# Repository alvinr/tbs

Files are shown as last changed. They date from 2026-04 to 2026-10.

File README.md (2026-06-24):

<!-- SPDX-License-Identifier: AGPL-3.0-only -->
<!-- © 2026 Alvin Richards -->

<div align="center">
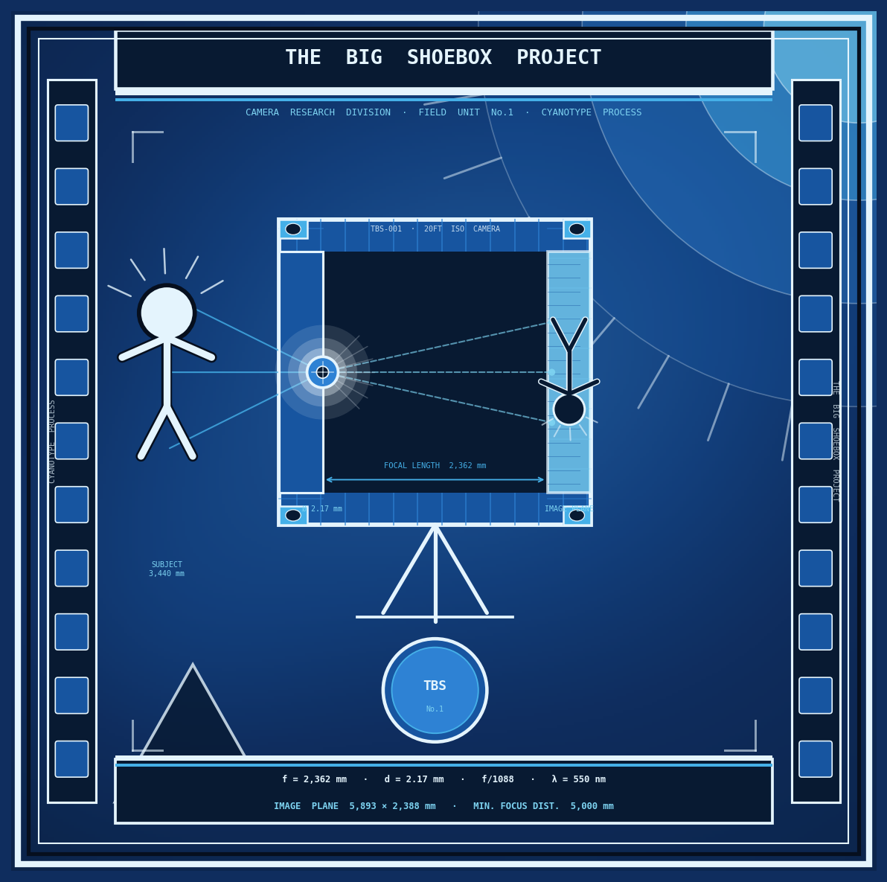
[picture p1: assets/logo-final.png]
The Big Shoebox Project (TBS-001)
  
</div>

# The Big Shoebox Project (TBS-001) — Repository & Build Guide

This repository is the **source** for the TBS-001 engineering documentation: a giant pinhole
camera built inside a 20 ft shipping container. Everything published is *generated* from code and
text in this repo — the 2D engineering diagrams (matplotlib), the 3D SketchUp models, the cost /
shopping / weight figures, and the [MkDocs](https://www.mkdocs.org/) website.

> **Looking for the camera itself?** This README is about running the **repo** (regenerating
> drawings, building the site, the tooling). For the project overview see
> **[`project-summary.md`](project-summary.md)** or the live site: **<https://alvinr.github.io/tbs/>**.

---

## Repository layout

```
/                      project root — engineering reports (*.md), config, this README
src/generators/        all 2D diagram generators + the tooling (lint.py, costing.py, …)
src/models/            SketchUp 3D model generators (emit Ruby, drive SketchUp)
diagrams/              generated PNGs/SVGs (output of src/generators/)
skills/                codified drawing/labeling conventions
published/             MkDocs input — auto-populated by publish.sh (gitignored, never edit)
site/                  built site output — gitignored, never commit
.githooks/             versioned git hooks (the pre-commit drift gate)
dependencies.yml       machine source: script → output-file graph (see "Tooling")
mkdocs.yml             site nav + theme           publish.sh   sync + build + deploy
```

`CLAUDE.md` holds the working conventions (drawing style, report style, the add-a-document
workflow) in more depth — it's worth a read before adding content.

---

## Prerequisites

- **Interpreter: CPython 3.9** — developed and run on **3.9.6** (the macOS system `python3`).
- **Packages: [`requirements.txt`](requirements.txt)** — the single, pinned dependency list (for the
  2D diagram generators and the documentation site). Set up a virtual environment from it:

  ```bash
  python3 -m venv .venv
  .venv/bin/pip install -r requirements.txt
  # then activate it, or prefix commands with .venv/bin/
  ```

- **3D models** additionally need [SketchUp](https://www.sketchup.com/) + the live-send bridge — not
  a pip dependency (see "The 3D SketchUp models").

The drift tooling (`lint.py`, `costing.py`, `facts.py`, `deps.py`) and the SketchUp model generators
use **only the Python standard library**, so the pre-commit hook runs on any `python3` with nothing
installed. Only the diagram generators and the site build need `requirements.txt`.

---

## Regenerating the 2D diagrams

Each generator writes one or more PNGs into `diagrams/`:

```bash
python3 src/generators/generate_<name>.py        # e.g. generate_walkway_diagram.py
```

Spatial values come from `src/generators/tbs_constants.py` (the single source of truth for
geometry). **Don't hardcode a dimension** — import the constant. After changing a constant, see
*"What a change cascades to"* below for exactly which generators to re-run.

---

## The 3D SketchUp models

Models live in `src/models/` and **emit Ruby** that builds the model in a running SketchUp:

```bash
python3 src/models/generate_sketchup_model.py --save    # write the .rb to src/models/<name>.rb
python3 src/models/generate_sketchup_model.py --send    # build into the OPEN SketchUp document
```

- `--save` is non-interactive (just writes the `.rb`); `--send` requires SketchUp **open on the
  correct document** with the live-send bridge listening — it clears and rebuilds the active model.
- Open a **blank** document before `--send` for a *new* model so you don't clobber an existing
  `.skp`; then "Save As" to `models/<name>.skp`.
- Commit the generator `.py` + the regenerated `.rb` + the `.skp` together. (Sketchfab re-uploads
  are a manual step.)

Models share geometry helpers and constants from `generate_sketchup_model.py` (imported as `ov`),
so they stay in sync. See `dependencies.yml` for the model → output mapping.

---

## Single source of truth

Numbers are **computed, never transcribed** — each kind of value has exactly one home:

| Store | Owns | Consumed by |
|---|---|---|
| `src/generators/tbs_constants.py` | geometry & engineering values | generators, models, weight/cost scripts |
| `src/generators/parts.py` | **the parts registry** — every purchasable item: qty, type, supplier, low/high cost, verified size, cyanotype chemistry | the master BOM, every report's parts list, the dimension audit + cyanotype shopping list (block-injected); `costing.py` derives section totals from it |
| `src/generators/costing.py` | the scenario cost model (mid + low/high budgeting bands) on top of the registry | the cost tables in the docs (block-injected) |
| `src/generators/facts.yml` | cross-referenced prose numbers + the regex to police them | the linter |
| `dependencies.yml` | the `script → output-file` graph | the linter (cascade + validation) |

**`parts.py` is the procurement source of record; `costing.py` is a reconciled scenario layer.** The
registry generates `master-shopping-list.md` (the by-type BOM + supplier consolidation), every
report's §Parts-List, `component-dimension-audit.md` §1, and the cyanotype `chemistry-shopping-list.md`
— all wrapped in `<!-- BEGIN parts:KEY -->` blocks:

```bash
python3 src/generators/parts.py --inject         # rewrite the parts: doc blocks from the registry
python3 src/generators/parts.py --check          # assert each system reconciles with costing
python3 src/generators/parts.py --master         # print the by-type BOM to stdout
```

The invariant is lint-gated both ways: `parts.py --check-blocks` (docs match the registry) and
`costing.py --check-registry` (each section total == the sum of its registry systems), so a cost
can't drift between the BOM and the budget.

Cost tables in the markdown are wrapped in `<!-- BEGIN costing:KEY -->` / `<!-- END … -->` blocks
and regenerated by `costing.py`:

```bash
python3 src/generators/costing.py --inject     # rewrite the doc cost tables from the source
python3 src/generators/costing.py --check      # assert the figures are internally consistent
```

`facts.yml` prose figures and the per-session **energy budget** are block-injected the same way:

```bash
python3 src/generators/facts.py --inject                    # fill the <!-- fact:KEY --> placeholders
python3 src/generators/calculate_energy_budget.py --inject  # fill the <!-- energy:KEY --> figures
```

The energy injector fills the `<!-- BEGIN energy:KEY -->` placeholders in `electrical-report.md`
§3.1/§3.2 from `calculate_energy_budget.py` — the per-session, daily-roll-up, and autonomy model.
It is **lint-gated** (the *energy doc-blocks* gate), so those figures cannot drift from the model.
**Rerun `--inject` after any spec change** that affects power, and regenerate the electrical
**Sheet 1** summary panel (`generate_electrical_diagram.py`) to match. (`daily-energy-report.md`
presents the same model in prose but is not yet block-injected.)

---

## Tooling: the drift linter

`src/generators/lint.py` is a commit-time linter that stops document-side drift. It runs
**automatically before every commit** via the versioned hook — enable it once per clone:

```bash
git config core.hooksPath .githooks       # one-time install; emergency bypass: git commit --no-verify
```

Run it by hand any time:

```bash
python3 src/generators/lint.py            # all checks (4 gates that BLOCK + 7 advisory warnings)
```

**Gates** (block the commit): costing reconciliation, costing doc-blocks match the source,
fact placeholders match the registry, energy doc-blocks match `calculate_energy_budget.py`.
**Warnings** (advisory): facts-registry agreement, `dependencies.yml` validity, table arithmetic,
missing-cascade, hardwired-literal, duplicated-geometry equality.

On-demand sub-commands:

```bash
python3 src/generators/lint.py --cascade PROC_TRAY_X_R   # what re-runs if this constant changes
python3 src/generators/lint.py --literals                # full hardwired-literal backlog scan
python3 src/generators/lint.py --duplication             # compare the duplicated 3D emitters
```

### What a change cascades to

After editing a constant, ask the tooling rather than a table:

```bash
python3 src/generators/lint.py --cascade <CONSTANT_NAME>
```

It greps every script that reads the constant and lists the exact PNGs / `.skp` / `.rb` each
writes. If you `git add` a `tbs_constants.py` change **without** the regenerated outputs, the
pre-commit *missing-cascade* check names the specific files you still owe.

`component-dependency-map.md` is the **human** rationale (component → constant registry, the
subsystem × diagram matrix, per-model narratives); `dependencies.yml` is the **machine** source.

---

## Tooling: the editorial validator

`src/generators/editorial_lint.py` enforces the report **narrative** house style codified in
[`skills/skill_report_writing.md`](skills/skill_report_writing.md) (the counterpart to `lint.py`,
which guards the *numbers*). It scans the published reports (`publish.sh` `MD_FILES` +
`project-summary.md`).

It is a **manual step — *not* wired into the pre-commit hook.** Run it by hand:

```bash
python3 src/generators/editorial_lint.py          # gates + advisory
python3 src/generators/editorial_lint.py --gates   # gates only (exit 1 on failure, for future CI)
```

**Gates** (deterministic, exit 1 on failure): American spelling (British → American), and every
item in a *Source References* section carries a hyperlink.
**Advisory** (review; never blocks): banned stale design terms (e.g. `55-gal`, `colonnade`,
`Portacool Jetstream` — extend `_BANNED`), a registry-known value restated **raw** that should be a
`<!-- fact: -->` placeholder (the highest-leverage check — it auto-cascades once wrapped), mixed
thousands-separator styles, and reports missing a *Source References* section.

> Scope: it reads the report `.md` prose only — it can't see British spellings baked into diagram
> **labels** (inside the generator `.py`) or `.skp` models; those still need a manual sweep.

---

## Building & deploying the site

```bash
bash publish.sh            # sync docs → published/, build, and gh-deploy to GitHub Pages
bash publish.sh --local    # sync + serve a local preview at http://127.0.0.1:8000
bash publish.sh --build    # sync + build to site/ only (no deploy)
```

`publish.sh` syncs the root `.md` files + `diagrams/` into `published/`, copies
`project-summary.md → published/index.md` (the site Home), builds with MkDocs, optionally writes
the PDF brochure, and pushes the `gh-pages` branch. It auto-detects whether a git remote exists and
falls back to `--build` if not. On some systems run it as `PATH=/usr/bin:$PATH bash publish.sh`.

**Never edit `published/` or `site/` by hand** — they are regenerated.

---

## Adding a new document (short version)

1. Write `<name>.md` in the repo root (+ a `src/generators/generate_<name>.py` if it needs drawings).
2. Register it in `publish.sh` (`MD_FILES` / `DIAG_FILES`) and `src/generators/setup_docs.py`
   (`MD_FILES` / `DIAG_IMAGE_FILES` + the index table), and add a `nav:` entry to `mkdocs.yml`.
3. If you added a generator/model, add its `script → outputs` entry to `dependencies.yml`.
4. `bash publish.sh` to deploy; commit the script + `.md` + `.png` together.

The full checklist is in `CLAUDE.md`.

---

## Commit conventions

- Commit the related source together (script + `.md` + regenerated `.png`/`.skp`/`.rb`).
- Stage only the files you actually changed (no `git add -A`).
- The pre-commit gate must pass (or `--no-verify` for an explicit emergency bypass).
- `published/`, `site/`, and `.claude/` are never committed.

---

*© 2026 Alvin Richards — released under the [GNU AGPLv3](licensing.md). Live site:
<https://alvinr.github.io/tbs/>*

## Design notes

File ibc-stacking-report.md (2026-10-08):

<!-- SPDX-License-Identifier: AGPL-3.0-only -->
<!-- © 2026 Alvin Richards -->
# IBC Stacking System

## 1. Purpose

TBS-001's three-circuit water system requires four 1,000 L caged composite totes arranged in a
2×2 stack in the right end zone of the container. Two Blue supply
totes (IBC-1 and IBC-2) sit on top; one Brown recycle tote (IBC-3) and one Waste tote
(IBC-4) sit on the bottom. A welded mild steel **restraint-only** frame restrains all four direct-stacked totes for transport, and maintains a <!-- BEGIN fact:corridor_width_mm -->270<!-- END fact:corridor_width_mm -->mm plumbing corridor
between the near and far columns for internal pipe routing, valves, and the equipment
panel.

**Design goals:**

- Restrain 4× 1,000 L caged totes in a 2×2 direct-stack (2 columns × 2 tiers)
- Restrain all totes for road transport with weld-on lashing rings
- Maintain a central plumbing corridor for pipe routing and valve access
- Enable external fill and drain without opening cargo doors
- Fit within the <!-- BEGIN fact:container_height_mm -->2,388<!-- END fact:container_height_mm -->mm container ceiling height with adequate clearance

<!-- brochure:skip -->
**Interactive 3D model** — the four IBC totes, the welded stacking frame, and the plumbing corridor. Drag to orbit, scroll to zoom.

<div class="sketchfab-embed-wrapper">
  <div style="position:relative;width:100%;padding-bottom:56.25%;">
    <iframe title="TBS-001 IBC Model" frameborder="0" allowfullscreen mozallowfullscreen="true" webkitallowfullscreen="true" allow="autoplay; fullscreen; xr-spatial-tracking" execution-while-out-of-viewport execution-while-not-rendered web-share src="https://sketchfab.com/models/8d091c60e93848f38e26c9c89a08cbc8/embed" style="position:absolute;top:0;left:0;width:100%;height:100%;border:0;"></iframe>
  </div>
  <p style="font-size: 13px; font-weight: normal; margin: 5px; color: #4A4A4A;"><a href="https://sketchfab.com/3d-models/tbs001-ibc-model-8d091c60e93848f38e26c9c89a08cbc8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" target="_blank" rel="nofollow" style="font-weight: bold; color: #1CAAD9;">TBS001 - IBC Model</a> by <a href="https://sketchfab.com/alvin91403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" target="_blank" rel="nofollow" style="font-weight: bold; color: #1CAAD9;">alvin91403</a> on <a href="https://sketchfab.com?utm_medium=embed&utm_campaign=share-popup&utm_content=8d091c60e93848f38e26c9c89a08cbc8" target="_blank" rel="nofollow" style="font-weight: bold; color: #1CAAD9;">Sketchfab</a></p>
</div>
<!-- brochure:endskip -->

---

## 2. IBC Totes

### 2.1 Specification

| Parameter | Value |
|---|---|
| Model | Schütz Ecobulk MX 1000L (or equivalent US 48×40 caged composite tote) |
| Capacity | 1,000 L (~264 US gal) per tote. **"600 L" / "1,000 L" are fill levels, not tote sizes** — all four totes are identical |
| Overall dimensions | 1,219 × 1,016 × 1,168mm (W × D × H) |
| Pallet format | US 48" × 40" composite |
| Pallet base height | 168mm (includes feet/runners) |
| Cage upright tube | Ø25mm |
| Cage top rail | 25mm OD |
| Drain valve | DN50 butterfly valve, S60×6 thread |
| Fill | **side entry near the top** (no top-cap access — only <!-- BEGIN fact:ibc_ceiling_clearance_mm -->52<!-- END fact:ibc_ceiling_clearance_mm -->mm headroom stacked) |
| Tare weight | ~65 kg per tote |
| Full weight (1,000 L) | ~1,065 kg per tote |
| Total tare (4 totes) | ~260 kg; water load see [weight-distribution report](weight-distribution-report.md) |

### 2.2 Tote Assignments

| Tote | Position | Circuit | Function |
|---|---|---|---|
| IBC-1 | Top tier, near column | Blue (clean supply) | Primary clean water supply for spray bar |
| IBC-2 | Top tier, far column | Blue (clean supply) | Secondary supply, filled in parallel with IBC-1 from the X1 fill tee |
| IBC-3 | Bottom tier, near column | Brown (recycled) | Wash water buffer — filtered and recycled back to Blue |
| IBC-4 | Bottom tier, far column | Black (waste) | Contaminated water sealed for off-site disposal |

### 2.3 Layout

| Parameter | Value |
|---|---|
| Near column Yd | 30–1,046mm (pushed to near/pinhole wall, 30mm clearance) |
| Far column Yd | 1,316–2,332mm (pushed to far wall, 30mm clearance) |
| Column X range | 4,674–5,893mm (right-justified to sealed end wall) |
| Plumbing corridor | Yd=1,046–1,316mm (270mm gap between columns) |
| Single IBC height | 1,168mm |
| Stacked height (2 totes, direct-stack cage-on-cage) | <!-- BEGIN fact:ibc_stack_height_mm -->2,336<!-- END fact:ibc_stack_height_mm -->mm (2 × 1,168mm — no deck/mat between tiers) |
| Ceiling clearance | <!-- BEGIN fact:ibc_ceiling_clearance_mm -->52<!-- END fact:ibc_ceiling_clearance_mm -->mm (2388 − 2,336mm) — tight but transport-validated (see [weight report](weight-distribution-report.md)) |

---

## 3. Stacking Frame — Restraint-Only Deep 4-Leg Box

### 3.1 General Arrangement

The 1,000L caged totes **direct-stack cage-on-cage** — the upper tote's pallet base
bears directly on the lower tote's cage top, leaving only <!-- BEGIN fact:ibc_ceiling_clearance_mm -->52<!-- END fact:ibc_ceiling_clearance_mm -->mm of ceiling headroom.
There is no room for (and no need for) a load-bearing platform deck between tiers, so
the frame is **restraint-only**: it carries no vertical service load, it only keeps the
totes from moving during transport.

The frame is a **deep 4-leg box** at the IBC front, spanning the plumbing corridor: a
**front pair** of full-height 2×2×0.120in uprights at the corridor mouth and a **back pair**
~450mm behind, tied by butt-jointed top and bottom rings, on four floor-flange feet (the
front feet reach ~25mm under the tray edge). Transport restraint is provided by:

- **front retaining bars** across each column at the IBC front that stop
  the totes sliding out the open front, their wall ends dropped into Simpson-style joist
  hangers;
- **Weld-on lashing rings** on the front bars, with ratchet straps over each stack;
- the totes are otherwise trapped by the container side walls (30mm gap) and sealed end wall.

The box carries the **Corridor Plumbing Panel** (pumps) and its **drain-riser backing spine**
on the back uprights, and gives the right-walkway cantilever arms their bolt-on point on the
front uprights — so it is the **shared metal structure of the IBC plumbing corridor**, not just a
tote-restraint frame. The panel brackets, the 12 side-panel pipe-run L-brackets, the ribbon cross-beams,
and the walkway-arm connection are validated and scheduled in §3.4–3.6 alongside the tote restraint.

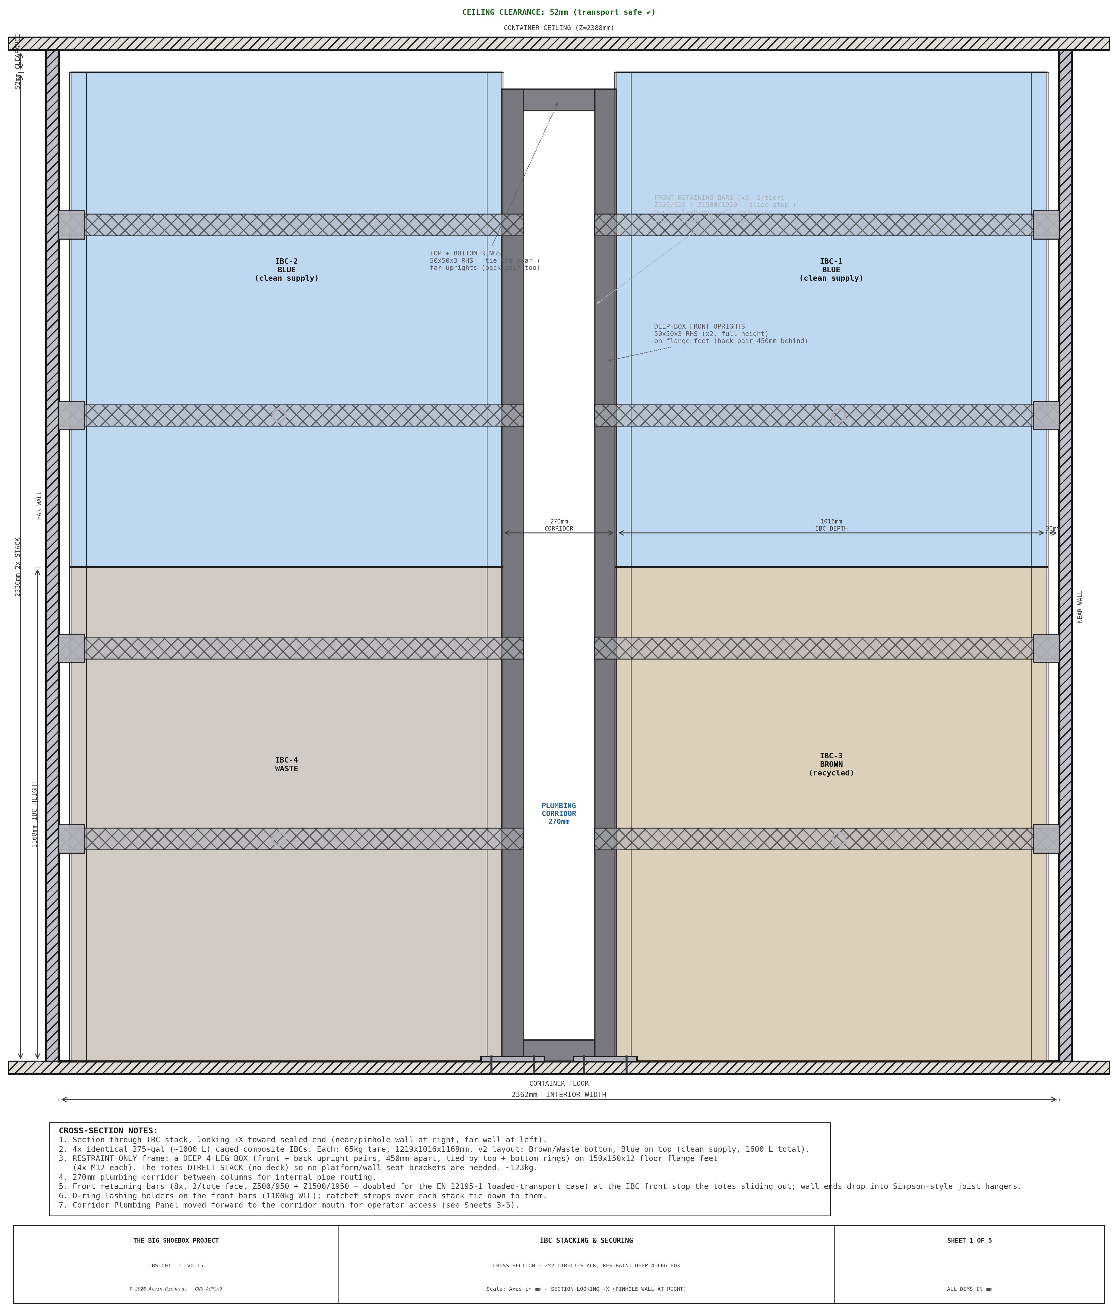
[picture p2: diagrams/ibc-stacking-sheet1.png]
TBS-001 IBC Stacking — Sheet 1: Cross-Section Elevation


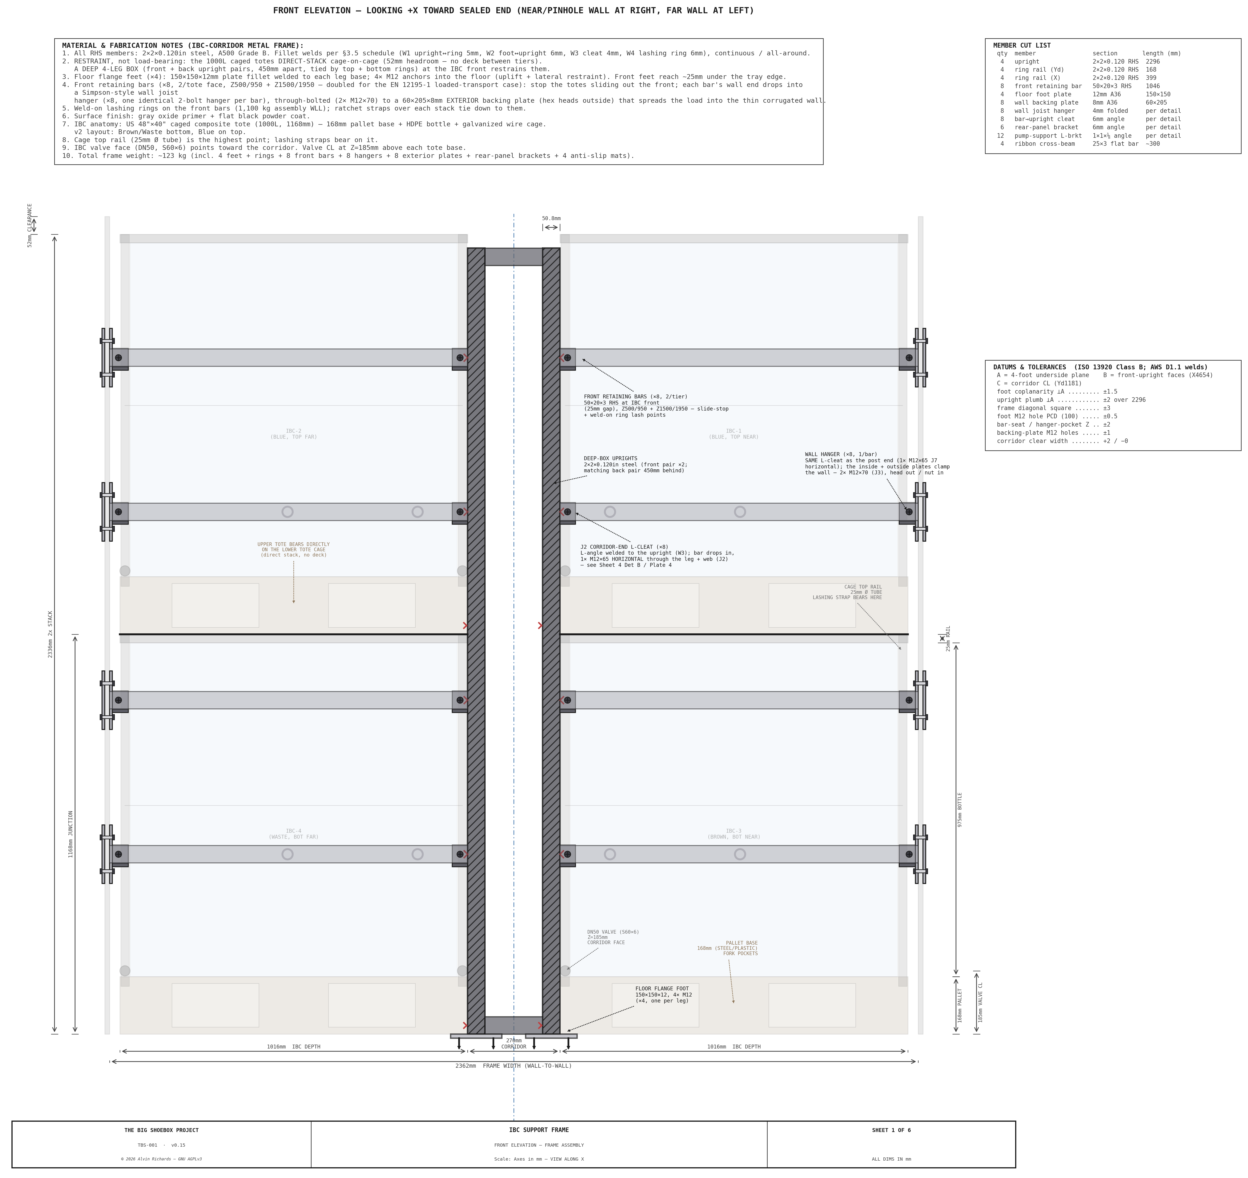
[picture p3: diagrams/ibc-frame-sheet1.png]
TBS-001 IBC Frame — Sheet 1: Front Elevation


### 3.2 Frame Specification

| Parameter | Value |
|---|---|
| Material | 2×2×0.120in RHS mild steel (A500 Grade B) |
| Uprights | 4 full-height (deep 4-leg box: front pair at the corridor mouth + back pair ~450mm behind), tied by butt-jointed top + bottom rings |
| Floor anchorage | 4 × 150 × 150 × 12mm flange-plate feet, 4 × M12 anchors each (front feet reach ~25mm under the tray) |
| Front retaining bars | **8 × 50×20×3 RHS** — **two per tote face** (upper + lower), both seated in the 25mm gap to the film rail, wall → upright per column. Doubled from one to carry the loaded-transport case (§3.4) |
| Anti-slip matting | **4 × certified anti-slip mat (μ ≥ 0.6)** under the tote interfaces (2 on the floor + 2 on the lower-tote cage tops) — raises the sliding friction that credits against the forward thrust (§3.4) |
| Wall joist hangers | **8 × identical 2-bolt Simpson-style U-pocket** — one per bar (the pair uses identical hangers for fab simplicity), each **through-bolted (2 × M12×70) to an exterior backing plate** (M12×70 spans the 8mm plate + corrugation + 4mm hanger grip). Wall penetrations unchanged at 16 |
| Exterior backing plates | 8 × 60 × 205 × 8mm steel (one per hanger), on the **outside** of the container side walls (hex heads outside) — spread the totes' transport thrust into the thin corrugated wall so the bolts can't pull through |
| Weld-on lashing rings | 8 on the front bars (4 per tier); 3,333 lb (~1,512 kg) assembly WLL (2" strap-limited), 2 straps per stack |
| Panel mount | the box carries the Corridor (pump) Plumbing Panel + drain-riser spine on the back uprights, and the right-walkway cantilever arms on the front uprights |
| Frame weight | ~123 kg (4 uprights + rings + 4 feet + 8 front bars + 8 hangers + 8 exterior plates + rear-panel brackets + 4 mats — see [weight report](weight-distribution-report.md)) |
| Joints | Welded (fillet weld throughout — sizes scheduled in §3.5); the walkway-arm connection is a bolted end-plate (J6), not a frame weld |

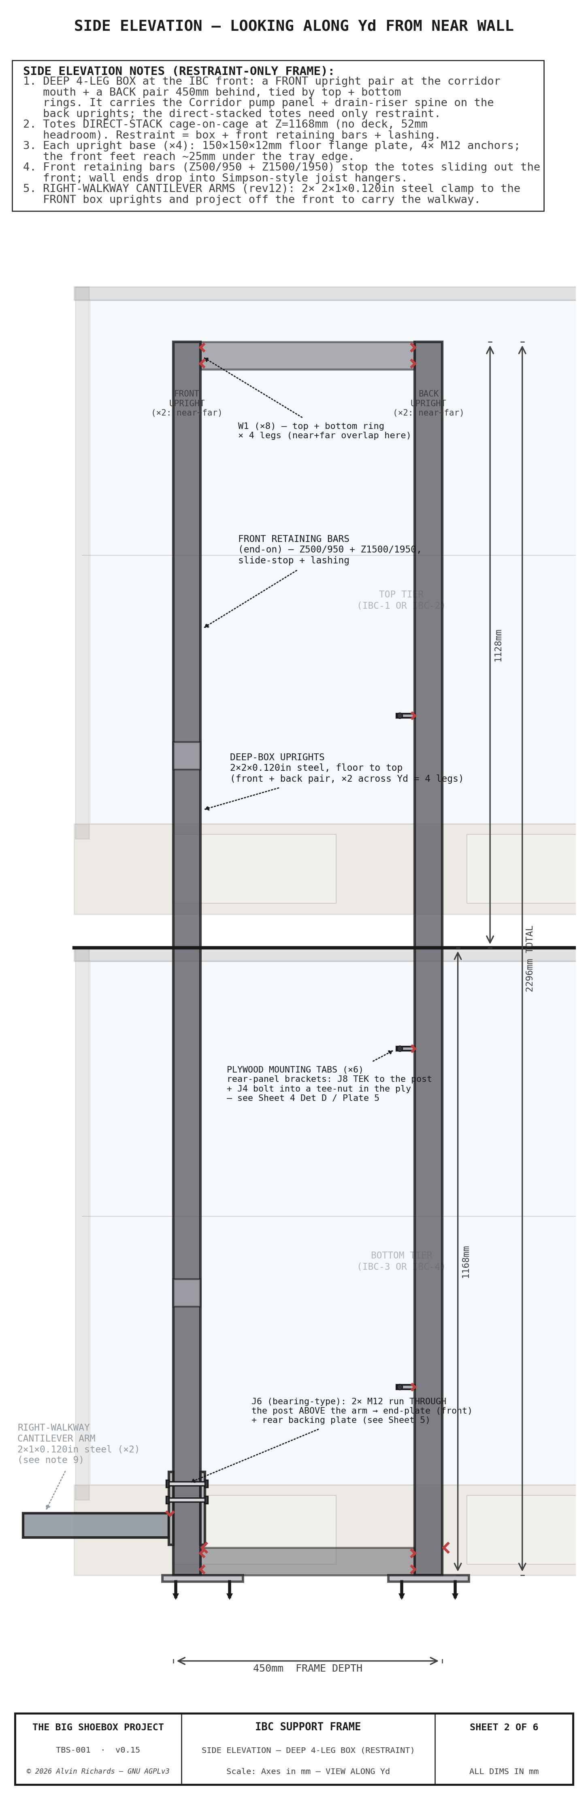
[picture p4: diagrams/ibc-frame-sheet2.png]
TBS-001 IBC Frame — Sheet 2: Side Elevation


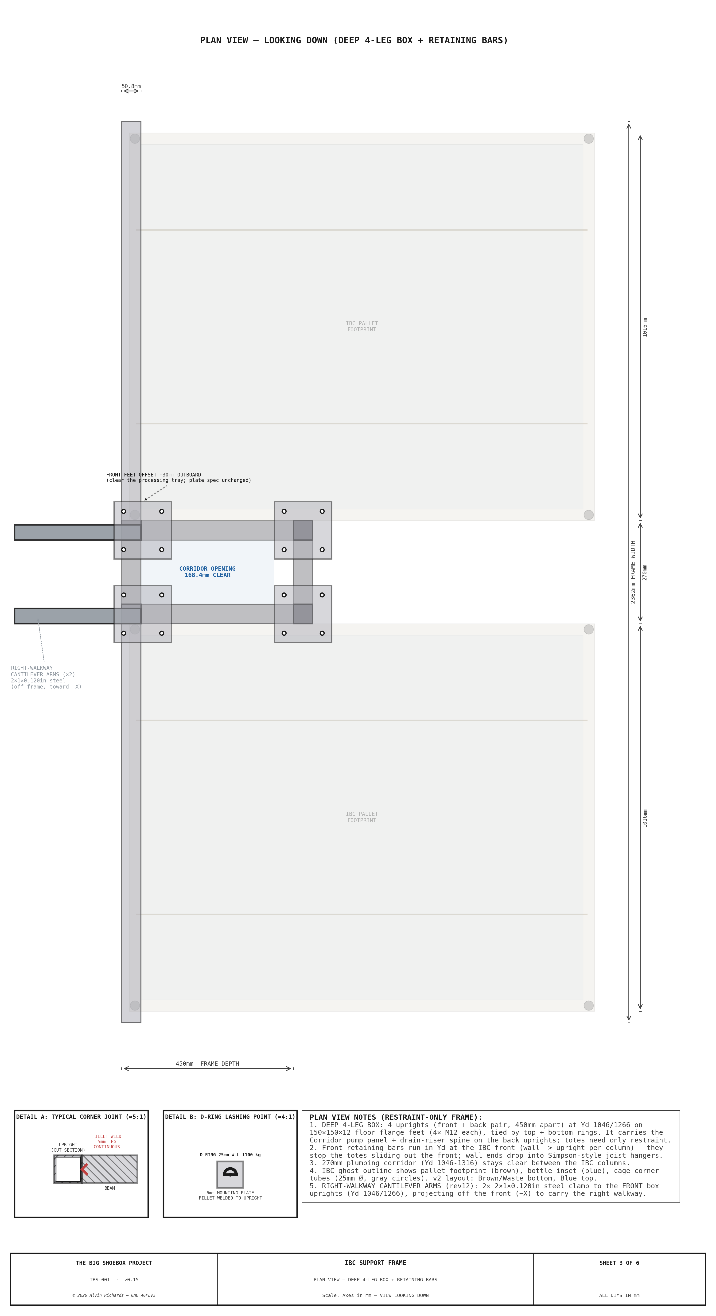
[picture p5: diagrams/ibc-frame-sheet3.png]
TBS-001 IBC Frame — Sheet 3: Plan View at Platform Level


### 3.3 Direct-Stack Junction

The upper tote bears directly on the lower tote's galvanized cage top rail
(no platform, mat or lip) — the totes' normal warehouse cage-on-cage stacking interface,
rated for a full upper tote.

### 3.4 Structural Validation (transport restraint) — EN 12195-1:2010

The frame carries **no vertical service load** (the totes stack on themselves), so there is no
platform-beam bending case. The governing case is **transport restraint**: the totes must not shift
when the container is moved by road — and, because the camera is designed to run **self-contained**
(disconnected from mains water and power), it is transported with **water aboard**. The restraint is
therefore designed for the loaded case, not just the drained one.

**Load basis — [EN 12195-1:2010](https://cdn.standards.iteh.ai/samples/32961/4592590bcf194f1a8ffa917a5db7d258/SIST-EN-12195-1-2011.pdf)** (the European cargo-securing standard for road transport). Design accelerations: **0.8 g forward** (braking), 0.5 g rearward, 0.5 g lateral, with **1.0 g vertical** in the friction term; safety factor **f_s = 1.25 forward / 1.1 otherwise** ([Table 2 + §5](https://hvttforum.org/wp-content/uploads/2019/11/Johansson-International-guidelines-on-safe-load-securing-for-road-transport.pdf)). A blocking (positive-restraint) device must carry **BC ≥ f_s · m · g · (c − μ·c_z)** — the inertia demand less the friction credit. Sliding friction **μ = 0.20** bare (the conservative fallback for an unlisted plastic-pallet-on-steel pairing), rising to **μ = 0.60** with certified anti-slip matting ([EN 12195-1 Annex B](https://res.jedermann.de/data/downloads/KB029-2_Gesamtdokument.pdf)). Forward (0.8 g) governs: it is the only direction with no wall to trap the totes (the side walls trap laterally, the sealed end wall rearward). The design mass is a full top-tier Blue tote, **965 kg** (65 kg tare + 900 L). Computed in [`ibc_frame_load.py`](https://github.com/alvinr/tbs/blob/main/src/generators/ibc_frame_load.py).

The forward thrust is blocked by the **front retaining bars**, seated in the 25mm film-rail slot — which limits each bar to a **20mm depth in the load direction** (weak-axis bending). A single bar per tote face fails this case (bending SF **0.79**). The design therefore uses **two bars per tote face** sharing the thrust, plus certified anti-slip matting to cut the demand:

| Element | Demand (loaded) | Capacity | SF (bar-alone) | SF (+ anti-slip mat) |
|---|---|---|---|---|
| Front retaining bar — bending (2 × 50×20×3, weak-axis) | 464 N·m | 738 N·m | **1.59** | **4.77** |
| Wall-hanger bolts (2 × M12×70 Gr.8.8 per bar) | 1,775 N | 80,900 N | 46 | — |
| Wall bearing (60×205×8 plate, 1.6mm wall, 2 holes) | 1,775 N | 15,400 N | 8.7 | — |
| Bar → upright cleat (1 × M12×65 A2, shear) | 1,775 N | 35,400 N | 20 | — |
| Lashing strap — vertical tie-down (2 straps/stack) | 9,467 N | 29,650 N | 3.1 | — |

The two bars give **defense in depth**: as positive blocking they pass on their own (**SF 1.59**, mat degraded or absent); with the anti-slip mat the friction credit lifts the margin to **SF 4.77**. Everything downstream of the bars is comfortably strong — the wall-hanger bolts, the corrugated-wall bearing (backing-plate-spread), the cleat bolts, and the tie-down straps all clear SF ≥ 8. In the **drained** transport state (site-filled water, totes empty) every element clears SF ≥ 12.

- **Front retaining bars** (two per tote face, 50×20×3 RHS, ~1,046mm span) share each tote's forward (−X) thrust into the floor feet + wall hangers.
- **Wall joist hangers** — **one identical 2-bolt hanger per bar** (8 total; the two bars of a pair use identical hangers for fabrication simplicity), each **through-bolted (2 × M12×70) to a 60×205×8mm exterior backing plate** on the outside of each side wall — the plate spreads the bolt load so the thin corrugated wall cannot pull through. Total wall penetrations stay at 16 (8 hangers × 2 bolts = the old 4 × 4). M12×70 (partial thread, the single standardized zinc wall length) spans the ~42–54mm sandwich (8mm plate + corrugation + 4mm hanger). **Both ends of the bar now use the SAME L-cleat** — the corridor-end **J2** and the wall-end **J7** each drop the bar into an L-angle and run a single horizontal M12×65 through the L's vertical leg + the bar's 50mm web, with a small nut-side **backing plate** spreading the load into the bar's far web.
- **Anti-slip matting** (certified μ ≥ 0.6) under each tote interface is the primary friction lever — it triples the effective margin and directly answers the "totes must not shift" requirement.
- **Weld-on lashing rings + 2 straps/stack** (3,333 lb / ~1,512 kg per strap) provide vertical tie-down against the forward-tipping mode of the tall loaded stack (CG Z≈1,345mm) and supplement lateral restraint; the totes are otherwise wall-trapped.
- **Floor feet** (150×150×12, 4 × M12 each) anchor the uprights against uplift and transfer loads into the slab.

**Service + walkway load cases** (the same frame also carries the plumbing panel and the walkway — both **non-governing** vs the transport case):

- **Plumbing panel + pumps** (~20 kg on the 6 rear-panel brackets) = ~33 N/bracket, static — trivial (SF ≫ 10).
- **Right-walkway cantilever** — each of the 2 arms carries ~22 kg dead + a 1 kN person point load at the deck (325 mm out from the upright) = a **395 N·m moment into the front upright**: the 50.8 RHS upright bends at **SF 6.9**, and the arm→upright connection — a **bolted end-plate**, **bearing-type** (a plate welded to the arm end, then 2× M12 **both above the arm** through the upright into a **rear backing plate**, J6): the top bolt group takes the tension while the plate bears compression at the bottom against the upright. At the ~65 mm lever the two bolts share **~3.0 kN each** (**SF ≈ 20** on the M12), and the backing plate spreads the reaction so the hollow RHS wall can't dish. **Both bolts sit above the arm** — this clears the 3-way corner congestion at the front upright: the corridor's bottom frame X-rail (Z12–63) runs behind the plate's lower edge (ghost-marked on Sheet 5) with **no bolt near it**, and neither bolt fouls the welded arm (Z90–115). A walkway support carries **down-load only** (deck + people; the grate lifts out without loading the arm up), so the asymmetric bearing-type joint is appropriate. The arm itself is a **solid 2×1 flat bar** (not a tube): each arm half-laps over *both* walkway long beams, and a notched hollow tube opens into a weak channel — a notched partial section has to be solid to keep its strength. The half-lap is **rebalanced to the moment**: a deep arm notch at the tip (M ≈ 30 N·m, arm keeps 5.4 mm), and at the post end (M ≈ 267 N·m) the **outer beam** takes the deep notch so the arm keeps 16 mm (**SF ≈ 2.0** on the solid bar). The outer beam's thin 9.4 mm notch sits at an arm support, but a thin channel can't carry that support's hogging — so the half-lap is a **bearing seat** (the beam's upper 9.4 mm rests on the arm's lower 16 at ~0.2 MPa), i.e. a pinned support. The beam therefore spans **simply-supported on its full 25.4 mm section** — **SF ≈ 7** and **~2 mm** deflection under a person (`ibc_frame_load.outer_beam_frame_check`; the light grate load and person-share are estimates to firm with the full walkway-frame model). Each half-lap is **positively secured** by one **#14 self-drilling TEK screw** (4 total) driven from the underside through a Ø7 **clearance** hole in the solid arm, threading into the hollow beam's **solid bottom wall** (which faces down onto the arm) — an anti-lift/anti-slide locator whose head clears the traveling spray beam. The arm's fabrication (including the hold-down section) is drawn on Sheet 5.

The load path, the EN 12195-1 method, and the full demand/capacity/SF matrix (driven from `ibc_frame_load.py`) are drawn on the load-case sheet:

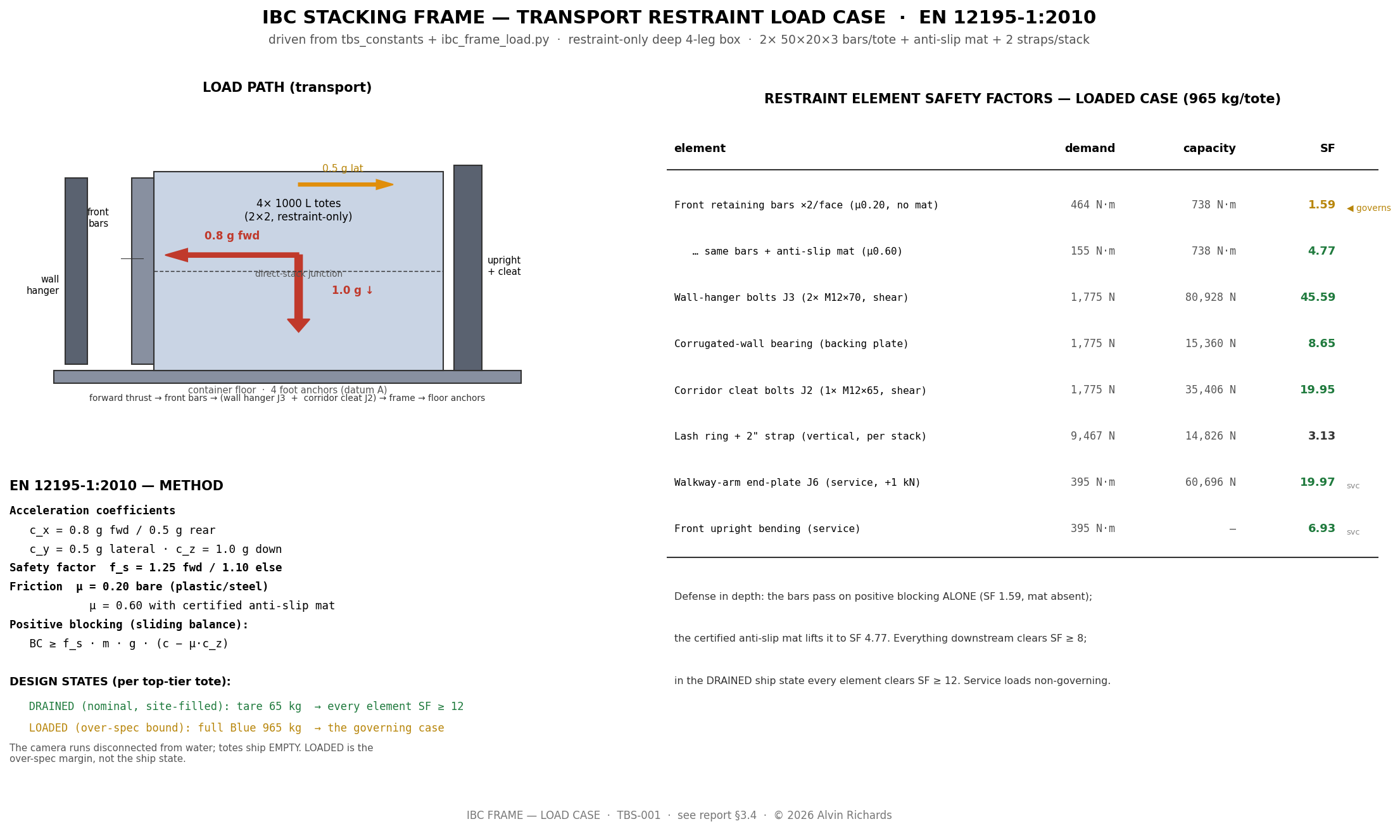
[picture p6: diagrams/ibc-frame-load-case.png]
TBS-001 IBC Frame — Load Case (EN 12195-1)


### 3.5 Fastener + Weld Schedule (fabrication)

Every bolted and welded joint in the restraint frame, for the fabricator. Weld sizes are computed in
[`ibc_frame_load.py`](https://github.com/alvinr/tbs/blob/main/src/generators/ibc_frame_load.py); torques
are the standard values for the grade.

**Fastener schedule**

| ID | Joint | Fastener | Grade | Qty | Torque | Washers | Locking |
|----|---|---|---|-----|---|---|---|
| J1 | Floor foot-plate → floor + crossmember | #14×3¼″ winged self-driller (F14C325FDC) | 410 SS | 16 | driven to seat / flush — no torque spec (self-drilling; not a structural bolt) | — | thread-forming, self-locking |
| J2 | Front-bar corridor end → upright **L-cleat** — the bar drops into the L, **1 HORIZONTAL** bolt through the vertical leg + the bar's tall 50 mm web (the L-corner carries the load; the bolt secures the unsupported direction) | M12×65 hex (92800A481, 18-8 SS) | A2-70 (18-8 SS) | 1 per bar × 8 = 8 | **~50 N·m** with anti-seize (stainless galls → torqued lower than 8.8; no impact driver) | flat | nyloc nut |
| J3 | Wall hanger → side wall → exterior backing plate | M12×70 through-bolt (91280A732) | Gr.8.8 zinc | 16 | **~90 N·m** (85–95 band) | flat (head, outside) + flat + split-lock (nut, inside) | plain nut + split-lock washer |
| J4 | Rear panel → L-bracket upstand (off the back upright) | M8 hex into captive 5/16 tee-nut set from the ply BACK face (tension pulls the flange against the wood) | zinc | 6 brackets | snug + locker (light static load) | flat washer under head | thread-locker |
| J5 | Side-panel pipe-run boards → L-brackets | ¼-20 CSK machine screw into captive pronged tee-nut (rear-panel method, #30) | zinc | 12 brackets | snug | — | pronged tee-nut (self-locking in ply) |
| J6 | Walkway cantilever arm → front upright (arm end-plate → **rear backing plate**, bolted through the upright; **bearing-type — both bolts above the arm**, clear of the corridor bottom rail + the welded arm; internal crush sleeve per bolt) | M12×100 hex through-bolt | Gr.8.8 zinc | 2 arms × 2 bolts = 4 | **~90 N·m** (85–95 band) | flat both ends | nyloc nut |
| J7 | Front-bar wall end → wall-hanger **L-cleat** — the SAME joint as the post end: the bar drops into the L, **1 HORIZONTAL** M12×65 through the vertical leg + the bar's 50mm web (nut on a far-web backing plate). The L is welded to the inside wall plate; the inside + outside plates clamp the container wall via J3 | M12×65 hex (92800A481, 18-8 SS) | A2-70 (18-8 SS) | 1 per bar × 8 = 8 | **~50 N·m** with anti-seize | flat | nyloc nut |
| J8 | Rear-panel L-bracket → back upright (post leg) | #14 self-drilling TEK screw, #4/5 point, HWH | 410 SS | 2 per bracket × 6 = 12 | driven to seat — no torque spec (self-drilling; light static panel load) | bonded washer | thread-forming, self-locking |
| J9 | Side-panel pipe-run L-bracket → side post (weld leg) | #14 self-drilling TEK screw, #4/5 point, HWH | 410 SS | 2 per bracket × 12 = 24 | driven to seat — no torque spec (self-drilling; light pipe load) | bonded washer | thread-forming, self-locking |

Straps: 2 × 2″ ratchet strap per stack, ratcheted to the 3,333 lb (~1,512 kg) assembly WLL — no torque.

Torque sources: M12 8.8 zinc/dry ≈ 88 N·m ([Fastenal torque-tension, K = 0.20](https://crafter.fastenal.com/static-assets/pdfs/technical-resources/Torque-Tension-Relationship-for-Metric-Fasteners-Property-Class-4.6-8.8-10.9-12.9.pdf)) to 93 N·m ([Bossard preload/torque, µ = 0.14](https://assets.eu.ctfassets.net/0vp0u5uh75zd/3S40LEUM235Qk3rJk2phR1/c715f9f45232756c12b59aa681c7fede/060_074_Preload_tightening_torques_Fastening_EN_01_2025.pdf)); M12 A2-70 ≈ 51 N·m (µ = 0.10, [Bossard austenitic-stainless table](https://assets.eu.ctfassets.net/0vp0u5uh75zd/3S40LEUM235Qk3rJk2phR1/c715f9f45232756c12b59aa681c7fede/060_074_Preload_tightening_torques_Fastening_EN_01_2025.pdf)); #14 self-drillers are driven to seat, not torqued ([ITW Buildex TEKS technical guide](https://www.tannerbolt.com/media/akeneo_connector/media_files/T/e/Teks_Select_Technical_Guide_Steel_to_Steel_4_5_56b0.pdf)).

**Weld schedule** (fillet, E70xx electrode; frame welds carry small restraint loads → set by the AWS D1.1 minimum practical fillet for ≤6 mm plate, except the load-checked W3/W4)

| ID | Joint | Fillet leg | Extent | SF |
|----|---|---|---|-----|
| W1 | Upright ↔ top/bottom ring | 5 mm | all-around | min fillet |
| W2 | Floor foot-plate ↔ upright base | 6 mm | all-around | min fillet |
| W3 | Bar-end cleat ↔ upright | 4 mm | both cleat legs | **37** (demand 1.8 kN) |
| W4 | Weld-on lashing ring ↔ front bar | 6 mm | all-around the ring base | **9.1** (demand = strap WLL 14.8 kN) |
| W5 | Wall-hanger seat ↔ pocket back-plate (the hanger PLATE weldment — the bar is *bolted* to it via J7, not welded) | 4 mm | — | min fillet |
| W6 | Ribbon cross-beam ↔ walkway bearer (×4 ends) | 4 mm | both ends | min fillet |

The rear-panel bracket (**J8**) and the side-panel pipe-run L-bracket (**J9**) are **no longer welded** — they attach to the post with **#14 self-drilling TEK screws** (2 per bracket) so they can be added to a pre-finished, painted frame with no hot work and stay adjustable; both carry only light static loads (panel ~33 N/bracket; pipe runs lighter).

**Sheet 6** maps where each weld lands on the frame (a schematic front elevation with W1–W6 ticked) alongside the schedule:

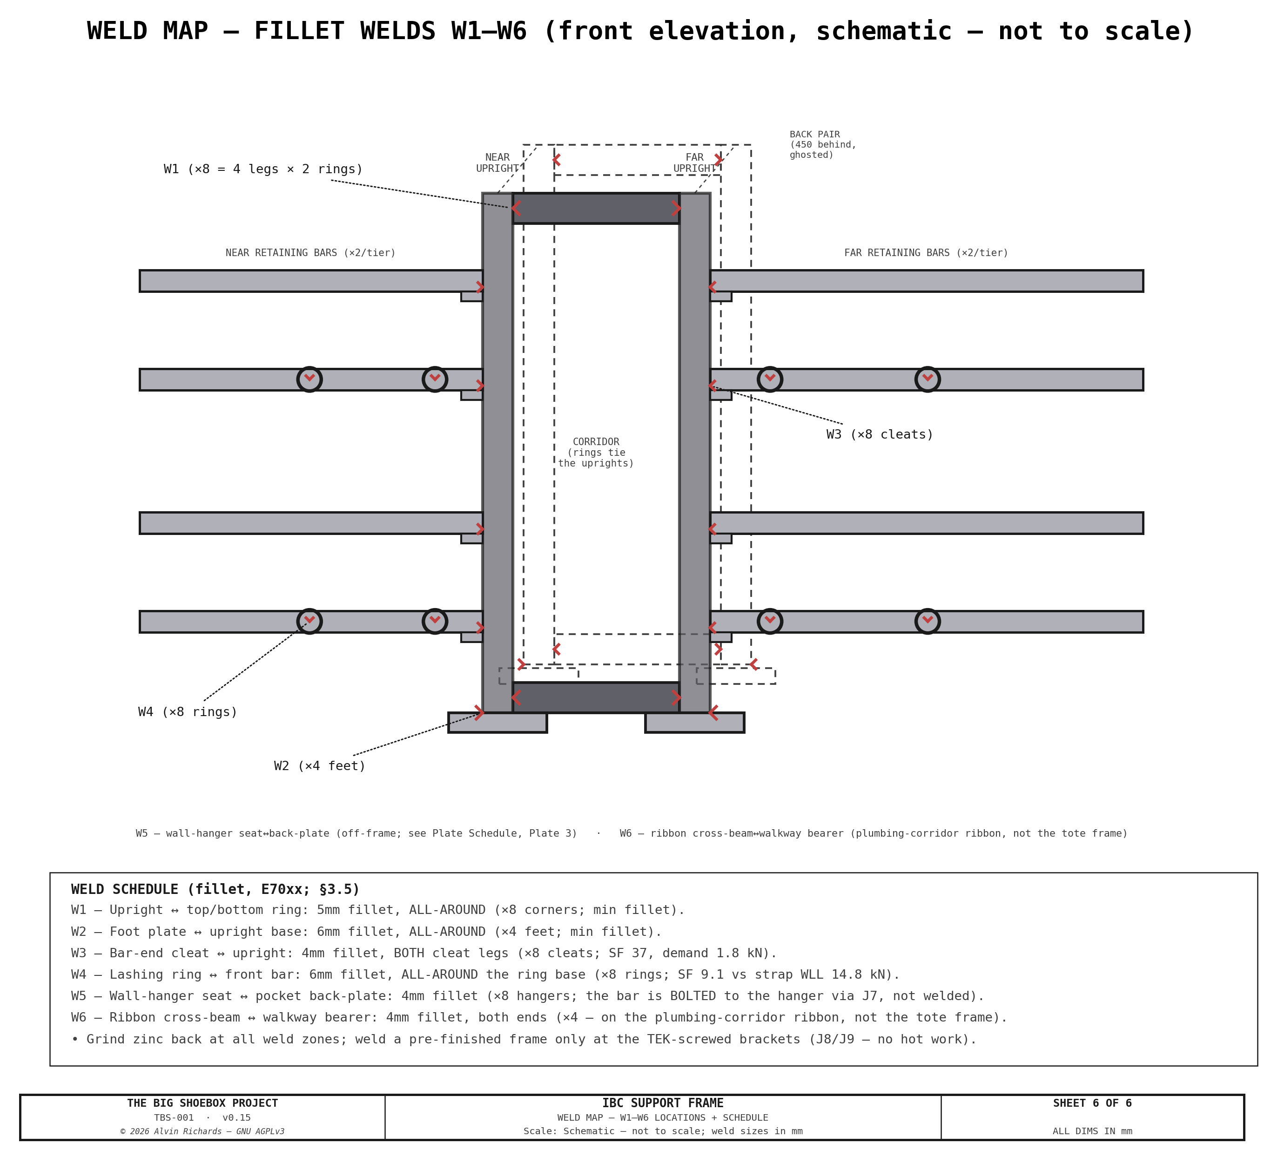
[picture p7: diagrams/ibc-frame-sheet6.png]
TBS-001 IBC Frame — Sheet 6: Weld Map


The wall joist hangers are **folded** 4 mm plate (bent, not welded); the exterior backing plates are loose (bolted, not welded). The corridor-panel + side-panel pipe-run brackets and the ribbon cross-beams are the **plumbing-corridor metal** that shares this frame; the walkway cantilever arms **bolt** to the front uprights (J6, an end-plate welded to the arm + a rear backing plate, 4× M12 through-bolts — not a frame weld) and are fabricated per Sheet 5.

These joints are drawn on **Sheet 4** (each with its weld + fastener callout):

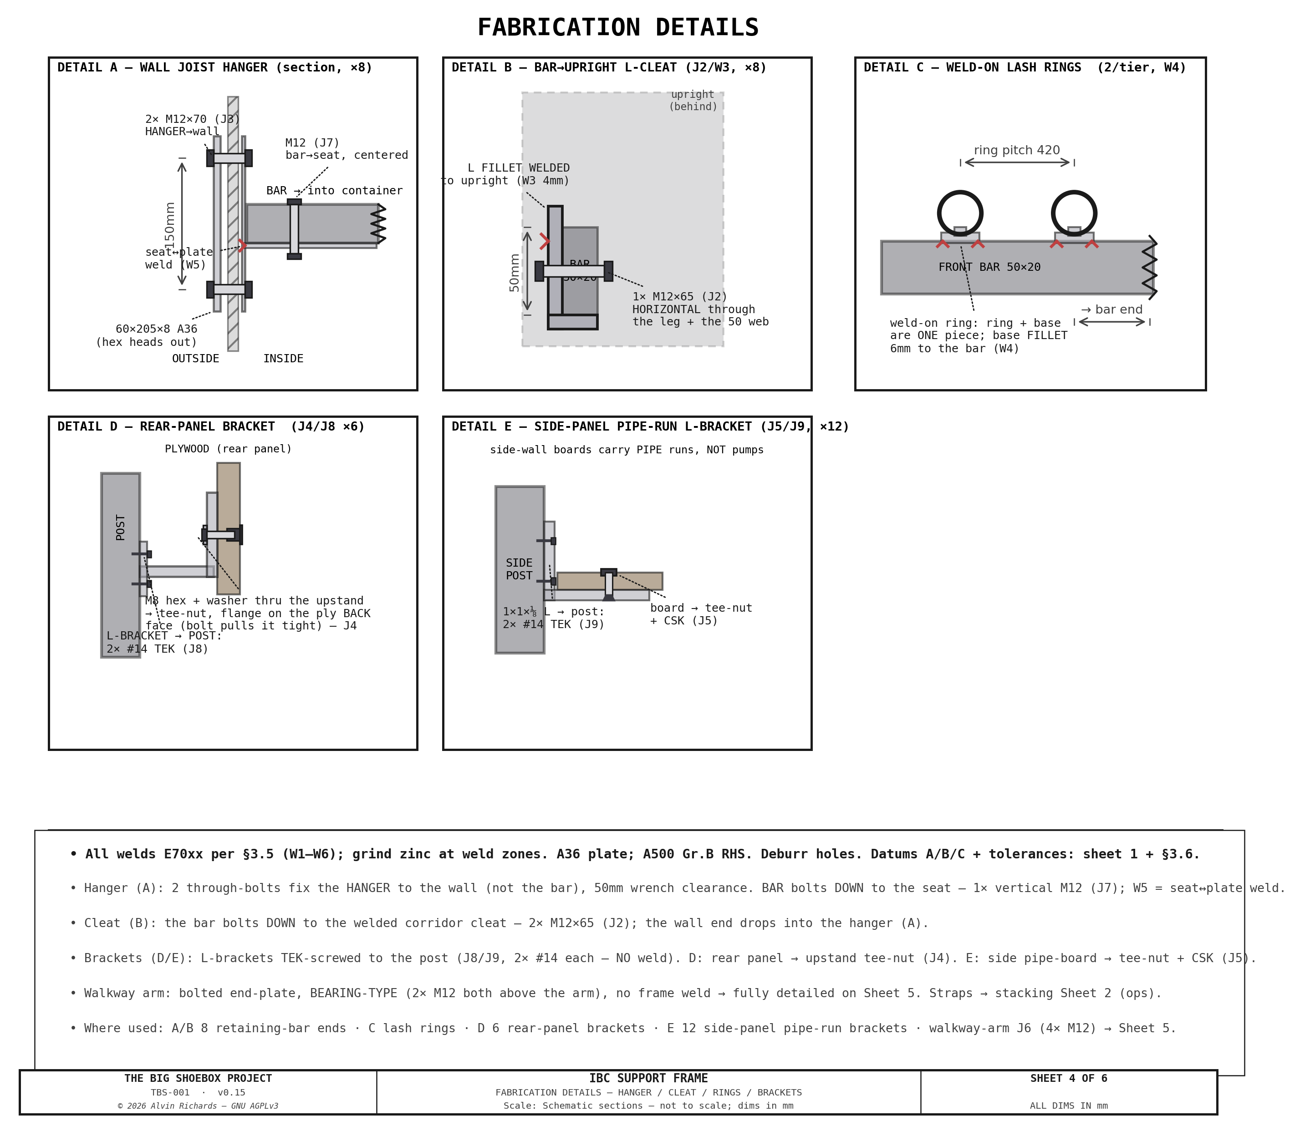
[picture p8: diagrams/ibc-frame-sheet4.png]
TBS-001 IBC Frame — Sheet 4: Fabrication Details


The walkway cantilever arms — how each arm is cut (the **two half-laps** where it crosses the walkway's inner + outer long beams, dimensioned on the side elevation) and the end-plate bolt-hole pattern — are drawn on **Sheet 5** (VIEW A side elevation of the J6 joint, the END-PLATE detail, and the PLAN VIEW showing the plate→post through-bolts):

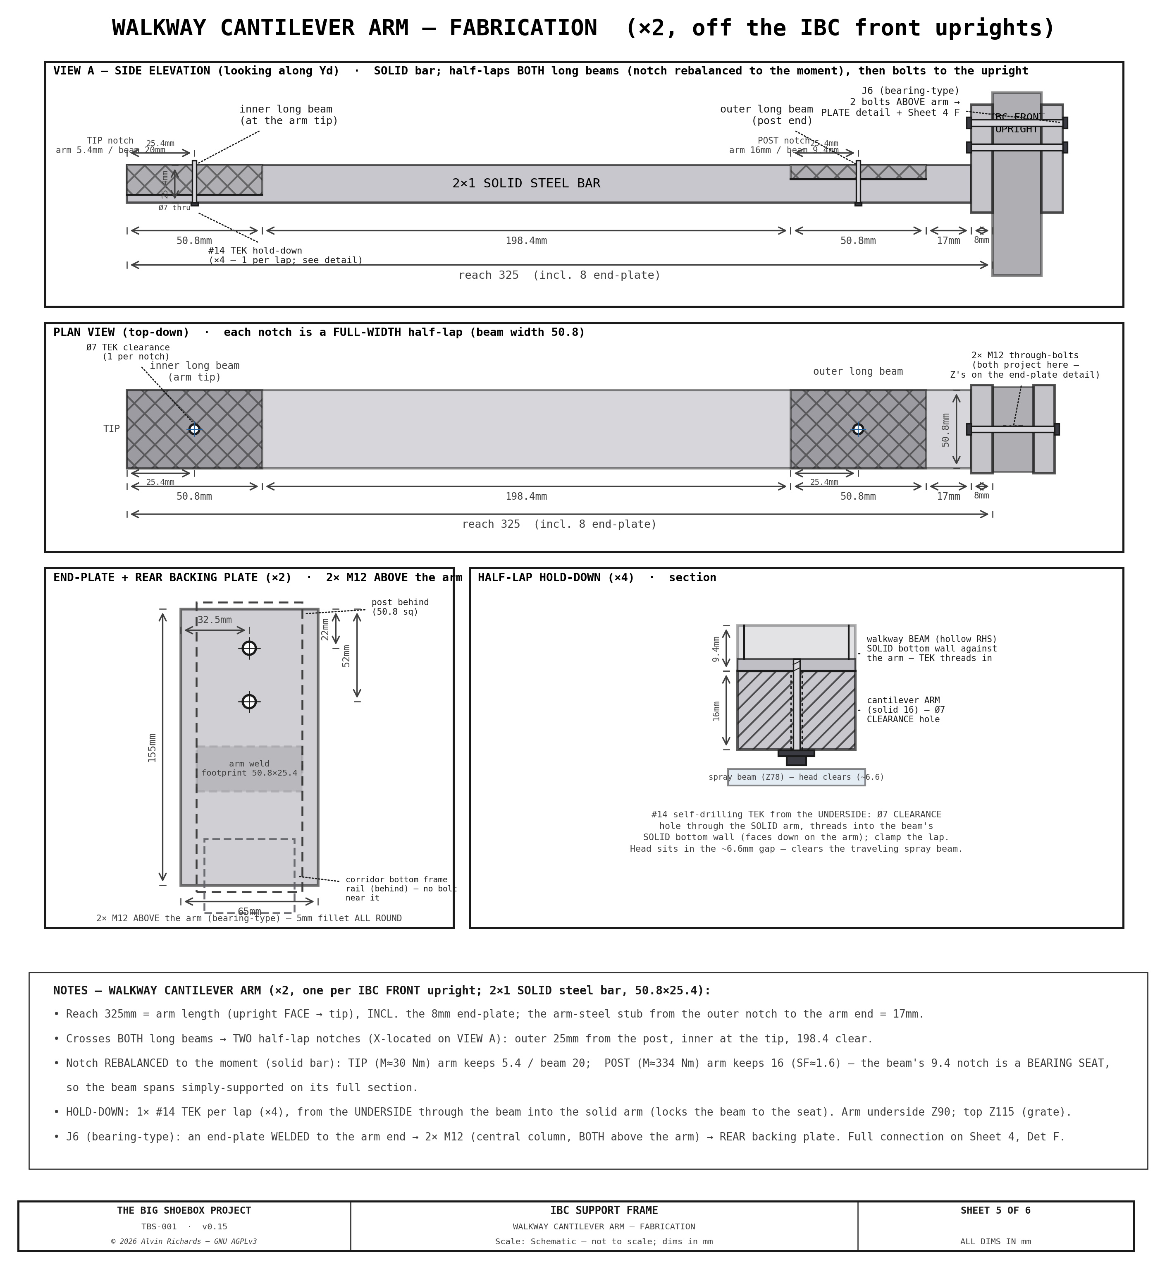
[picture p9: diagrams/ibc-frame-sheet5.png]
TBS-001 IBC Frame — Sheet 5: Walkway Cantilever Arm Fabrication


### 3.6 Datum + Tolerance Scheme

The frame is a welded structure, so tolerances follow **ISO 13920 Class B** (general tolerances for welded
constructions) for linear/angular, and **AWS D1.1** for the welds; the values below are the functional
tolerances that actually matter for fit-up.

**Datums:**

- **A (primary)** — the common plane of the four floor-foot undersides. The frame is set and shimmed to A; everything references off it (it sits on the container floor).
- **B (secondary)** — the front-upright front faces (X = 4,654 mm, the corridor mouth). References the retaining-bar / hanger X positions and the walkway-arm end-plate point.
- **C (tertiary)** — the corridor centerline (Yd = 1,181 mm, midway between the two tote columns). Symmetry reference for the columns and the <!-- BEGIN fact:corridor_width_mm -->270<!-- END fact:corridor_width_mm -->mm plumbing corridor.

**Functional tolerances:**

| Feature | Tolerance | Why |
|---|---|-----|
| Foot-underside coplanarity (flatness ⟂ A) | ±1.5 mm | frame sits flat on the floor, minimal shim |
| Upright plumb (perpendicularity to A) | ±2 mm over 2,296 mm (≈0.05°) | totes + corridor stay square |
| Frame diagonal square (Δ of the two diagonals) | ±3 mm | a true rectangular box |
| Foot-plate M12 hole pattern (100 mm PCD) | ±0.5 mm | floor-anchor clearance |
| Front-bar seat / hanger-pocket Z position | ±2 mm | bars seat cleanly + the wall holes align |
| Exterior backing-plate M12 holes (to its hanger) | ±1 mm | M12×70 through-bolt clearance |
| Corridor clear width (between the inner uprights) | +2 / −0 mm | the <!-- BEGIN fact:corridor_width_mm -->270<!-- END fact:corridor_width_mm -->mm plumbing corridor must not pinch |
| Rear-panel bracket Z position (on the back uprights) | ±2 mm | plumbing-panel mount aligns |
| Side-panel pipe-run L-bracket landing (post inner face) | ±2 mm | the support boards seat flush |

General (unspecified) dimensions: ISO 13920 Class B. Break sharp edges; deburr all drilled holes.

---

### 3.7 Assembly + Weld Sequence

The frame is a **shop-welded box that bolts out in the field** — deliberately, so the only hot work is the
deep 4-leg weldment (§3.5, W1–W6). Everything hung on it afterward — the wall hangers, the retaining bars,
the corridor-panel and pipe-run brackets — attaches with fasteners (J1–J9), so the fit-out and the tote
loading happen on a **finished, painted frame with no welding on-site.** Build in four phases:

**Phase 1 — Shop-weld the deep 4-leg box (the only weldment).**

1. **Fit-up in a jig** referencing the datums (§3.6): the four foot undersides on the flat table = datum A, the
   front-upright faces = B, the corridor centerline = C. Clamp the four uprights + the top/bottom rings; set
   the box square.
2. **Tack, then check square before finish-welding** — verify the diagonals and upright plumb are inside the
   §3.6 tolerances while the joints are still only tacked and correctable. A weldment pulls toward each bead,
   so distortion is controlled by *balanced, symmetric* welding, not by fixing it afterward
   ([TWI — distortion control](https://www.twi-global.com/technical-knowledge/job-knowledge/distortion-control-prevention-by-fabrication-035)).
3. **Finish-weld in a balanced order:** ring-to-upright joints in a back-step / alternate-corner pattern so heat
   input stays symmetric about datum C; weld the four feet with the frame held down on the flat table so the
   undersides stay coplanar to A (the frame's seat). Then add the smaller weldments — the bar-end cleats (W3),
   the weld-on lash-ring bases (W4), and the ribbon cross-beams (W6).
4. **Grind the zinc back at every weld zone** (galvanized/primed stock burns dirty), welds per §3.5 (E70xx).
5. **Post-weld: re-check the §3.6 tolerances**, then coat (surface-finish spec is set at the fab/quoting stage).

**Phase 2 — Bolt-on fit-out (no hot work, on the finished frame).** TEK-screw the corridor-panel and pipe-run
L-brackets to the posts (J8/J9), then hang their ply boards (J4/J5). Because these are self-drillers into the
post wall, the brackets can be located, adjusted, or replaced on the painted frame without touching a welder.

**Phase 3 — Install + anchor in the container.** Set the box on the floor, shim to datum A, and anchor the four
feet (J1). Through-bolt each wall hanger to the side wall via its exterior backing plate (J3) — the backing
plate spreads the load into the thin corrugated wall.

**Phase 4 — Load the totes + secure.** Direct-stack the four totes, drop the front retaining bars into the wall
hangers, and bolt each bar down — the corridor end to its cleat (J2) and the wall end with its centered
retention bolt (J7). Fit the anti-slip mats under the tote interfaces, then lash down per §4. Transport
removes nothing from the frame; only the tote straps are released at the destination.

### 3.7 Member Cut List

Every cut member of the restraint frame, with its fabrication cut size and quantity. Computed from the
geometry constants by `src/generators/ibc_frame_cutlist.py` (the same math the 3D model builds from, so
the list can't drift from the model); regenerate with `python3 src/generators/ibc_frame_cutlist.py --inject`.
Cut sizes are member-to-member butt lengths — add saw kerf per shop practice.

<!-- BEGIN cutlist -->
| Member | Section / plate | Material | Cut size | Qty | Note |
|---|---|---|---|-----|---|
| Corner upright | 50.8×50.8×3 SHS (2×2×0.120in) | A500 Gr.B | 2,284 mm | 4 | full height; sits on the foot plate (Z12→TOP_Z) |
| Ring rail — Yd (cross) | 50.8×50.8×3 SHS (2×2×0.120in) | A500 Gr.B | 168.4 mm | 4 | 2 rings (top+bottom) × 2 X-faces; butts between uprights |
| Ring rail — X (deep) | 50.8×50.8×3 SHS (2×2×0.120in) | A500 Gr.B | 399.2 mm | 4 | 2 rings × 2 Yd-faces; ties front↔back uprights |
| Front retaining bar | 50×20×3 RHS | A500 Gr.B | 1,042 mm | 8 | 2 per tote face (near+far columns identical length) |
| Foot plate | 150×150×12 plate | A36 plate | 150×150×12 mm | 4 | 4× Ø12mm anchor holes on Ø100 PCD |
| Exterior wall backing plate | 8 mm plate | A36 plate | 60×204.8×8 mm | 8 | one per wall hanger; spreads the M12×70 load into the corrugated wall |
| Wall joist hanger | 4 mm folded plate | A36 plate | back 205 + seat 70, ×60 wide | 8 | Simpson-style U-pocket; folded, not welded |
| Front-bar cleat (J2/W3) | 8 mm angle | A36 plate | leg 90 + upstand 59, ×20 wide | 8 | L-angle: horizontal leg (bar sits on it) + upstand fillet-welded to the upright |
| Rear-panel bracket (D) | 5 mm angle | A36 plate | base 40 + upstand, ×60 tall × 30 wide | 6 | L-bracket TEK-screwed to the back uprights (J8) + panel bolts (J4) |
| Weld-on lashing ring | forged ring + base | — | purchased | 8 | not a cut member — 2 per tier on the lower front bars (W4) |

**Stock (buy sticks; add saw kerf + ~10% drop):**

| Section | Total cut length | ≈ sticks (24 ft) |
|---|---|---|
| 50.8×50.8×3 SHS (uprights + rings) | 11.41 m (37.4 ft) | 2 |
| 50×20×3 RHS (front bars) | 8.34 m (27.3 ft) | 2 |
<!-- END cutlist -->

The fabricated (non-stick) parts — the foot plate, the exterior wall backing plate, the folded wall joist hanger, and the front-bar cleat — are dimensioned 1:1 with their hole patterns and J/W callouts on the [Plate Fabrication Schedule](#8-engineering-drawings) (Plates 1–4).

---

## 4. Securing for Transport

### 4.1 Weld-On Lashing Rings

| Parameter | Value |
|---|---|
| Quantity | 8 total (4 per tier) |
| Type | 1½" (38mm) ID weld-on tie-down ring, ½" thick, zinc-plated steel |
| Working load limit | 6,600 lb (2,994 kg) ring — assembly strap-limited to 3,333 lb (~1,512 kg) |
| Mounting | Fillet-welded directly to the front retaining bars (integrated weld base — no separate plate) |
| Supplier | McMaster-Carr #3028T31 |

### 4.2 Ratchet Straps

| Parameter | Value |
|---|---|
| Type | 2" (50mm) ratchet strap (Keeper 82827) |
| Working load limit | 3,333 lb (~1,512 kg) |
| Routing | ring to ring, over IBC top, 1 strap per tier per side |
| Total straps | 4 (2 per tier) |
| Pre-transport | Tighten all straps; re-check tension after 50 km |

### 4.3 Wall Trapping

There is no anti-rotation lip. The direct-stacked totes are trapped
laterally by the container side walls (30mm gap each side) and the sealed end wall;
the front retaining bars + lashing-ring ratchet straps restrain the open front and
provide vertical tie-down. Together these restrain both tiers in all six DOF.

### 4.4 Anti-Slip Matting

| Parameter | Value |
|---|---|
| Quantity | 4 (one under each tote: 2 on the container floor, 2 on the lower-tote cage tops) |
| Type | Certified anti-slip cargo matting, **μ ≥ 0.6** ([EN 12195-1 Annex B](https://res.jedermann.de/data/downloads/KB029-2_Gesamtdokument.pdf)) — cut to the tote pallet footprint |
| Purpose | Raises the sliding friction that credits against the forward thrust (μ 0.2→0.6), tripling the front-bar margin (SF 1.59→4.77, §3.4) — the primary "totes don't shift" lever |
| Note | Must be a **tested/certified** μ ≥ 0.6 product; untested rubber caps at μ 0.2 |

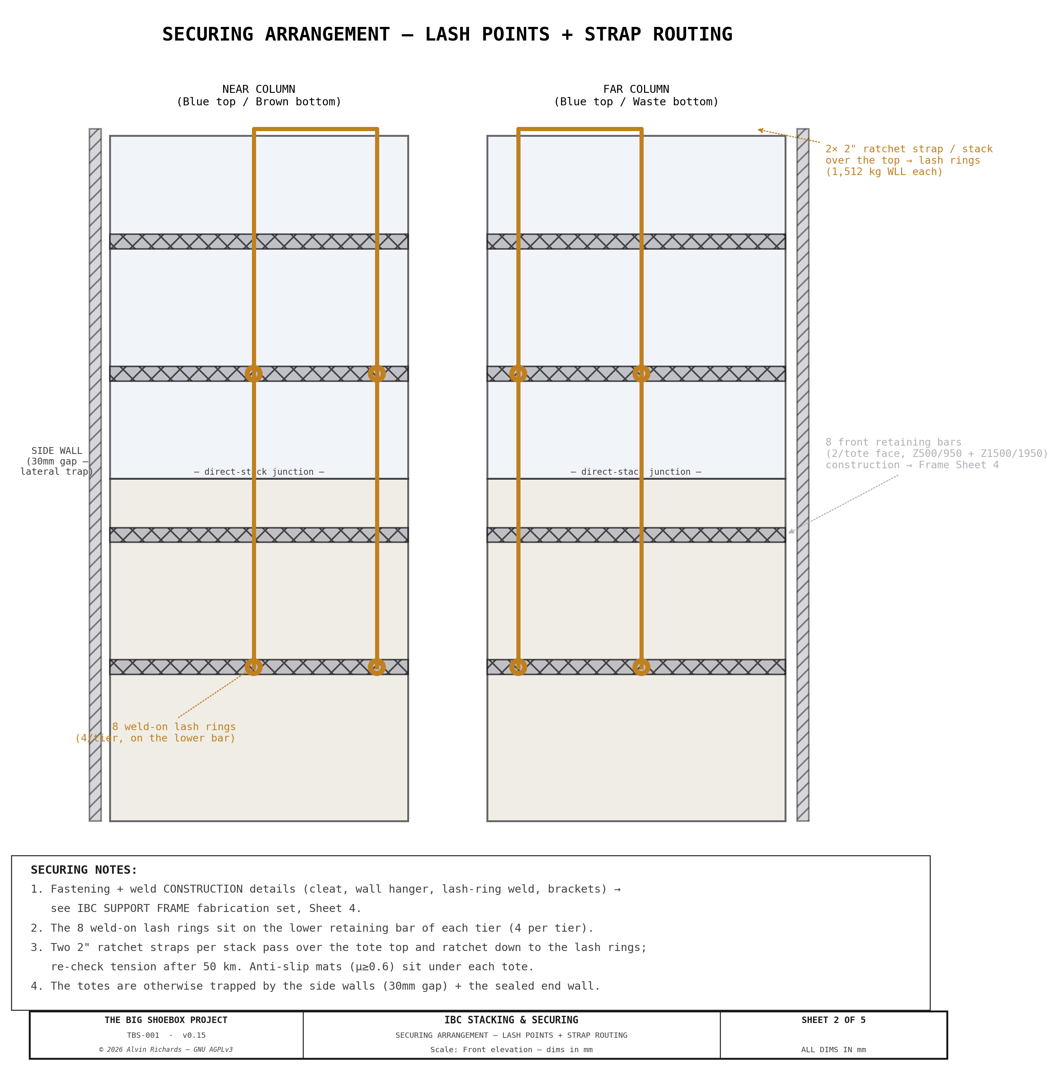
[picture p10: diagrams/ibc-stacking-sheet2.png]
TBS-001 IBC Stacking — Sheet 2: Securing Arrangement


---

## 5. Drain Valve Access

The bottom-tier drain valves (DN50 butterfly, corridor-facing) are reached
directly from the **open corridor front** — with the Corridor Plumbing Panel moved forward and
no load-bearing base frame, there are no removable access gates. The operator reaches in
from the right walkway.

---

## 6. External Bulkhead Ports

Three 2" NPT bulkhead ports penetrate the sealed end wall on the container
centerline — **X1** (Blue fill), **X3** (Brown drain), and **X4** (Waste drain) —
so all four totes fill and drain without opening the cargo doors. X1 gravity-feeds
an internal tee that side-enters both Blue totes near the top, so one external hose
fills both. Each penetration is backed by a welded wall reinforcing plate that
spreads its load into the corrugated wall (the same approach as the frame's
exterior backing plates, [§3.2](#32-frame-specification)).

The port elevations are the diagram-of-record (see [§8 Sheet 3](#8-engineering-drawings)).
The bulkhead fittings, camlock, and seals are specified in the
[Water System Report](water-system-report.md) §5 and §7; the bulkhead BOM,
including the reinforcing plates, is in the
[master shopping list](master-shopping-list.md). (These end-wall ports are
distinct from the two equipment **Plumbing Panels** — Corridor and Pinhole Wall —
in [§7](#7-internal-plumbing).)

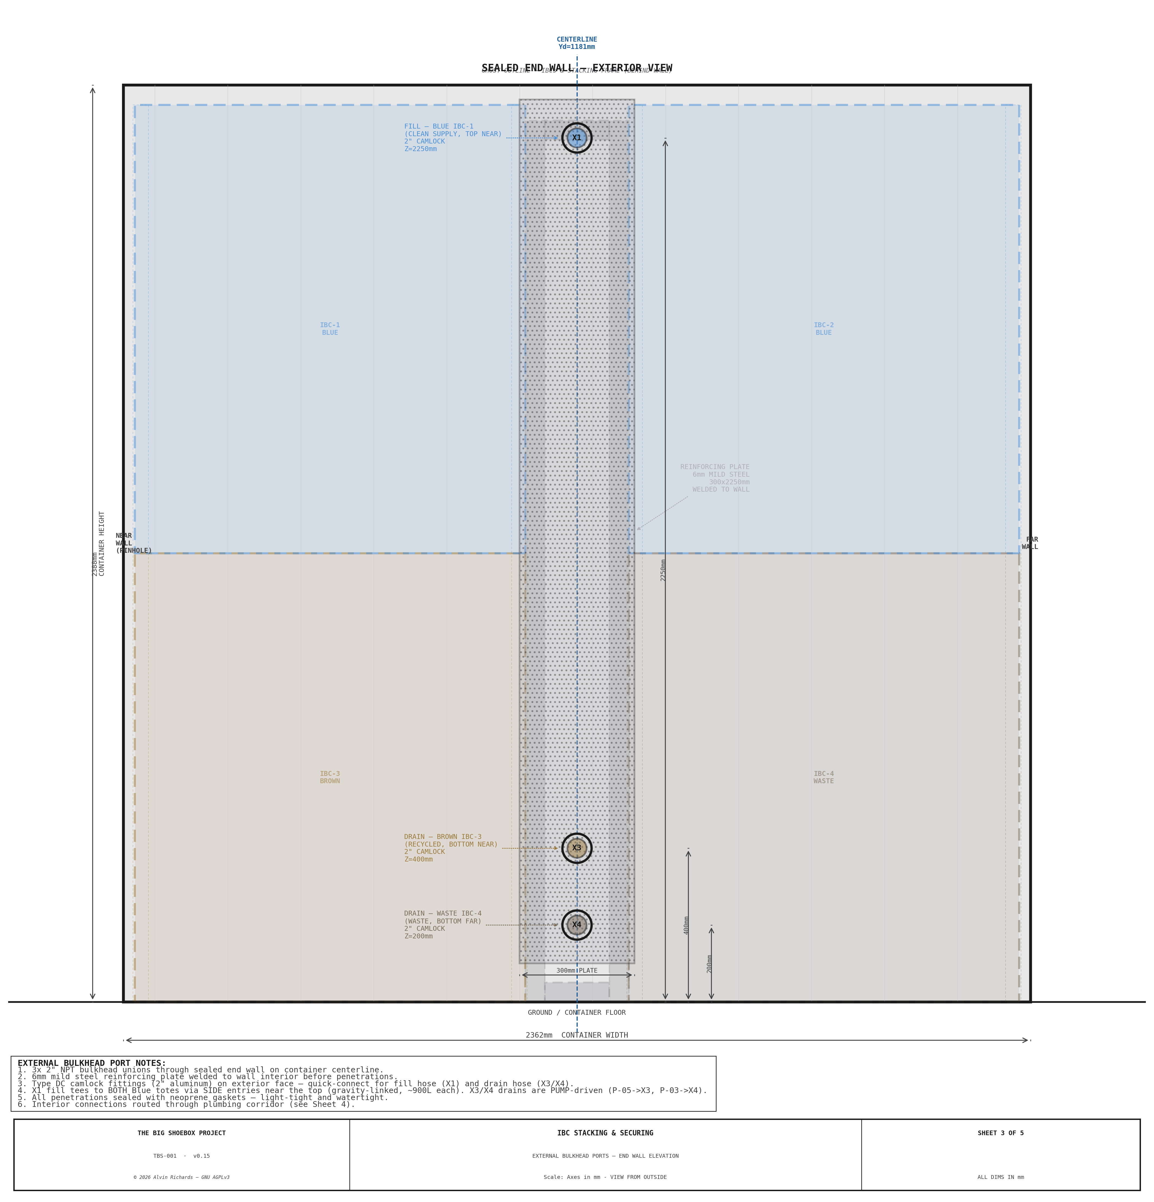
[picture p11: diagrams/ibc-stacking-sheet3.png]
TBS-001 IBC Stacking — Sheet 3: External Bulkhead Ports Elevation


---

## 7. Internal Plumbing

All internal supply and return lines route through the <!-- BEGIN fact:corridor_width_mm -->270<!-- END fact:corridor_width_mm -->mm plumbing corridor
between the near and far IBC columns, reaching each tote's corridor-facing DN50
butterfly valve (S60×6 thread). The pipe specification, the per-circuit routing
(X1 Blue gravity-fill teed to both top totes, X3 Brown and X4 Waste pumped drains,
and the recycle returns), and the valve schedule are specified in the
[Water System Report](water-system-report.md) §4–§5 and §7. The pumps and
diverter valves that drive those circuits — on the **Corridor Plumbing Panel**
(plywood, at the front (cargo-door) mouth of the corridor, bolted to the
deep-box frame, see [§3.2](#32-frame-specification)) — together with the
3-stage filter bank on the **Pinhole Wall Plumbing Panel** are specified in the
[Plumbing Report](plumbing-report.md). This report treats the corridor plumbing
and both panels only as loads the stacking frame carries.

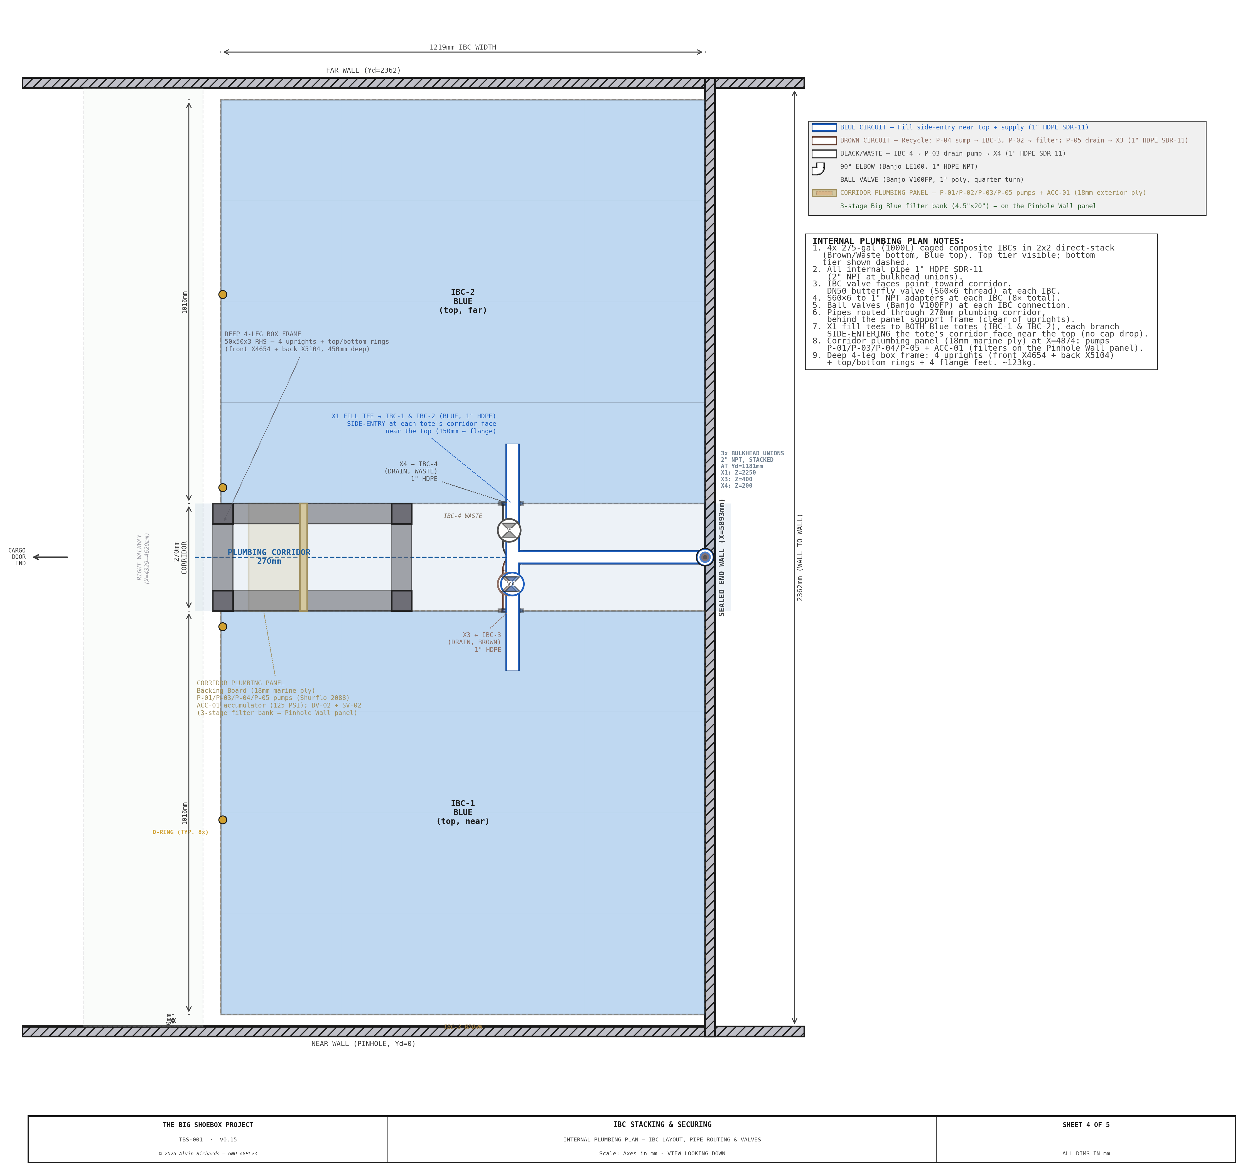
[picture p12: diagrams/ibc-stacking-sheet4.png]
TBS-001 IBC Stacking — Sheet 4: Internal Plumbing Plan View


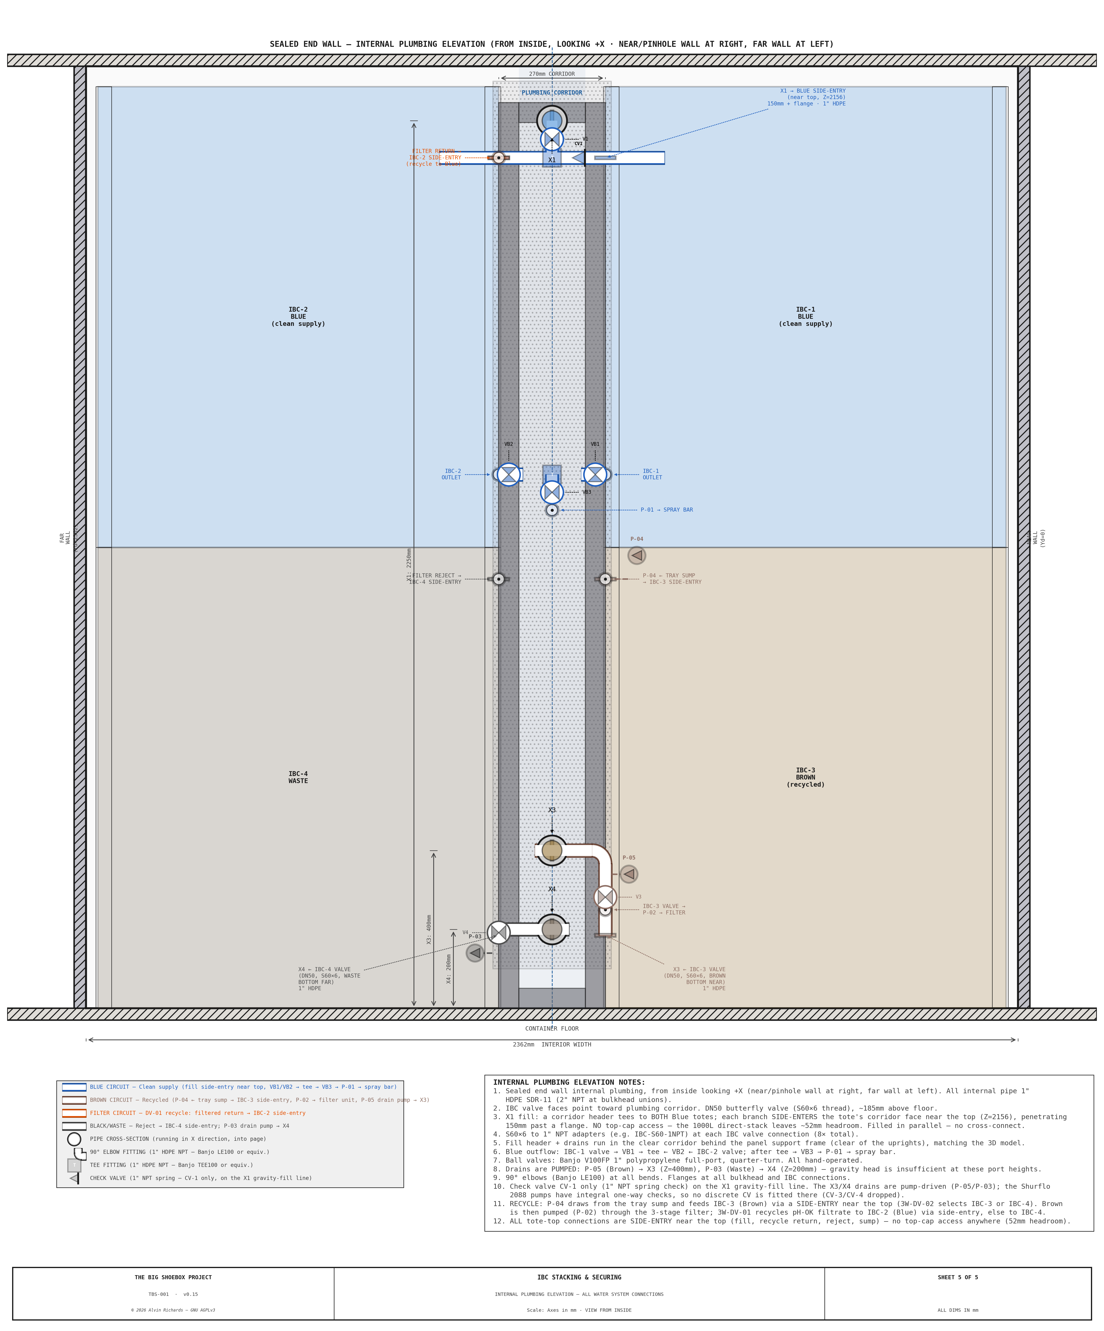
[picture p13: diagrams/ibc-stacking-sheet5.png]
TBS-001 IBC Stacking — Sheet 5: Internal Plumbing Elevation


---

## 8. Engineering Drawings

The construction drawings cover the IBC system across two drawing sets. They are shown inline in the
relevant sections above; the full set is collected here and in [Engineering Diagrams](engineering-diagrams.md).

<!-- brochure:skip -->

### IBC Stacking & Securing (5 sheets)

**Sheet 1 — Cross-section elevation: 2-tier direct-stack, restraint deep 4-leg box, front retaining bars + wall hangers, direct-stack junction, <!-- BEGIN fact:ibc_ceiling_clearance_mm -->52<!-- END fact:ibc_ceiling_clearance_mm -->mm clearance**
TBS-001 IBC Stacking — Sheet 1

**Sheet 2 — Securing arrangement: the 8 lash-point locations + strap routing over each stack (rigger's plan; fastening + weld construction details → IBC Support Frame Sheet 4)**
TBS-001 IBC Stacking — Sheet 2: Securing Arrangement

**Sheet 3 — External bulkhead ports: Sealed end wall elevation with 3× ports**
TBS-001 IBC Stacking — Sheet 3

**Sheet 4 — Internal plumbing plan view: IBC layout, pipe routing, valves, Corridor Plumbing Panel**
TBS-001 IBC Stacking — Sheet 4

**Sheet 5 — Internal plumbing elevation: Pipe routing from IBCs to bulkhead unions**
TBS-001 IBC Stacking — Sheet 5

### IBC Support Frame Fabrication (6 sheets + 2 plate-schedule sheets)

**Sheet 1 — Front elevation: deep-box uprights (front pair, back pair 450mm behind), floor feet, front retaining bars with their J2 corridor-end L-cleats (1 horizontal bolt) and J3/J7 wall-hanger bolts, weld-on lashing rings, direct-stack junction**
TBS-001 IBC Frame — Sheet 1

**Sheet 2 — Side elevation: deep 4-leg box (front + back uprights + top/bottom rings) + front bars (end-on) + the walkway cantilever arm with its J6 bearing-type connection (2× M12 run through the post ABOVE the arm — end-plate + rear backing plate) + the plywood mounting tabs on the back upright**
TBS-001 IBC Frame — Sheet 2

**Sheet 3 — Plan view: deep 4-leg box (4 legs + ring perimeter) + retaining bars + 4 floor feet + IBC footprints + corridor + walkway arms**
TBS-001 IBC Frame — Sheet 3

**Sheet 4 — Fabrication details: DETAIL A wall joist hanger (per-bar, 2-bolt, 50mm clearance), B bar→upright cleat, C weld-on lashing ring, D rear-panel bracket, E side-panel pipe-run L-bracket — each with weld (W) + fastener (J) callouts. (The walkway arm→upright J6 connection is drawn in full on Sheet 5, so its former Detail F here was dropped as a duplicate.)**
TBS-001 IBC Frame — Sheet 4

**Sheet 5 — Walkway cantilever arm fabrication (×2, off the IBC front uprights): VIEW A dimensioned side elevation (arm reaching 325 mm from the upright to the tip, half-lapping over both long beams — notch widths + gaps 50.8 / 198.4 / 50.8 / 17 arm-steel + 8 end-plate = 325 reach, half-lap depth 20 of the 25.4; J6 bolted end-plate), PLAN VIEW (each notch a full-width half-lap, beam width 50.8; the plate→post through-bolts shown at the upright end), and the END-PLATE / rear-backing-plate detail (65 × 190, 2× Ø13 for M12 **both above the arm** at 30 spacing — bearing-type; the corridor bottom frame rail is ghost-marked behind the plate's lower edge with no bolt near it — 5 mm fillet all round, arm weld footprint shadow-marked)**
TBS-001 IBC Frame — Sheet 5

**Sheet 6 — Weld map: a schematic front elevation with every fillet weld W1–W6 ticked to where it lands on the frame (W1 upright↔ring, W2 foot↔upright, W3 bar-end cleat↔upright, W4 lashing ring↔bar, W5 wall-hanger seat↔back-plate, W6 ribbon cross-beam↔walkway bearer), alongside the full weld schedule (size, all-around vs both-legs, qty, and the governing SF)**
TBS-001 IBC Frame — Sheet 6

**Plate Schedule Sheet 1 — Structural plates drawn 1:1 for the shop: PLATE 1 IBC floor foot (150×150×12, 4× Ø14 @ 100 sq PCD), PLATE 2 wall-hanger exterior backing (60×205×8, 2× Ø14 @ 169), PLATE 3 wall-hanger pocket (folded 4 mm back-plate + 70 seat, J3 + J7 holes) — each with outline dims, hole Ø + center positions, thickness, material, and qty**
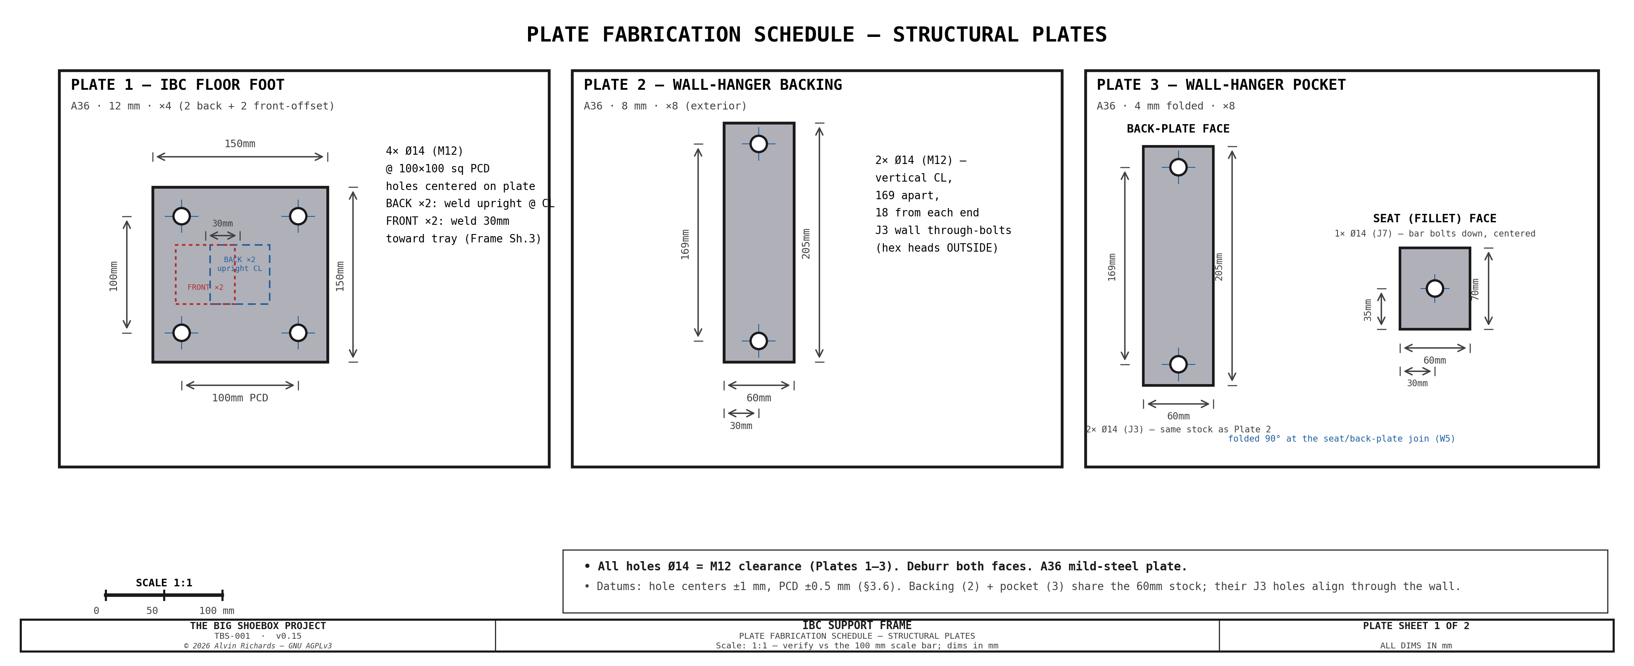
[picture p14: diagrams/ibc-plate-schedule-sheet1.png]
TBS-001 IBC Frame — Plate Schedule Sheet 1


**Plate Schedule Sheet 2 — Bar-end L-cleat + welded angle brackets drawn 1:1: PLATE 4 bar-end L-cleat (8 mm L-angle, 90 long; the bar drops into the corner, 1 horizontal Ø14 for M12×65 through the vertical leg + the bar's 50 mm web, J2/W3), PLATE 5 rear-panel tab (50×50×5, Ø9/M8, J4), PLATE 6 side-panel pipe-run L-bracket (1×1×⅛, Ø7/¼-20, J5) — L-section end + drilled-leg face for each**
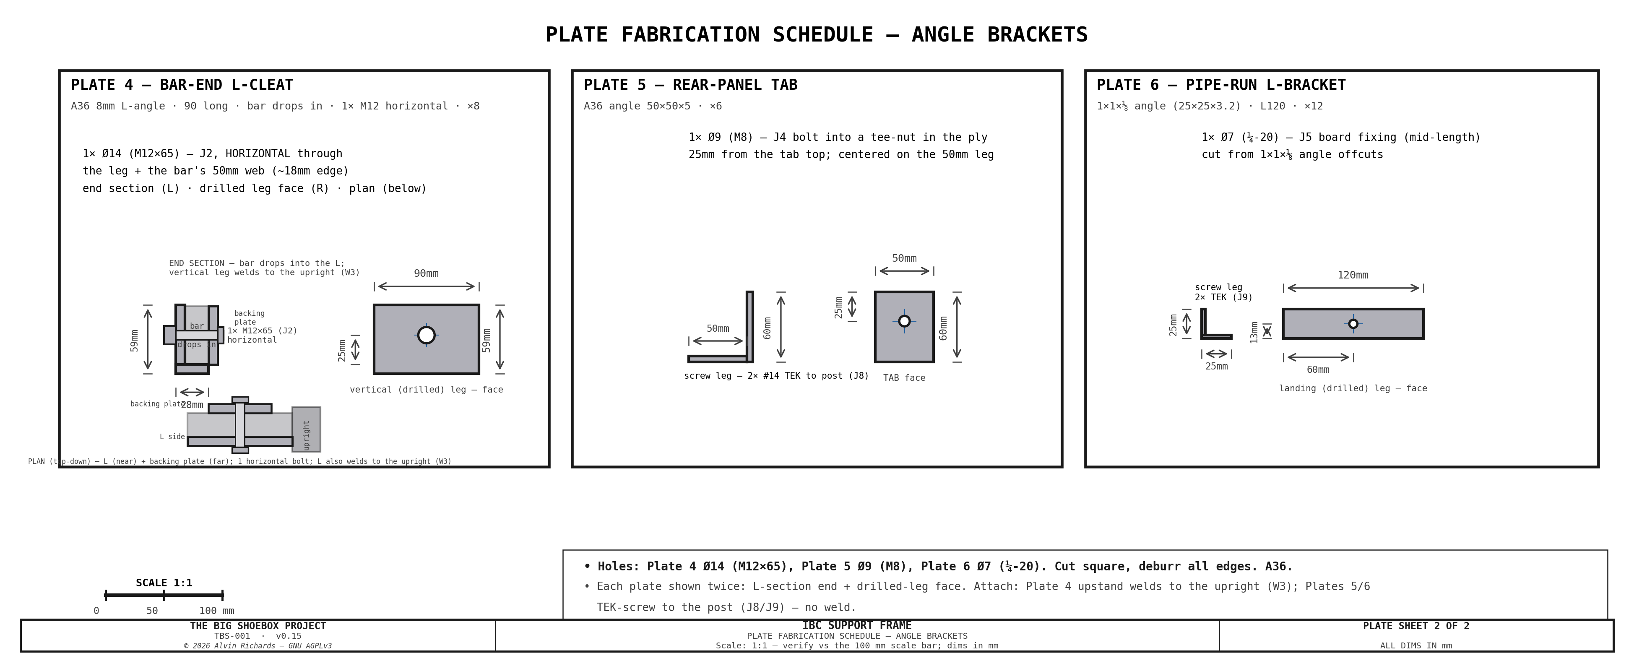
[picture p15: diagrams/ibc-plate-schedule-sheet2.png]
TBS-001 IBC Frame — Plate Schedule Sheet 2


<!-- brochure:endskip -->

Full drawings also appear in [Engineering Diagrams](engineering-diagrams.md) §15
(stacking) and §17 (frame fabrication).

---

## 9. Parts List

### 9.1 Stacking Frame

<!-- BEGIN parts:ibc-frame -->
| Item | Spec | Qty | Supplier | Est. cost |
|---|---|-----|---|---|
| 2×2×0.120in steel SHS (6 m bulk lengths) | Deep 4-leg box uprights (front + back pair) + top/bottom rings + front retaining bars + panel-mount rail (~24 m; front retaining bars DOUBLED to 8 (2/tote face, 50×20×3, ~8.8 m) after the EN 12195-1 loaded-transport case — ibc_frame_load.py; the 50×20×3 bars are a separate section from the 2×2 uprights, lumped here as bulk steel pending the Phase-D split). MATERIAL = 2×2×⅛in A500 square tube (US equiv, confirmed 2026-08-01). SOURCING: full 6m/20-24ft sticks minimize splices but ship only by freight — online cut-to-size shops cap at 96in (UPS max: AllMetals/InchOfMetal 96in, Speedy $7.27/ft cut-retail ≤90in). So the ~$120-180 (4×$30-45) est is realistic BULK full-length pricing (~$1.50-2.50/ft); firm it from a local steel-yard / MetalsDepot 24ft freight quote — NOT an online cut-to-size lookup (which overprices bulk ~3×). | 4 ea | Metal Supermarkets | $120–$180 |
| 12mm steel plate, 150 × 150 cut | Deep-box upright floor flange feet (one per leg; front feet reach under the tray) | 4 ea | Metal Supermarkets | $20–$40 |
| 4mm folded plate | Simpson-style U-pocket wall joist hangers — 8 IDENTICAL 2-bolt hangers, one per front retaining bar (the pair uses identical hangers for fab simplicity — 2026-08-14). Each through-bolted (2× M12×70) to its own exterior 60×205×8 backing plate on the outside of the container side wall. Wall penetrations unchanged at 16 (8 hangers × 2 = old 4 × 4). | 8 ea | Local fab | $60–$100 |
| [Weld-on lashing ring, 1½" ID](https://www.mcmaster.com/3028t31/) (3028T31) | Zinc-plated steel weld-on tie-down rings — 1½" (38mm) inside × ½" thick, 6,600 lb WLL; fillet-welded to the front retaining bars (4 per tier × 2 tiers). Integrated weld base — no separate mount plate. Ring (6,600 lb) exceeds the 2"-strap-limited 3,333 lb (~1,512 kg) assembly WLL. | 8 ea | McMaster-Carr | $40 |
| [2" (50mm) ratchet strap, 3,333 lb WLL](https://www.homedepot.com/p/331257450) (82827) | Transport securing, over each stack (2 per stack × 2 stacks). Keeper 82827 heavy-duty 2"×27ft, 3,333 lb (~1,512 kg) WLL / 10,000 lb break — width corrected 25mm→50mm (a 1" strap can't hold the 1,100 kg the restraint needs). EN 12195-1 vert tie-down SF 3.1 loaded (ibc_frame_load.py). | 4 ea | Home Depot | $68 |
| Certified anti-slip cargo matting (μ≥0.6) | Certified anti-slip rubber matting under each tote interface (4: 2 on the container floor + 2 on the lower-tote cage tops). Raises the sliding friction μ 0.2→0.6 per EN 12195-1 Annex B, cutting the front-bar forward-blocking demand ~3× (bar SF 1.59 bar-alone → 4.77 with mat; ibc_frame_load.py). Cut to the tote pallet footprint (~1.0×1.2 m). REQUIRES a certified/tested μ≥0.6 product (untested rubber caps at μ 0.2). | 4 ea | Uline / cargo-securing supplier | $40–$80 |
| [Self-drilling structural screw, #14×3¼″ winged, 410 SS](https://www.fastenersplus.com/products/14-x-3-1-4-self-drilling-flat-head-screw-with-wings-410-stainless-steel-pkg-100) (F14C325FDC) | 4 deep-box flange feet × 4 each. Self-drills the 6mm foot plate + 28mm plywood and taps the ~4mm steel crossmember — LAND EACH FOOT OVER A CROSSMEMBER (~450mm centers). Wings ream the plate/ply clearance then snap off at the steel. 410 SS (martensitic — self-drills steel; 316 can't). The IBC dead load bears in compression on the floor; the screws resist sliding/uplift only. Through-bolt 316 + backing nut instead where a crossmember underside is reachable. $1.02/ea (100-pk). | 16 ea | Fasteners Plus / ASMC | $16 |
| [M12×65 hex bolt, 18-8 SS (partial thread)](https://www.mcmaster.com/92800A481/) (92800A481) | Front-bar fasteners: 8 = corridor-end L-cleats (J2, 1 HORIZONTAL bolt per cleat × 8 bars — through the L's vertical leg + the bar's TALL 50mm web, so the Ø14 hole gets ~18mm edge; the L-corner carries the load, the bolt secures the unsupported direction — redesigned from 2 vertical bolts, 2026-08-18) + 8 = wall-end vertical retention bolts (J7, 1 CENTERED per bar, down through the bar into the pocket seat, ~58mm stack). M12×65 reused for BOTH (>40mm needed; partial-thread smooth shank spans the grip; the 65 length is long for J2's ~36mm grip but avoids a second SKU — pad/trim at fab). McMaster 92800A481: M12×1.75 × 65mm 18-8 SS partial-thread hex — firm $9.95/pack of 5 (2026-08-17; 16 used → 4 packs). Full-thread alternative: 92314A595 $11.92/5. 18-8 SS here (vs the Gr.8.8 zinc M12×70 91280A732 used for the dry structural wall through-bolts) is a deliberate DUTY choice, not a duplicate SKU: the J2/J7 cleats sit in the wet plumbing corridor, so stainless resists the damp; the zinc M12×70 stays on the dry wall-hanger/walkway/film joints. (The J2/J7 cleat stays ×65 — its ~36–58mm cleat-leg grip differs from the ~42–54mm wall-through grip, and it's a different material line.) | 16 ea | McMaster-Carr | $32 |
| [M12×70 hex through-bolt, Grade 8.8 zinc, partial-thread](https://www.mcmaster.com/91280A732/) (91280A732) | IBC wall-hanger through-bolts (2 each × 8 hangers = 16) — through the corrugated side wall to the exterior 60×205×8 backing plate (hex heads outside). Grip = 8mm plate + ~30mm corrugation + 4mm hanger flange ≈ 42–54mm → M12×70, the single standardized zinc wall length (2026-09-07 — covers all 42–54mm wall grips with proper nut engagement; the fully-threaded M12×40 could not span it). $17.36/pack of 10 → 2 packs for 16. Pad with M12 flat washers to the grip. | 16 ea | McMaster-Carr | $28 |
| [M12 hex nut, plain](https://www.mcmaster.com/90591A181/) (90591A181) | Plain hex nut (inside the container) — M12×70 wall-hanger through-bolts (+ split lock washer). $12.78/pack of 50. Pitch M12×1.75 coarse — confirmed vs 90591A181 PDF 2026-07-29. | 16 ea | McMaster-Carr | $4 |
| [M12 flat washer, zinc](https://www.mcmaster.com/91166a290/) (91166A290) | Flat washers, M12×70 wall-hanger bolts — 2 functional + 2 shim/bolt (shims pad the grip if corrugation <30mm). $9.71/pack of 100. | 64 ea | McMaster-Carr | $6 |
| [M12 split lock washer, zinc](https://www.mcmaster.com/91202A246/) (91202A246) | Split lock washer under each nut — M12×70 wall-hanger bolts (plain nut + split = locked). $11.97/pack of 100. | 16 ea | McMaster-Carr | $2 |
| Steel backing plate 60×205×8mm | Exterior wall backing plates — 8 identical, one per 2-bolt hanger — flat 60×205×8mm steel on the OUTSIDE of the container side wall (hex heads outside), 2× M12 holes; spreads the totes' transport thrust into the thin corrugated wall so the through-bolts can't pull through. | 8 ea | Metal Supermarkets | $32–$56 |
| L-cleat nut backing plate 40×50×8mm | Small nut-side spreader plate (~40×50×8mm A36) on the bar's FAR web at each L-cleat through-bolt — 8 corridor-end (J2) + 8 wall-end (J7). The single horizontal M12 nut bears on this plate instead of the thin (3mm) RHS bar wall, so the wall can't dish (2026-08-18). Cut from A36 plate offcuts. | 16 ea | Metal Supermarkets | $10–$19 |
| Welding / fabrication (frame assembly) | ~14–20 hrs labor (deep 4-leg box — the ring/back-upright welds sit at the upper end of the range) | 1 lot | Local fab | $688–$1,018 |
| Primer + paint | Anti-corrosion coating | 1 lot | Hardware store | $30–$50 |
| Right walkway center cantilever arms (solid bar) | SOLID 2×1in (50.8×25.4mm) mild-steel flat bar, ~320mm each — the 2 arms that pick the walkway rectangle up at mid-span off the IBC front uprights. Solid (not tube) so the half-lap notch keeps its strength: notch REBALANCED to the moment — deep arm notch at the tip (M≈30 Nm, arm keeps 5.4mm), shallow at the post end (M≈334 Nm, arm keeps 16mm, SF≈1.6 — the outer beam takes the deep notch as a bearing SEAT and spans simply-supported on its full section; ibc_frame_load.arm_notch_check + outer_beam_frame_check). FIRM: Metal Supermarkets 2×1 solid bar $91.32 / 36in cut (one stick covers both arms + spare), $45.66/arm — checked 2026-08-16. Retail cut-to-size; a steel-yard bulk stick would be cheaper but the min-cut is fine for 2 short pieces. | 2 ea | Metal Supermarkets | $91 |
| [M12×100 hex through-bolt, Grade 8.8 zinc](https://www.mcmaster.com/91280A770/) (91280A770) | J6 walkway-arm end-plate joint — 2 per arm × 2 arms, a CENTRAL vertical column (Yd centerline) through the front upright into the rear backing plate: BEARING-TYPE, both bolts ABOVE the arm (30mm apart) as a tension group with the plate bearing compression at its base — clears the welded arm + the corridor bottom rail; the central column keeps max edge distance on both the plate and the post. Runs with a nyloc nut + an internal crush sleeve so torque can't dish the hollow upright. McMaster 91280A770 $18.64/5-pack firm (2026-10-01). | 4 ea | McMaster-Carr | $15 |
| Walkway-arm end + backing plates (J6) | 65×190×8mm mild-steel plate (arm 50.8 wide + weld toe; 190 tall so the raised upper bolt keeps ≥1.5·D edge to the plate top), 2× Ø13 for M12 in a central column, both above the arm at 30mm pitch — 2 end-plates (welded to the arm ends, 5mm fillet all round) + 2 rear backing plates (plain), one set per arm. Cut+drill from A36 flat plate. | 4 ea | Local fab | $12–$24 |
| Walkway-arm J6 crush sleeves | Internal spacer/crush tube (~Ø14 ID over the M12) cut to the upright bore depth — one per J6 through-bolt (2/arm × 2) so tightening can't collapse the hollow RHS upright. Cut from steel tube offcut. | 4 ea | Local fab | $3–$6 |
| [Half-lap hold-down screws (#14 TEK + washer)](https://www.mcmaster.com/90822A620/) (90822A620) | 1× #14 self-drilling TEK screw + SS flat washer per half-lap (4 total: 2 arms × 2 crossings) — driven from the underside through a Ø7 clearance hole in the long beam, self-tapping into the SOLID arm above, so the beam is positively secured to the bearing seat (anti-lift/anti-slide). Head clears the traveling spray beam (~6.6mm). The SAME #14×1 HWH 410-SS TEK as the J8/J9 bracket screws (McMaster 90822A620 $12.88/25) + a 1/4 SS flat washer (McMaster 92141A223 $13.48/100) under each head. Firm 2026-09-07. | 4 ea | McMaster-Carr | $3 |
| **Ibc-Frame total** | | | | **$1,319–$1,878** |
<!-- END parts:ibc-frame -->

### 9.2 IBC Totes

| Item | Specification | Qty | Est. cost (USD) |
|---|---|-----|---|
| 1,000 L caged composite IBC tote (Schütz Ecobulk MX 1000 or equiv.) | New or reconditioned US 48×40 caged composite (~65 kg) | 4 | $300–$900 |
| **IBC subtotal** | | | **$300–$900** |

The corridor and bulkhead **plumbing parts** (pipe, valves, fittings, camlock,
bulkhead unions, reinforcing plates) are budgeted in the
[Water System Report](water-system-report.md) §8 and the
[master shopping list](master-shopping-list.md), not here — this BOM covers only
the stacking structure and the totes it restrains.

### 9.3 Cost Summary

| Assembly | Low estimate | High estimate |
|---|---|---|
| Stacking frame (restraint deep 4-leg box) | <!-- BEGIN costing:ibc-frame-low -->$1,319<!-- END costing:ibc-frame-low --> | <!-- BEGIN costing:ibc-frame-high -->$1,879<!-- END costing:ibc-frame-high --> |
| IBC totes (4×) | $300 | $900 |
| **Total** | **$1,280** | **$2,405** |

---

## 10. Maintenance Schedule

| Interval | Task |
|---|---|
| Every use | Visually inspect ratchet strap tension before transport |
| Every 10 prints | Inspect IBC valve seals (DN50 butterfly) for drips; tighten or replace O-ring |
| Every 10 prints | Check external camlock fittings for cross-threading; clean dust caps |
| Every 6 months | Inspect lashing-ring welds for cracking; load-test straps |
| Every 6 months | Inspect lashing rings + ratchet straps for wear; re-tension straps |
| Annually | Inspect frame welds (all joints) for fatigue cracking |
| Annually | Touch up paint on frame where chipped or rusted |
| Annually | Inspect front-bar/wall-hanger bolts and upright floor-anchor bolts for loosening; re-torque to spec |
| Annually | Flush all internal pipes with clean water; inspect for biofilm |
| As needed | Replace camlock gaskets if leaking |
| As needed | Clean IBC interiors between circuit changes (bleach rinse + water flush) |

---

## 11. Sources

| Item | Source |
|---|---|
| Schütz Ecobulk MX 1000 L IBC | [Schütz product catalog](https://www.schuetz-packaging.net/schuetz-usa/en/ibcs/ecobulk/ecobulk-mx/) — US 48×40 composite tote, DN50 valve, UN31HA1/Y (all four totes are this size; "600 L"/"640 L" are fill levels, not tote sizes) |
| Weld-on lashing ring | [McMaster-Carr #3028T31](https://www.mcmaster.com/3028t31/) — 1½" ID, ½" thick, 6,600 lb WLL |
| Plumbing fittings, pipe, valves, camlock, pumps | Specified and sourced in the [Water System Report](water-system-report.md) §11 and [Plumbing Report](plumbing-report.md) §11 |
| Water system architecture | [Water System Report](water-system-report.md) §3 |
| IBC layout and stacking | [Equipment Layout Report](equipment-layout-report.md) §5 |
| Frame fabrication drawings | [§8 — Engineering Drawings](#8-engineering-drawings) (this report) · [All Diagrams](all-diagrams.md) |
| Plumbing panel specification | [Plumbing Report](plumbing-report.md) |

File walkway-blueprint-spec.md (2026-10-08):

<!-- SPDX-License-Identifier: AGPL-3.0-only -->
<!-- © 2026 Alvin Richards -->
<!-- Design spec / scope — NOT a published TBS artifact (not registered in publish.sh). -->

# Walkway System — Definitive Blueprint Spec

**Status:** COMPLETE — Phases 0–E landed on branch **`walkway-bp`** (2026-08-19). The design-of-record
table below is refreshed to the as-built design; the living source is `walkway-report.md` + `tbs_constants.py`.
**Purpose:** upgrade the perimeter walkway from arrangement-schematic to a **dimensionally-exact,
fabricator-ready** drawing package — the third subsystem to take the film-plane-corner milestone
standard (dimensioned details + fastener schedule + weld schedule + datums/GD&T + a computed load
case), driven parametrically from `tbs_constants` so it can't drift. Follows
[`ibc-frame-blueprint-spec.md`](ibc-frame-blueprint-spec.md) and
[`fp-corner-blueprint-spec.md`](fp-corner-blueprint-spec.md) as the templates.

The distinguishing feature of this pass: four **real geometry fixes** (Phase 0) must land in the 3D
model *before* dimensioning, because you cannot blueprint geometry that is about to move.

## Locked decisions (2026-08-18)

1. **Fix first, then dimension.** Resolve all four geometry fixes in the generators, regenerate,
   `--send`, verify with `check_interference.py --solids`, ALVIN saves + uploads the corrected models —
   **then** dimension the corrected geometry. (2026-08-18.)
2. **Structural load basis = US IBC/OSHA.** IBC 2021 Table 1607.1 "walkways and elevated platforms" =
   **60 psf (2.87 kPa) uniform** + a **300 lbf (1.33 kN) concentrated** footfall on a small area
   (ASCE 7 / OSHA 1910.22). US codes for a US build; cited in the validation table. (2026-08-18.)
3. **One branch, single phased pass** (`walkway-bp`): Phase 0 → 1 → A → B → C → D → E, mirroring the
   IBC-frame blueprint one-to-one.
4. **Scope boundary — the walkway owns every cantilever EXCEPT the two IBC-post arms.** The walkway
   blueprint OWNS: the near/far wall-cantilever gusset brackets, the 5 left floor-leg cantilever
   brackets, the right cantilever-rectangle (long + end + cranked beams), the wall cleats, the grating
   cut-plans, and the walkway side of the combined corner plate. **The two center cantilever arms that
   mount on the IBC front uprights — and their J6 connection — are owned by the IBC-frame component**
   ([`ibc-frame-blueprint-spec.md`](ibc-frame-blueprint-spec.md) §3.4–3.6); the walkway blueprint
   cross-references them and does NOT dimension, validate, or cost them. (2026-08-18.) **BOM
   consequence (Phase E):** the `walkway-cantilever-arms`, J6 end/backing-plate, and crush-sleeve lines
   currently sit in the *walkway* parts list — reconcile their placement to the IBC frame (touches the
   IBC-frame total, so do it deliberately, not silently). The **combined corner plate** (shared with the
   film-plane bottom/top rail) is likewise cross-referenced, not silently re-specced.

## Design of record (from `walkway-report.md` + `tbs_constants.py`)

| Element | Spec |
|---|---|
| Deck | 300 mm wide (`WALKWAY_W`), 140 mm high (`WALKWAY_H`) = Z115 arm/bracket top + 25 mm grate (`WALKWAY_GRATE_T`) |
| Grating | 1" (25 mm) molded GRP, vinyl-ester grit — McNichols MS-S-100; 4 removable sections |
| Near/far wall gusset bracket — standard | 8 mm plate (`WALKWAY_BRACKET_T`) vert leg 180 mm (`WALKWAY_BRACKET_H`) + gusset (70 mm reach) + a **2×1×0.120in tube arm** (`WALKWAY_BRACKET_ARM_*`, 300 mm, IBC/OSHA SF 2.10); **3× M12** through-bolt (2+1, ±27) at 457 mm rib centers (`WALKWAY_BRACKET_SPACING`); 100×180×6 exterior reinforcing plate (= the mounting-plate footprint) |
| Near wall gusset bracket — widened | 10 mm plate (`WALKWAY_WIDE_BRACKET_T`) vert leg 200 mm (`WALKWAY_WIDE_BRACKET_H`) + gusset + a **3×1×0.120in tube arm** (500 mm, `WALKWAY_NEAR_WIDE_W`, SF 1.83 defl-governed); **4× M12** (2+2, ±32); 120×200×6 reinforcing plate; ×5 over X1055–3083 |
| Width-transition bearing plate | 40×500×5 flat bar, welded to arm top at each 300↔500 transition (×2) |
| Right cantilever rectangle | 2×1×0.120in (50.8×25.4) A500 RHS closed frame: 2 long beams (`RWK_BEARER_W`, span `C_WID` 2362) + 2 end beams (~143, the 245 mm F1-shortened deck `WALKWAY_RIGHT_W`), soffit Z89.6 (`LEFT_WK_CANT_ARM_Z0`/`RWK_ARM_BOT`) clears the 1½ spray beam by 11.6 mm |
| Cranked inner beam | inner long beam jogged outboard 100 mm (`RWK_CRANK_DX`) over the muslin notch Yd1912–2062 with 100 mm ramps (`RWK_CRANK_*`) — one continuous uncut member |
| Center cantilever arms (×2) — **IBC-frame owned** | **solid** 2×1in bar, half-lapped over both long beams (`RWK_HL_TIP` 95.0 / `RWK_HL_POST` 105.6 rebalanced splits); cantilever off the IBC front uprights (`RWK_X_UP` 4654). Detailed/validated/costed in the **IBC-frame blueprint** (J6); listed here only for the rectangle interface (the mid-span pickup) |
| Combined corner plate (right ×2) | 10 mm plate, 150 mm wide — carries the walkway right beam (70 mm seat) AND the film bottom/top rail (150 mm seat); 4× M12 permanent, interior+exterior sandwich (`fp_combined_corner_plate`) |
| Wall cleat (left corners of right walkway ×2) | 8 mm back-plate + exterior plate + shelf; M12 through-bolt |
| Floor-leg cantilever bracket (left walkway ×5) | 2×2×0.120in SHS post (~115 mm, `LEFT_WK_CANT_POST`) + arm (`LEFT_WK_CANT_ARM_*`): **2×1×0.120in** for the 2 std legs (reach X580, SF 2.06) / **4×1×0.120in** for the 3 drum-exit punch-out legs (reach X880, IBC/OSHA SF 1.99) + 165×60×8 foot plate (F3 outrigger, `LEFT_WK_CANT_FOOT`); **4× #14×2″ 410 SS** screws into ply-over-steel floor (`LEFT_WK_CANT_FOOT_BOLT_N`) |
| Grate retention | 316 SS hold-down clips (near/far/right, 610 mm/24" centers + corners, `WALKWAY_GRATE_CLIP_PITCH`); gravity lift-out (left) |
| Grate cut features | spray-bar slits (30 mm, near+far), left drum-exit punch-out (600 mm, Yd800–1560), near bump-out (500 mm, X1055–3083), muslin notches (100×150, left+right) |

## Load basis — IBC 2021 / ASCE 7 / OSHA 1910.22

| Case | Value | Governs |
|---|---|---|
| Uniform live load | **60 psf = 2.87 kPa** (IBC Table 1607.1, walkways/elevated platforms) | grate span, distributed bracket demand |
| Concentrated load | **300 lbf = 1.33 kN** on a 2"×2" area (ASCE 7 / OSHA 1910.22) | cantilever arm tips, single-footfall worst case |
| Load factor / basis | ASD service check with SF reported; steel Fy = 250 MPa (A500 Gr.B / A36) | all steel elements |

Sources to cite in the validation table: [IBC 2021 §1607 / Table 1607.1](https://codes.iccsafe.org/content/IBC2021P2/chapter-16-structural-design),
[OSHA 1910.22 walking-working surfaces](https://www.osha.gov/laws-regs/regulations/standardnumber/1910/1910.22),
[ASCE 7-22](https://www.asce.org/publications-and-news/asce-7). (Grating capacity from the
[Fibergrate molded-grating load tables](https://www.fibergrate.com/products/molded-gratings/).)

## Phase 0 — Geometry fixes (model + cascade; ALVIN saves/uploads) — PRECONDITION

Resolve each in the generating Python (`src/models/*.py` + `tbs_constants.py`), regenerate, `--send`
into the matching open doc, verify with `check_interference.py --solids` + read-only `eval_ruby`, then
ALVIN saves + uploads. Re-send order **focus-model-first** (walkway before overview/construction).

- [x] **F1 — Shorten the right walkway.** It currently overruns into the film-plane bottom-rail
  support brackets. Pull the right deck / cantilever-rectangle right edge back so it stops clear of
  those brackets. Derive the new right edge from the film-plane bracket X; check IBC-valve/filter/pump
  reach-in access is preserved. (2026-08-17.)
- [x] **F2 — One shared right-corner bracket.** At each near/far RIGHT corner the film-plane beam
  bracket and the walkway right-beam bracket read as two separate brackets — make the geometry read as
  **one** (the `fp_combined_corner_plate` already shares the seat). Cross-ref the film-plane blueprint.
  (2026-08-17.)
- [x] **F3 — Relocate floor-leg foot anchors.** On `walkway-sheet6` View B the post is drawn welded
  **over** the 4 foot-plate anchor holes, so the screws can't be driven. Move the 4 anchors into the
  foot's outboard **outrigger** (X≈147–225, clear of the 50.8 post at X225–275 after the 2026-08-16
  foot-X0 derive fix), or otherwise clear the post footprint. Add a foot-anchor PCD constant.
- [x] **F4 — Resolve cantilever/bolt/grate clashes.** Two zones: (1) the **left lift-out** section —
  cantilever arm / bolt / grate overlap; (2) the **far** section — same class of clash. Trace each in
  the model, resolve (shorten/reposition arm, move bolt, or trim grate), verify clean with
  `check_interference.py --solids`. Likely coupled to F1/F2.

**Gate:** Phase 0 complete = `check_interference.py --solids` clean on the walkway zone + ALVIN
confirms "saved + uploaded" for every re-sent model. Only then start Phase 1.

## Phase 1 — Reconcile + parametrize (so every drawn dimension is a constant)

- [x] **Promote model-local structural constants → `tbs_constants.py`.** DONE (Phase 1.1, commit
  `a8dc8788`): the 26-constant `RWK_*` family moved out of `generate_sketchup_model.py` into the shared
  constants (models byte-identical → no re-send). Repointing `generate_walkway_diagram.py` surfaced +
  fixed real drift on **sheet 3** (right-walkway plan): beam section "40×40×3 SHS" → **2×1in** (50.8×25.4,
  tube long/end + solid flat-bar arm), deck **300 → 245** (F1), outer/end-beam layout now model-accurate;
  sheet 1 label reconciled.
- [x] **Add the un-parametrized blueprint dimensions as constants.** DONE + scoped (Phase 1.2, commit
  `c01542cd`):
  - **Promoted** (were duplicated in the model + diagram): reinforcing-plate blanks (`WALKWAY_REINF_W/H/T`
    100/180/6 std, `_W_WIDE/_H_WIDE` 120/220), gusset reach (`WALKWAY_GUSSET_REACH` 70), wall-bolt edge
    distances. **Standard** bracket = `WALKWAY_BRACKET_BOLT_DX` **27** (Sheet 2 View B; 23mm edge on the
    100mm plate); **widened** bracket = `WALKWAY_BRACKET_BOLT_DX_WIDE` **32** (Sheet 7 View B; 120mm plate).
    `_BOLT_Z_LO` 42 / `_LO_WIDE` 35. The 3D model had drifted to ±32 for BOTH — corrected in Phase 1.3 to
    ±27 standard (matches the drawings), re-sending walkway/overview/construction.
  - **Already done** (Phase 0): foot-anchor PCD (`LEFT_WK_CANT_FOOT_BOLT_DX/DY`).
  - **Out of scope — IBC-frame-owned:** the arm end-plate blank (65×190×8) is the **J6** joint (walkway
    arm → IBC upright), drawn on **IBC-frame Sheet 5**; the walkway blueprint cross-references it, does not
    re-dimension it. (Height already single-sourced as `RWK_J6_EP_H`.)
  - **Retired:** the "transition bearing plate (40×500×5)" no longer exists — the left edge beam + wall
    seats were replaced by the floor-leg cantilevers.
  - **Deferred to Phase D** (single-consumer detail dims → promote when their cut sheet is authored, per
    the "leave detail dims" rule): the **wall-cleat blank** and the **grate-clip pitch** (fix against the
    McNichols clip datasheet). Logged in TODO.
- [x] **Drift sweep** — DONE (Phase 1.3): stale literals in `walkway-report.md`, the two generators, and
  `component-dependency-map.md`; reconcile any residual "4734" RWK comments and pre-Phase-0 geometry.
  Also confirm the walkway-report's **J6** mention points to IBC-frame Sheet 5 (a mark must resolve to a
  labeled drawing).

## Phase A — Structural validation (`walkway_load.py`, analog of `ibc_frame_load.py`)

New driftproof compute script → optional rendered `walkway-load-case.png`. Each element: IBC/OSHA
design force → capacity → SF, authoritative voice, every capacity/coefficient cited.

- [x] **Grate span** — MS-S-100 molded FRP between bearers under 2.87 kPa uniform + 1.33 kN
  concentrated; deflection + bearing.
- [x] **Standard wall gusset bracket** — 8 mm plate arm (300 mm cantilever) bending/deflection at the
  arm tip; gusset.
- [x] **Widened wall gusset bracket** — 10 mm plate, 500 mm cantilever (governing wall bracket).
- [x] **Wall bolt group** — 3× (std) / 4× (widened) M12 in shear + **reinforcing-plate bearing /
  corrugated-wall pull-through** (ties to the parked 30 mm corrugation-depth procurement gate).
- [x] **Floor-leg cantilever** — worst = extended punch-out arm (X880 reach): the 2×1 was SF 1.04, so
  **redesigned to a 4×1 arm** (SF 1.99) + 2×2 post bending; **foot-anchor group** (4× #14×2 screws) shear
  + uplift into ply-over-steel (must engage the steel floor pan).
- [x] **Right cantilever rectangle** — long/end/cranked-beam bending + rectangle deflection **assuming
  the mid-span pickup** by the two IBC-post arms; half-lap notch net section at the crossings. The
  arm-root moment (≈0.35 kN·m vs ≈0.84 kN·m capacity per the
  [cantilever study](right-walkway-cantilever-study.md)) is the **IBC-frame** J6's check — cross-ref
  `ibc_frame_load.py`, do not re-validate here.
- [x] **Combined corner plate** — 10 mm plate carrying walkway beam + film rail; bolt group.

Deliverable: a computed validation table into `walkway-report.md` §9 (replacing the qualitative
hand-check prose). Fold the existing `right-walkway-cantilever-study.md` numbers into the script so
they can't drift.

## Phase B — Fastener + weld schedule

- [x] **Fastener schedule J1…Jn** (size/grade/torque/washer/locker, cited): std bracket wall bolt
  (M12×70 91280A732); widened bracket wall bolt (M12×70); right cleat / combined-corner bolt (M12×70
  91280A732); floor-leg foot screw (#14×2 410 SS self-driller); grating clips. (The center-arm end-plate
  bolt M12×100 + the half-lap hold-down screws that fix the two arms belong to the **IBC-frame** J6
  schedule — cross-ref, not scheduled here.)
- [x] **Weld schedule W1…Wn** (leg/symbol/extent): bracket gusset↔leg↔arm fillets; reinforcing-plate;
  rectangle long↔end beam corners; cranked-beam ramps; floor-leg post↔foot + post↔arm; wall-cleat welds;
  combined-corner-plate seats. Load-check the governing throats in `walkway_load.py`; the rest are AWS
  D1.1 minimum practical fillets (note which). (The half-lap seat + arm-end-plate welds are the
  **IBC-frame** J6/W schedule — cross-ref, not scheduled here.)
- [x] Tables into `walkway-report.md` (§ near the parts list); J/W callouts land on the sheets in Phase D.

## Phase C — Datum + tolerance scheme

- [x] **Datums:** A = floor plane (foot undersides / container floor); B = pinhole + film-plane wall
  faces (the two long walls the brackets bolt to); C = rail datum X260/X4649 (film-plane left/right).
- [x] **Functional tolerances:** deck level/coplanarity, bracket arm reach, wall-bolt PCDs, foot-anchor
  PCD, grate cut/slit/notch positions, corner-plate seat Z. General = ISO 13920 Class B; welds = AWS D1.1.
- [x] Report § + a **DATUMS & TOLERANCES** callout block on the plan sheet.

## Phase D — Fab-detail sheets (extend `generate_walkway_diagram.py`)

- [x] **J/W callouts** onto the existing detail sheets (bracket cross-section Sheet 2/7, floor-leg
  Sheet 6, transition Sheet 8, right cantilever Sheet 3).
- [x] **Member cut list** — computed from the constants (near/far bracket plates, right-rectangle long
  + end + cranked beams, floor-leg posts/arms, feet, reinforcing plates, cleats, corner plates,
  transition plates + a stock linear-feet summary). The two IBC-post arms are in the **IBC-frame** cut
  list, not here.
- [x] **Plate fabrication schedule (1:1)** — foot plate (with relocated anchors), std + widened
  reinforcing plates, combined corner plate, wall cleat, transition bearing plate — each with hole
  Ø/positions/PCD. (The J6 arm end/backing plates are on the **IBC-frame** plate schedule.)
- [x] **Grate cut-plan** — the 4 sections dimensioned with spray slits, drum-exit punch-out, near
  bump-out, muslin notches, and clip positions (a fabricator/nesting drawing).
- [x] **Consolidated weld map** — W1…Wn ticked to their frame locations + the schedule.
- [x] Register every new sheet: `all-diagrams.md` gallery, `publish.sh`, `setup_docs.py`,
  `dependencies.yml`; embed in the report.

## Phase E — Cascade + close (as changes land)

- [x] Firm any spec change into `parts.py` / `costing.py` / master-shopping-list / cost-breakdown (same
  commit); `parts.py --check` + `costing.py --check-registry`.
- [x] Regenerate + gallery-register new sheets; re-send models only if geometry detail changed (Phase 0
  already covers the geometry); `manifest.py --update`.
- [x] `lint.py` (+ `--verify-all` before publish) + `check_consistency.py` clean.
- [x] RELEASE `[Unreleased]` bullet; tick the TODO "Walkway blueprint pass" sub-items.

## Open decisions

1. **F1 shortening target** — the exact new right-walkway right edge (derive from the film-plane
   bottom-rail bracket X; confirm IBC reach-in access survives). Settle in Phase 0.
2. **Coating / surface-finish spec** — deferred to the fab/quoting stage (as with the IBC frame).
3. **Rendered load-case sheet** — build `walkway-load-case.png` in Phase D if wanted (optional, like
   `ibc-frame-load-case.png`); Phase A lands as the §9 table regardless.

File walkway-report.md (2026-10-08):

<!-- SPDX-License-Identifier: AGPL-3.0-only -->
<!-- © 2026 Alvin Richards -->
# Walkway System

## 1. Purpose

The perimeter walkway provides dry-foot operator access around all four sides of
the processing tray without wading through chemical solution. It serves four
access functions:

- **Near walkway** (pinhole wall side) — access to electrical panel, battery
  bank, spray-bar, tilt-swing adjusters, and valve manifold.
- **Far walkway** (film plane wall side) — access to film plane carriage clamps,
  rail end-stops, and far-side spray bar pole slot.
- **Left walkway** (cargo door end) — access to hinged light-trap panel latches
  and revolving drum. Removable for panel transport.
- **Right walkway** (IBC end) — access to IBC valves, filter skid, and pump
  manifold. Carried on a cantilever frame off the IBC frame to clear the IBC stack below.

All four sections share a common 140mm deck height (115mm bracket arm, L-angle, or
floor-leg arm + 25mm grating) and 300mm standard width, creating a level perimeter walking
surface. There are two sections that _punch out_ to allows easier access of the lightrap and around the battery stack.

The design enforces **zero processing tray contact** — all walkway supports are
either wall-mounted, carried on the cantilever frame off the IBC frame, or placed outside the tray footprint. This
prevents chemical contamination of walkway structures and avoids disrupting the
tray's watertight seal.

<!-- brochure:skip -->
**Interactive 3D model** — the four removable grated sections, the wall-cantilevered near/far brackets (with exterior reinforcing plates + M12 through-bolts), the right walkway on its cantilever frame (2×1×0.120in (50.8×25.4mm) frame with an open bay in the outer rail over the corridor, on 2 center arms off the IBC frame, with combined corner plates shared with the bottom film rail), the removable left lift-out grate on 5 floor-leg cantilever brackets (posts on bare floor outside the tray, arms cantilevering over it), and the processing tray, inside a ghost of the container. Drag to orbit, scroll to zoom.

<div class="sketchfab-embed-wrapper">
  <div style="position:relative;width:100%;padding-bottom:56.25%;">
    <iframe title="TBS-001 Walkway Model" frameborder="0" allowfullscreen mozallowfullscreen="true" webkitallowfullscreen="true" allow="autoplay; fullscreen; xr-spatial-tracking" execution-while-out-of-viewport execution-while-not-rendered web-share src="https://sketchfab.com/models/96b3d0e5fc8b4fc18c528f64bda028bc/embed" style="position:absolute;top:0;left:0;width:100%;height:100%;border:0;"></iframe>
  </div>
  <p style="font-size: 13px; font-weight: normal; margin: 5px; color: #4A4A4A;"><a href="https://sketchfab.com/3d-models/tbs-001-walkway-model-96b3d0e5fc8b4fc18c528f64bda028bc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" target="_blank" rel="nofollow" style="font-weight: bold; color: #1CAAD9;">TBS-001 Walkway Model</a> by <a href="https://sketchfab.com/alvin91403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" target="_blank" rel="nofollow" style="font-weight: bold; color: #1CAAD9;">alvin91403</a> on <a href="https://sketchfab.com?utm_medium=embed&utm_campaign=share-popup&utm_content=96b3d0e5fc8b4fc18c528f64bda028bc" target="_blank" rel="nofollow" style="font-weight: bold; color: #1CAAD9;">Sketchfab</a></p>
</div>
<!-- brochure:endskip -->

---

## 2. System Specifications

| Parameter | Value |
|---|---|
| Standard walkway width | 300mm |
| Deck height (floor to grate top) | 140mm (raised to clear the floor-level spray bar) |
| Grating | 1" (25mm) molded GRP (fiberglass), vinyl-ester, grit top — McNichols MS-S-100, the thinnest molded FRP made (15mm doesn't exist); corrosion-proof in the chemistry zone |
| Grating bearing bars | 15×3mm at 34.2mm pitch |
| Bracket arm height | 115mm above finished floor |
| Bracket spacing (near/far) | 457mm (18") — aligned to container rib spacing |
| Container rib spacing | 457mm (18") — ISO standard corrugation pitch |
| Near walkway widened section | <!-- BEGIN fact:walkway_near_wide_w_mm -->500<!-- END fact:walkway_near_wide_w_mm -->mm at X≈1,055–3,083mm (5 widened brackets) |
| Open processing area | <!-- BEGIN fact:spray_beam_span_mm -->4,289<!-- END fact:spray_beam_span_mm -->×1,762mm = 6.80 m² |
| Spray bar slit width | 30mm (near and far walkways) |
| Total walkway sections | 4 (all removable) |

The four removable sections are cut from two molded GRP stock panels per the cut plan below, nesting the pieces to minimize offcut from the 2× 36″×120″ sheets.

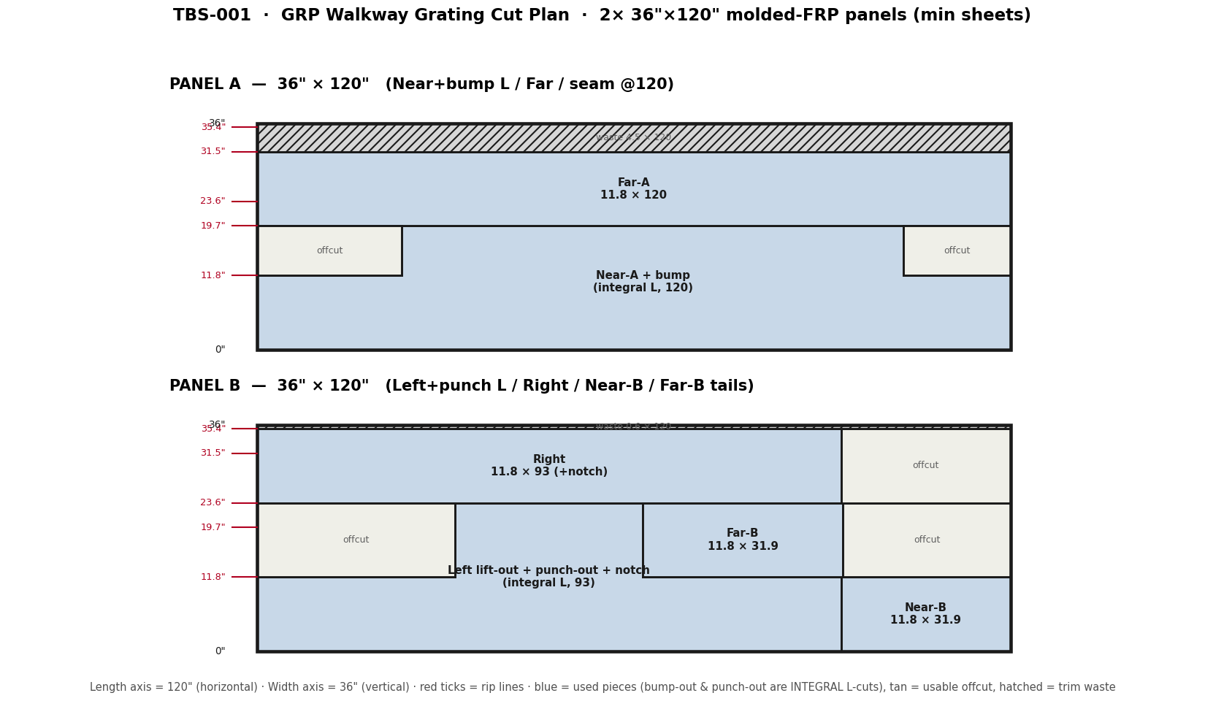
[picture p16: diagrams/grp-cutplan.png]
GRP grating cut plan — 2× 36×120 panels


---

## 3. Near and Far Walkways — Wall-Cantilevered

The near (pinhole wall) and far (film plane wall) walkways run
the full length of the processing tray zone, from the left walkway butt joint at
with the left and right walkways.

### 3.1 Cantilever Bracket Design

Each bracket is a welded assembly — an 8mm steel plate (vertical mounting leg + gusset) with a
**steel tube arm** welded on. The arm was redesigned to the US IBC/OSHA basis (§9): the original
8mm-plate arm yielded at ~25 lbf, so the arm is now a **2×1×0.120in tube** (standard) that carries
the 300 lbf tip load at SF 2.1.

| Component | Dimensions | Function |
|---|---|---|
| Vertical mounting plate | 8×200mm (height), flat against wall rib | Bolted to container corrugation rib interior face |
| Horizontal arm | **2×1×0.120in steel tube** (50.8×25.4), 300mm cantilever (**3×1** in the widened zone) | Supports grating; sized to IBC/OSHA (§9) |
| Triangular gusset | Right triangle, 70mm reach from wall | Braces the arm root; reach stops before tray rim |

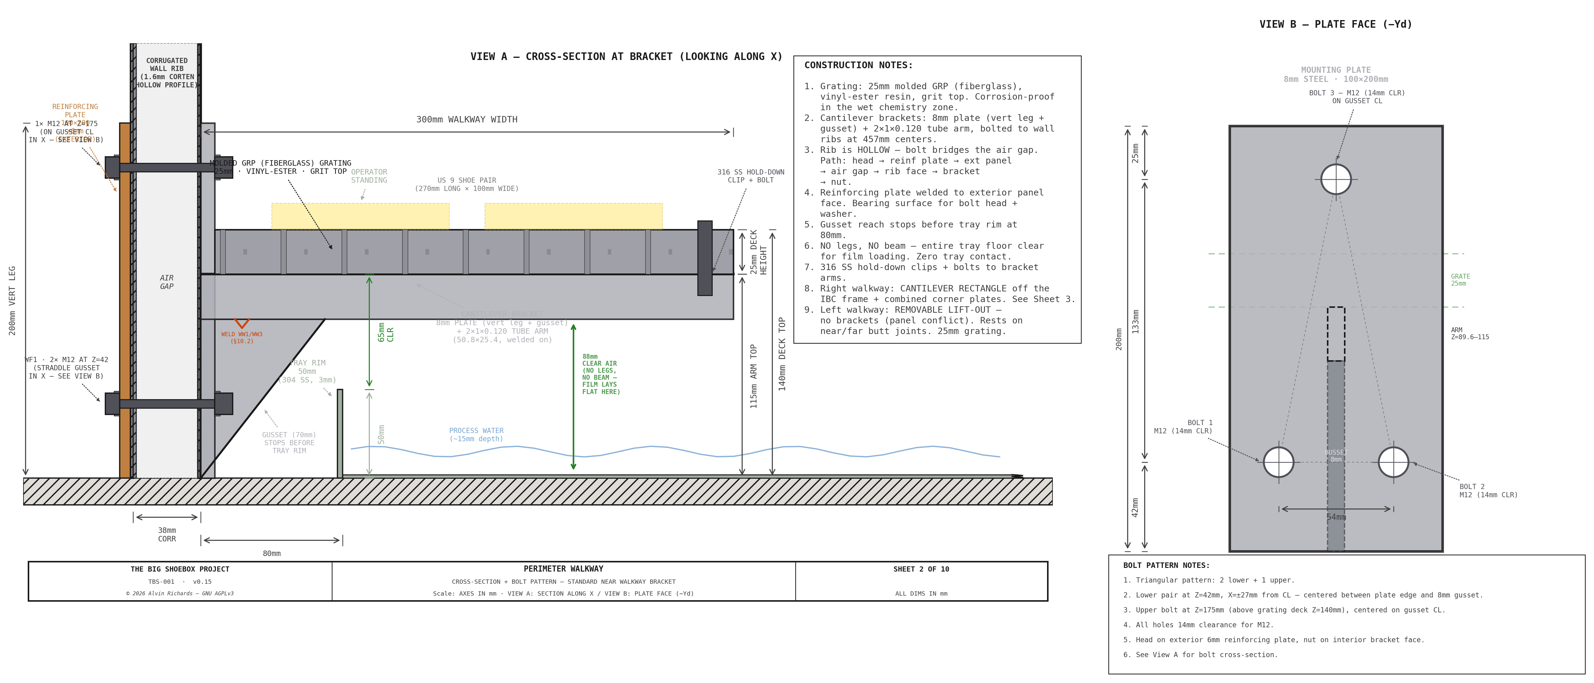
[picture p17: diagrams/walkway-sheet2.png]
TBS-001 Walkway — Sheet 2: Cross-Section with Bracket Detail


**Attachment:** 3× M12 through-bolts per bracket in a triangular pattern,
passing through the full wall assembly: hex head → reinforcing plate (6mm) →
exterior panel (1.6mm Corten) → air gap → rib interior face (1.6mm) →
bracket vertical plate (8mm) → nut. Two lower bolts straddle
the 8mm gusset plate at ±27mm from the plate centerline in X (centered
between plate edge and gusset). One upper bolt (just above the bracket
arm, near the top of the mounting plate) is centered on the gusset
centerline. The container
corrugation ribs are hollow — each bolt bridges the air gap inside the rib.
A 6mm reinforcing plate (100×200mm) is welded to the exterior panel face to
provide a bearing surface for the bolt heads and washers. See View B for the bolt pattern detail.

**Spacing:** Brackets mount at every container rib — 457mm (18") centers.

### 3.2 Near Walkway Widened Section

The near walkway widens from 300mm to 500mm, extending past the spray bar slit to the next rib position.
This widened section provides additional standing room in front of the
electrical panel, battery bank, and
through the spray bar slit zone. These wall-mounted equipment
items require front access for operation and maintenance, and the wider
platform gives the operator full-width standing room during spray bar passes.

Five brackets in this zone use a heavier design to support the 500mm cantilever arm. The
bracket positions align to container corrugation ribs.
Extending the widened zone past the slit ensures 500mm-arm brackets support
the grating on both sides of the slit, eliminating unsupported overhang.

**Sheet 9 — Detail F: Near-Walkway Bump-Out (pinhole wall, plan).** The 500mm-deep standing
band over X1,055–3,083, its 5 widened wall-cantilever brackets on the ribs, the 100mm deck
overhang past each end bracket, and the spray-bar pole slit at the pinhole (X2,454) — the
pinhole-side counterpart to the left drum-exit punch-out (Sheet 5).

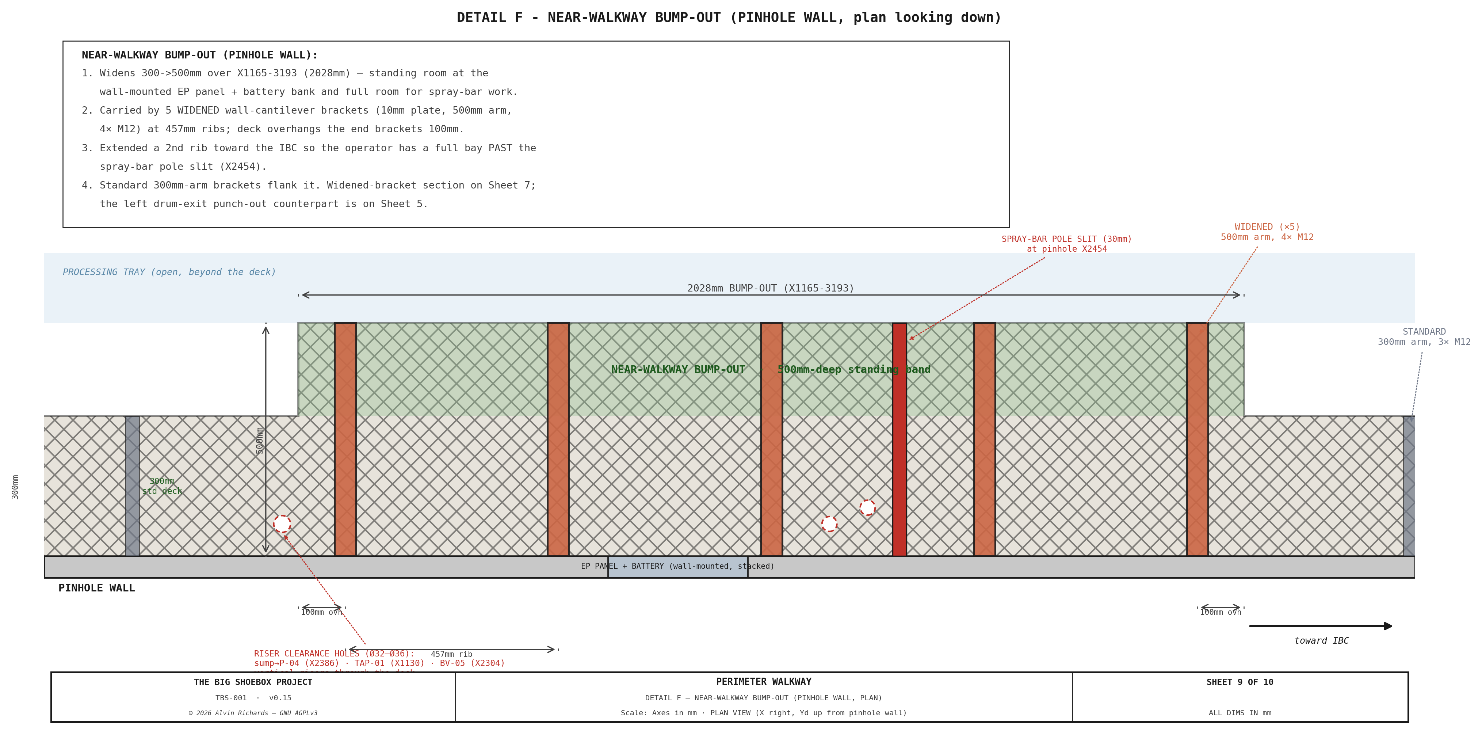
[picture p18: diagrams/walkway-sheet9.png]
TBS-001 Walkway — Sheet 9: Near-Walkway Bump-Out (Pinhole Wall)


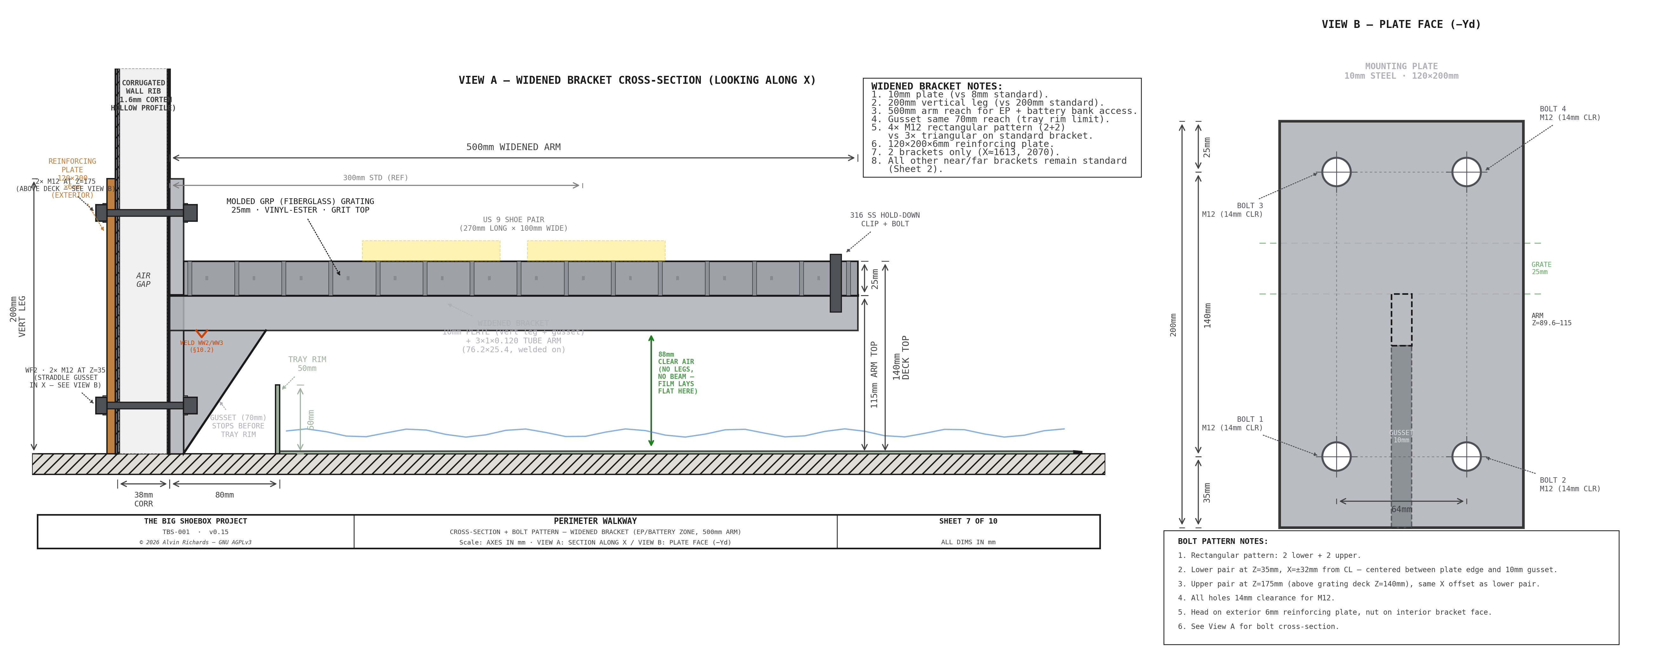
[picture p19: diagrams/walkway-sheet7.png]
TBS-001 Walkway — Sheet 2: Cross-Section with Bracket Detail


| Parameter | Standard bracket | Widened bracket |
|---|---|---|
| Plate thickness (leg + gusset) | 8mm | 10mm |
| Vertical leg height | 200mm | 200mm |
| Arm section | 2×1×0.120in tube (SF 2.1) | 3×1×0.120in tube (SF 1.83, defl-governed) |
| Arm reach | 300mm | 500mm |
| Gusset reach | 70mm | 70mm (tray rim constrained) |
| Bolt pattern | 3x M12 triangular (2+1) | 4x M12 rectangular (2+2) |
| Reinforcing plate | 100x200x6mm | 120x200x6mm |

The gusset reach remains 70mm on both bracket types — limited by the processing
tray rim. Both bracket types share the 200mm vertical leg (sized so the raised
upper wall-bolt clears the grate deck by 25mm); the widened bracket compensates
for its longer arm with heavier (10mm) plate, a wider blank for greater wall
engagement, and the additional bolt for higher moment capacity.

**Attachment:** 4× M12 through-bolts per bracket in a rectangular pattern,
passing through the full wall assembly: hex head → reinforcing plate (6mm) →
exterior panel (1.6mm Corten) → air gap → rib interior face (1.6mm) →
bracket vertical plate (10mm) → nut. Two lower bolts straddle
the 10mm gusset plate at ±32mm from the plate centerline in X (centered
between plate edge and gusset). Two upper bolts (30mm above the grating
deck) at the same ±32mm X offset. The
container corrugation ribs are hollow — each bolt bridges the air gap inside
the rib. A 6mm reinforcing plate (120×200mm) is welded to the exterior panel
face to provide a bearing surface for the bolt heads and washers. See Sheet 7,
View B for the bolt pattern detail.

**Width transition:** At the two transition brackets,
the grating changes from 300mm to 500mm width (or vice versa). Both the
narrow and wide grating sections rest on the same 500mm bracket arm. A
40×500×5mm flat bearing plate is welded to the bracket arm top surface at each
transition, providing a wider landing surface so both grating sections have
adequate bearing. The narrow section occupies the inner 300mm of the plate;
the wide section occupies the full 500mm. Stainless hold-down clips retain each grating
section independently on either side of the transition.

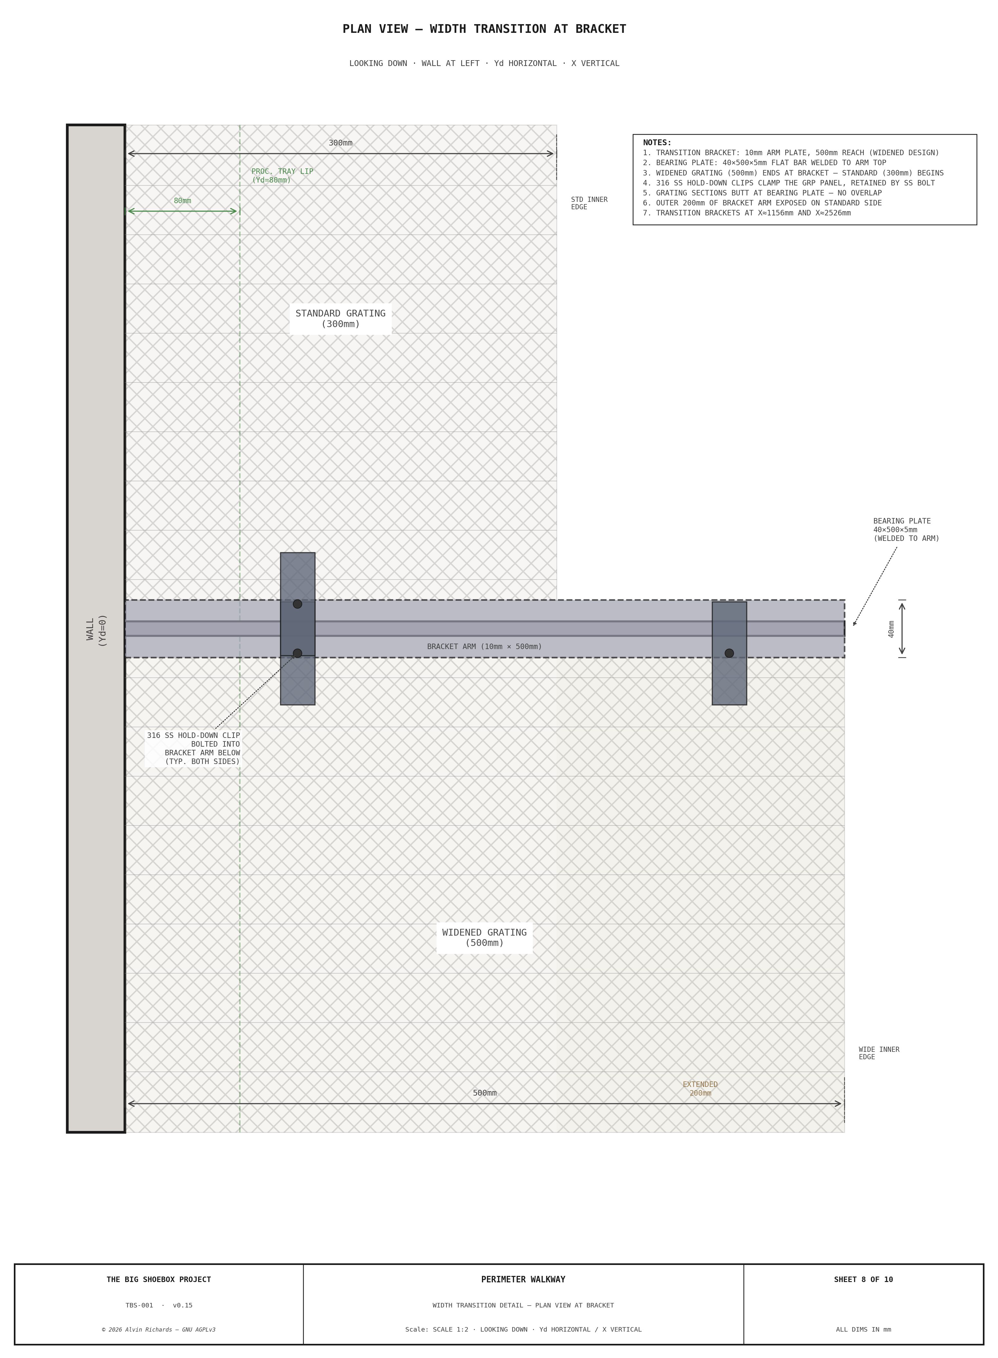
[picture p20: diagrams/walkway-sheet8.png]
TBS-001 Walkway — Sheet 8: Width Transition Detail


### 3.3 Spray Bar Slit

A 30mm wide slot is cut through both near and far walkway grating at the beam
center X position, providing clearance for the spray bar telescoping pole to
pass through the walkway during processing operations.

On both walkways, the slit extends from the inner walkway edge inward only to
the processing tray lip — not the full walkway depth. The remaining grating
between the tray lip and the wall stays solid, maintaining structural
continuity across the slit.

| Walkway | Inner edge (Yd) | Tray lip (Yd) | Slit depth | Solid remaining |
|---|---|---|---|---|
| Near (widened) | 500mm | 80mm | 420mm | 80mm |
| Far (standard) | 2,062mm | 2,280mm | 218mm | 82mm |

See [Processing Tray & Spray Bar](processing-tray-and-spray-bar.md) for pole
assembly details.

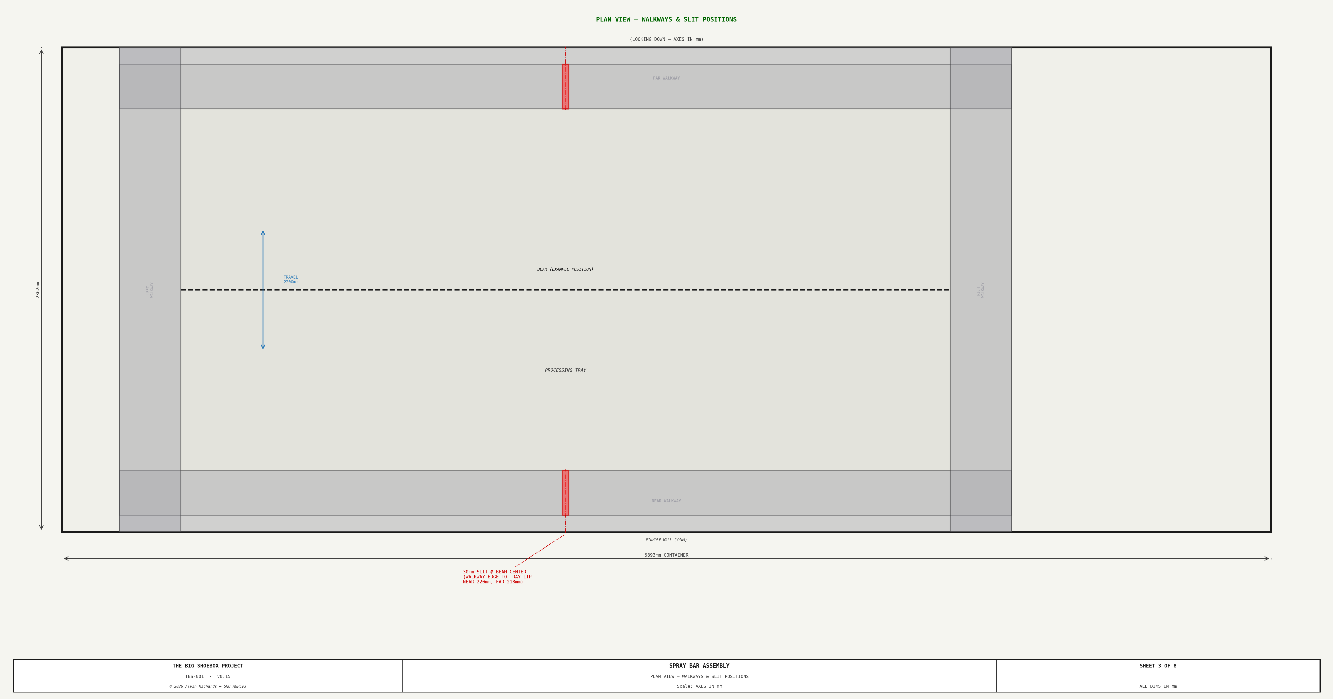
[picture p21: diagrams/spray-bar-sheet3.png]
TBS-001 Walkway —Positions of walkway slits


---

## 4. Right Walkway — Cantilever Rectangle

The right walkway at the IBC end cannot use wall-cantilevered
brackets because the IBC stack occupies the floor below.

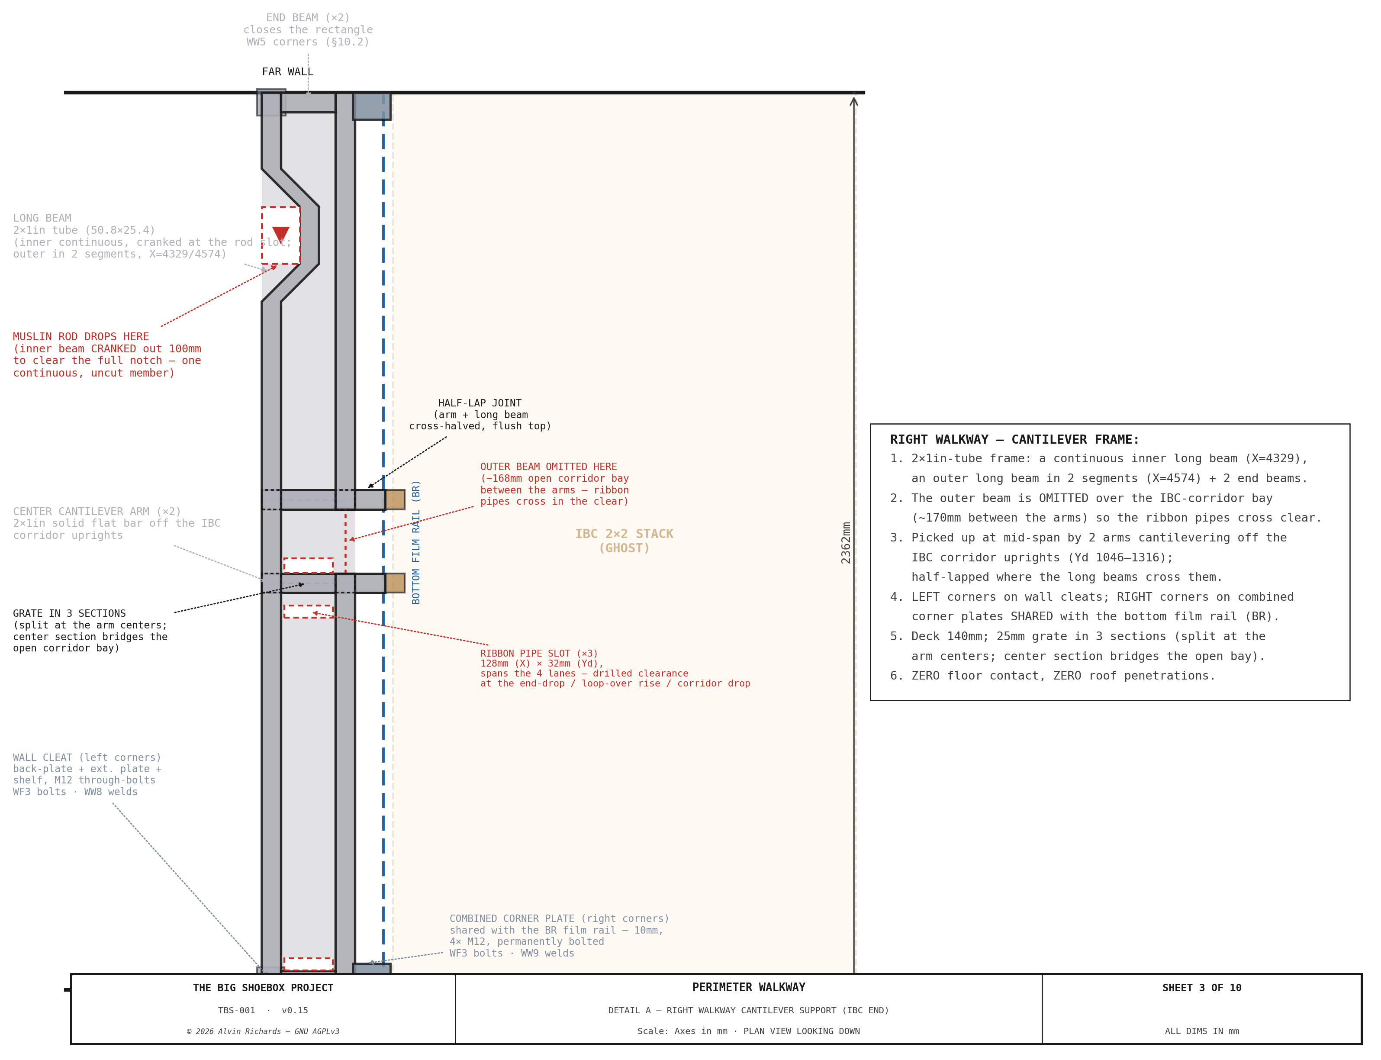
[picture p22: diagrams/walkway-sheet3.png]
TBS-001 Walkway — Sheet 3: Cantilever Support


### 4.1 The Cantilever Rectangle

A closed rectangular frame of **2×1×0.120in (50.8×25.4mm) steel tube** sits directly under the deck,
its 1in dimension the depth so the full-width 1½in spray beam — which rides the Yd-sloped tray floor —
clears the soffit (Z89.6) by **11.6mm** at every travel position. A shallow section is less stiff on its
own, so the rectangle is **picked up at mid-span by two center cantilever arms** (§4.2); with them the
deflection stays well under 1mm. (2×⅞ would clear by 15mm but isn't a stock size — MetalsDepot and Metal
Supermarkets carry only **2×1**; being *deeper* it gives **stronger** arms, SF≈2.5, at the cost of 3.4mm
clearance, which keeps the deck height unchanged.) The frame:

- **Two long beams** run the container width, with the 245mm grating spanning between them
  (the right deck is shortened to land on the shared combined corner plate). The **inner** beam
  is continuous; the **outer** beam is run in **two simply‑supported segments** (combined corner
  plate → cantilever arm) with an **open bay over the IBC corridor** (see below).
- **Two short end beams** (≈245mm) close the near and far ends, joining the beams into a
  torsionally stiff frame (no free bearer ends to droop).

**Open corridor bay in the outer beam.** The four under‑walkway ribbon pipes cross the outer
beam line to enter the IBC corridor. Rather than notch the outer beam — an open‑top notch would
gut the 2×1 section to a ~2.4mm web, a near‑hinge in a primary bending member — the outer beam
is **omitted over the ~170mm open bay between the two cantilever arms** (Yd ≈ 1,097–1,266, the IBC‑corridor crossing),
so the pipes cross in the clear. Each outer segment is then a short simply‑supported span (wall
combined plate at one end, cantilever‑arm half‑lap at the other), and the only continuous member
across the corridor is the inner beam. The grating is **split at the two cantilever‑arm centers**
(Yd ≈ 1,071 / 1,291) into near, center, and far sections; the **center section bridges the open
bay**, its ends landing on the two arms. That short center span carries a little flex, accepted
over the low‑traffic corridor.

**Cranked inner beam at the muslin-rod slot.** The muslin-drop notch on the right walkway
(Yd 1,912–2,062) sits at the tray-facing edge, directly over the **inner** long beam — and the
rigid batten on the muslin's bottom edge has to drop straight down through it into the tray. Rather
than cut the beam (which would sever a continuous member at mid-span of its ~1.1m end bay), the inner
beam is **cranked outboard 100mm** — the full notch depth — over the notch, with ~100mm angled ramps
each side. Over Yd 1,912–2,062 it runs at X4,429 instead of X4,329, vacating the entire notch footprint
so the rod passes clear, while the beam stays **one continuous, uncut member** — bending and tension
continuity fully preserved. The grating loses no support (the notch already voids the deck there; the
outboard strip still bears on the cranked beam and the outer beam). The left-walkway notch needs no
such treatment — it falls between floor-leg brackets, with no beam beneath it. See **Sheet 3 (Detail A)**.

### 4.2 Center Cantilever Arms

Two **2×1×0.120in arms** cantilever inward off the **IBC corridor uprights**
and pick the rectangle up at
mid-span. Each arm is **half-lapped (cross-halved)** where the long beams cross
it, so the beams seat down into the arm and the two members share a flush top
face. The arms carry the central span that the corner supports alone would leave
to sag. With the section shaved to 2×1×0.120in for spray-beam clearance, an **added
mid-span support** keeps the deflection in check (the ~0.35 kN·m peak moment at
the arm root still passes with margin — see the [cantilever study](right-walkway-cantilever-study.md)).

### 4.3 Corner Supports

| Corner | Support | Fixing |
|---|---|---|
| Left, near + far | **Wall cleat** — 8mm steel back-plate + exterior reinforcing plate + a shelf the long beam lands on | M12 through-bolts (sandwich the wall, sealed) |
| Right, near + far | **Combined corner plate** — a single 10mm plate that carries BOTH the walkway right beam AND the bottom film rail (BR/TR) | 4× M12, permanently bolted (interior + exterior plate sandwich the wall) |

The **combined corner plate** is the key coupling: the walkway's right long beam
and the film plane's bottom (and top) rail terminate at the same position, so a
single plate seats both — the walkway beam on a 70mm seat, the film
rail on a 150mm seat.

### 4.4 Design Rationale

The cantilever rectangle achieves three goals:

1. **Zero floor contact** — clears the IBC stack entirely; no legs on the floor in
   the IBC zone.
2. **Zero tray contact** — the rectangle floats above the processing tray.
3. **Consolidated film-rail anchor** — the combined corner plate does double duty,
   removing a separate BR saddle.

The pipe-routing space under this walkway — past the IBC frame feet, the tray rims,
and the cantilever arms — is detailed in the [Walkway Routing Sections](walkway-routing-sections.md).

---

## 5. Left Walkway — Removable Lift-Out

The left walkway at the cargo door end cannot use wall-cantilevered
brackets because the hinged light-trap panel occupies the end wall and swings ~56°
about the pivot for transport (its sweep passes over this zone). Its **inner edge
sits over the processing tray**, so it cannot be supported from below
either. The left walkway is therefore a removable lift-out grate carried by **5
floor-leg cantilever brackets** — each a post standing on the bare floor *outside*
the tray with an arm that cantilevers over the tray to the grate inner
edge. The +50mm deck raise lifts these arms clear of the floor-level spray bar.

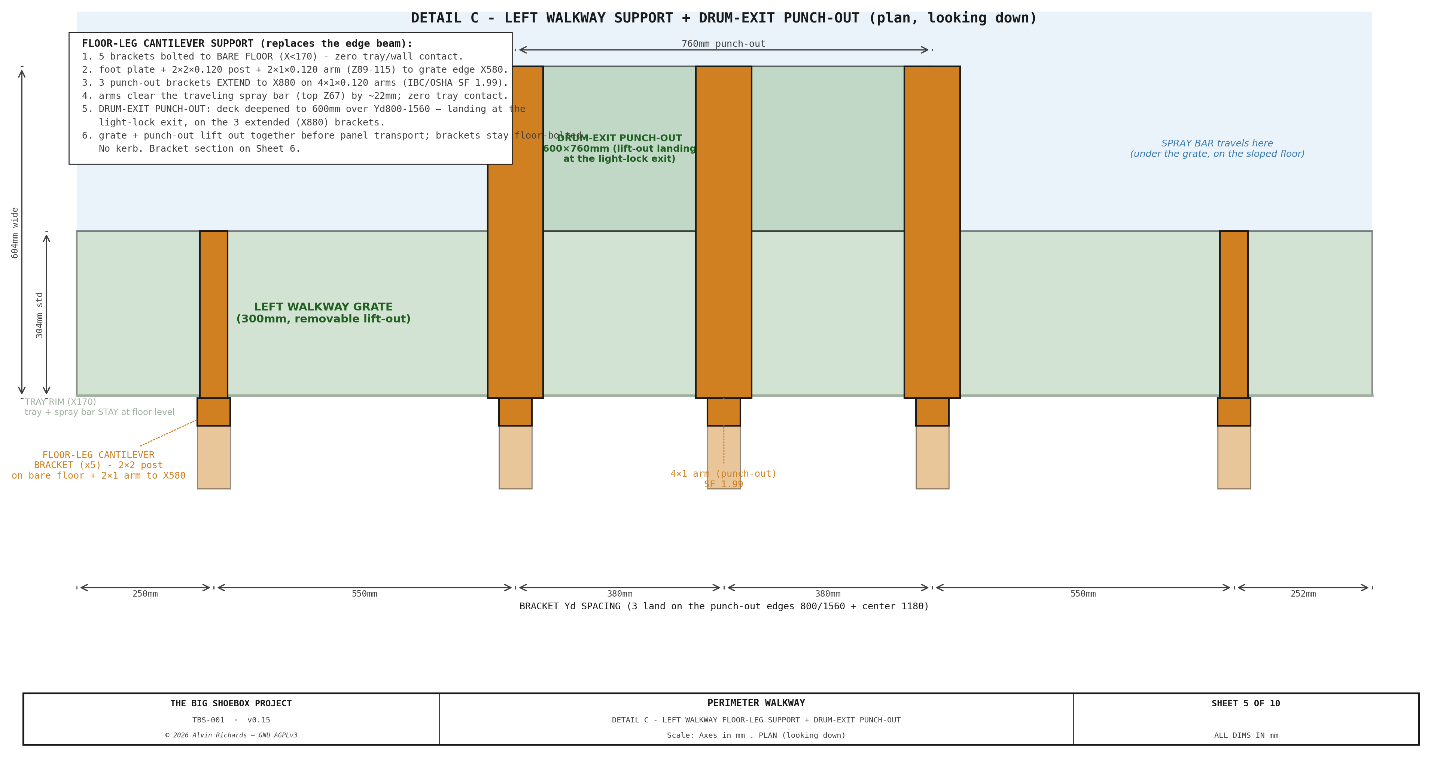
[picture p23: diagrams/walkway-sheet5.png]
TBS-001 Walkway — Sheet 4: Lift-Out at Butt Joint


### 5.1 Support System

| Component | Specification | Position |
|---|---|---|
| Floor-leg cantilever bracket (×5) | 2×2×0.120in steel SHS post (~115mm, floor to grate bottom) + arm (2×1×0.120in standard / **4×1×0.120in** on the 3 punch-out legs, §9) + 165×60×8mm foot plate (inboard outrigger — the post sits on its outboard end, the plate reaches inboard so the 4 floor anchors clear the post footprint) | 5 brackets (outside the tray) |
| Floor screws | 4× #14×2″ 410 SS self-drilling structural screws per foot plate (20 total) | Bite the plywood-over-steel container floor — wedge/concrete anchors don't hold there |
| Standard arm reach | Arm reaches the grate inner edge | 2 brackets |
| Extended arm reach | Arm extends under the drum-exit punch-out | 3 brackets |

The grate rests on the cantilever arms and lifts straight out — no fasteners, no
kerb. The operator load travels grating → cantilever arm (2×1; 4×1 at the punch-out) → 2×2×0.120in post →
foot plate → floor anchor, with **zero tray contact**: the posts stand on bare
floor outside the tray and the arms cantilever over it. The arm bottom clears the floor-level spray bar
by 15mm and the tray rim
by 25mm. Because the brackets
stand entirely outside the panel's transport-swing footprint, the grate simply
lifts out before the panel swings; the floor-bolted posts stay put.

**Load path.** The operator load travels grate → cantilever arm → 2×2×0.120in post → foot plate → floor
anchors. The longest cantilever is the drum-exit punch-out arm (605mm). Under the US IBC/OSHA 300 lbf tip
load this needs a **4×1×0.120in tube** (SF 1.99) — a plain 2×1 was only SF 1.04 — while the standard
305mm arms stay 2×1 (SF 2.06); the post carries SF 2.68 (all computed in §9, `walkway_load.py`). The foot
plate's 4× #14 anchors react the ~2.4 kN/screw overturning uplift and **must engage the container's steel
floor pan**, not the plywood alone. This floor-leg cantilever supersedes the earlier full-width edge-beam
scheme — simpler, lighter, and needs no through-wall seats.

### 5.2 Drum-Exit Punch-Out

The operator steps out of the revolving-door light lock at its interior face, but the standard 300mm walkway
ends — leaving only ~20mm of
landing in front of the drum opening, with the processing-tray basin immediately
beyond. The left walkway is therefore **deepened to 600mm over the
drum-opening span** — a ~600 × 760mm landing centered on the exit
(the same approach as the near-walkway widened section on the pinhole side).

**Optical clearance.** The punch-out is inside the active image
zone (X≥150mm) — so it was checked against the optical cone. At the drum-exit depth
the cone's left boundary, so the punch-out is entirely **left of the cone**:
every pinhole sight line through it lands ~113mm clear
of the image edge. Confirmed by `generate_line_of_sight.py` (no equipment intersects
the cone).

**Support.** The 600mm punch-out is carried by the **3 middle
floor-leg brackets** — the same posts that carry the
standard left walkway, but with their arms **extended to X=880mm** on the heavier
**4×1×0.120in tube** section (IBC/OSHA — see §9).
Each arm cantilevers ~605mm over the tray from its
post on bare floor, with **zero tray contact**, and lifts out with the rest
of the left walkway for transport. No separate sub-frame, edge beam, or bearing
strip is needed.

The drum-exit punch-out and its support are shown on **Sheet 5 (Detail C)** — the deeper
landing on the 3 middle floor-leg brackets with 4×1 arms extended to X880, cantilevering over
the tray with zero tray contact — alongside the rest of the left-walkway floor-leg system.
See also **Sheet 6 (Detail D)** for the floor-leg bracket itself.

### 5.3 Floor-Leg Cantilever Bracket Detail

Each of the 5 brackets is a post standing on the bare floor outside the tray, with
an arm cantilevering over the tray to carry the grate. No wall seats and no tray
contact.

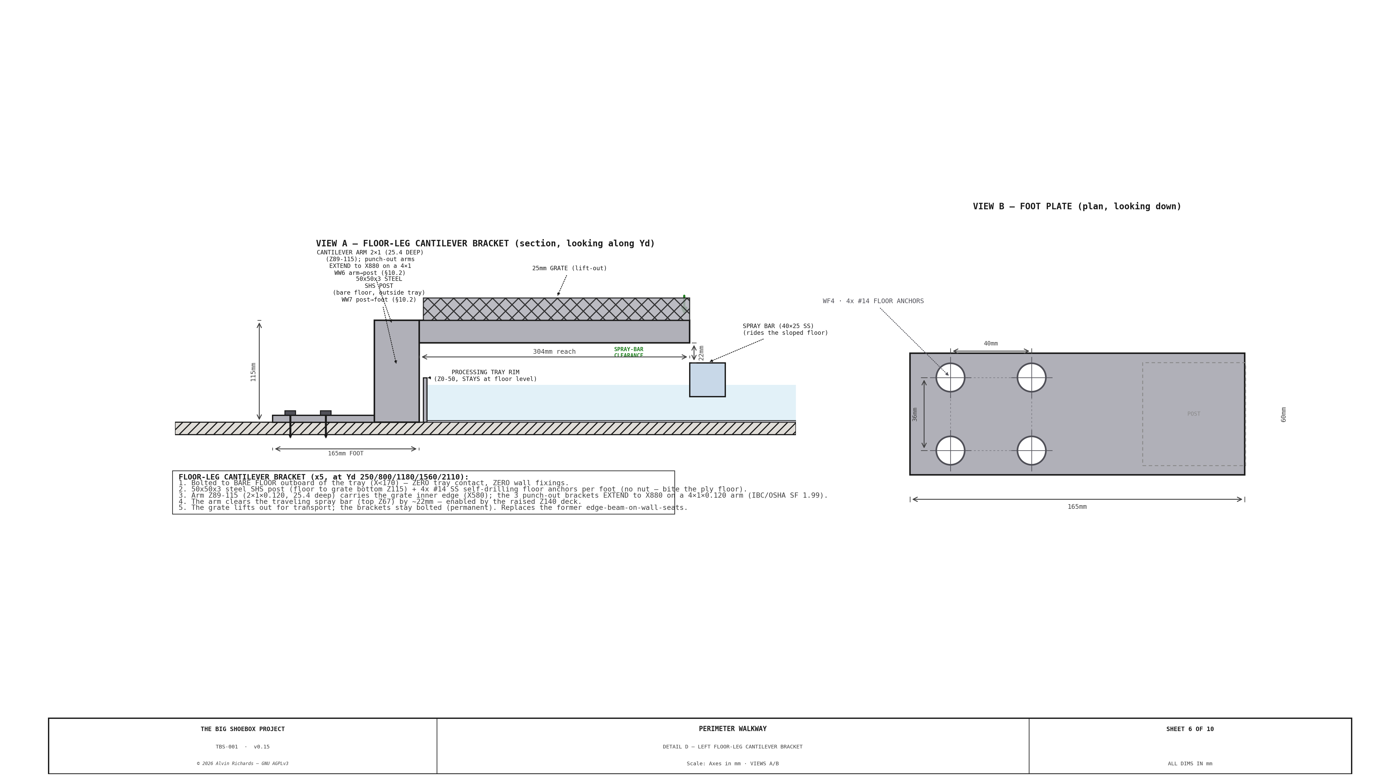
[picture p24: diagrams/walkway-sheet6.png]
TBS-001 Walkway — Sheet 6: Floor-Leg Cantilever Bracket Detail


| Component | Specification |
|---|---|
| Post | 2×2×0.120in steel SHS, ~115mm tall (floor to grate bottom), on bare floor at X=140mm |
| Foot plate | 165×60×8mm steel plate (inboard outrigger — F3), with **4× #14×2″ 410 SS self-drilling screws** into the plywood-over-steel container floor |
| Arm | 2×1×0.120in (50.8×25.4mm) steel reaching X=580mm (2 standard brackets, SF 2.06); **4×1×0.120in** extended to X=880mm (3 punch-out brackets, SF 1.99 — IBC/OSHA, §9) |
| Overturning reaction | reacted by the 4× #14 foot-plate anchors (~2.4 kN/screw uplift → engage the steel floor pan); 300 lbf tip point load governs (§9) |

The grate simply rests on the cantilever arms — located laterally by butting the
near/far grate edges, free to lift straight out (no fasteners, no kerb).
**Demountable for transport:** the grate lifts out before the panel swings; the
floor-bolted posts stay in place. No through-wall hardware at all.

### 5.4 Panel Transport Clearance

| Parameter | Value |
|---|---|
| Panel transport motion | SWING ~56° about the Ø89 pivot |
| Swing sweep reach (near-walkway zone) | X≈1,395mm |
| Butt joint / near-far walkway start | X=470mm |
| Panel / cage bottom edge | Z=130mm (panel floor gap; 10mm below the Z140 grate top) |

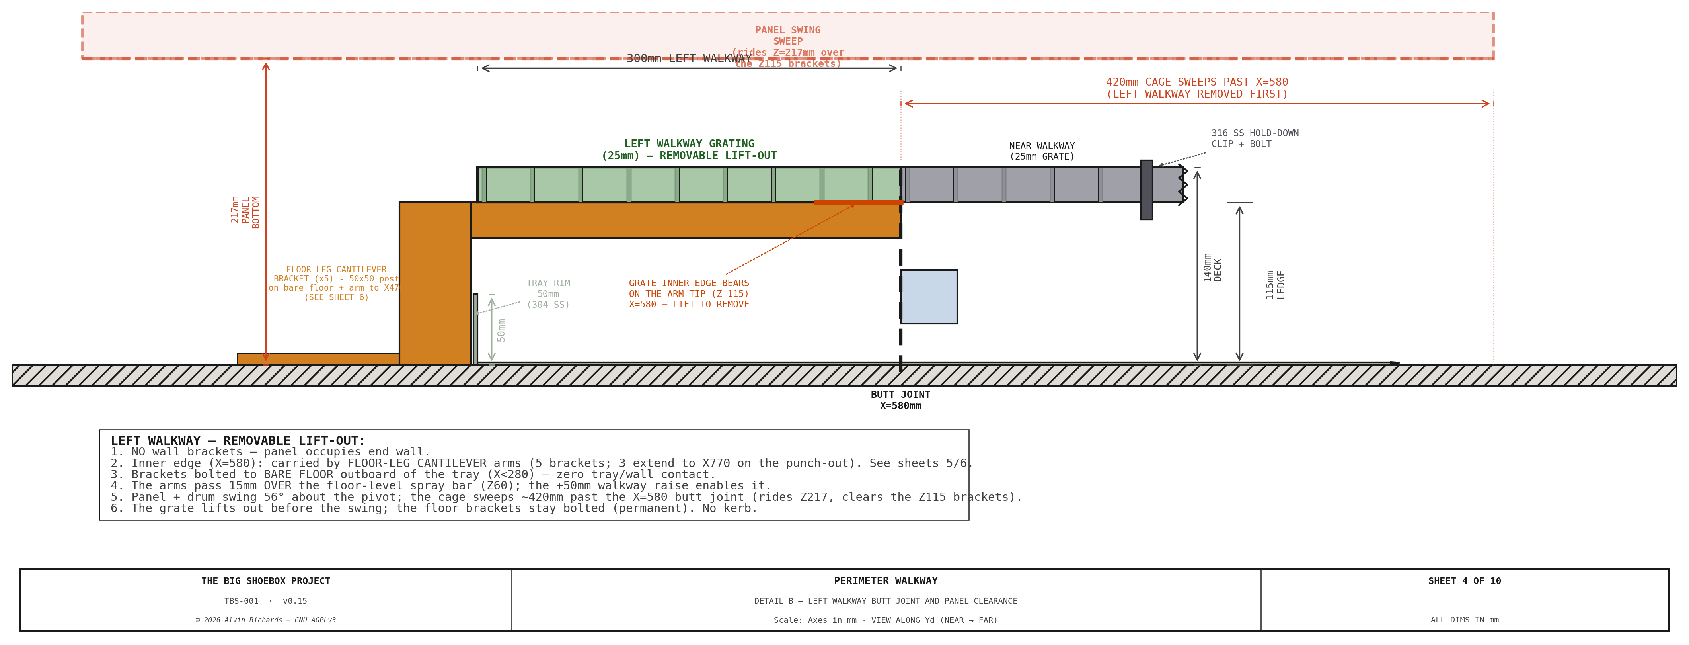
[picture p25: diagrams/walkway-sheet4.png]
TBS-001 Walkway — Sheet 4: Lift-Out at Butt Joint


The left walkway grate — together with the door-end near-deck lift-out
section — must be lifted out before the panel can swing (the 5 floor-leg posts stay
bolted to the floor). As the panel + drum swing ~56° about the pivot, the cage sweeps past
the butt joint into the vacated zone, its **cage underside (Z130) passing over the
Z115 door-end floor-leg posts** — so no floor-leg post is struck (the swing clears).
The relevant standing clearance is vertical: the drum-cage underside sits at Z130 —
25mm over the Z115 posts and 70mm over the Z70 tray rim (the panel bottom rides higher
still, at the 217mm floor gap). See hinged-panel Sheet 16.

---

## 6. Corner Joints

All four corners use butt joints (not miter joints). The near and far walkway
grating sections terminate at the butt joint lines, and the left and right
walkway grating sections rest on or abut the near/far bracket arms at these
intersections.

| Corner | Butt joint X | Design |
|---|---|---|
| Near-left / Far-left | X=470mm | Left walkway grate rests on the floor-leg cantilever arms; butts the near/far grate |
| Near-right / Far-right | X=4,629mm | Right walkway grating abuts near/far grating |

Butt joints are used rather than miters for two reasons:

1. **Panel clearance** — near/far walkways start at X=470mm, clear of the door-end
   panel swing sweep, so only the left walkway + the door-end near-deck section need
   removal for transport mode.
2. **Simplicity** — each grating section lifts off independently without
   affecting adjacent sections.

---

## 7. Evaporative Cooler Transport Stowage

During transport, the evaporative cooler (~20kg dry) is stowed on the
near walkway grating — in the widened section, so it clears the panel swing sweep. The cooler sits on a
12mm plywood base plate that distributes
load across the grating and prevents the housing from catching in grate openings.
Two 25mm ratchet straps loop over the cooler and hook to near walkway cantilever
bracket arms.

The 350mm cooler depth slightly exceeds the 300mm walkway width — the cooler
overhangs 50mm into the processing tray zone. This is acceptable because the
tray is drained and empty during transport.

---

## 8. Grating Specification

All four walkway sections use the same grating:

| Parameter | Value |
|---|---|
| Type | Molded GRP (fiberglass) grating |
| Thickness | 1" (25mm) — McNichols MS-S-100 (thinnest molded FRP); deck raised to 140mm to suit |
| Resin | Vinyl-ester (resists both alkaline developer and acidic fixer splash) |
| Mesh | ~38×38mm square, molded |
| Open area | ~40% |
| Surface finish | Grit top (slip-resistant) |

The four sections' overall sizes, cut features (spray-bar slits, drum-exit punch-out, near bump-out,
muslin notches), GRP panel seams (each 4,049mm near/far run splices at the 3,048mm panel length), and
hold-down-clip positions (WF5, 610mm centers + corners) are dimensioned on the **Sheet 10 grate cut-plan**
— a nesting/fabricator drawing:

TBS-001 Walkway — Sheet 10: Grate Cut-Plan (GRP Nesting)

### 8.1 Grating Retention by Walkway Section

| Walkway | Retention Method | Attachment Point | Removal |
|---|---|---|---|
| Near (pinhole wall) | 316 SS hold-down clips | Bracket arm top surface | Release clips, lift grating |
| Far (film plane wall) | 316 SS hold-down clips | Bracket arm top surface | Release clips, lift grating |
| Right (IBC end) | 316 SS hold-down clips | L-angle bearer horizontal leg | Release clips, lift grating |
| Left (cargo door) | Gravity (floor-leg arms) | Floor-leg cantilever arms | Lift straight up — no fasteners |

**Near and far walkways** use 316 SS hold-down clips that clamp the GRP panel
down onto the bracket arm (a stainless clamp clip — not a TEK screw driven into a
steel bearing bar, since FRP isn't screwed through). Clips are spaced at every other bracket
(~914mm centers).

**Right walkway** uses the same stainless hold-down clips, but they clamp to
the horizontal leg of the 1×1×3/16in (25.4×25.4×4.8mm) steel L-angle bearers rather than the bracket
arms.

**Left walkway** uses gravity retention only. The grate rests on the 5 floor-leg
cantilever arms (Yd 250/800/1180/1560/2110) and is located laterally by butting the
near/far grate edges. No fasteners are used because the left walkway must be removed
quickly for hinged panel transport mode — lift straight up and carry out; the
floor-bolted posts stay put.

---
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

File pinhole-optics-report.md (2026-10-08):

<!-- SPDX-License-Identifier: AGPL-3.0-only -->
<!-- © 2026 Alvin Richards -->
# Optics: Technical Reference
### From 8×10 Inches to 40×7 Feet

**Prepared for:** The Big Shoebox Project (TBS-001)
**Date:** April 2026
**Status:** Technical Reference

---

## How to Read This Document

This report is structured in two layers. Each section opens with a plain-language explanation, followed by the underlying mathematics and citations. Skip or read the math sections based on your need. Every formula used in the calculation tables traces to a cited source.

---

## Part 1: The Physics of Pinhole Photography

### How a Pinhole Forms an Image

A pinhole camera works on a simple optical principle: light travels in straight lines. When light from a scene passes through a very small hole in an opaque wall, each point in the scene sends a narrow cone of light through the hole, projecting a small circle of light onto the opposite wall. Because each point in the scene projects to a different location on the wall, an image forms — inverted and reversed, but geometrically faithful.

There is no lens. The pinhole does not bend or focus light. The image forms purely by geometry.

**Plain language:** Think of light as millions of tiny flashlights, each aimed in a different direction from every point in the scene. The pinhole lets through only the one beam from each flashlight that travels directly through the hole. The wall behind collects those beams into a picture.

**Source:** Young, M., "Pinhole Optics," *Applied Optics*, Vol. 10, No. 12, 1971, pp. 2763–2767. DOI: [10.1364/AO.10.002763](https://doi.org/10.1364/AO.10.002763)
Young describes the pinhole as "a useful and practical device which offers freedom from distortion and virtually infinite depth of field."

---

## Part 2: The Competing Forces That Determine Sharpness

There are two physical effects working against each other. Understanding them leads directly to the design equations.

### Effect 1: Geometric Blur (Too Large a Hole)

If the pinhole is very large, each point in the scene projects a circle of light roughly the same diameter as the hole itself. The image becomes blurry because multiple points in the scene overlap. Making the hole smaller tightens this circle and sharpens the image.

**The geometric blur disk diameter ≈ d** (the pinhole diameter)

### Effect 2: Diffraction (Too Small a Hole)

Light is not only a particle — it is also a wave. When a wave passes through a very small opening, it bends and spreads (this is called diffraction). The smaller the hole, the more the light spreads. Below a certain size, making the pinhole smaller actually makes the image *blurrier*, not sharper.

The spread due to diffraction is described by the Airy disk:

```
B_diffraction = 2.44 × λ × f / d
```

Where:
- `λ` = wavelength of light (0.00055mm for green light at 550 nm)
- `f` = focal length (distance from pinhole to image plane, mm)
- `d` = pinhole diameter (mm)

**Plain language:** Light waves bend around the edges of the hole. Very small holes cause the most bending. There's a sweet spot where the two blurs are balanced.

**Source:** Born, M. & Wolf, E., *Principles of Optics*, 7th edition, Cambridge University Press, 1999, §8.6. This textbook is the most authoritative modern treatment of diffraction and aperture theory.

---

## Part 3: The Optimal Pinhole Diameter Formulas

### The Lord Rayleigh Formula (1891)

Lord Rayleigh (John William Strutt, 3rd Baron Rayleigh) used Fresnel zone analysis — a mathematical method for counting how many concentric waves of light fit inside the aperture — to derive the optimal pinhole size. His criterion: a pinhole containing approximately 1.8 Fresnel half-zones yields the best balance between geometric and diffraction blur.

**Rayleigh Formula:**
```
d = 1.9 × √(f × λ)
```

**Source:** Lord Rayleigh (J.W. Strutt), "On Pin-hole Photography," *Philosophical Magazine*, Series 5, Vol. 31, 1891, pp. 87–99. [Taylor & Francis — Philosophical Magazine, Ser. 5](https://www.tandfonline.com/loi/tphm18).
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

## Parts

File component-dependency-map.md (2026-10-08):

<!-- SPDX-License-Identifier: AGPL-3.0-only -->
<!-- © 2026 Alvin Richards -->
# Component Dependency Map

> **Machine source of truth: `dependencies.yml`.** The structured
> `script → output-file` graph (which generator/model writes which PNG / `.skp` / `.rb`) lives there
> — validated by `lint.py` so it can't drift — and the per-constant cascade is **computed** from it
> (`python3 src/generators/lint.py --cascade <CONSTANT>`; enforced at commit time). This document is
> now the **human design rationale** that the YAML can't hold: §1 the component → constant registry,
> §2 the script legend, §3 the subsystem × diagram matrix, and §3.1 the per-model "what it builds and
> why" narrative. The old hand-maintained §4 cascade table was retired into the computed view above.

This document is the design-rationale companion for maintaining consistency across all TBS-001
engineering diagrams. When any component changes — position, dimension, or specification — consult:

1. **Section 1** to find the controlling constant in `tbs_constants.py`
2. **Section 2 / 3** for the subsystem ↔ diagram context
3. **`lint.py --cascade <CONSTANT>`** for the exact scripts to re-run and outputs to regenerate

All shared constants live in `tbs_constants.py`. Change a value there once; re-run the affected
scripts (the cascade command lists them); all diagrams update consistently.

---

## 1. Component Registry

Each subsystem lists its key physical parameters and the `tbs_constants.py` variable(s) that
control it. Scripts should import from `tbs_constants` rather than hardcoding these values.

### 1.1 Container Structure

| Parameter | Value | Constant |
|---|---|---|
| Interior length (long axis X) | <!-- BEGIN cdm:C_LEN -->5,893<!-- END cdm:C_LEN -->mm | `C_LEN` |
| Interior width (optical depth Y) | <!-- BEGIN cdm:C_WID -->2,362<!-- END cdm:C_WID -->mm | `C_WID` |
| Interior height Z | <!-- BEGIN cdm:C_HGT -->2,388<!-- END cdm:C_HGT -->mm | `C_HGT` |

*Components: corrugated steel long walls, short end walls (cargo door end / far end), roof,
bamboo floor, corner castings, corner posts, structural corrugation ribs.*

*Reports: [Container Basics](container-report.md) Part 4/6/8 (Orientation-B geometry, interior conversion + light-sealing + pinhole-wall prep, structural modification).*

*Diagrams: floor plan (FP), line of sight (LOS), assembly overview (AO), assembly fabrication (AF), film plane mechanism (FPM), electrical wiring (ES), water system (WS), hinged panel (HP), lighttrap (LT), plate drawing (PD), schematic (SC), walkway (WK).*

### 1.2 Optical Aperture

| Parameter | Value | Constant |
|---|---|---|
| Pinhole X position (long axis) | <!-- BEGIN cdm:PH_X -->2,454<!-- END cdm:PH_X -->mm | `PH_X` |
| Pinhole center height | <!-- BEGIN cdm:PH_H -->1,194<!-- END cdm:PH_H -->mm | `PH_H` |
| Pinhole diameter | Ø<!-- BEGIN cdm:PH_D -->2.17<!-- END cdm:PH_D -->mm | `PH_D` |
| f-number | f/<!-- BEGIN fact:f_number -->1088<!-- END fact:f_number --> | `PH_FNO` |
| Focal length | <!-- BEGIN fact:focal_length_mm -->2,362<!-- END fact:focal_length_mm -->mm | `PH_F` (= `C_WID`) |

*Component: the pinhole is carried by the [pinhole disc holder](pinhole-disc-holder-report.md) front board
(§1.4 — Ø80 carrier, pinhole board or Copal lens board), which supersedes the retired standard Ø600
interchangeable pinhole/lens plate.*

*Reports: [Pinhole Report](pinhole-report.md) §3/§4/§5/§7 (wall frame, pinhole plate, lens plate, light sealing); [Optics Report](pinhole-optics-report.md) Part 3/11 (optimal-diameter formulas, as-built f/1088 numbers).*

*Diagrams: floor plan (FP), line of sight (LOS), assembly overview (AO), assembly fabrication (AF), film plane mechanism (FPM), pinhole disc holder (PDH), plate drawing (PD), schematic (SC).*

### 1.3 Film Plane Mechanism

| Parameter | Value | Constant |
|---|---|---|
| Film plane left edge X | <!-- BEGIN cdm:FP_X_L -->260<!-- END cdm:FP_X_L -->mm | `FP_X_L` |
| Film plane right edge X | <!-- BEGIN cdm:FP_X_R -->4,649<!-- END cdm:FP_X_R -->mm | `FP_X_R` |
| Film plane width | <!-- BEGIN cdm:FP_W -->4,389<!-- END cdm:FP_W -->mm | `FP_W` |
| Film plane height | <!-- BEGIN cdm:FP_H -->2,094<!-- END cdm:FP_H -->mm | `FP_H` |
| Nominal depth from pinhole wall | <!-- BEGIN cdm:FP_Y -->2,262<!-- END cdm:FP_Y -->mm | `FP_Y` |
| Minimum carriage depth | <!-- BEGIN cdm:FP_Y_MIN -->100<!-- END cdm:FP_Y_MIN -->mm | `FP_Y_MIN` |
| Left rail X | <!-- BEGIN cdm:RAIL_X_L -->260<!-- END cdm:RAIL_X_L -->mm | `RAIL_X_L` |
| Right rail X | <!-- BEGIN cdm:RAIL_X_R -->4,649<!-- END cdm:RAIL_X_R -->mm | `RAIL_X_R` |
| Rail span | <!-- BEGIN cdm:RAIL_SPAN -->4,389<!-- END cdm:RAIL_SPAN -->mm | `RAIL_SPAN` |
| Rail length (Y travel) | <!-- BEGIN cdm:RAIL_LEN -->2,200<!-- END cdm:RAIL_LEN -->mm | `RAIL_LEN` |
| Max tilt (single-axis, Option A) | ±<!-- BEGIN cdm:MAX_TILT_DEG -->40<!-- END cdm:MAX_TILT_DEG -->° | `MAX_TILT_DEG` |
| Max swing (single-axis, Option A) | ±<!-- BEGIN cdm:MAX_SWING_DEG -->28<!-- END cdm:MAX_SWING_DEG -->° | `MAX_SWING_DEG` |
| Cross-slide Z travel (tilt) | ~250mm | `XSLIDE_Z_TRAVEL` |
| Cross-slide X travel (swing) | ~263mm | `XSLIDE_X_TRAVEL` |
| Cross-slide stroke (spec) | <!-- BEGIN cdm:XSLIDE_STROKE -->300<!-- END cdm:XSLIDE_STROKE -->mm | `XSLIDE_STROKE` |
| Cross-slides total (2/corner) | <!-- BEGIN cdm:XSLIDE_N -->8<!-- END cdm:XSLIDE_N --> | `XSLIDE_N` |

*Components (a fixed-size rigid plane on slide-and-clamp corners): 2"×2"×1/8" **plain-6061
aluminum** angle frame (expendable) + corner L-brackets, 4× **3×1.5 6061 Al U-channel** depth rails
(Grainger 795M51, ceiling + floor), 4× **4-wheel acetal skates** (Ø32 load + Ø20 keeper rollers
on Ø10 304 axle pins), **8× 304 flat-bar cross-slides (Z tilt + X swing) on UHMW self-lube pads +
adjustable gibs** (the 2-axis corner stage that absorbs the rigid-rotation arc travel), 4× **Belden
SSNBUJ750x3/8KB U-joints** (stainless, factory-booted (integral)), 12× cam-lever rail clamps, **single rigid ACM
backing panel**, Duvetyne curtain seals, rail felt light-trap strips, 58× nylon spring clamps
at <!-- BEGIN fact:clamp_spacing_mm -->150<!-- END fact:clamp_spacing_mm -->mm centers (muslin attachment). The plane stays a fixed-size flat rectangle — it does not
stretch or twist; single-axis tilt/swing envelope (tilt ±40° / swing ±28°).*

*Reports: [Film Plane Mechanism](film-plane-mechanism-report.md) §4/§5/§7 (mechanism design, tilt/swing configurations, parts list); [Muslin Clamp System](film-clamp-mechanism-report.md) §2/§3 (spring-clip layout + jaw mechanism).*

*Diagrams: floor plan (FP), line of sight (LOS), assembly overview (AO), assembly fabrication (AF), film plane mechanism (FPM), film plane distortion (FPD).*

### 1.4 Pinhole Disc Holder (Front Board)

| Parameter | Value | Constant |
|---|---|---|
| Pinhole X (holder centers here) | <!-- BEGIN cdm:PH_X -->2,454<!-- END cdm:PH_X -->mm | `PH_X` |
| Front plate Ø | Ø<!-- BEGIN cdm:PDH_PLATE_OD -->180<!-- END cdm:PDH_PLATE_OD --> | `PDH_PLATE_OD` |
| Standard pinhole Ø | Ø<!-- BEGIN cdm:PH_D -->2.17<!-- END cdm:PH_D --> | `PH_D` (Rayleigh optimum) |

*Components: ICP-01 Ø180×18mm 6061-T6 front plate (4× M6 mount @ Ø150; Ø90 scene taper
→ Ø40 aperture; Ø52 disc counterbore; 4× M5 taps @ Ø74), neoprene light-seal washer (Ø56×Ø40×1.5),
interchangeable ICP-02 Ø80 carrier (SS-302 pinhole board or a Copal/Compur 0/1/3 lens board), ICP-03 circular retaining ring
(Ø90 OD × Ø44 bore × 5), 4× M5 knurled thumb screws. No tilt/swing — the board is fixed.*

*Reports: [Pinhole Disc Holder (Front Board)](pinhole-disc-holder-report.md) §2/§3/§5/§6/§9 (mechanism overview, interchangeable discs, light sealing, wall mounting, parts list).*

*Diagrams: pinhole disc holder (PDH).*

### 1.5 Housed Revolving-Door Light Lock (rev 8)

| Parameter | Value | Constant |
|---|---|---|
| Light-lock center X (cargo door end wall) | <!-- BEGIN cdm:DRUM_CX -->-420<!-- END cdm:DRUM_CX -->mm | `DRUM_CX` |
| Fixed housing outer diameter | <!-- BEGIN cdm:DRUM_D -->800<!-- END cdm:DRUM_D -->mm | `DRUM_D` |
| Housing radius | 450mm | `DRUM_R` / `LT_HOUSING_R` |
| Drum outer radius (rotating) | <!-- BEGIN cdm:LT_DRUM_OR -->382<!-- END cdm:LT_DRUM_OR -->mm | `LT_DRUM_OR` |
| Opening arc (each) | <!-- BEGIN cdm:LT_OPENING_DEG -->80<!-- END cdm:LT_OPENING_DEG -->° | `LT_OPENING_DEG` |
| Top Z (walkway-lifted) | <!-- BEGIN cdm:DRUM_H_LT -->2,100<!-- END cdm:DRUM_H_LT -->mm | `DRUM_H_LT` |

*Components: fixed Ø800 aluminum housing with two 80° openings (exterior + interior-onto-walkway,
180° apart); single-opening C-shell rotating drum (Ø764, ~Ø850 bore, NO internal fins) — light-tight
by geometry; 8mm Al top/bottom caps, 75mm stub shafts (×2), 2× SKF 6215-2RS1 sealed bearings, drum↔housing
running-gap #4 strip brushes in Al flange holders + top/bottom neoprene cap seals, off-the-shelf 12″ round
pull handle (McMaster 1871A65), housing-to-panel neoprene compression strip. Replaces the failed Ø750 4-fin drum.*

*Reports: [Light Trap Selection](light-trap-selection.md) §4/§5 (housed revolving-door specification, light-path verification); [Hinged Light-Trap Panel](hinged-panel-report.md) §3 (as-integrated light lock: spec, bearings, drum seals).*

*Diagrams: floor plan (FP), line of sight (LOS), assembly overview (AO), assembly fabrication (AF), hinged panel (HP), lighttrap (LT).*

### 1.6 Hinged Cargo-Door Panel

| Parameter | Value | Constant |
|---|---|---|
| Panel width | <!-- BEGIN cdm:C_WID -->2,362<!-- END cdm:C_WID -->mm | `C_WID` |
| Panel height | <!-- BEGIN cdm:C_HGT -->2,388<!-- END cdm:C_HGT -->mm | `C_HGT` |
| Panel thickness | 120mm | — (hardcoded in scripts) |

*Components: 2×2×0.120in steel frame, 1/8" HDPE plastic skins (both faces; 18mm-ply Fan-B mount band), 20mm EPDM compression
gasket in machined channel + 2× vertical cut seals (Yd180/2287), vertical **Ø89×8mm CHS pivot
post** (rev10 — the reused film far-left upright, on a thrust collar + top/bottom hub bearings;
structural sign-off) carrying the ~56° transport swing, 4× Southco C2-33 cam compression latches,
top + bottom wall stays (transport lock), Ø800mm housed revolving-door light-lock aperture in the
B2 punch-out bay.*

*Reports: [Hinged Light-Trap Panel](hinged-panel-report.md) §2/§4/§5/§7/§8 (panel construction, hinges + Southco cam latches, rotating transport swing, fixed door frame, parts list).*

*Diagrams: assembly overview (AO), assembly fabrication (AF), hinged panel (HP), lighttrap (LT).*

### 1.7 Ventilation System

| Parameter | Value | Constant |
|---|---|---|
| Fan diameter (both fans) | <!-- BEGIN cdm:FAN_DIAM -->150<!-- END cdm:FAN_DIAM -->mm | `FAN_DIAM` |
| Panel fan body depth | <!-- BEGIN cdm:FAN_BODY_D -->50<!-- END cdm:FAN_BODY_D -->mm | `FAN_BODY_D` |
| Fan A center height AFF (below X1, in corridor) | <!-- BEGIN cdm:FAN_A_H -->2,000<!-- END cdm:FAN_A_H -->mm | `FAN_A_H` |
| Fan B center height AFF (low) | <!-- BEGIN cdm:FAN_B_H -->700<!-- END cdm:FAN_B_H -->mm | `FAN_B_H` |
| Fan A Yd position (below the X1 fill port, plumbing corridor) | <!-- BEGIN cdm:FAN_A_YD -->1,181<!-- END cdm:FAN_A_YD -->mm | `FAN_A_YD` |
| Fan B Yd position (near pinhole wall, near corner — rev9/B2 swap) | <!-- BEGIN cdm:FAN_B_YD -->416.5<!-- END cdm:FAN_B_YD -->mm | `FAN_B_YD` |
| Baffle duct depth | <!-- BEGIN cdm:DUCT_DEPTH -->300<!-- END cdm:DUCT_DEPTH -->mm | `DUCT_DEPTH` |
| Baffle duct height | <!-- BEGIN cdm:DUCT_HEIGHT -->200<!-- END cdm:DUCT_HEIGHT -->mm | `DUCT_HEIGHT` |
| Fan A shadow margin (from cone) | <!-- BEGIN cdm:FAN_A_MARGIN -->869<!-- END cdm:FAN_A_MARGIN -->mm | `FAN_A_MARGIN` |
| Fan B shadow margin (from cone) | <!-- BEGIN cdm:FAN_B_MARGIN -->40<!-- END cdm:FAN_B_MARGIN -->mm | `FAN_B_MARGIN` |

*Components: Fan A — 150mm compact axial panel fan, sealed end wall, exhaust, Circuit A,
in the <!-- BEGIN fact:corridor_width_mm -->270<!-- END fact:corridor_width_mm -->mm plumbing corridor directly **below the X1 fill port** — the only
full-height clear channel past the 1,000L direct-stack. Fan B —
identical fan, mounted on hinged panel (near corner zone by the pinhole wall,
 so its conduit runs along the pinhole wall near the pivot side), intake,
Circuit B, low position. Fan A mounts on interior face of a 300mm deep light-safe baffle duct with 2 offset
steel baffles (65% height each, horizontal S-path); exterior face has a passive weatherproof louvre grille.
Fan B has the same baffle duct protruding from the panel exterior face — draws fresh air from the
open doorway during operation. Fan B swings with the panel about the pivot; wiring via
flexible coiled cable (with swing slack) from the fixed door frame (Circuit B).*

*Report: [Ventilation & Cooling System](ventilation-report.md) — authoritative specification for fan system, baffle ducts, operating modes, and shade canopy.*

*Reports: [Ventilation & Cooling](ventilation-report.md) §4/§7/§8 (fans A/B + baffle ducts, operating modes, electrical integration); [Electrical](electrical-report.md) §7.2 (Circuit F ventilation fans).*

*Diagrams: lighttrap sheet 1 combined elevation (LT), lighttrap sheet 2 ventilation details (LT), electrical sheet 1 wiring (ES), floor plan (FP), assembly overview (AO).*

### 1.8 Evaporative Cooler (External)

| Parameter | Value | Constant |
|---|---|---|
| Duct penetration X | <!-- BEGIN cdm:EVAP_DUCT_X -->1,000<!-- END cdm:EVAP_DUCT_X -->mm | `EVAP_DUCT_X` |
| Duct penetration Z | <!-- BEGIN cdm:EVAP_DUCT_Z -->1,900<!-- END cdm:EVAP_DUCT_Z -->mm | `EVAP_DUCT_Z` |
| Duct diameter | <!-- BEGIN cdm:EVAP_DUCT_D -->200<!-- END cdm:EVAP_DUCT_D -->mm | `EVAP_DUCT_D` |
| Cooler body W×D×H | 508×254×711mm | `EVAP_W`/`EVAP_D`/`EVAP_H` |
| Stow left edge X | <!-- BEGIN cdm:EVAP_STOW_X -->1,450<!-- END cdm:EVAP_STOW_X -->mm | `EVAP_STOW_X` |
| Inverter mount X / Z | 1910 / 1,180mm | `INVERTER_X`/`INVERTER_Z` |
| Inverter W×H×D | 120×235×72mm | `INVERTER_W`/`INVERTER_H`/`INVERTER_D` |

*Component: **Hessaire MC18M** evaporative cooler (120V AC, <!-- BEGIN fact:evap_cooler_w_ac -->85<!-- END fact:evap_cooler_w_ac -->W, 1,300 CFM run on low, 4.8 gal
reservoir), ground-placed outside on Circuit E. Powered by an **interior 12V→120V pure-sine
inverter (Victron Phoenix 12/375 GFCI)** wall-mounted below the EP; ~<!-- BEGIN fact:evap_cooler_w_bus -->97<!-- END fact:evap_cooler_w_bus -->W on the 12V bus. Cooled
air enters through a Ø200mm insulated flex duct to a wall penetration with light-safe baffle.
AC isolation/GFCI/equipotential-bonding: [Electrical §7.6](electrical-report.md#ac-safety).*

*Reports: [Ventilation & Cooling](ventilation-report.md) §5 (cooler spec + duct + stowage); [Electrical](electrical-report.md) §3/§5.4/§7.6 (Circuit E inverter, power panel AC outlet, AC safety).*

*Diagrams: lighttrap sheet 1 (LT), electrical sheet 1 wiring (ES), floor plan (FP), assembly overview (AO), assembly fabrication (AF).*

### 1.9 Electrical System

| Parameter | Value | Constant |
|---|---|---|
| Electrical panel left edge X | <!-- BEGIN cdm:EP_X -->1,829<!-- END cdm:EP_X -->mm | `EP_X` |
| Panel width | <!-- BEGIN cdm:EP_W -->300<!-- END cdm:EP_W -->mm | `EP_W` |
| Panel height range | 900–1,500mm | `EP_H_LO`, `EP_H_HI` |
| Battery bank left edge X | <!-- BEGIN cdm:BA_X -->1,829<!-- END cdm:BA_X -->mm | `BA_X` |
| Battery bank width | <!-- BEGIN cdm:BA_W -->260<!-- END cdm:BA_W -->mm | `BA_W` |
| Battery bank height range | 100–600mm | `BA_H_LO`, `BA_H_HI` |

*Components: 3× 200W monocrystalline solar panels (roof-mounted), Victron SmartSolar MPPT 100/50,
1× 100Ah LiFePO4 battery (1,200Wh standard; 2nd pack ghosted = plug-in → 200Ah / 2,400Wh),
Victron Blue Smart IP65 shore charger, NEMA 5-15R weatherproof inlet, Blue Sea 5026 12-circuit
fuse block, IP65 enclosure (300×200×130mm). Battery protection chain: 200A MRBF terminal fuse →
ML-RBS remote contactor → m-Series main disconnect; external emergency E-stop on the power-panel
face trips the contactor (kills all DC from outside). 4 AWG ground wire + 8ft copper stake.*

*Circuits: A — safelight strip (overhead red LED); B — film plane mechanism motors;
C — water pumps P-01–P-05 (P-04 on the pinhole-wall filter skid, others in the IBC corridor); D — safelight vestibule; E — evaporative cooler; F — ventilation fans.*

*Reports: [Electrical](electrical-report.md) §4/§5/§7 (solar array, charge controller + battery + shore charger + external panel, wiring/enclosure/protection); [Electrical Safety](electrical-safety-report.md) §3/§5 (design controls, cascaded improvements).*

*Diagrams: floor plan (FP), line of sight (LOS), assembly overview (AO), assembly fabrication (AF), electrical wiring (ES).*

### 1.10 Pump Manifold (Plumbing Panel)

| Parameter | Value | Constant |
|---|---|---|
| Left edge X | <!-- BEGIN cdm:PUMP_X -->4,760<!-- END cdm:PUMP_X -->mm | `PUMP_X` |
| Pump-zone width (X, elevation) | <!-- BEGIN cdm:PUMP_W -->114<!-- END cdm:PUMP_W -->mm | `PUMP_W` |
| Height range | 900–1,400mm | `PUMP_H_LO`, `PUMP_H_HI` |
| Depth from pinhole wall | 1,046mm | `PUMP_YD` (= `CORRIDOR_YD_NEAR`) |
| Protrusion from panel | <!-- BEGIN cdm:PUMP_D -->114<!-- END cdm:PUMP_D -->mm | `PUMP_D` |

*Components: 1" PVC header + isolation valves, 4× 12V pumps on plumbing panel (P-01 Blue spray bar supply,
P-02 Brown recycle via filter, P-03 waste evacuation, P-04 tray sump pickup),
two 0.75 L pressure accumulators — ACC-01 (corridor, damps the main filter loop) and ACC-02 (on the filter skid, damps the recycle-spray pump P-02), DN50 butterfly valves V1–V4 (S60×6 thread) at IBC outlets,
manifold ball valves VB1/VB2/VB3, check valves CV1/CV3/CV4 on bulkhead lines X1/X3/X4, X1 fill tee (splits to IBC-1 & IBC-2), Circuit C.
Mounted on 18mm marine ply plumbing panel (near IBC column face), in the IBC plumbing corridor.*

*Reports: [Plumbing](plumbing-report.md) §3.2/§3.3/§4/§7 (corridor pump zone P-01/P-02/P-03/P-05, accumulator ACC-01, valves, panel mounting); [Processing System](water-system-report.md) §7 (equipment layout).*

*Diagrams: floor plan (FP), line of sight (LOS), assembly overview (AO), assembly fabrication (AF), electrical wiring (ES), water system (WS).*

### 1.11 Water System — Blue Circuit

| Parameter | Value | Constant |
|---|---|---|
| IBC column left edge X | <!-- BEGIN cdm:IBC_COL_X -->4,674<!-- END cdm:IBC_COL_X -->mm | `IBC_COL_X` |
| IBC footprint width | <!-- BEGIN cdm:IBC_W -->1,219<!-- END cdm:IBC_W -->mm | `IBC_W` |
| IBC footprint depth | <!-- BEGIN cdm:IBC_D -->1,016<!-- END cdm:IBC_D -->mm | `IBC_D` |
| Single tote height (1,000L caged) | <!-- BEGIN cdm:IBC_H_1000 -->1,168<!-- END cdm:IBC_H_1000 -->mm | `IBC_H_1000` |
| Stacked height (2× 1,000L, direct-stack) | <!-- BEGIN cdm:IBC_H_STK_1000 -->2,336<!-- END cdm:IBC_H_STK_1000 -->mm | `IBC_H_STK_1000` |
| Near-column front depth from pinhole wall | <!-- BEGIN cdm:BLUE_IBC_Y -->30<!-- END cdm:BLUE_IBC_Y -->mm | `BLUE_IBC_Y` |
| Far-column front depth from pinhole wall | <!-- BEGIN cdm:IBC_FAR_Y -->1,316<!-- END cdm:IBC_FAR_Y -->mm | `IBC_FAR_Y` |

*Components: **4× 1,000L caged composite IBC totes** (1,219×1,016×1,168), **direct-stacked**
cage-on-cage in two columns (near: Brown developer + Blue #1; far: Waste + Blue #2) — Blue-on-top layout
kept. Held by a **restraint DEEP 4-LEG BOX** at the corridor mouth (2×2×0.120in steel SHS front + back upright pairs
450mm apart tied by rings + 50×20×3 front retaining bars in the 25mm tote↔film-rail gap + Simpson wall
joist-hangers + D-ring lashing + 4 floor feet) —
NOT a load-bearing platform; the totes carry their own stack load. 1" PVC Sch-40 blue supply pipe, spray bar
(¾" PVC), Blue fill = gravity **side-entry near the top** (X1, shared T), Brown/Waste drains pumped (X3/X4).
Legacy `IBC_H_600`=1010 / `IBC_H_STK`=2020 constants are the superseded "600L fill-level" values — kept only
for the few generators not yet repointed (overview Blue-trunk shelf, walkway/weight context imports).*

*Reports: [Processing System](water-system-report.md) §3/§4.1 (storage capacity, Blue clean-water supply); [IBC Stacking System](ibc-stacking-report.md) §2/§3 (tote spec/layout, restraint deep 4-leg box); [Plumbing](plumbing-report.md) §6.1 (Blue supply flow path).*

*Diagrams: floor plan (FP), line of sight (LOS), assembly overview (AO), assembly fabrication (AF), water system (WS).*

### 1.12 Water System — Brown Circuit

| Parameter | Value | Constant |
|---|---|---|
| Brown IBC front depth | <!-- BEGIN cdm:BROWN_IBC_Y -->30<!-- END cdm:BROWN_IBC_Y -->mm | `BROWN_IBC_Y` |
| IBC dimensions | same as Blue | `IBC_W`, `IBC_D`, `IBC_H_600` |

*Components: 1× 1,000L caged composite IBC (Y-stacked behind Blue stack, right end zone),
DN50 butterfly valve (S60×6) + S60×6-to-1" NPT adapter at drain outlet,
3-stage Big Blue filter bank (5μm sediment → KDF-55 → carbon, wall-mounted on the filter skid), Shurflo P-04 (tray drain),
3-way diverter valves 3W-DV-01 and 3W-DV-02, SV-01 pH sample tap.
Filled via side-entry near the top from the P-04 tray-sump pickup pump (no top-cap access — <!-- BEGIN fact:ibc_ceiling_clearance_mm -->52<!-- END fact:ibc_ceiling_clearance_mm -->mm headroom).*

*Reports: [Processing System](water-system-report.md) §4.2 (Brown used-water recycling); [Plumbing](plumbing-report.md) §3.1/§4.2/§4.4/§6.2 (filter skid + P-02, diverter valves, SV-01 pH sample tap, Brown flow path).*

*Diagrams: floor plan (FP), line of sight (LOS), assembly overview (AO), assembly fabrication (AF), water system (WS).*

### 1.13 Water System — Black Circuit (Waste)

| Parameter | Value | Constant |
|---|---|---|
| Waste IBC front depth | <!-- BEGIN cdm:WASTE_IBC_Y -->1,316<!-- END cdm:WASTE_IBC_Y -->mm | `WASTE_IBC_Y` |
| IBC far column start Y | <!-- BEGIN cdm:IBC_FAR_Y -->1,316<!-- END cdm:IBC_FAR_Y -->mm | `IBC_FAR_Y` |
| Waste IBC color code | Black | `C_WASTE_IBC` |

*Components: 1× 1,000L caged composite IBC tote (4th IBC in 2×2 stack, right end zone),
DN50 butterfly valve (S60×6) + S60×6-to-1" NPT adapter at drain outlet,
2" NPT bulkhead fittings for external drain/fill (X4), reinforcing plates for external ports,
P-03 waste evacuation pump (mounted in IBC plumbing corridor on X4 drain run). Filled via side-entry near the top from the filter reject line (no top-cap access).*

*Reports: [Processing System](water-system-report.md) §4.3 (Black waste containment); [Plumbing](plumbing-report.md) §3.2/§6.3 (P-03 corridor waste pump, Black flow path); [IBC Stacking System](ibc-stacking-report.md) §6 (external bulkhead ports, X4 drain/fill).*

*Diagrams: floor plan (FP), line of sight (LOS), assembly overview (AO), assembly fabrication (AF), water system (WS).*

### 1.14 Equipment Zones

| Parameter | Value | Constant |
|---|---|---|
| Left end zone boundary (right edge) | X = <!-- BEGIN cdm:ZONE_L_END -->260<!-- END cdm:ZONE_L_END -->mm | `ZONE_L_END` |
| Right end zone boundary (left edge) | X = <!-- BEGIN cdm:ZONE_R_START -->4,649<!-- END cdm:ZONE_R_START -->mm | `ZONE_R_START` |
| Optical cone left at depth Y | `PH_X − (PH_X − FP_X_L) × Y / FP_Y` | `cone_left(y)` |
| Optical cone right at depth Y | `PH_X + (FP_X_R − PH_X) × Y / FP_Y` | `cone_right(y)` |

*Derived rule: any equipment with X < ZONE_L_END is shadow-free at all depths.
Any equipment with X > ZONE_R_START is shadow-free at all depths.
Equipment at pinhole wall face - always shadow-free.
Equipment in the IBC corridor is shadow-free.*

*Reports: [Equipment Layout](equipment-layout-report.md) §1/§2/§3 (shadow-free zone definitions + optical cone, equipment positions, floor-plan & line-of-sight diagrams).*

*Diagrams: floor plan (FP), line of sight (LOS), assembly overview (AO).*

### 1.15 Panel Swing Pivot

| Parameter | Value | Constant |
|---|---|---|
| Transport swing angle | <!-- BEGIN cdm:SWING_LOCK_DEG -->56<!-- END cdm:SWING_LOCK_DEG -->° | `SWING_LOCK_DEG` |
| Pivot post position | X=175mm, Yd=2,287mm | `PIVOT_X`, `PIVOT_YD` |
| Pivot post | Ø89×8mm CHS (reused film far-left upright) | `PIVOT_POST_OD`, `PIVOT_POST_T` |
| Lock mechanism | top + bottom wall stays (hook + eye + turnbuckle) | — |
| Swung door clearance | +<!-- BEGIN fact:swung_door_clearance_mm -->29<!-- END fact:swung_door_clearance_mm -->mm (bay front-right corner, to the closed-door inner face) | — |

*Components: Ø89×8mm CHS pivot post on a thrust collar + top/bottom hub bearings (Ø220 thrust +
2× Ø90 journal), drum support cage (1.5×1.5×0.120in steel SHS), top + bottom wall stays + 4-bolt wall anchor
plates, 4× drop-in rail saddles + tapered dowels (for the removable left film rails).*

*Reports: [Hinged Light-Trap Panel](hinged-panel-report.md) §5/§8.3 (rotating transport system + locking wall stays, swing-pivot hardware); [Equipment Layout](equipment-layout-report.md) §6.1 (stepped panel & swing pivot, transport mode).*

*Diagrams: container floor plan (FP), assembly overview plan view (AO), hinged panel sheet 4 (HP).*

### 1.16 Processing Tray

| Parameter | Value | Constant |
|---|---|---|
| Tray left edge X | <!-- BEGIN cdm:PROC_TRAY_X_L -->280<!-- END cdm:PROC_TRAY_X_L -->mm | `PROC_TRAY_X_L` |
| Tray right edge X | <!-- BEGIN cdm:PROC_TRAY_X_R -->4,629<!-- END cdm:PROC_TRAY_X_R -->mm | `PROC_TRAY_X_R` |
| Tray width | <!-- BEGIN cdm:PROC_TRAY_W -->4,349<!-- END cdm:PROC_TRAY_W -->mm | `PROC_TRAY_W` |
| Tray depth | <!-- BEGIN cdm:PROC_TRAY_D -->2,200<!-- END cdm:PROC_TRAY_D -->mm | `PROC_TRAY_D` |
| Tray near edge Yd | <!-- BEGIN cdm:PROC_TRAY_YD_NEAR -->80<!-- END cdm:PROC_TRAY_YD_NEAR -->mm | `PROC_TRAY_YD_NEAR` |
| Tray far edge Yd | <!-- BEGIN cdm:PROC_TRAY_YD_FAR -->2,280<!-- END cdm:PROC_TRAY_YD_FAR -->mm | `PROC_TRAY_YD_FAR` |
| Rim height | <!-- BEGIN cdm:PROC_TRAY_RIM -->50<!-- END cdm:PROC_TRAY_RIM -->mm | `PROC_TRAY_RIM` |
| Dual-axis pitch | 1:200 (<!-- BEGIN cdm:PROC_TRAY_PITCH -->10<!-- END cdm:PROC_TRAY_PITCH -->mm fall) | `PROC_TRAY_PITCH` |
| Sump X | <!-- BEGIN cdm:PROC_TRAY_DRAIN_X -->2,386<!-- END cdm:PROC_TRAY_DRAIN_X -->mm | `PROC_TRAY_DRAIN_X` |
| Sump Yd | <!-- BEGIN cdm:PROC_TRAY_DRAIN_YD -->80<!-- END cdm:PROC_TRAY_DRAIN_YD -->mm | `PROC_TRAY_DRAIN_YD` |
| Sump dimensions | 150 x 100 x 20mm | `PROC_TRAY_SUMP_W/D/Z` |

*Components: 304 SS sheet (16-ga, 1.5mm), 2 panels field-bolted at center flange,
pressed sump well (150x100x20mm), 5x tapered HDPE shim strips (50mm wide, 0-10mm),
1" SS foot valve w/ strainer, 1" reinforced suction hose, silicone gasket strip,
M6x16 SS fasteners. No penetration of tray or container floor.
Permanently installed — no removal for transport mode conversion.*

*Reports: [Processing Tray & Spray Bar](processing-tray-and-spray-bar.md) §2/§6.1 (tray specification, HDPE shim slope, sump well, permanent installation, parts); [Processing System](water-system-report.md) §4.4 (processing tray & spray bar).*

*Diagrams: water system sheets 3-4 (WS), container floor plan (FP), assembly overview (AO), walkway sheet 2 (WK).*

### 1.17 Perimeter Walkway

| Parameter | Value | Constant |
|---|---|---|
| Walkway width | <!-- BEGIN cdm:WALKWAY_W -->300<!-- END cdm:WALKWAY_W -->mm | `WALKWAY_W` |
| Deck height | <!-- BEGIN cdm:WALKWAY_H -->140<!-- END cdm:WALKWAY_H -->mm | `WALKWAY_H` |
| Grate thickness (all sections) | <!-- BEGIN cdm:WALKWAY_GRATE_T -->25<!-- END cdm:WALKWAY_GRATE_T -->mm | `WALKWAY_GRATE_T` |
| Bracket vertical leg | <!-- BEGIN cdm:WALKWAY_BRACKET_H -->200<!-- END cdm:WALKWAY_BRACKET_H -->mm | `WALKWAY_BRACKET_H` |
| Bracket plate thickness | <!-- BEGIN cdm:WALKWAY_BRACKET_T -->8<!-- END cdm:WALKWAY_BRACKET_T -->mm | `WALKWAY_BRACKET_T` |
| Bracket spacing | <!-- BEGIN cdm:WALKWAY_BRACKET_SPACING -->457<!-- END cdm:WALKWAY_BRACKET_SPACING -->mm | `WALKWAY_BRACKET_SPACING` |
| Container rib spacing | <!-- BEGIN cdm:CONTAINER_RIB_SPACING -->457<!-- END cdm:CONTAINER_RIB_SPACING -->mm | `CONTAINER_RIB_SPACING` |
| Right-walkway L-angle grate bearer | 1×1×3/16in steel angle | prose — [walkway-report §4.4](walkway-report.md); no constant (#26) |
| Near walkway Yd | <!-- BEGIN cdm:WALKWAY_NEAR_YD -->0<!-- END cdm:WALKWAY_NEAR_YD -->mm | `WALKWAY_NEAR_YD` |
| Far walkway Yd | <!-- BEGIN cdm:WALKWAY_FAR_YD -->2,062<!-- END cdm:WALKWAY_FAR_YD -->mm | `WALKWAY_FAR_YD` |
| Left walkway X | <!-- BEGIN cdm:WALKWAY_LEFT_X -->280<!-- END cdm:WALKWAY_LEFT_X -->mm | `WALKWAY_LEFT_X` |
| Left walkway unsupported span | <!-- BEGIN cdm:WALKWAY_LEFT_SPAN -->1,762<!-- END cdm:WALKWAY_LEFT_SPAN -->mm | `WALKWAY_LEFT_SPAN` |
| Right walkway X | <!-- BEGIN cdm:WALKWAY_RIGHT_X -->4,329<!-- END cdm:WALKWAY_RIGHT_X -->mm | `WALKWAY_RIGHT_X` |

*Components: Near/far: 25mm grating on 8mm gusset brackets bolted to corrugated wall ribs.

Right: cantilever rectangle — a closed 2×1×0.120in steel frame (2 long beams at X=4329/4574 +
2 end beams) picked up at mid-span by 2 arms cantilevering off the IBC corridor uprights (half-lapped
where the long beams cross), on wall cleats at the left corners and combined corner plates (shared with
the bottom film rail BR) at the right corners. No floor contact, no roof penetrations — clears IBC stack entirely.

Left: removable lift-out, 25mm grating resting on butt joints (no brackets —
panel conflict, must remove before the panel swings to transport). No floor contact on
any section. 4 removable sections.*

*Reports: [Walkway](walkway-report.md) §3/§4/§5/§8 (near/far wall-cantilevered, right cantilever rectangle, left removable lift-out, grating spec); [Right Walkway Cantilever](right-walkway-cantilever-study.md) §3/§7 (hybrid-anchor design, rev12).*

*Diagrams: walkway sheet 1 cross-section (WK), walkway sheet 2 plan view (WK), container floor plan (FP), hinged panel (HP).*

---
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

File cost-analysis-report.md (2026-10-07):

<!-- SPDX-License-Identifier: AGPL-3.0-only -->
<!-- © 2026 Alvin Richards -->
# Cost Savings Analysis Report

## 1. Purpose & Scope

A companion to the [Weight Distribution Report](weight-distribution-report.md): where the
weight study asks *where is the mass and where can it be cut*, this asks **where is the
cost and where can it be saved**. It breaks the build down by system, separates one-time
capital from recurring/consumable spend, and ranks the realistic savings levers.

All figures are the **mid-column** estimates from the
[Cost Breakdown](project-cost-breakdown.md) (the itemized source of truth); the build
mid-total is **~<!-- BEGIN costing:ca-mid-total -->$32,489<!-- END costing:ca-mid-total -->**.

---

## 2. Method — Capital vs Recurring

Just as the weight study set aside the fixed container shell to find the *addressable*
design, a cost study has to separate the one-time **capital build** from spend that
recurs or is consumed — savings strategy is different for each.

<!-- BEGIN costing:ca-buckets -->
| Bucket | Mid | What it is |
|---|--:|---|
| **Capital build** (one-time hardware) | **$29,239** | The systems you build once — this is where build-savings live |
| Consumable (per 50-print batch) | $1,710 | Cyanotype chemistry + substrate (Standard ½-Ware) — recurs every batch |
| Recurring (per deployment) | $750 | Commercial-hire transport |
| Soft / regulatory | $790 | Licenses & permits |
<!-- END costing:ca-buckets -->

Build-savings work on the **<!-- BEGIN costing:ca-capital -->$29,239<!-- END costing:ca-capital --> capital**. The <!-- BEGIN costing:ca-consumable -->$1,710<!-- END costing:ca-consumable --> consumable is attacked
separately (bulk chemistry, cheaper substrate) because it repeats every batch and
quickly dominates lifetime cost.

---

## 3. Where the Cost Is

Capital systems ranked by mid cost:

<!-- BEGIN costing:ca-ranking -->
| System | Mid | % of capital | Notes |
|---|--:|--:|---|
| **Processing water system** | $7,517 | 26% | Tray (304 SS) + IBC frame dominate |
| **Film-plane mechanism** | $4,324 | 15% | Carriages, Option-A 304 cross-slides, muslin spring clips, wall-seat saddles |
| **Light lock** | $3,651 | 12% | Plastic-skin custom fabrication |
| **Power & electrical** | $3,459 | 12% | Battery + solar + distribution + protection |
| **Container + delivery** | $3,300 | 11% | Grade-dependent (CW vs WWT) |
| **Perimeter walkway** | $2,507 | 9% | GRP grating + steel cantilevers |
| **Swing pivot** | $1,490 | 5% | Pivot post + bearings + cage + fixed RHS door frame |
| **Hinged panel structure** | $1,352 | 5% | Stepped frame + HDPE skins + Al core + EPDM + latches + B2 bay |
| **Ventilation & cooling** | $808 | 3% | Fans + cooler + inverter + baffle-duct fab + canopy |
| **Interior conversion** | $505 | 2% | Insulation, sealing, safelight |
| **Chemistry prep shelf** | $274 | 0.9% | Fold-down phenolic board + frame + hinge/stays + tap extension |
| **Optics — pinhole** | $52 | 0.2% | Trivial (it is a pinhole) |
<!-- END costing:ca-ranking -->

The **water system is <!-- BEGIN costing:ca-water-pct -->26<!-- END costing:ca-water-pct -->% of the capital build** and the **304 SS processing tray is its
single biggest line** (<!-- BEGIN costing:tray-low -->$1,473<!-- END costing:tray-low -->–<!-- BEGIN costing:tray-high -->$2,121<!-- END costing:tray-high -->) — the same item that topped the weight study.

---

## 4. Savings Opportunities

Ranked by dollar potential and ease. Status is updated as levers are actioned.

| # | Lever | System | Saves | Ease / risk | Status |
|---|---|---|--:|---|---|
| 1 | **Container grade CW → WWT** (wind-water-tight used vs cargo-worthy — fine for a stationary darkroom) | Container | ~<!-- BEGIN costing:ca-lever-container -->$1,350<!-- END costing:ca-lever-container --> | Easy, low risk | Available |
| 2 | **Drop film-plane electric actuation → manual** (the mechanism already supports manual tilt/swing) | Film plane | ~<!-- BEGIN costing:ca-lever-film -->$827<!-- END costing:ca-lever-film --> | Easy, if manual is acceptable | **Actioned 2026-06-13 (banked)** — manual is the standard build, so this is already realized, not a still-available saving; electric is a documented upgrade only ([Cost Breakdown §4.4](project-cost-breakdown.md)) |
| 3 | **Processing tray: 304 SS → poly** (poly needs a support frame over the 4.5 m span + poly-weld fab) | Water | ~<!-- BEGIN costing:ca-lever-tray-low -->$600<!-- END costing:ca-lever-tray-low -->–<!-- BEGIN costing:ca-lever-tray-high -->$1,000<!-- END costing:ca-lever-tray-high --> | Medium | **Decided 2026-07-05 — keep 304 SS** (self-supporting + durable; not revisiting) |
| 4 | **Battery — already 1×100 Ah** (the lean config; [Water System Report](water-system-report.md): 1×100 Ah ≈ 25+ prints/charge). A 2nd pack is a +<!-- BEGIN costing:ca-lever-battery -->$375<!-- END costing:ca-lever-battery --> optional **upgrade**, not a saving. | Power | +$375 (add) | — | **Not a saving** — 100 Ah is the standard |
| 5 | **Solar 3 → 2 panels** (if the power budget allows) | Power | ~<!-- BEGIN costing:ca-lever-solar -->$133<!-- END costing:ca-lever-solar --> | Easy | Available — computed (drop 1× 200W panel) |
| 6 | **Valves / fittings value-engineering** | Water | ~<!-- BEGIN costing:ca-lever-valves-low -->$100<!-- END costing:ca-lever-valves-low -->–<!-- BEGIN costing:ca-lever-valves-high -->$200<!-- END costing:ca-lever-valves-high --> | Medium | Available |

After the material decisions, the only still-**available** build-savings levers are **1 (container grade) + 5 (solar)** — together **~<!-- BEGIN costing:ca-savings-low -->$1,500<!-- END costing:ca-savings-low -->** off the <!-- BEGIN costing:ca-capital -->$29,239<!-- END costing:ca-capital --> capital build (**~<!-- BEGIN costing:ca-savings-pct-low -->5<!-- END costing:ca-savings-pct-low -->%**), plus ~$100–200 of valve value-engineering (#6). Everything else is settled: lever 2 **banked** (manual is the standard build), lever 3 **kept 304 SS** (decision), lever 4 **already 1×100 Ah**.

> **Derivation note.** Lever 1 (container grade), lever 5 (solar), and the roll-up total +
> percentage are computed in `costing.py` — container is a true CW − WWT subtraction off the
> scenario layer, solar is a real 1-panel subtraction (drop 1× `solar-panel-200w`), and the roll-up
> is the summed **still-available** levers over the capital build, so all cascade on any cost change.
> Bucket-B finding (2026-07-05): modeling each option against the as-built BOM showed lever 2 (film)
> is already **banked** — manual is the standard build — and lever 4 (battery) is moot — the standard
> is already 1×100 Ah, and its 2nd pack is a +$375 **upgrade**, not a saving — so both were dropped
> from the roll-up. Lever 3 (tray) is now **decided** too — 304 SS kept (over the 4.5 m span a poly
> tray needs a support frame that erodes the saving, plus poly-weld fab) — so it also leaves the roll-up.

---

## 5. The Cost–Weight Tension

Cost and weight do not always move together — some weight savings *cost* money, and vice
versa. Worth keeping in view when prioritizing:

- The **GRP walkway grating** (corrosion immunity in the chemistry zone) *added* ~$720–890 to
  save 62 kg. **Decided 2026-07-05 — keep molded GRP:** the 62 kg weight saving + corrosion
  immunity are worth the premium; the ~$800 galvanized-steel alternative is **not** being taken.
- The **processing tray** (lever #3): SS → poly would cut *both* cost and weight, but **decided
  2026-07-05 to keep 304 SS** — over the 4.5 m span a poly tray needs a support frame (eroding the
  saving) plus poly-weld fabrication; 304 SS is self-supporting and durable.

---

## 6. What Is Effectively Fixed

- **Container shell** — already the cheapest large steel box; only the *grade* is a lever
  (#1).
- **Light lock** — already the cheap custom option (<!-- BEGIN costing:ca-lightlock-mid -->$3,651<!-- END costing:ca-lightlock-mid --> mid vs $2,500–4,500 for a
  commercial darkroom door).
- **Swing pivot, ventilation, optics** — small absolute spend; diminishing returns.
- **IBC frame, pumps, filters** — load-bearing or commodity; little to cut safely.

---

## 7. Source References

1. [Cost Breakdown](project-cost-breakdown.md) — itemized build cost, three scenarios, all sources cited (the figures this report summarizes).
2. [Weight Distribution Report](weight-distribution-report.md) — the companion mass study; the tray is the shared top lever.
3. [Film Plane Mechanism Report](film-plane-mechanism-report.md) — manual vs electric actuation (lever #2).
4. [Water System Report](water-system-report.md) — processing tray (304 SS) and battery/pump sizing (levers #3, #4).
5. [Electrical Report](electrical-report.md) — power-system sizing (levers #4, #5).

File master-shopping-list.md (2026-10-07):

<!-- SPDX-License-Identifier: AGPL-3.0-only -->
<!-- © 2026 Alvin Richards -->
# TBS-001 — Master Shopping List (BoM)

**Basis:** April 2026, with catalog SKUs re-checked against supplier listings July 2026 (branded/identifiable items updated with citations; quote/fabrication/commodity items remain indicative pending real quotes). All prices USD.

Items are grouped by build area. Source documents are cross-referenced in each section header.

## Summary — Estimated Total
<!-- BEGIN costing:master-summary -->
| Area | Low | High |
|---|-----|---|
| 1. Container & delivery | $2,300 | $4,300 |
| 2. Interior conversion (light-seal, paint, ventilation) | $446 | $563 |
| 3. Pinhole optics plate | $35 | $70 |
| 4. Film plane mechanism (4-corner U-channel + acetal skate + 304 cross-slide + U-joint, incl. wall-seat saddles) | $4,098 | $4,556 |
| 5. Print washing — water system (incl. IBC stacking frame) | $6,875 | $8,166 |
| 6. Electrical — power, circuits, wiring | $3,416 | $3,502 |
| 7. Housed revolving-door light lock (plastic-skin custom fabrication) | $3,144 | $4,155 |
| 7a. Panel swing pivot + fixed door frame (Ø89 post + bearings + cage + wall stays + rail saddles + door frame) | $1,250 | $1,730 |
| 7b. Perimeter walkway (4 sections + drum-exit punch-out) | $2,088 | $2,950 |
| 7c. Hinged panel structure (stepped frame + HDPE skins + Al core + EPDM + cam latches + B2 bay + pull handle) | $1,244 | $1,457 |
| 7d. Chemistry prep shelf (fold-down board + steel frame + hinge/stays + TAP-01 trunk extension) | $267 | $279 |
| 8. Cooling & ventilation | $748 | $898 |
| 9. Printmaking chemistry — cyanotype, 50 prints (Low = Lean, High = Rich tier) | $1,250 | $3,100 |
| 10. Printmaking tools & consumables | $350 | $500 |
| 11. Safety & PPE | $120 | $180 |
| **TOTAL (base build + 50-print run)** | **~$27,631** | **~$36,406** |
<!-- END costing:master-summary -->

*Optional additions: electric film plane actuation (+$827), lens plate (+$400–$1,500), self-haul transport (+$30,000–$40,000).*

*Line 9 (printmaking chemistry) is the **Mike Ware New Cyanotype** recipe (ferric ammonium oxalate sensitizer) with the corrected ~$300 substrate, re-summed into the TOTAL: **Low = Lean ⅓-Ware (~$1,250), High = Rich full-Ware (~$3,100)**, working default Standard ½-Ware (~$1,710). The tier is pinned by the [Sensitizer Trials](sensitizer-trials.md); the TOTAL spans that Lean–Rich range ($1,250–$3,100), narrowing once a tier is locked.*

---

## Procurement BOM — by material type & supplier

*This is the consolidated **Bill of Materials** for the whole build: every purchasable item grouped
by **material type**, with quantities summed across all systems, followed by a **supplier
consolidation** table so you can place the fewest, largest orders. The *Systems* column shows where
each item is used; the full engineering detail for any item lives in that system's report. Costs are
indicative low–high estimates — get quotes before ordering.

<!-- BEGIN parts:master -->
## Procurement BOM — by material type

### adhesives-finishes

| Item | Qty | Supplier | Systems | Est. cost |
|---|-----|---|---|---|
| [2" black Gorilla Tape](https://www.homedepot.com/p/316372144) (106718) | 6 roll | Home Depot | film | $60 |
| [3M Scotch-Weld DP8010 structural adhesive (green, 45 mL)](https://www.mcmaster.com/7467A36/) (7467A36) | 1 ea | McMaster-Carr | lightlock | $76 |
| Anodize — front plate + ring (service) | 1 job | Pac-Nor Anodizing | front-board | $40–$80 |
| [Dielectric grease, marine-grade (terminal protection)](https://www.amazon.com/dp/B0D6R543V2) (B0D6R543V2) | 1 ea | Amazon | electrical | $9 |
| Door perimeter weatherstrip + threshold | 1 lot | Home Depot | interior | $10–$22 |
| Flat black paint (RAL 9005) | 1 qt | Local fab | panel | $10–$20 |
| GRP grating edge-seal kit | 1 kit | Fibergrate | walkway | $40–$60 |
| [Interior matte-black paint](https://www.homedepot.com/p/316173659) (PR31301) | 5 gal | Home Depot | interior | $125 |
| [Loctite PL Premium construction adhesive](https://www.homedepot.com/p/319654545) (1390595) | 2 tube | Home Depot | tray | $12 |
| Matte-black interior finish | 1 ea | Local fab | lightlock | $40–$70 |
| Ply edge sealer + lip fixings | 1 lot | Hardware store | shelf | $10 |
| Primer + paint | 1 lot | Hardware store | ibc-frame | $30–$50 |
| [Silicone bead sealant (black, UV-stable)](https://www.homedepot.com/p/331895623) (RDX1001bl) | 1 ea | Home Depot | lightlock | $20 |
| Thread seal tape (PTFE) | 4 roll | Home Depot | water | $8 |
| **adhesives-finishes subtotal** | | | | **$490–$622** |

### aluminum

| Item | Qty | Supplier | Systems | Est. cost |
|---|-----|---|---|---|
| [1"×1"×1/8" Al angle, 8 ft — corner-zone stiffener grid](https://www.grainger.com/product/2EYP1) (2EYP1) | 4 ea | Grainger | panel | $49 |
| 1×1×1/8in 6061-T6 Al angle — channel-support beams (×4) + rivets | 4 4ft | Metals Depot | lightlock | $69 |
| 25×25×3 6061-T6 Al angle — 2 rim rings (rolled R427) | 1 lot | Online Metals | lightlock | $45–$90 |
| [6061-T6 AL plate 3/16" (5mm)](https://www.metalsupermarkets.com/product/aluminum-sheet-6061/) (6061-sheet-12x20x0.1875) | 1 ea | Metal Supermarkets | spray | $125 |
| [6061-T6 AL round tube 25mm OD × 2mm wall, 8 ft](https://www.mcmaster.com/9056K36-9056K122/) (9056K36) | 1 ea | McMaster-Carr | spray | $64 |
| [6061-T6 Al U-channel depth rail 3×1½"×0.2" (76×38mm), 8 ft](https://www.grainger.com/product/795M51) (795M51) | 4 ea | Grainger | film | $328 |
| 6063-T5 Al U-channel — rotating-drum opening-edge stiffeners (×2) + rivets | 1 lot | Online Metals | lightlock | $30–$55 |
| 8mm 6061-T6 aluminum plate — 2 drum caps (Ø755) | 1 lot | Online Metals | lightlock | $400–$700 |
| [Aluminum angle 2"×2"×1/8" (6061-T6, plain) — 16 ft lengths](https://www.onlinemetals.com/en/buy/aluminum/2-x-2-x-0-125-aluminum-angle-6061-t6/pid/987) | 3 16 ft length | Metal Supermarkets | film | $528 |
| Aluminum U-channel, 1/8-panel (per meter) | 40 m | Online Metals | panel | $120–$200 |
| [Anodized-Al straight-flange holder for the #4 wiper brush (×4 lines)](https://www.tanisbrush.com/products/strip-brush/strip-brush-holders) (AH400436) | 4 8ft | Tanis Brush | lightlock | $72–$160 |
| Arm-to-stud adapter, turned 6061-T6 AL (anodized) | 1 ea | Local machine shop | spray | $12–$18 |
| [Eagle Al H-divider — opening-edge H-mullions (×4)](https://eagle-aluminum.com/product/aluminum-h-divider-1-38-for-316-material/) (SGN-113) | 4 12ft | Eagle Aluminum | lightlock | $152 |
| ICP-01 front-plate stock — 6061-T6 round bar Ø190×22 | 1 ea | Metal Supermarkets | front-board | $22 |
| ICP-03 retaining-ring stock — 6061-T6 | 1 ea | Metal Supermarkets | front-board | $8 |
| [Telescoping aluminum pool pole, 4–8 ft](https://www.amazon.com/dp/B0FHPSPD4T) (B0FHPSPD4T) | 1 ea | Amazon | spray | $15 |
| **aluminum subtotal** | | | | **$2,039–$2,583** |

### bearings-motion

| Item | Qty | Supplier | Systems | Est. cost |
|---|-----|---|---|---|
| [1-1/4" OD acetal load rollers — Delrin rod (cut ×8)](https://www.mcmaster.com/8576K23-8576K232/) (8576K23) | 1 1 ft rod | McMaster-Carr | film | $11 |
| [3/4" OD acetal keeper rollers — Delrin rod (cut ×8)](https://www.mcmaster.com/8497K276-8497K273/) (8497K276) | 1 4 ft rod | McMaster-Carr | film | $15 |
| [Acetal roller wheels ×4 (Delrin rod stock, Ø32×20, Ø10 bore)](https://www.mcmaster.com/8576K23/) (8576K23) | 1 1 ft rod | McMaster-Carr | spray | $11 |
| [Belden SSNBUJ750x3/8KB needle-bearing U-joint (3/8" keyway bore, 45deg, SS, booted)](https://www.grainger.com/product/BELDEN-Universal-Joint-Stainless-41D816) (41D816) | 4 ea | Grainger | film | $1,009 |
| [iglide J flange bushing, Ø90 bore (JFM-9095-100)](https://www.igus.com/iglide-ibh/flange-bearings/product-details/iglide-j-m?artnr=JFM-9095-100) (JFM-9095-100) | 2 ea | igus | swing | $261 |
| [M12 rod-end bearing (uxcell SA12TK, 4-pack)](https://www.amazon.com/uxcell-SA12TK-Bearing-M12x1-75-Self-Lubricating/dp/B0C7N16RQ9) (B0C7N16RQ9) | 1 4-pack | Amazon | spray | $20 |
| [McMaster 4040N12 304 shaft support](https://www.mcmaster.com/4040N12/) (4040N12) | 4 ea | McMaster-Carr | film | $232 |
| [SKF 6215-2RS1 sealed bearing](https://bearingsdirect.com/6215-2rs-ball-bearing-75x130x25-sealed-6215-2nse/) (6215-2RS) | 2 ea | Bearings Direct | lightlock | $121 |
| [Thrust ball bearing, 51118 (Ø90 bore, single-direction)](https://bearingsdirect.com/51118-thrust-ball-bearing-90x120x22-grooved-ubc-usbc/) (51118) | 1 ea | Bearings Direct | swing | $80 |
| **bearings-motion subtotal** | | | | **$1,759** |

### chemistry-reagents

| Item | Qty | Supplier | Systems | Est. cost |
|---|-----|---|---|---|
| [Ammonium dichromate](https://artcraftchemicals.com/products/ammonium-bi-dichromate-part-1022) | 1 run | Artcraft Chemicals | chemistry | $25 |
| [Ferric ammonium oxalate (AmFe)](https://artcraftchemicals.com/products/ferric-ammonium-oxalate-part-1684?variant=42896857825527) | 17.1 kg | Artcraft Chemicals | chemistry | $1,098 |
| [Potassium ferricyanide](https://artcraftchemicals.com/products/potassium-ferricyanide-part-1275) | 5.7 kg | Artcraft Chemicals | chemistry | $291 |
| **chemistry-reagents subtotal** | | | | **$1,414** |

### container

| Item | Qty | Supplier | Systems | Est. cost |
|---|-----|---|---|---|
| 20 ft ISO container — CW (cargo-worthy) grade | 1 ea | containermgt.com | container | $2,000–$3,500 |
| **container subtotal** | | | | **$2,000–$3,500** |
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

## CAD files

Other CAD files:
models/construction.skp
models/electrical.skp
models/film-plane-mechanism.skp
models/ibc-stack.skp
models/lighttrap.skp
models/mini-tbs.skp
models/overview.skp
models/pinhole-disc-holder.skp
models/spraybar.skp
models/walkway.skp
models/water.skp

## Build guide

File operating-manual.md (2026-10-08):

<!-- SPDX-License-Identifier: AGPL-3.0-only -->
<!-- © 2026 Alvin Richards -->
# Operating Manual — TBS-001

**The Big Shoebox Project — Camera No. 1**
Single-operator workflow for cyanotype on cotton muslin.

> **Before you begin:** Read this manual end-to-end once before your first deployment. Each phase has a time estimate and a GO/NO-GO checkpoint. Do not proceed past a checkpoint unless all conditions are met.

## Quick Reference
| Phase | What | Time |
|---|---|---|
| 0 | Pre-departure (home/workshop) | ~2 hours |
| 1 | Site setup | ~1.5 hours |
| 2 | Load image plane (red light) | ~45 min |
| 3 | Exposure | ~30–45 min (baseline) |
| 4 | Development | ~20 min |
| 5 | Cleanup and close-down | ~30 min |
| **Total** | **First print, ideal conditions** | **~5–5.5 hours** |

Baseline exposure is **30–45 minutes** under direct full sun, ISO equivalent ~2–4. See the [Exposure Adjustment Table](#exposure-adjustment-table) for cloud cover and time-of-day corrections.

## Phase 0 — Pre-Departure
**Time: ~2 hours. Complete the day before or morning of shoot day at your workshop/home.**
**Lighting: normal white light throughout this phase.**

### 0.1 Water System
The water system has three circuits (Blue/Brown/Black), pumps on the plumbing panel in the IBC plumbing corridor (P-01 Blue supply, P-02 Brown filter feed, P-04 tray-sump transfer, plus the P-05/P-03 Brown/Waste drain pumps), and four 1,000L IBC totes in a 2×2 stack. All IBCs use DN50 butterfly valves facing the plumbing corridor; all tote-top connections are **side-entry near the top** (no top-cap access — only <!-- BEGIN fact:ibc_ceiling_clearance_mm -->52<!-- END fact:ibc_ceiling_clearance_mm -->mm of headroom). The X1 fill line tees inside the corridor to fill both Blue totes (IBC-1 and IBC-2) in parallel via side-entry near the top. A check valve (CV-1) on the X1 fill line prevents backflow on the gravity fresh-fill; the pump-driven X3/X4 drains rely on the Shurflo pumps' integral check valves (CV-2/CV-3/CV-4 dropped as redundant). External fill (X1) and drain (X3/X4) ports on the sealed end wall allow resupply and disposal without opening the cargo doors.

- [ ] 0.1.1 — Fill the Blue totes via external bulkhead port X1 (minimum 400 liters total for one print). X1 tees internally to fill both IBC-1 and IBC-2 in parallel. Confirm Brown IBC-3 and Waste IBC-4 are empty or have capacity.
- [ ] 0.1.2 — Open isolation valve V1 (fill line) and VB1, VB2, VB3 (Blue outflow manifold). Prime P-01 by hand-filling the filter housing wet side.
- [ ] 0.1.3 — Switch on P-01 Blue pump (circuit C). Pressure should reach 2.5–3.5 bar within 30 seconds.
- [ ] 0.1.4 — Check all pipe joints for drips. Tighten any fittings that are weeping.
- [ ] 0.1.5 — Run water through the spray bar for 60 seconds. Check spray pattern is even across the full image plane width.
- [ ] 0.1.6 — Switch P-01 OFF.
- [ ] 0.1.7 — Confirm P-04 suction pickup tube is seated in the sump well and the suction hose is connected over the tray rim to the pump manifold. Set 3W-DV-02 (on P-04 discharge) to route toward IBC-3 (Brown). P-04 draws used wash water from the sump and lifts it to IBC-3 via a side-entry near the top. Switch on manually after each wash cycle. (The tray and pickup tube are permanently installed between the film plane rails.)

### 0.2 Chemistry — Part A (Ammonium Iron(III) Oxalate)
**Lighting: WHITE LIGHT — Part A is not light-sensitive in dry or dissolved form.**

> **⚠ RECIPE NOT YET LOCKED — see [Sensitizer Trials](sensitizer-trials.md).** Quantities use the
> **Mike Ware New Cyanotype** ratio (AmFe : ferricyanide = **3 : 1**) over the **9.42 m² active
> plane, TWO wet-on-wet coats** (§2.5), at the sourced muslin coverage **~120 ml/m²/coat →
> ~2.3 L working sensitizer per print**. The **concentration tier is the open variable** — it
> swings chemistry cost and print count by **~3×** across the three tiers. Three alternatives are given for costing/trialling.
> **Default: Standard (½-Ware)** until the trial decides.

Prepare Part A in **warm water (50–60°C)** — AmFe does not dissolve cold. Part A holds all the
iron and is ~half the working volume (mixed 1:1 with Part B, §2.1).

| Tier (per print) | AmFe (dry) | Part A water (warm) | mixed strength | AmFe for 50 prints |
|---|---|---|---|---|
| Lean (⅓-Ware) | <!-- BEGIN costing:om-amfe-g-lean -->228<!-- END costing:om-amfe-g-lean --> g | ~1.15 L | 10 g/100 ml | <!-- BEGIN costing:om-amfe-kg-lean -->11.4<!-- END costing:om-amfe-kg-lean --> kg |
| **Standard (½-Ware) — default** | **<!-- BEGIN costing:om-amfe-g-standard -->342<!-- END costing:om-amfe-g-standard --> g** | **~1.15 L** | **15 g/100 ml** | **<!-- BEGIN costing:om-amfe-kg-standard -->17.1<!-- END costing:om-amfe-kg-standard --> kg** |
| Rich (full-Ware) | <!-- BEGIN costing:om-amfe-g-rich -->684<!-- END costing:om-amfe-g-rich --> g | ~1.15 L | 30 g/100 ml | <!-- BEGIN costing:om-amfe-kg-rich -->34.2<!-- END costing:om-amfe-kg-rich --> kg |

- [ ] 0.2.1 — Heat water to 50–60°C (a kettle left to stand for 2 minutes after boiling is ideal).
- [ ] 0.2.2 — Weigh AmFe into a mixing jug.
- [ ] 0.2.3 — Pour warm water over the AmFe. Stir continuously until fully dissolved — the solution turns pale yellow-green and is clear, not cloudy. This may take 3–5 minutes.
- [ ] 0.2.4 — Allow to cool to room temperature.
- [ ] 0.2.5 — Label the jug **PART A — AmFe (WARE)**. Store in a sealed dark bottle.

### 0.3 Chemistry — Part B (Potassium Ferricyanide + Ammonium Dichromate)
**Lighting: WHITE LIGHT — Part B is not light-sensitive on its own.**

Part B holds the ferricyanide (at ⅓ of the AmFe mass — Ware's 3:1 ratio) plus the ammonium
dichromate contrast agent, in ~half the working volume. Dichromate is dosed as a **% of the total
working volume**, so it is the same across strength tiers — Ware's baseline is **0.1%**, increase
for more contrast (trial **T3**: 0.1% / 0.2% / 0.4%).

| Tier (per print) | Potassium ferricyanide | Ammonium dichromate (0.1–0.4%, trial) | Part B water |
|---|---|---|---|
| Lean (⅓-Ware) | <!-- BEGIN costing:om-ferri-g-lean -->76<!-- END costing:om-ferri-g-lean --> g | 2.6–10.4 g | ~1.15 L |
| **Standard (½-Ware) — default** | **<!-- BEGIN costing:om-ferri-g-standard -->114<!-- END costing:om-ferri-g-standard --> g** | **2.6–10.4 g** | **~1.15 L** |
| Rich (full-Ware) | <!-- BEGIN costing:om-ferri-g-rich -->228<!-- END costing:om-ferri-g-rich --> g | 2.6–10.4 g | ~1.15 L |

- [ ] 0.3.1 — Weigh potassium ferricyanide and ammonium dichromate into a second jug.
- [ ] 0.3.2 — Add water (room temperature). Stir until fully dissolved — the solution turns bright orange-red.
- [ ] 0.3.3 — Label the jug **PART B — KFe + AmDichr**.

> **⚠ Ammonium dichromate** is a Category 1A carcinogen. Wear nitrile gloves when handling dry powder. Do not inhale dust. The small quantity used here (~10g per print) is well within safe handling range for a ventilated workspace.

> **Storage:** Part A and Part B stock solutions keep for 6–8 weeks in sealed dark bottles. Mixed together (the working sensitizer), shelf life is 4–6 hours. Mix only what you need per session.

### 0.4 Equipment Checklist
- [ ] 0.4.1 — Nitrile gloves (minimum 4 pairs)
- [ ] 0.4.2 — 18" foam roller + roller tray (two sets — one per coat pass)
- [ ] 0.4.3 — 2 × 2-liter mixing jugs (graduated)
- [ ] 0.4.4 — Funnel and stirring rod
- [ ] 0.4.5 — Digital scale (1g resolution)
- [ ] 0.4.6 — Digital hygrometer
- [ ] 0.4.7 — Pre-cut muslin in light-safe bag (unbleached cotton, <!-- BEGIN fact:muslin_cut_width_mm -->4,249<!-- END fact:muslin_cut_width_mm --> × <!-- BEGIN fact:muslin_cut_height_mm -->2,000<!-- END fact:muslin_cut_height_mm -->mm — cut to fit the washable tray area, clear of the rims + near-rim sump; clamped inboard on the ACM, no hem)
- [ ] 0.4.8 — Part A bottle (sealed, labeled)
- [ ] 0.4.9 — Part B bottle (sealed, labeled)
- [ ] 0.4.10 — Timer (phone or dedicated)
- [ ] 0.4.11 — Spirit level
- [ ] 0.4.12 — Black silicone sealant + gaffer tape (light-leak repair)

### 0.5 Container Pre-Check (if accessible)
- [ ] 0.5.1 — Inspect interior: no water ingress or condensation on image plane.
- [ ] 0.5.2 — All seals (door perimeter, neoprene cord) are intact.
- [ ] 0.5.3 — Film plane mechanism moves freely on all four corners.
- [ ] 0.5.4 — Install perimeter walkway grating sections onto wall-cantilevered brackets around all 4 sides of the processing tray. Near, far, and right grating panels lift onto bracket arms and are secured with grating clips. The left walkway (cargo door end) is a removable lift-out section — it rests on 5 floor-leg cantilever brackets bolted to the bare floor outside the tray (the three brackets at the drum-exit punch-out reach further inboard than the rest; the hinged panel occupies this end wall). Left corners use butt joints (no miter) so near/far walkways start clear of the door-end panel swing sweep. The left walkway grate must be removed before the panel swings to its transport position; the floor brackets stay bolted. No contact with the tray (brackets sit on bare floor outside it).
- [ ] 0.5.5 — Lay fresh 6-mil black LDPE containment liner over the tray surface, overlapping 50mm over the rims.

**GO/NO-GO checkpoint:** Water system tested and IBCs filled. Part A and Part B prepared and sealed. All equipment packed. Container interior inspected (if accessible).

## Phase 1 — Site Setup
**Time: ~1.5 hours. Complete on arrival at site.**
**Lighting: normal white light / daylight.**

### 1.1 Site Selection
- [ ] 1.1.1 — Ground is level to within 5° (use a spirit level on the container floor after delivery).
- [ ] 1.1.2 — Subject is visible from the pinhole wall — nothing blocking the view within 5m.
- [ ] 1.1.3 — Shade structure can be erected over the container (trees, canopy, building shadow).
- [ ] 1.1.4 — Solar panel deployment area: clear southern exposure, ~4m × 3m.
- [ ] 1.1.5 — Water source within 20m, or tanker access for IBC tote fill (if not pre-filled).
- [ ] 1.1.6 — Emergency vehicle access not blocked by container placement.

### 1.2 Container Positioning
- [ ] 1.2.1 — Direct the delivery driver to position the container with the **cargo doors at 90 degrees from the subject**. The pinhole wall faces the subject.
- [ ] 1.2.2 — Once set down, check level. Use 50mm timber sleepers under corner castings to correct — up to 50mm height difference is manageable without shimming the mechanism.
- [ ] 1.2.3 — Open cargo doors and inspect interior (if not done in Phase 0.5).

### 1.3 Mode Conversion — Transport to Operational
**Time: ~5 minutes. Single-person operation.**

The container arrives in transport mode: the stepped hinged panel is swung ~56° inboard about the vertical pivot post and held by the top + bottom wall stays; the two left film rails (TL + BL) and the left walkway have been struck/removed. Convert to operational mode before proceeding.

The two end states — transport (panel + drum swung 56°, doors closed) and operational (panel latched at the door plane, X=0) — are shown in plan at the cargo-door end:

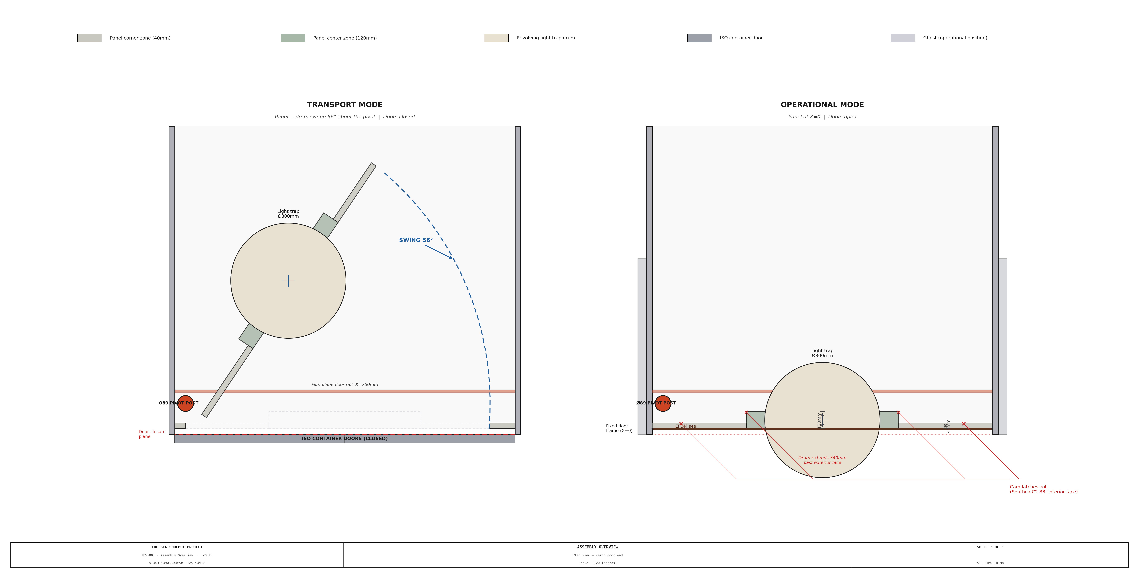
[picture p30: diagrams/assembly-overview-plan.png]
Cargo-door end — Transport vs Operational (56° panel swing)


- [ ] 1.3.1 — Open and secure the cargo doors.
- [ ] 1.3.2 — Release the top + bottom wall stays: slack the turnbuckles and unhook the rods from the near-wall eyes.
- [ ] 1.3.3 — With the panel still swung clear of the door plane, retrieve the evaporative cooler from near-walkway stowage (release 2 ratchet straps) and carry it out through the door opening (~20 kg dry, one person).
- [ ] 1.3.4 — Place the cooler on the ground outside the container, adjacent to the pinhole wall near the Ø200mm duct penetration. Remove the weatherproof cap from the wall stub. Connect the Ø200mm flex duct from the cooler outlet to the wall stub collar and secure with a hose clamp. Fill the reservoir (~18 L, one tankful) from the Blue circuit at TAP-01 on the pinhole wall — doors are open at this stage, so draw at TAP-01 and carry/hose the water out to the cooler.
- [ ] 1.3.5 — Swing the frame back ~56° to the door plane (camera position), assisted. The vertical pivot is balanced at any angle (no gravity torque) — effort is only inertia + bearing friction; control momentum at the stop.
- [ ] 1.3.6 — Latch the panel to the door frame with all 4 Southco cam latches (quarter-turn, flush with panel face) — compresses the EPDM perimeter + cut seals.
- [ ] 1.3.7 — Re-fit the two left film rails (TL + BL): drop each into its saddles; the tapered dowels set the film datum; clamp down. Confirm the re-seated rails return the film plane square and planar to datum.
- [ ] 1.3.8 — Re-fit the left walkway + door-end near-deck lift-out section onto their butt-joint ends / floor-leg cantilever brackets.
- [ ] 1.3.9 — Un-pin the revolving drum (ready for personnel light-lock use).
- [ ] 1.3.10 — Perform dark-adaptation check (see step 1.4.4 below).

### 1.4 Light Trap — Revolving Drum Panel
- [ ] 1.4.1 — Confirm the hinged drum panel is closed and all four Southco cam latches are engaged (quarter-turn, flush with panel face).
- [ ] 1.4.2 — Check the EPDM perimeter gasket is seated with no gaps or folded sections.
- [ ] 1.4.3 — Rotate the drum one full revolution by hand — it should turn freely with no binding or scraping.
- [ ] 1.4.4 — Verify: step into the drum entry side and rotate through to the interior. Wait 2 minutes for dark adaptation. **No light should be visible at any baffle position.** Mark any leaks with chalk and seal with black silicone before proceeding.

> **Safety:** Do not attempt to reverse direction inside the drum — the baffles only clear forward rotation. If unsure of orientation, continue rotating forward until you exit on the intended side.

### 1.5 Solar Power System
- [ ] 1.5.1 — Deploy solar panels on south-facing ground or roof rack, angled at 30° from horizontal (optimal for Palm Springs latitude).
- [ ] 1.5.2 — Connect panels in parallel to the Victron SmartSolar MPPT 100/50 controller.
- [ ] 1.5.3 — Connect controller to battery bank (2 × 100Ah LiFePO4 in parallel). **Observe polarity.**
- [ ] 1.5.4 — Connect Blue Sea fuse block to battery positive busbar.
- [ ] 1.5.5 — Check controller display: battery voltage should read 12.6–13.2V (full charge). If below 12.0V, charge before proceeding — a depleted battery bank cannot power the cooler and water system simultaneously.
- [ ] 1.5.6 — Verify each circuit fuse is seated: A (exhaust fan), B (intake fan), C (water pumps P-01–P-04), D (safelight), E (evap cooler), F (actuators, if fitted).

> **Shore power backup:** If grid power is available at the site, connect the Victron IP65 charger to the NEMA 5-15 inlet on the container exterior. The charger maintains the battery bank automatically — leave it connected whenever shore power is available.

### 1.6 Ventilation and Cooling
- [ ] 1.6.1 — Switch ON exhaust fan (circuit A) and intake fan (circuit B). Confirm airflow — hold a piece of tissue at each duct stub; it should deflect visibly.
- [ ] 1.6.2 — **Cooling (hot climate):** Switch ON evaporative cooler (circuit E). Fill cooler reservoir. Run cooler for a minimum of **30 minutes before any operator entry** when ambient temperature exceeds 30°C. Interior should reach below 35°C before loading.
- [ ] 1.6.3 — If using shade canopy: erect before solar noon. An 80% shade cloth over the container reduces interior temperature by 15–20°C.

> **Heat safety:** Do not enter the container if the interior temperature exceeds 40°C. A digital thermometer hung inside is standard practice. In Palm Springs summer without shade, the steel container body can reach 75°C — **shade and pre-cooling are not optional in these conditions.**

### 1.7 Walkway and Tray (if not done in Phase 0.5)
- [ ] 1.7.1 — Install perimeter walkway grating sections (see 0.5.4 for full procedure).
- [ ] 1.7.2 — Lay fresh LDPE containment liner (see 0.5.5).

### 1.8 Light-Leak Inspection
- [ ] 1.8.1 — Latch the drum panel (all four Southco cam latches engaged).
- [ ] 1.8.2 — Switch ON interior safelight (circuit D, **red LED only**). Enter through the revolving drum.
- [ ] 1.8.3 — Switch OFF safelight. Stand still for **15 minutes** minimum — full dark adaptation.
- [ ] 1.8.4 — Inspect all seams, door perimeters, and duct penetrations. Even a pinprick leak will be visible.
- [ ] 1.8.5 — Exit. Seal any leaks found with black silicone sealant or gaffer tape. Repeat inspection.

**GO/NO-GO checkpoint:** All leaks sealed. Interior temperature below 35°C. Battery bank above 12.4V. Water system pressure confirmed.

## Phase 2 — Loading the Image Plane
**Time: ~45 minutes. Entire phase performed under RED LIGHT only (circuit D).**
**Lighting: RED LED safelight. No white light, no daylight.**

### 2.1 Prepare Working Sensitizer
**Do this step just before entering — the combined sensitizer is UV-sensitive.**

| For 1 print (9.42 m² active plane, **2 wet-on-wet coats**) | Volume |
|---|---|
| Part A | ~1.15 L |
| Part B | ~1.15 L |
| **Working sensitizer** | **~2.3 L** |

> **Volume basis:** ~120 ml/m²/coat (muslin, sourced — [AlternativePhotography](https://www.alternativephotography.com/cyanotypes-on-fabric-preparing-the-fabric/) / [Jacquard](https://www.dickblick.com/products/jacquard-cyanotype-sensitizer-set/)) × **2 coats** (§2.5 is two wet-on-wet passes, not one) × 9.42 m². **Confirm by trial T1** — [Sensitizer Trials](sensitizer-trials.md). Mix 1:1 by volume.

- [ ] 2.1.1 — Pour equal volumes of Part A and Part B into a third jug. Stir gently. The mix turns yellow-green.
- [ ] 2.1.2 — Pour into the roller tray immediately.

> **The mixed sensitizer is UV-sensitive.** It is safe under red LED safelight but must not be exposed to daylight, blue sky light, or white LED light once mixed. Work quickly once inside.

### 2.2 Humidity Check
Cyanotype coating is sensitive to humidity. Check with a digital hygrometer:

| Humidity | Action |
|---|---|
| Below 30% (typical Palm Springs) | Mist the muslin lightly with plain water 5 min before coating |
| 30–65% | Coat normally |
| Above 70% | Delay — coating may not dry under safelight, increasing fogging risk |

- [ ] 2.2.1 — Check humidity and take appropriate action per table above.

### 2.3 Entering via the Light Trap
**Revolving drum entry procedure (memorize this — you will do it in dim conditions):**

- [ ] 2.3.1 — Confirm drum panel is latched (all four Southco cam latches engaged).
- [ ] 2.3.2 — Carry all equipment to the drum entry side. Set it down at your feet.
- [ ] 2.3.3 — Push the drum wall forward until the first baffle clears. Step in.
- [ ] 2.3.4 — Continue rotating forward until you exit into the container interior.
- [ ] 2.3.5 — Pass equipment through the drum in the same direction — one item at a time.
- [ ] 2.3.6 — Switch ON the safelight (circuit D switch, located on the electrical panel). **RED light only.**

> **Rule:** The drum seals automatically as it rotates — no doors to leave open. However, do not wedge equipment in the drum aperture. If a load is too large for the drum, it must be loaded during a full dark period (after sunset) with the panel unlatched and swung open.

### 2.4 Mounting the Muslin

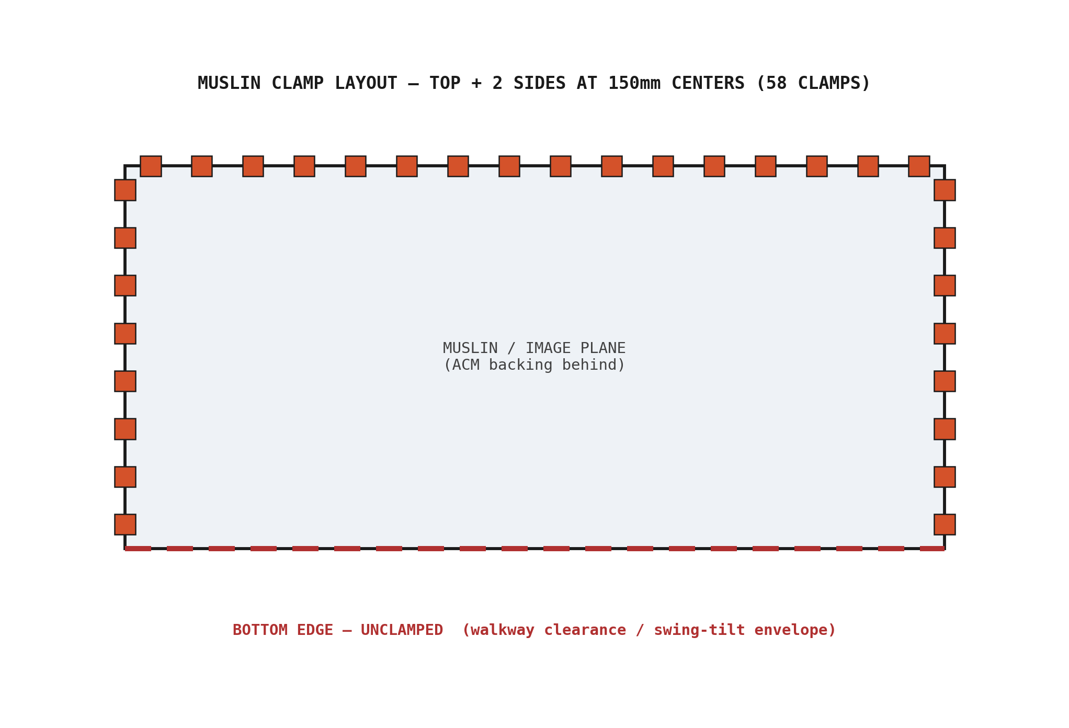
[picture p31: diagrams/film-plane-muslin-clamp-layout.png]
Muslin clamp layout — top + 2 sides at 150mm centers (58 clamps); the bottom edge is left unclamped


- [ ] 2.4.1 — Retrieve the pre-cut muslin. Confirm the HDPE filler strip is seated in the frame's L channel along the three clamped edges (it stays installed).
- [ ] 2.4.2 — Start at the **top edge**. Open each nylon spring clamp by hand and hook it over the frame edge so its swivel pads bite the muslin against the filled sandwich; the spring holds it closed with tactile feedback. Work along the top at <!-- BEGIN fact:clamp_spacing_mm -->150<!-- END fact:clamp_spacing_mm -->mm centers (30 clamps) — hanging from the top lets the fabric fall straight.
- [ ] 2.4.3 — Work down the **left and right edges** (14 clamps each), pulling the fabric taut outward from center. Total: **58 clamps** on the top + two sides.
- [ ] 2.4.4 — The **bottom edge is left unclamped** (no clamp clearance to the raised walkway; keeps the swing/tilt envelope clear). Tension the fabric downward and secure the bottom flat against the plane by the trained method, so it cannot flap when the plane tilts or swings.
- [ ] 2.4.5 — Final check: no wrinkles or sags when viewed with the safelight from 2 meters. Any slack will print as a soft zone.

### 2.5 Applying the Sensitizer
**Lighting: RED LED safelight only. Work efficiently — aim to complete coating within 20 minutes.**

- [ ] 2.5.1 — Load the foam roller with sensitizer. Roll out any excess onto scrap card — the roller should be evenly loaded, not dripping.
- [ ] 2.5.2 — **First coat:** roll horizontally from left to right across the full width of the muslin. Even strokes, 50% overlap. Work top to bottom.
- [ ] 2.5.3 — **Second coat — wet-on-wet (apply while the first is still wet):** roll vertically, top to bottom. The cross-direction second coat lays down the remaining sensitizer and evens the coverage. *Two coats is why the working volume is ~2.3 L (§2.1), not ~1.15 L — budget for both.*
- [ ] 2.5.4 — Check edges — roller tends to undercoat at the far edges. Finish with a hand-held foam brush on the last 50mm of each edge.
- [ ] 2.5.5 — Set the empty tray and roller aside. **Do not leave the roller sitting in residual sensitizer — it will skin over.**

### 2.6 Tack-Drying
**Lighting: RED LED safelight only.**

- [ ] 2.6.1 — Run the ventilation fans (circuits A and B) on **low speed** — just enough airflow to assist drying. Avoid directed airflow directly at the coated surface.
- [ ] 2.6.2 — Wait **15–20 minutes** under safelight. The sensitizer changes from wet-glossy to a matte tack-dry state.
- [ ] 2.6.3 — Confirm by lightly touching the corner of the coated area with a gloved fingertip. It should not transfer to the glove.

> **Do not proceed with a wet coat.** A wet coat will run during exposure and will not produce a sharp image.

### 2.7 Exiting via the Light Trap
- [ ] 2.7.1 — Switch OFF safelight.
- [ ] 2.7.2 — Step into the drum from the interior side. Rotate forward (same direction as entry) until you exit to the exterior.
- [ ] 2.7.3 — The drum seals behind you as it rotates.

**GO/NO-GO checkpoint:** Muslin fully clipped and taut. Sensitizer dry to touch. Drum panel latched.

## Phase 3 — Exposure
**Time: ~30–45 minutes baseline + adjustment (Ware formula). Shutter operated entirely from outside.**
**Lighting: N/A — operator is outside the container.**

### 3.1 Exposure Calculation
Baseline exposure: **30–45 minutes** in direct unobstructed sun, mid-morning to mid-afternoon, summer (Mike Ware New Cyanotype formula on cotton muslin). This is 4–8× faster than the traditional Herschel formula (~2–3 hours baseline) due to the higher UV sensitivity of ammonium iron(III) oxalate.

**Exposure Adjustment Table**

| Condition | Multiply baseline by |
|---|---|
| Full direct sun | × 1.0 |
| Thin haze / milky sky | × 1.5 |
| Broken cloud (50% coverage) | × 2.0 |
| Heavy overcast | × 4.0 |
| Early morning / late afternoon (2h before/after sunset) | × 2.0 |
| Winter sun at mid-latitude | × 1.5 |

*For compound conditions (e.g. thin haze + early morning), multiply the factors: 1.5 × 2.0 = × 3.0.*

These factors are EV-based estimates for light level changes. Cyanotype is an iron-based process and does not exhibit Schwarzschild reciprocity failure — no additional reciprocity correction is required beyond the factors above. For critical work, run a test strip first: cut a 200mm × full-height strip of coated muslin, expose in **5-minute intervals** using a card mask, develop immediately, and compare zones.

### 3.2 Opening the Shutter
- [ ] 3.2.1 — Confirm the vestibule outer door is closed and latched.
- [ ] 3.2.2 — Set a timer for your calculated exposure time.
- [ ] 3.2.3 — Open the pinhole shutter from the exterior operating handle.
- [ ] 3.2.4 — **Do not open any doors, stand in front of the pinhole wall, or allow shadows to cross the pinhole during exposure.**

### 3.3 Monitoring During Exposure
- [ ] 3.3.1 — Check the battery bank voltage on the MPPT controller display every 15 minutes. If voltage drops below 11.8V, switch off the evaporative cooler (non-essential during exposure).
- [ ] 3.3.2 — Note any significant cloud cover changes. If conditions change substantially mid-exposure (e.g. sky goes from clear to heavy overcast), close the shutter, note elapsed time, wait for conditions to return, then re-open for the remaining time.

### 3.4 Closing the Shutter
- [ ] 3.4.1 — At the calculated time, close the pinhole shutter using the exterior operating handle.
- [ ] 3.4.2 — Verify the shutter indicator reads CLOSED before entering.

**GO/NO-GO checkpoint:** Shutter confirmed closed. Elapsed time within ± 2 min of target.

## Phase 4 — Development
**Time: ~20 minutes.**
**Lighting: RED LED safelight on entry, then switch to WHITE LIGHT after first wash begins.**

### 4.1 Entering and Removing the Muslin
- [ ] 4.1.1 — Enter via light trap (same procedure as Phase 2.3). Switch safelight ON (**red light**).
- [ ] 4.1.2 — Squeeze each spring clip open to release the muslin — work top-down, supporting the fabric weight as the upper clamps release. The image is latent at this point and may be barely visible as a pale yellow ghost.
- [ ] 4.1.3 — Lay the muslin face-up on the LDPE containment sheet on the processing zone floor (optical zone, between the film plane rails).

### 4.2 Development in Water
**Lighting: switch to WHITE LIGHT (circuit D, white mode) once the first wash begins — the image is no longer UV-sensitive after initial water contact.**

Cyanotype develops by oxidation — the iron salts convert to Prussian blue on contact with water and air. The full blue color deepens over the first few minutes of drying.

**Spray bar setup:**

- [ ] 4.2.1 — Position the spray bar at the far end of the tray (Yd≈2,280mm, film-plane side). Attach the telescoping pole to the arm tube.

**Wash sequence using the Blue circuit:**

- [ ] 4.2.2 — Switch ON P-01 Blue pump (circuit C). Confirm VB1, VB2, VB3 are open.
- [ ] 4.2.3 — Set BV-05a to Blue (fresh) and open BV-05b. Using the pole, slowly pull the spray bar toward the pinhole wall (decreasing Yd), flooding the print progressively. Travel speed ~50mm/second — full traverse takes ~44 seconds. At the near rim (Yd≈80mm), close BV-05b. Push the bar back to the far end and repeat. Allow water to flow over the full surface for **5 minutes**. The wash water will run yellow-green as unreacted sensitizer clears. This is normal and non-toxic. **Switch to WHITE LIGHT now** — the print is safe once washing begins.
- [ ] 4.2.4 — Close BV-05b. Switch ON P-04 to pump wash water from the sump up to IBC-3 (Brown recovery) via 3W-DV-02. If the first rinse is heavily contaminated, set 3W-DV-02 to divert to IBC-4 (Waste) instead.
- [ ] 4.2.5 — For the second wash pass, set BV-05a to Brown (recycled), close BV-05b, and activate P-02 through the filter train. Recycled Brown water from IBC-3 is pumped through the three-stage filter skid and back into the spray bar via the same supply path. Open BV-05b and repeat the spray bar traverse.
- [ ] 4.2.6 — Repeat for a total of **3 wash cycles** (15 minutes total). Subsequent rinses route to IBC-3 (Brown) for recycling via the filter skid.
- [ ] 4.2.7 — Final rinse: set BV-05a to Blue and open BV-05b for a 2-minute final flush with clean Blue water. Drain via P-04 to IBC-3.

> **Visual check after the second wash:** The image should be clearly visible — Prussian blue shadows against a white or off-white highlight. If the image appears flat or very faint, the print was underexposed. Allow it to complete washing and dry — images that appear pale when wet frequently darken significantly on drying. If still flat after drying, re-expose for 1.5× the original time.

#### Valve matrix

| Valve | Default | Wash 1 | Drain 1→Brown | Wash 2 (recycled) | Drain 2→Brown | Wash 3 | Drain 3 |
|---|---|---|---|---|---|---|---|
| BV-01 (Blue manifold) | Open | Open | Open | Open | Open | Open | Open |
| BV-05a (spray selector) | Blue | Blue | — | **Brown** | — | Blue | — |
| BV-05b (spray on/off) | Closed | **Open** | Closed | **Open** | Closed | **Open** | Closed |
| BV-06 (Chem tap) | Closed | Closed | Closed | Closed | Closed | Closed | Closed |
| 3W-DV-02 (tray drain) | Brown | Brown | **Brown** | Brown | **Brown** | Brown | **Brown** |
| P-02 (Brown pump) | Off | Off | Off | **On** | Off | Off | Off |
| 3W-DV-01 (filter out) | Blue return | Blue | Blue | Blue | Blue | Blue | Blue |

#### Diverter valve operator decisions

The two 3-way diverter valves serve different roles in the water triage chain. Understanding when and why to switch each valve is critical to avoiding cross-contamination of the Blue clean supply.

**3W-DV-02 — Tray drain diverter (operator judgment call)**

DV-02 sits on the P-04 pump discharge and controls whether drain water from the processing tray goes to Brown (IBC-3, for filtering and potential recycling) or Black (IBC-4, waste for external disposal). There is no automated test at this valve — the operator decides based on what happened during the session:

- **Set to Brown (default):** Normal processing rinse water. The water contains only trace amounts of residual cyanotype chemistry (ferric ammonium oxalate and potassium ferricyanide) from the print surface. This water is suitable for filtering and potential recycling back to Blue.
- **Switch to Black:** Heavy contamination events — concentrated chemistry spills, failed sensitizer coating that washes off in bulk, or any situation where the drain water is visibly discolored beyond a pale yellow tint. This water goes directly to IBC-4 for external disposal and never enters the filter/recycle path.

**Rule of thumb:** If the drain water looks like rinse water (clear to pale yellow), send it to Brown. If it looks like chemistry (deep yellow, orange, or green), send it to Black.

**3W-DV-01 — Filter output diverter (pH meter reading)**

DV-01 sits after the filter skid (F1→F2→F3) and the SV-01 sample tap. After brown water has been filtered, the operator draws a ~50 ml sample at SV-01 and checks the pH reading:

- **Set to Blue return (default):** pH is between 6.5 and 8.0, indicating the filtered water is chemically neutral enough to return to IBC-2 (Blue clean supply) for reuse.
- **Switch to Black:** pH is outside the acceptable range, or the water is visibly discolored after filtering. This water goes to IBC-4 (waste) rather than contaminating the clean supply.

| Valve | Decision | Basis | Who decides |
|---|---|---|---|
| 3W-DV-02 (tray drain) | Brown vs Black | Contamination severity at drain time | Operator — visual judgment |
| 3W-DV-01 (filter output) | Blue vs Black | Water quality after filtering | Operator — pH meter reading |

### 4.3 Drying
**Lighting: WHITE LIGHT or daylight — cyanotype is no longer light-sensitive after washing.**

- [ ] 4.3.1 — After the final wash, carry the muslin outside through the light trap. Daylight exposure is safe and accelerates oxidation.
- [ ] 4.3.2 — Hang the developed muslin to dry — horizontal is ideal (prevents drip marks). Wooden poles or a rope line between two vehicles work well.
- [ ] 4.3.3 — Drying time: 20–60 minutes depending on temperature and airflow. The blue intensifies as the image oxidizes in air.
- [ ] 4.3.4 — Final color appears approximately 30 minutes after the print appears dry to the touch.

## Extended Deployment — On-Site Water Top-Up (optional)
**Lighting: normal — all top-up is external; the container stays sealed and dark.**

A single hauled Blue fill supports ~14 prints (or ~15–16 if the Blue totes were topped toward
their ~1,900–2,000L maximum before departure — see [Water System Report §4](water-system-report.md)). For
a longer stay, resupply Blue and discharge waste through the **external end-wall bulkhead ports** —
**without opening the cargo doors**, so the dark, camera-ready state is preserved and the print cycle
(Phases 2–4) simply repeats. This is a distinct mode from the single-fill deployment; it is **not**
required for a normal 1–2 print outing.

- [ ] TU.1 — Watch the **Blue low-level float (IBC-2)** alert. Plan a top-up *before* it runs dry mid-wash, not after.
- [ ] TU.2 — **Resupply Blue:** connect the water bowser/tanker hose to the external **X1** camlock inlet on the sealed end wall. Open isolation valve **V1**; X1 gravity-feeds and tees to both Blue totes in parallel (side-entry near the top). Confirm the level, then close V1 and disconnect.
- [ ] TU.3 — **Discharge Brown/Waste** when they near their working levels: connect a disposal tanker or holding tank to the **X3** (Brown) and/or **X4** (Waste) camlock ports, then run **P-05** (X3) / **P-03** (X4) to pump out. Close and re-cap the ports when done.
- [ ] TU.4 — With supply restored and collection capacity freed, resume the print cycle from [Phase 2](#phase-2-loading-the-image-plane). Print count per deployment is now set by water logistics (bowser visits, disposal access), not tote volume.

> **Before transport:** return the totes to their validated fill states — Blue drained, Waste within
> its return-haul limit — per [§5.5](#55-transport-mode-conversion-packing-up). On-site top-up does
> **not** change the transport fill limits.

## Phase 5 — Cleanup and Close-Down
**Time: ~30 minutes.**
**Lighting: WHITE LIGHT.**

### 5.1 Chemistry Disposal
- [ ] 5.1.1 — Spent wash water (yellow-green): cyanotype wash water at this dilution is non-hazardous. It is collected in IBC-3 (Brown) for recycling through the filter skid (P-02 → F-1/F-2/F-3), or diverted to IBC-4 (Waste) if heavily contaminated. Waste IBC-4 contents are drained via external port X4 to a disposal tanker. Do not dispose into storm drains without verification of local regulations.
- [ ] 5.1.2 — Unused sensitizer: seal and store in a dark bottle (4-week shelf life for separated A and B solutions). Mixed working sensitizer: discard — working life is 6 hours.
- [ ] 5.1.3 — Rinse all trays, rollers, and brushes in plain water immediately. Dried sensitizer is harder to remove.
- [ ] 5.1.4 — Stow the spray bar at either end of its travel. Detach the telescoping pole and store alongside the bar or clip to the container wall. The flexible hose coils naturally at the pinhole wall.

### 5.2 Container Ventilation
- [ ] 5.2.1 — Open both ventilation fans to full speed (circuits A and B).
- [ ] 5.2.2 — Leave ventilating for **30 minutes minimum** after development is complete, especially if working in hot conditions — the container interior will have accumulated heat and humidity from the wash operation.

### 5.3 Power-Down Sequence
Power down in this order to avoid voltage spikes on sensitive electronics:

- [ ] 5.3.1 — Evaporative cooler (circuit E)
- [ ] 5.3.2 — Water pumps P-01 through P-04 (circuit C)
- [ ] 5.3.3 — Ventilation fans (circuits A, B)
- [ ] 5.3.4 — Safelight (circuit D)
- [ ] 5.3.5 — Film plane actuators if used (circuit F)
- [ ] 5.3.6 — Disconnect solar panel inputs at the MPPT controller

If shore charger is connected, leave it running overnight to top up the battery bank.

### 5.4 Securing the Container (Operational Mode)
- [ ] 5.4.1 — Engage all four Southco cam latches on the drum panel.
- [ ] 5.4.2 — Apply secondary locking bar across the drum panel face if the container will be unattended overnight.
- [ ] 5.4.3 — Cap all ventilation duct stubs on the exterior.
- [ ] 5.4.4 — Secure solar panels — if conditions allow, lay flat or fold to minimize wind load.

### 5.5 Transport Mode Conversion (Packing Up)
**Time: ~5 minutes. Single-person operation.**

The stepped hinged panel + drum SWING ~56° inboard about the vertical pivot post for transport, riding the floor gap (clearing the processing tray rim). The two left film rails (TL + BL) and the left walkway must be removed before the swing so the drum cage can transition the left film-plane rail plane. The processing tray and the near/far/right walkway sections remain in place during mode conversion.

- [ ] 5.5.1 — End camera use: power off Fan B, finish any darkroom access. Stow all interior items; return the film-plane cross-slides to their datum.
- [ ] 5.5.2 — Park the revolving drum in its closed/aligned position and pin its rotation (detent) so it cannot flop during the move.
- [ ] 5.5.3 — Disconnect the flex duct from the wall stub collar (release hose clamp). Replace the weatherproof cap on the wall stub. Drain the cooler reservoir completely.
- [ ] 5.5.4 — Carry the cooler in through the door opening (~20 kg, one person). Place on a ply base plate on the near-walkway wide section, clear of the panel swing sweep. Secure with 2× ratchet straps to the wall brackets. Stow the flex duct alongside.
- [ ] 5.5.5 — Lift out the removable left walkway + door-end near-deck section — both sit inside the swing arc.
- [ ] 5.5.6 — Strike the two left film rails (TL + BL): release each clamp bar, lift the rail straight up out of its saddles, and stow (clipped to the near wall). *Required before the swing — otherwise the drum cage fouls the left rail plane.*
- [ ] 5.5.7 — Release all 4 Southco cam latches — releases the perimeter + cut seals.
- [ ] 5.5.8 — Swing the frame ~56° inboard (toward the far wall), assisted. Balanced about the vertical pivot (no gravity torque); control momentum at the stop.
- [ ] 5.5.9 — Engage the transport lock: connect the top + bottom wall stays — hook the rods from the frame hooks to the near-wall eyes and tension the turnbuckles.
- [ ] 5.5.10 — Close and latch the standard ISO container cargo doors. They close outboard of the fixed left panel (Yd0–180); the swung frame clears the door plane by +<!-- BEGIN fact:swung_door_clearance_mm -->29<!-- END fact:swung_door_clearance_mm --> mm.

### 5.6 Operational Mode Conversion (Setting Up)
**Time: ~5 minutes. Single-person operation. Reverse of 5.5.**

Follow the procedure in [Phase 1.3 — Mode Conversion](#13-mode-conversion-transport-to-operational). Steps are the reverse of §5.5: open cargo doors → release wall stays → swing the panel back ~56° to the door plane → latch panel → re-fit the left film rails + left walkway → place cooler on ground and connect flex duct → un-pin drum → dark-adaptation check.

## Exposure Adjustment Table
*Full reference table for use in Phase 3.*

| Baseline | 35 min | Direct full sun, summer, 10:00–14:00 (Ware formula) |
|---|---|---|
| Thin haze | 55 min | |
| Broken cloud | 70 min | |
| Heavy overcast | 140 min | |
| Early/late sun | 70 min | |
| Winter mid-latitude | 55 min | |
| Thin haze + early sun | 105 min | Multiply factors: 1.5 × 2.0 |

## Troubleshooting

| Symptom | Likely cause | Action |
|---|---|---|
| Image very faint after full drying | Underexposure | Increase time by 50% |
| Image too dark / no highlight detail | Overexposure | Reduce time by 30% on next print |
| Streaks or tide-marks | Uneven coating or drips during development | Improve roller technique; ensure even wash flow |
| Soft or blurred image | Muslin slack at coating or during exposure | Re-tension: re-seat the nylon clamps and check the bottom-edge securing; check frame is not vibrating in wind |
| Blue haze (fogging) in shadows | Light leak or sensitizer exposed to UV before loading | Re-inspect light trap; check sensitizer storage |
| Uneven color — cool/warm zones | Humidity variation across coating | Ensure even pre-misting if in dry climate |

## See Also
- [Electrical & Systems Report](electrical-report.md) — power system, light trap construction, cooling specification
- [Film Plane Mechanism](film-plane-mechanism-report.md) — image plane adjustment and setup
- [Pinhole Disc Holder (Front Board)](pinhole-disc-holder-report.md) — quick-change pinhole disc / lens swap procedure
- [Chem Shopping List](chemistry-shopping-list.md) — chemistry suppliers and quantities
- [Processing System](water-system-report.md) — water system circuit operation

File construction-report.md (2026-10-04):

<!-- SPDX-License-Identifier: AGPL-3.0-only -->
<!-- © 2026 Alvin Richards -->
# Construction Sequence — TBS-001

## 1. Purpose

This report is the **build order of record** for TBS-001 — the sequence in which the camera
is assembled inside the container, why that order is forced, and the gate that must be met
before each phase begins. The install is **geometry-first**: the large fixed masses (the IBC
totes and their frame) go in first and set the datum everything else is measured from; the
precision optical system goes in last, once the real, as-built space is known. Fabrication and
ordering for subsequent phases of the install can only be performed once the **geometry is established**.

The sequence is validated by a **phased 3D construction model** (§8) — one scene per phase,
with a click-through that reveals each step in order — so the order can be walked before any
components, steel is cut, etc.

---

## 2. Build Overview

| Phase | Name | Goal | To Be Completed |
|---|---|---|---|
| **1** | Geometry set-out | Install the fixed masses that fix the datum | IBC frame + totes plumbed and square; hinge panel hung |
| **2** | Re-measure | Capture the **as-built** space before committing hard structure | Measured clearances reconciled against the model; refactor the design based on available space |
| **3** | Framing | Fit the tray, cantilevers, plumbing, film-plane beams, walkway | Walkway + tray in; perimeter structure loaded |
| **4** | Electrical | Panels, lights, and all wiring runs | Circuits terminated + tested (Blue / Brown / Black) |
| **5** | Photo system | Film plane, pinhole mechanism, light trap | Camera light-tight and operable |

---

## 3. Sequencing Principles

- **Geometry-first.** The IBC stack + frame are the heaviest, least-movable elements and
  define the corridor and walkway datums; everything downstream references them.
- **Measure twice (Phase 2).** Container internal dimensions vary unit-to-unit; the hard
  structure is cut to the **as-built** space, not the nominal model.
- **Work from the walls inward, optics last.** Structure and services are installed while the
  tray zone is open; the film plane / pinhole / light trap go in last to stay clean and true.
- **No trapped work.** Each step leaves access for the next (e.g. plumb before the walkway
  caps the corridor). Dependency conflicts surface in the §8 click-through, not on site.

---

## 4. Phase 1 — Geometry Set-Out

**Goal:** install the fixed masses that establish the camera's internal datum.

| # | Step | Depends on | Status |
|---|---|---|:---:|
| 1.1 | Install the **IBC frame posts** (upright skeleton + feet) + **plumbing-panel backing** | — | ☐ |
| 1.2 | Install 2× IBC totes on the **pinhole wall** (near column) — dropped into the post skeleton | 1.1 | ☐ |
| 1.3 | Install the **panel equipment** (pumps/filters/valves) + **plumb the IBC corridor** (corridor lines only — *sump + supports → 3.2*) + run the filter skid's **blue recycle** and **gray waste** corridor lines to the IBC panel + run the **purple Cct-C corridor pump wiring** to the pinhole wall (*EP drop connected in 4.3*) | 1.2 | ☐ |
| 1.4 | Install **Fan A** (exhaust) + run its **Cct-A cable** along the pinhole-wall trunk and **down to the EP drop** (EP itself lands in Phase 4) — *before the far IBCs bury it* | 1.2 | ☐ |
| 1.5 | Install 2× IBC totes on the **far wall** (far column), then fit the **frame rails + retaining bars** to trap all totes | 1.4 | ☐ |
| 1.6 | Install the **hinge panel** (light-trap door — *excluding* the light-trap drum) | 1.2 | ☐ |

**Exit gate:** frame square, totes restrained, IBC plumbing pressure-checked.

---

## 5. Phase 2 — Re-measure

**Goal:** capture the **actual** space remaining after the fixed masses are in, before any
hard structure is committed.

| # | Step | Depends on | Status |
|---|---|---|:---:|
| 2.1 | **Re-measure the actual space left** — reconcile against the model; note deltas | Phase 1 complete | ☐ |

**Exit gate:** as-built clearances confirmed; designs refined; any cut-lists adjusted to the measured space.

---

## 6. Phase 3 — Framing

**Goal:** fit the load-bearing perimeter structure, the processing tray, the remaining
plumbing, the film-plane support, and the walkway.

| # | Step | Depends on | Status |
|---|---|---|:---:|
| 3.1 | Install the **pinhole-wall ply backing** (mounts the filter skid; shown as a semi-transparent, plywood-colored backdrop for the plumbing build — ghosts like all prior geometry from Phase 4 on) | Phase 2 | ☐ |
| 3.2 | Install **cantilevers on the far + right walls** | Phase 2 | ☐ |
| 3.3 | Install **cantilevers on the near wall** | 3.2 | ☐ |
| 3.4 | Lay the **under-grate ribbons** (sump line + skid ribbon legs — tray-sump→P-04 suction, DV-02 waste, P-02→ACC-02 — + pipe support beams) **and install the pinhole filter skid** (F-1..F-3 + P-04/SV-02/DV-02 + ACC-02 + skid-side plumbing; mounts to the 3.1 backing; connects to the recycle→IBC-3 + waste returns from 1.3) — *span the space, so after the beams and both cantilever sets, before the grate*; Note: Before the pipes can be glued, the walkway has to be test-fitted to locate the holes for the pipe bump-through. | 3.1, 3.2, 3.3 | ☐ |
| 3.5 | **Extend plumbing** to the pinhole-wall panel | 3.4 | ☐ |
| 3.6 | Install the **processing tray** | 3.2 | ☐ |
| 3.7 | Install the **film-plane beams** + **combined corner plates** (FP ↔ right-walkway) | 3.2 | ☐ |
| 3.8 | Install the **left cantilevers** | 3.4 | ☐ |
| 3.9 | Install the **walkway** (grating on all cantilevers) | 3.3, 3.4, 3.7, 3.8 | ☐ |

**Exit gate:** walkway decked, tray sealed, perimeter proof-loaded.

---

## 7. Phase 4 — Electrical

**Goal:** install the power panels, lighting, and all wiring runs.

| # | Step | Depends on | Status |
|---|---|---|:---:|
| 4.1 | Mount the **external power panel box** (the flanged wall-penetration box — its **E-stop** device + **PV disconnect** are fitted in 4.2) | Phase 3 | ☐ |
| 4.2 | Install the **interior electrical panel** (EP core + external links) + **E-stop** + **PV disconnect** + cabling + **batteries** | 4.1 | ☐ |
| 4.3 | **Connect the Cct-C corridor wiring to the EP** (the corridor run was pre-installed to the pinhole wall in 1.3 — this closes the EP drop) | 4.2 | ☐ |
| 4.4 | **Hang the lights** | Phase 3 | ☐ |
| 4.5 | Install **Fan B** + its **Cct-B wiring** + the **chem-prep shelf**; terminate the remaining circuit runs (Blue / Brown / Black — Fan A + Cct-A were 1.4, pump Cct-C 1.3 + 4.3, lights 4.4) | 4.2, 4.3, 4.4 | ☐ |

**Exit gate:** every circuit terminated, continuity + insulation tested, E-stops verified.

---

## 8. Phase 5 — Photo System

**Goal:** install the precision optical elements last, into the known as-built space.

| # | Step | Depends on | Status |
|---|---|---|:---:|
| 5.1 | Install the **pinhole mechanism** (plate + aperture) | Phase 3 | ☐ |
| 5.2 | Install the **film plane + carriages** (screen + frame; the beams were 3.7) | Phase 3 (beams), 5.1 | ☐ |
| 5.3 | Install the **light-trap drum support cage** + axle beams + SKF 6215 bearings + mount plates + floor HDPE | Phase 1 (panel), 5.2 | ☐ |
| 5.4 | Hang the **light-trap HDPE skins** — rotating drum shell + fixed Ø800 housing panels + H-mullions | 5.3 | ☐ |
| 5.5 | Fit the **light-trap outer HDPE surround / bay** (walls + roof) + cage rivets | 5.4 | ☐ |
| 5.6 | Install the **spray bar** (over the processing tray) | Phase 3 (tray) | ☐ |

**Exit gate:** plane travels through its full tilt/swing envelope; spray bar movement is free; camera confirmed light-tight.

---

## 9. Construction Model (3D, phased)

The build order is verified by a dedicated **phased 3D model** — the same component builders
as the Overview 3D model, staged by install order:

- **One scene per built phase** (Phases 1, 3, 4, 5) — the model shown at the end of that phase. Phase 2
  (re-measure) adds no geometry, so it has no scene; its state is the Phase-1 scene (what you measure).
- **Click-to-build within a scene** — a Dynamic Component reveals each step's geometry in
  order on click, so the assembly can be watched building up and the sequence checked for
  trapped work / access conflicts before the real build.

With the Interact tool, each phase scene opens showing only its first step; each click reveals the
next in install order (drag to orbit, scroll to zoom). Model-generation internals are documented in
[component-dependency-map.md](component-dependency-map.md) §3.1 (the `construction` model row).

<!-- brochure:skip -->
<div class="sketchfab-embed-wrapper">
  <div style="position:relative;width:100%;padding-bottom:56.25%;">
    <iframe title="TBS-001 Construction Sequence" frameborder="0" allowfullscreen mozallowfullscreen="true" webkitallowfullscreen="true" allow="autoplay; fullscreen; xr-spatial-tracking" execution-while-out-of-viewport execution-while-not-rendered web-share src="https://sketchfab.com/models/dcc54fb3d02e46c3ab070dd49adc5d1e/embed" style="position:absolute;top:0;left:0;width:100%;height:100%;border:0;"></iframe>
  </div>
  <p style="font-size: 13px; font-weight: normal; margin: 5px; color: #4A4A4A;"><a href="https://sketchfab.com/3d-models/tbs-001-construction-sequence-dcc54fb3d02e46c3ab070dd49adc5d1e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" target="_blank" rel="nofollow" style="font-weight: bold; color: #1CAAD9;">TBS-001 Construction Sequence</a> by <a href="https://sketchfab.com/alvin91403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" target="_blank" rel="nofollow" style="font-weight: bold; color: #1CAAD9;">alvin91403</a> on <a href="https://sketchfab.com?utm_medium=embed&utm_campaign=share-popup&utm_content=dcc54fb3d02e46c3ab070dd49adc5d1e" target="_blank" rel="nofollow" style="font-weight: bold; color: #1CAAD9;">Sketchfab</a></p>
</div>
<!-- brochure:endskip -->

## See Also

- [Water System](water-system-report.md) · [Electrical](electrical-report.md) — the systems installed across the phases
- [IBC Stacking System](ibc-stacking-report.md) — the frame erected in Phase 3
- [Plywood Cut Sheets](plywood-cut-sheets.md) — the panel cut plan for the fit-out

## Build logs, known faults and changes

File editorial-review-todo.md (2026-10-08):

<!-- SPDX-License-Identifier: AGPL-3.0-only -->
<!-- © 2026 Alvin Richards -->
<!-- Working/internal tracker — NOT registered in publish.sh (not published). -->
# Editorial Review TODO — remove diagram-encapsulated detail from the reports

**Purpose:** the reports repeat dimensional detail that the **diagrams already carry** (Z-positions,
mm coordinates, bolt PCDs, exact placements). Repeated data is data that can drift. Systematically
review each `.md` and move that detail to the diagram-of-record, keeping the prose about intent.

**Remove from prose** (the diagram is the source of record):
- Exact Z heights / mm coordinates / X-positions of parts
- Bolt PCDs, hole patterns, fastener positions, clearances given as raw numbers
- Anything a reader would verify by *measuring the drawing*, not reading the text

**Keep in prose:**
- Design intent, rationale, trade-offs, the "why"
- Sourced engineering claims (with their hyperlinks)
- Part numbers / specs / suppliers needed for procurement
- Headline figures that define the system (focal length, f-number, image-plane size)

**How:** replace a repeated coordinate with a pointer — "see [<diagram>] (sheet N)". When a number is
also a `tbs_constants` value or a `costing.py`/`facts.yml` fact, prefer the reference so it can be linted.

---

## A. Engineering reports (primary targets — most likely to repeat dimensions)

- [x] container-report.md  — *DONE (2026-06-24): Part 4A layout was stale + self-contradictory — pinhole center X=2,946 (full-length center) → canonical X=2,399 (active-FP center); the 'equipment=left third / optical=right two-thirds' framing contradicted its own IBC-at-right row → rewritten as light-trap (far left) + IBC/pumps (far right), clear optical zone in the center (author later dropped the X-span column → 2-col Zone/Contents). Exposure Times + Part 7 summary carried old traditional-Herschel cyanotype (ISO ~0.5, ~2.6 hr / ~2–3 hr / ~13 hr) → updated to Mike Ware New Cyanotype (ISO ~2–4, ~30–45 min at f/1088, NO Schwarzschild correction — iron process; Proposal 3 ~2.5–4 hr at f/2467) and added the missing Proposal-3 cyanotype row. Single-sourced Ø2.17mm → pinhole_diameter_mm and f/1088 → f_number (Part 4A + Proposal 2; left Proposal 1 derivation rows + Proposal 3's distinct 4.87mm/f/2467 raw). Spelling: sensitised→sensitized, suplements→supplements; Proposal 3 image plane 2,337→2,362mm. Sources hyperlinked (Boxhub/ContainerMgt/IronPlanet, OSHA Table Z-1, ISO 1496-1 replacing the unverifiable 'Container Home Builders Association'); pricing relabeled 2025→2026; dropped 'rev9/B2 swap' archaeology. ALL fixes had been mirrored into the near-duplicate pinhole-camera-construction.md. Editorial + drift gates pass. **UPDATE 2026-07-03: now the SOLE canonical container doc — pinhole-camera-construction.md was retired into it (§C dedup, the call); container-report absorbed the Construction Guide's home-page index row and all its inbound links.***
- [x] pinhole-report.md  — *DONE (2026-06-23): clean to start (header/footer, editorial_lint, all sources hyperlinked, no costs). Single-sourced the two Key Optical Constants that were restated raw and un-policed (the tight facts.yml aliases didn't reach these phrasings): Ø2.17mm pinhole aperture ×4 → pinhole_diameter_mm; f=2,362mm focal length → focal_length_mm. Rest is detail dims (bore sizes, bolt patterns, dowel/seal/fit geometry) — left as diagram-of-record.*
- [x] pinhole-camera-construction.md  — *RETIRED (2026-07-03): was ~97% identical to container-report.md (only 18 lines differed — this doc's front-matter + coordinate-in-prose that container-report had already stripped) — a §C duplication maintained as two published pages. the call: retire one, keep container-report.md as the single canonical container doc. Redirected all inbound links → container-report.md (project-summary table row, pinhole-option-b-optics preceding-docs, project-cost-breakdown ×3 source-doc refs); removed from publish.sh + setup_docs nav; gave container-report the home-page index row it lacked (and dropped a duplicate 'Pinhole Report' index row spotted en route). File deleted.*
- [x] pinhole-optics-report.md  — *DONE (2026-06-24): the doc is the facts.yml owner of focal_length/pinhole_diameter/f_number but only ever sized a generic 20'×7' survey camera — added a 'TBS-001 As Built (Orientation B)' block to Part 11 (focal 2,362mm = container width, pinhole 2.17mm, f/1088, full plane 5,893×2,388 / active 4,389×2,388 ~113 sq ft, 102° FOV, 0.69 lp/mm, ~30–45 min cyanotype) — all as fact: placeholders, so the owner doc now carries its owned values. Part 5: added worked exposure numbers (f/1000 indicative → 39 sec film → ~11 min calc / ~25 min reciprocity-corrected paper) + a new 'Cyanotype Speed (Mike Ware New Cyanotype)' subsection (ISO ~2–4, no Schwarzschild correction → ~16–33 min). Project name 'Giant Pinhole Camera Project' → 'The Big Shoebox Project (TBS-001)'; dropped the 'Working Document — Sources Being Verified' / 'in progress' disclaimer; hyperlinked the 6 bare Part 12 citations (Born&Wolf/Hecht/Stroebel/Renner/Peterson → catalog; Schwarzschild → NASA ADS; Ware added #13) and fixed the Rayleigh 'DOI search:' dead-end; thousands-separators made consistent across the format tables. Editorial + drift gates pass.*
- [x] pinhole-option-b-optics.md  — *DONE (2026-06-24): already had focal_length/container_width as placeholders; wrapped the remaining canonical optical values that were raw — Camera Parameters table + Part 8 comparison + line-206 restatement: pinhole 2.17mm → pinhole_diameter_mm, f/1088 → f_number, image plane 5,893 → container_interior_length_mm, 2,388 → film_plane_height_mm (Proposal 3's 4.87mm/f/2467 and all formula/derivation occurrences left raw as diagram-of-record). Hyperlinked the 3 bare Citations rows (Rayleigh → Taylor & Francis, Born&Wolf → catalog, ISO 668 → CHS). Fixed Part 8 near-DoF arithmetic: c=6mm Proposals 1/2/4 1.5→1.3 m, and TWO Proposal-3 errors that didn't reproduce from f=12,013/d=4.87 (c=6mm 25.8→51.8 m, c=10mm 12.4→11.4 m). Header 'Preceding documents' raw filenames → linked titles. Editorial + drift gates pass. (Residual: section titled 'Citations' not 'Source References' — systemic advisory across many docs.)*
- [x] film-plane-mechanism-report.md  — *DONE (2026-06-23): single-sourced the system-defining geometry that was restated raw — §2 reference table (length 5,893 → container_interior_length_mm, width 2,362 → focal_length_mm, height 2,388 → film_plane_height_mm), §3 single-axis maxima (40°/28° → film_plane_max_tilt/swing) + 4,499 width, §4 plane size 4,499×2,388 (×2). §7 materials total wired to costing.py (costing:film-total = FILM low \$3,538; was a stale hand-set \$3,100 that sat below its own BOM). Config-table corner depths, per-corner angles, rail X coordinates + per-item BoM prices left as diagram-of-record. (Author also trimmed prose: rail coords in §1, the 'earlier stretching scheme' archaeology in §3, the Option-A date note in §4.)*
- [x] film-plane-mechanism-analysis.md  — *DONE (2026-07-03): the call — NOT retired/trimmed; kept + PUBLISHED under Research as a decision record. Added a decision record at the top (what the stretching four-corner design was, why it was abandoned — twist + growing plane needing a folding backing / non-flat sealing — and Option A that replaced it: rigid plane on corner cross-slides + rod-end bearings, single ACM backing, ~+$300, ±40/±28). Registered for publish (publish.sh, setup_docs MD_FILES + index row, mkdocs Research nav; diagrams already registered via distortion-renders + the film-plane report). Cleaned the now-scanned superseded body: American spelling (Centre/aluminium/labour) + thousands separators. editorial_lint + lint green.*
- [x] film-clamp-mechanism-report.md  — *DONE (2026-06-23): the ±tilt/swing now reference film_plane_max_tilt/swing facts (§1 + §5). Single-sourced the §2 film-plane dims (4,499×2,388 + per-edge lengths ×6 → film_plane_width/height) and wired the §4 clamp-system cost to costing.py (costing:clamp-system-low/high = FILM clamp line $276/$736 + mounting $70 = $346–$806; was a hand-set $330–$790). Added the §1 angle-frame gloss (2"×2"×3/16" L-angle, names the legs). Clamp counts verified (30+30+16+16=92; perimeter 13,774/150≈92). Detail dims (force, neoprene, hem, spacing) + per-item BoM prices left as spec/diagram-of-record.*
- [ ] pinhole-disc-holder-report.md  — *NEEDS FRESH REVIEW (2026-09-21): fully rewritten from the retired tilt-swing-board-report.md when the tilt-swing mechanism was eliminated (optically inert on a pinhole). New content: quick-change pinhole disc holder (Ø180 plate + washer + interchangeable disc/lens + retaining ring + thumb screws). No longer owns any fact (the front_board_* facts were retired); §9 front-board total is single-sourced from the parts:front-board block. The prior [x] editorial pass is void — the doc is new prose. (The former tilt-swing-board-analysis.md distortion doc was deleted.)*
- [x] water-system-report.md  — *DONE (2026-07-02): re-review pass (commit d4d315cb). Reconciled the filter train to the current THREE separate 4.5×20 Big Blue housings with inter-housing jumpers (§3.2/§5 had described "a single combo unit, no inter-housing plumbing"; combo reframed as the alternative); fixed stale filter media in the §4.2 flow + §9 (F-1 5µm sediment / F-2 KDF-55 / F-3 carbon, was 50µm/5µm/GAC); intervals reconciled to plumbing §3.1 (~50/60/40, §3.2 points there, §9 corrected from 10/10/15); §7 pump position table reversed to the panel split (Pinhole Wall = P-02 + filter bank; Corridor = P-01/P-03/P-04/P-05 + ACC-01, was the pre-relocation manifold); §Total cost summary replaced the stale hand categories with the generated §8 parts:water BOM total (\$2,073–3,123) + tray/spray blocks → \$3,660–5,513 (flagged for generation); added the under-walkway ribbon pointer (§7 → plumbing §8.1 + walkway-routing). Also absorbed the 4.5×10→4.5×20 filter cascade. Prior pass: DONE (2026-06-21): owner of prints_per_resupply + blue_supply_l. The 8–10-vs-13 print confusion is resolved (now "9–11 on fresh Blue alone, ~14 with recycling"). Heavy values pass done via the 1,600→1,800L / 13→14-print design revision (§4 capacity table, water balance, max-fill, top-up, cooling overhead — all rebased). Converted the recurring canonical restatements (prints_per_resupply ×6, blue_supply_l ×3) to fact placeholders so this owner doc auto-cascades; §1 film-plane dims already fact-held. No drift in §5–12. Also fixed the §7 hose-routing paragraph (was the old pinhole-wall pump-manifold design → now the plumbing-panel-in-corridor design, consistent with §4.4 + plumbing-report; the matching stale spots in equipment-layout §2.2/§7 were corrected too) and §1 stacking-table typos. Remaining (separate Phase-1 track): the §9 parts-list cost total ($3,262–$4,881) is hand-maintained, not yet a costing.py block; the §5/§8 P&ID coordinates (sump X=2399, zone X-ranges, 4459×2200 tray) are intentionally kept as descriptive context.*
- [x] ibc-stacking-report.md  — *DONE (2026-07-03): full deep-4-leg-box reconciliation across prose, BOM, 2D, 3D, and weight/CG. (1) §3 rewritten portal→deep box (4 uprights front X4654 + back X5104, top/bottom rings, 4 feet, front feet under the tray); §7/§8/§9 + equipment-layout/cost-breakdown/component-dependency-map prose reconciled; parts.py feet 2→4 + 16 anchors → ibc-frame \$980–1,505, costing/grand-total cascaded. (2) Sheet 4 relocation staleness fixed (pumps P-01/P-03/P-04/P-05 + ACC, filters relabeled → Pinhole Wall panel, panel depth). (3) **2D frame cascade** — every frame view redrawn from cp.frame(): ibc-frame 1/2/3 + ibc-stacking 1/3/4/5 now show the 4-leg box with top/bottom rings (caught Sheet 4 + Sheet 1/3/5 ring omissions); dropped the legacy full-footprint frame + inter-tier platform beam. (4) **Weight/CG recompute** — model was still the retired 8-upright rack (~178 kg); rebuilt to the deep box ~90 kg + Component repositioned to the corridor → CG cascade (dry 3,332→3,244, loaded 5,132→5,044, CG X 3,673→3,637); §4.4 tip table recomputed. All gates green (parts/costing/lint/check_consistency/weight --check-blocks). Commits 985f1150→162ad920. NOT yet published (batched per cadence). RE-OPEN driver (walkway-routing 4 interference flags) was already resolved 2026-07-02 [[project_walkway_routing_section_flags]].*
- [x] equipment-layout-report.md  — *RE-REVIEWED DONE (2026-07-03): light pass — §5 already reflected the deep 4-leg box (X4654/X5104, ~90kg) + the dedup pointers (pump loc, seals, water capacity) were intact. §7 trunking 25→40×25mm PVC + noted the pump circuit is switched at the EP master switch (corridor panel carries only the 12V dist block); stripped §D archaeology (§2.2 EP "rev11: dropped 150mm (was Z1,650–2,250)… now retired…", §4 Old/New IBC-stacking table→neutral alt labels, §6.2 "moved deeper from X=1,200 in rev10", §9.2 Fan-B "rev9/B2 swap"). §2 position tables + §9.2 swing-clearance coords kept (diagram-of-record); editorial + drift gates green. RE-OPEN was (2026-07-01): re-review vs the plumbing-corridor routing + the new walkway pipe-routing cross-sections (walkway-routing-sections.md) & their 4 interference flags (arm-soffit graze, 25mm rim↔upright pinch, foot/M12 under the tray, stale RWK_X_UP; deep-box frame X4654 supersedes ibc_rack). Prior pass: DONE (2026-06-21): single-sourced the headline geometry (film_plane_width_mm 4499 ×4, container_interior_length_mm 5893, film_plane_height_mm 2388, prints_per_resupply, blue_supply_l) as fact placeholders; §5 IBC-frame cost → generated costing block ($955–$1,455, was a stale $500–800); §10 max-swing drift 25.7°→28°. Reworked §8 into a two-state Camera-ready/Supply-exhausted water table with the 400L process-loss balance, max-fill capacity + on-site top-up (later cascaded to the 1,800L/14-print revision). §6.1 seal table slimmed to a pointer (hinged-panel §6); §10 reduced to a current-design summary (dropped the Old/colonnade column + 55-gal-drum archaeology). §2 coordinate position tables intentionally left as diagram-of-record detail.*
- [x] plumbing-report.md  — *DONE (2026-07-02): re-review vs the final walkway pipe-routing. §8.1 ribbon reconciled to the merged design (flush under the grate, middle two lanes swapped, crosses the outer beam through open-top notches + drops the tray-edge slot past the carriage — was "crosses under the walkway support beam"); pointer to walkway-routing-sections.md added. Fixed real contradictions: §10 maintenance CV-1/CV-3/CV-4 → CV-1 only (matches §4.3); §5 pipe table + §11 ref 8 spray-bar hose BV-02 → BV-05. Stripped raw Z coords from prose (Spine-View-B caption, §2 panel edge rows). Then the 4.5×10 → 4.5×20 filter swap cascaded here: §3.1 rewritten to the high horizontal bank (was the stale vertical stack) + doubled intervals + head-clearance note; §7.4/§10/§11 updated. Commits c2163bfe + 4b223fde. Prior pass: DONE (2026-06-30, pinhole-wall-mount branch). Editorial + drift gates pass.*
- [x] walkway-routing-sections.md  — *DONE (2026-07-02): editorial A/B/C/D done (commits 50125185 + dabca97e) — See Also added; five-vs-seven wording; C lane reconciliation (E-E was stale gray DV-01 waste/recycle → the ribbon is the same 2 brown + 2 blue end-to-end: IBC-3→P-02, tray-sump→P-04, Blue trunk→TAP-01, SV-01→DV-01 return); §G-G/H-H before/after dropped. The final blocker — the spray-carriage clearance — is RESOLVED (merge 986f1eee): the ribbon was raised to FLUSH (Z104.5, clears the carriage crown ~28mm), the corridor exit crosses the outer beam through open-top notches + drops the tray-edge slot past the carriage travel (no more sub-cantilever dip), and the §Interference findings + B-B/D-D/E-E sections were rewritten to match. Nav: Construction › Water System (mkdocs.yml).*
- [x] electrical-report.md  — *RE-REVIEWED DONE (2026-07-03): editorial pass on the master-pump-switch→EP cascade — dropped the "relocated from the corridor panel" archaeology from the §7.4 Sheet-5 caption (§D, current-state only); rest of the cascade (§7.3 Circuit C, Sheet-4 caption, §8 parts rows + footnote) verified clean — no coords-in-prose, canonical IDs, thousands-sep, spelling + source links pass; injectors touched nothing; parts/costing/drift gates green. The cascade rewrote §7.3, §7.4 (sheet4 + sheet5 captions), and §8 (master-switch/dist-block parts rows + fixed stale footnote figures: 5 pump switches→1 master, $1,015→$989 = $2,324, $45→$25). Plumbing-report §3.2 was touched in the same cascade (still marked done 2026-06-22 — light re-check pending if wanted). PRIOR PASS — DONE (2026-06-22): corrected energy-script drift (sessions/charge 1.6→1.5, solar sessions/day 4.5→4.2, 2-pack 3.3→3.1, cloudy-day reserve 1.2→1.1 — §3.1/§3.2 had been hand-copied from `calculate_energy_budget.py` and gone stale). Substitutions: blue_supply_l + prints_per_resupply ×2 as fact placeholders. Built an energy block-injector (`calculate_energy_budget.py --inject/--check-blocks` + new lint gate) — 14 `energy:KEY` figures now injected into §3.1/§3.2 so they can't drift again. §8 cost totals → costing blocks (elec-system/canopy/cooling/grand-total; canopy/cooling derived from the §5b VENTILATION BOM). Thousands-sep: '1300 CFM'→'1,300 CFM' across 5 docs + CFM added to editorial_lint's unit list + evap alias made comma-tolerant. Relocated the energy-injection workflow note to README (codebase-management ≠ camera spec); trimmed the matching tooling notes from §3.2 + daily-energy §1/§4/§9. Detail dims (circuit run lengths, Z heights, panel coordinates) intentionally left as descriptive context. Provenance citations to internal generators (other docs) left for their own passes.*
- [x] electrical-safety-report.md  — *DONE (2026-06-23): added the missing SPDX header + AGPLv3 footer. Reconciled the **Circuit-E 120V AC** gap the report omitted — §1 (two AC interfaces), §2 ("one exception" caveat to the 12V-ELV thesis), §3 baseline, §4 Hazard #6, §6 rule, §7 commissioning. One-source-of-record: §5 collapsed from duplicated control-spec tables to a gap→control→spec-pointer map (specs owned by electrical §7.5/§7.6). Then carried the **D1–D5 design changes** in: §5 control map (two E-stops, PV disconnect, charge-line fuse, per-pack MRBF, thermal siting) + §4 reworked to "Residual gap → closed by" with the PV/charge-side gap surfaced. Mechanically clean (editorial_lint).*
- [x] daily-energy-report.md  — *DONE (2026-06-23): added the missing SPDX header + AGPLv3 footer; substituted prints_per_resupply ×3 as fact placeholders; relabeled the ~771 Wh figure as per-SESSION (it clashed with §3's 663 Wh per-print); fixed the 2-pack no-sun reserve 1.2→1.1 day and the 'Black tote is 600 L' → 'fills to ~600 L (1,000 L tote at working fill)'. Single-sourced 17 computed figures via the energy block-injector (extended `_ENERGY_DOCS` + 4 new keys), so daily-energy can't drift from `calculate_energy_budget.py`. **Conceptual fix:** the Brown/Waste pump-out is a per-RESUPPLY dump run (~14 prints / ~4.7 days), not end-of-day — corrected `compute_daily()` to exclude it (daily totals 1,434/2,097/2,760), renamed the model fn, reframed §6 ('Resupply … per dump run, not daily'), dropped the §4 daily drain line, fixed §1 intro, and cascaded to electrical §3.1; trimmed the §7.4 old-80W/220→400 archaeology. Moved under the Operating Manual nav section. Detail dims (P&ID pump table, Z-coordinates) left as descriptive context.*
- [x] ventilation-report.md  — *DONE (2026-06-23): reconciled drifted summary costs (§3 shade $300→$200, §4 fans $60→$50) and single-sourced them + the §9 parts-list total ($824) as costing.py §5b blocks (new vent-total/vent-fans/vent-shade/vent-cooler-inverter keys); dropped the 'fictional Portacool Jetstream' archaeology. New EVAP_CFM_RATED constant + cooler_cfm_rated fact (injection-only) wraps the three 1,300 CFM restatements. Fixed the §7 air-change error: the two fans run in series so the exchange is the ~200 CFM through-flow (not 2×200=400), giving ~14 ACH (was a non-computing 16); folded in the cooler's ~300 CFM of 100% outside air (~30+ ACH running) and cited the darkroom minimum (Kodak ≥10 ACH / 170 CFM, §11 ref 8). Detail dims left as diagram/spec context.*
- [x] light-trap-selection.md  — *DONE (2026-07-02): heavy archaeology strip (§D) — removed all rev8/9/10/11 + B2 tags, the was-3mm-aluminum/~99→~60 kg/cost-drops-from before-after metrics, and both 'replaces the earlier Ø750 drum' blockquotes. Cost single-sourced (§B): the recurring \$1,465–\$2,160 was stale AND disagreed with the BOM → now generates from costing:hp-housing-low/high (= LIGHTLOCK total \$1,385–\$2,070, owned by hinged-panel §8.2; extended those keys to also live here via the multi-doc rel tuple). Duplication slimmed to pointers (§C): panel construction / swing pivot / ~209 kg weight → hinged-panel + equipment-layout + weight-distribution; this fixed a real contradiction (§1 '18mm ply skins' vs §7 current '4mm PP'). Coordinates stripped from prose (§A); panel dims wrapped as container_width/height facts. §4.5 supplier table kept (part numbers) with drifted per-line \$ removed. All gates green; committed 0cfb3dc9 + published.*
- [x] process-comparison.md  — *DONE (2026-07-02, first review): (B) fixed a real contradiction — Gum bichromate Process 2 header \$3,154/\$63 disagreed with the exec table, comparative summary, and its own shopping-list total (all \$2,459/\$49) → reconciled to \$2,459/\$49; 'under \$3,500'→'under \$2,500'. (D) cyanotype baseline mismatch — the row costs the LEAN tier (~\$24/print) while the project headlines Standard ½-Ware (~\$33, ~\$1,650/50); resolved by labeling the row 'Ware, lean' + a new Process 1 stub stating the cost basis and cross-ref to Cost Breakdown (not a full rebase — offered). (E) added the Process 1 (Cyanotype) heading so numbering isn't 2–6. (C) American spelling editorial_lint can't see: oxidiser→oxidizer, sensitiser(s)→sensitizer(s). (A) added See Also / Source References + AGPLv3 footer → cleared the editorial_lint missing-refs flag. trimmed the §Key-Procurement silver-nitrate DEA note in review. Commit 7afe9979; all gates green. Owns nothing; film_plane_width/height facts already wrapped. NOT yet published (deploy batched per new cadence).*
- [x] hinged-panel-report.md  — *DONE (2026-06-23): single-sourced the transport swing ~56° ×9 via a new panel_swing_deg fact (= SWING_LOCK_DEG); panel outer dims 2,362×2,388 + far-corner Yd → container_width_mm/container_height_mm. Major cost reconciliation (audit): the panel STRUCTURE (§8.1) had NO costing.py home — added §6c PANEL ($1,124/$1,408/$1,691), rebuilt §6 LIGHTLOCK (=§8.2, $1,385/$1,728/$2,070) and §6b SWINGPIVOT (=§8.3+§8.4, $855/$1,143/$1,430) from the report line items; wired the four §8.1–8.4 subtotals + §8.5 rows/total to costing blocks (split §6b via helpers). Fixed the report's internal staleness (§8.1 $1,005→$1,124, §8.3 $560→$520, §8.5 total $3,190→$3,364). Grand total $25,620→$26,865 (mid) — the missing panel. Cascaded to project-cost-breakdown (regen'd §6/§6b detail tables), cost-analysis, funding-proposal, master-shopping. Detail dims (Z/Yd coords, seal geometry) left as diagram-of-record.*
- [x] walkway-report.md  — *RE-REVIEWED DONE (2026-07-03): light pass — §4 already reflected the rev12 cantilever-rectangle cascade (arms off the IBC corridor uprights, combined corner plate) + §5.3 floor-leg matched the resolved "foot under tray" flag (post on bare floor outside the tray, M10 anchors). Dropped §D archaeology ("(rev12)" from the §4 heading, "(rev10 — supersedes the linear slide)" from §5.4); §4.4 "four goals"→three; added a pointer to walkway-routing-sections.md (§4.4 body + §12 ref) — the doc had never referenced it. §2 spec + §5.3 detail coords kept (diagram-of-record); gates green. RE-OPEN was (2026-07-01): re-review vs the plumbing-corridor routing + the new walkway pipe-routing cross-sections (walkway-routing-sections.md) & their 4 interference flags (arm-soffit graze, 25mm rim↔upright pinch, foot/M12 under the tray, stale RWK_X_UP; deep-box frame X4654 supersedes ibc_rack). Prior pass: DONE (2026-06-23): resolved a three-way §10 cost mismatch (audit) — kept costing.py's split structure but pushed the report's authoritative all-in bracket figures ($742–$1,255) in by raising the §6a Fabrication line (280/360/440→454/634/808); WALKWAY $1,826/$2,214/$2,607→$2,000/$2,488/$2,975, grand total cascaded. §10 fixes: dropped the evap-stowage rows (costed in Ventilation, cross-ref'd), added the drum-exit GRP row, wired the total to costing:walkway-total-low/high. Single-sourced the §2 open-area span (spray_beam_span_mm) and the container coordinates from real facts — new container_width_mm fact (= C_WID, so structural width stops borrowing focal_length_mm) for the 2,362 width refs, 5,893→container_interior_length_mm, 4,649→film_plane_right_x_mm. (Swept container_width_mm/focal_length_mm into 5 more docs as follow-up.) Detail coords + per-item BoM prices left as diagram-of-record.*
- [ ] tray-research.md  — *NEW (2026-08-02): decision record — why the processing tray stays 304 SS (welded-PP + liner options evaluated, cost + construction, 2B-finish trim). Not yet editorially reviewed.*
- [ ] plywood-cut-sheets.md  — *NEW (2026-09-30): single plywood schedule + nesting layout for every subsystem (one buyer/fabricator cut sheet, grouped by grade+thickness). Cut dims single-sourced from tbs_constants where geometry-driven, else spec/report literals; cost/SKU point to parts.py. Written to the report-writing skill but not yet independently reviewed.*
- [x] right-walkway-cantilever-study.md  — *DONE (2026-06-23): was stale (framed 'not yet adopted, baseline ceiling-hung', but the cantilever was adopted in rev12 — Walkway §4 is the as-built 'Cantilever Rectangle'). Reframed to an ADOPTED decision record: status → adopted pointing to Walkway §4 (as-built refined the study into a closed rectangle); §1 past-tensed, §3 'Proposed'→'The design'+as-built note, §6 'current/proposed'→'former/adopted', §7 'if approved'→'Implementation (rev12 complete)'. Added See Also (clears no-source-refs flag) + AGPLv3 footer. Moved nav Construction→Misc → Research.* **Re-reviewed 2026-07-02:** fixed a stale derived number — §3 cantilever arm reach ~405mm predated the deep-box upright correction (405 = old X4734−X4329; current X4654 → ~325mm) and §4 load check recomputed consistently (moment ~0.35→~0.33 kN·m, stresses ~86→~81 / ~44→~41 MPa, bolt ~3.5→~3.3 kN — SFs unchanged); fixed §3 40×45→40×40 SHS typo. §1 corner-sweep terminology '28° tilt'→'28° swing' (+labeled 40° tilt), 28/40 single-sourced as film_plane_max_swing/tilt facts. X/Yd coords left as diagram-of-record (comma-display facts would clash with the doc's comma-free coordinate style). trimmed the §1 coordinate parenthetical in review. Commit 37923517, published; all gates green.*
- [x] processing-tray-and-spray-bar.md  — *RE-REVIEWED DONE (2026-07-03): caught a real GEOMETRY drift (not prose) — the rev10 low-profile carriage (Ø32 wheels, 40×25 304-SS beam, axle Z36, beam Z29–54, tray floor raised to Z20 on the shim ramp) was live in tbs_constants/2D diagrams/parts.py/§2.5/§3.3/§3.6-fab, but §3.4 (wheel spec + vertical-Z stack) + §3.5 still carried the OLD Ø50/axle-Z27/beam-Z20–60 (§3.4 even contradicted §3.6 on wheel Ø). Reconciled §3.4/§3.5/§3.6 to the constants (verified vs spray-bar-sheet2; beam-bottom→floor 9mm = the diagram's "9mm SPRAY"); §3.3+§3.7 already current. Also resolved an 8mm-bore-vs-10mm-axle physical mismatch: web-verified a 32mm nylon roller comes in 10mm bore → set the wheel to 10mm bore across parts.py + master + doc, cited a real uxcell product URL (supplier→Amazon). Gates + parts/costing checks green. RE-OPEN was (2026-07-01): re-review vs the plumbing-corridor routing + the new walkway pipe-routing cross-sections (walkway-routing-sections.md) & their 4 interference flags (arm-soffit graze, 25mm rim↔upright pinch, foot/M12 under the tray, stale RWK_X_UP; deep-box frame X4654 supersedes ibc_rack). Prior pass: DONE (2026-06-22): corrections — comma thousands-sep the linter can't see (4,459 / 2,229 / 2,340 / 101,972mm⁴), §3.6 numbering gap (3.6.5→3.6.4), unit tidy (liters→L); fixed the operating water weight (~233kg/117kg water → ~175kg/59kg — was ~2× the 6mm-flood volume). Cost reconciliation: §6 tray/spray subtotals + total → costing.py blocks; the WATER line items rebased to this dedicated report's detailed BOM (tray $1,177→$1,300–$2,015 — was undercounting shims/pickup/liner/hardware; spray $210→$235–$299), cascaded to project-cost-breakdown §5, scenarios, funding-proposal, master-shopping, cost-analysis. New SPRAY_BEAM_SPAN constant + injection-only facts (pinhole_x_mm, film_plane_left/right_x_mm, spray_beam_span_mm — no aliases; values collide with unrelated uses); 14 restatements wrapped. Downstream: slimmed water-system §8 (full) + master-shopping (kept supplier rows, fixed cost) tray/spray BOMs to point here. Engine fix: costing keys can span multiple docs + inject/check ALL occurrences (was first-only). Detail dims (Z-table coordinates, carriage/beam geometry) intentionally left as diagram-of-record.*
- [x] chemistry-prep-shelves.md  — *DONE (2026-06-23): applied the refined skill IN the pre-pass — stripped X/Yd/Z coordinates from §1/§2/§2.1/§5 narrative (kept §2.2 spatial-constraints table, spec tables, optical-cone proof, assembly steps), dropped the §1 "previous ceiling-hung shelf" archaeology. Wired the §7 cost (~$203) into costing.py as the new §6d SHELF section — it had no costing home, so the grand total was omitting it; cascaded to all cost docs (grand total +$203).*
- [x] weight-distribution-report.md  — *DONE (2026-06-30): reviewed during the `pinhole-wall-mount` branch review; the CG/weight cascade for the corridor plumbing-panel relocation was confirmed against the current model. Drift gates pass.* **Re-reviewed 2026-07-02:** (1) reconciled prose to generate_weight_analysis.py (dry CG 2,798→2,802, loaded Z 1,341→1,340, ΔZ 411→410, near range) + stripped rev9/10/11/12/13/B2/HGR20/600L archaeology + GRP-vs-steel before/after. (2) BUILT a value injector — the report's weight/CG/split/margin figures were hand-transcribed (why they drifted); now generated from the model via `weight:` markers (`generate_weight_analysis.py --inject`/`--check-blocks`), gated by lint (`weight doc-blocks`). Compute made dependency-free (numpy→math, guarded matplotlib) so lint's python runs it; drawing still needs /usr/bin/python3; PNGs byte-identical. (3) Swept §3.4/§4.3/§6.1/§6.2/§6.3/§6.4/§5 — ALL computed figures (subtotals, state table, CG positions, splits, ISO margins, near/far balance, walkway subsystem, CG shifts, length ratio, door total) now inject-locked. Surfaced + fixed 4 latent drifts: Yd 1,175→1,174, near-elec ~43→30 kg, walkway 4.4→4.3%, CG shift ~685→680mm. Only inputs (densities/tares/component weights), positions, geometry constants, and the §4.4 max-fill sub-case stay bare. Commits 09131933→63335018; [[project_weight_injector]]. NOT yet published (batched per cadence).*
- [x] container-transport-options.md  — *DONE (2026-07-02, first review): fixed duplicate section number (two '## 10' → Sources renumbered to §11); project name 'Giant Pinhole Camera project' → 'The Big Shoebox Project (TBS-001)'; American spelling editorial_lint can't see (programme/programmes → program/programs); §10 long-distance rate \$2.95–\$3.60/mile → \$2.95–\$3.32/mile (aligned to §4's contract rate, \$3.60 unsupported); standardized lb → lbs on weight quantities (15 spots) to match the regulatory tables. Owns nothing; all pricing is external market/CDL research (stays prose, not project-owned). All gates green; commit 155f64db. NOT yet published (batched per new deploy cadence).*
- [x] lens-options.md  — *DONE (2026-06-24): hyperlinked the whole Sources table (books→catalog, manufacturers→sites); header placeholders (pinhole 2.17→pinhole_diameter_mm, f/1088→f_number, container 5893→container_interior_length_mm ×2); thousands-sep 3262/3474/1112/424000/10743612; spelling/typos utilised→utilized, jewellery→jewelry, artefact→artifact, maximising→maximizing, centerd→centered ×2; cyanotype ~35→~30–45 min ×3. Pinhole resolution standardized on pinhole-optics' 0.69 lp/mm (was 0.23, the geometric figure MISLABELED 'diffraction-limited'): §4.1 row → 1.46mm Airy / 0.69 lp/mm / labeled+cited, the '× better than pinhole' ratios recomputed vs 0.69 (100→33×, 50→17×, 26→9×, 13→4×, 6→2×, 3→~1×; prose 65–110→22–36×, 20–43→7–14×), §4.2 reworded to keep the 2.17mm GEOMETRIC blur distinct from the lp/mm resolution, §10 summary 0.23→0.69. LEFT for review: 43 min (L113) vs 2.4 hr (L129) bellows discrepancy; whether the 0.69-diffraction framing (vs 0.23-geometric practical) reads right. Editorial + drift gates pass.*
- [x] lens-vs-pinhole-exposure.md  — *DONE (2026-06-24): rewrote §2.2 to drop the show-wrong-then-correct device (the ~15,500 false start + 'Wait — this is not right') into a direct two-factor decomposition (1,632 aperture × 3.36 reciprocity = 5,484 ≈ 5,489), and added a 'for the camera as built' callout scoping Factor 2 to silver-gelatin paper (cyanotype is iron-based → no Schwarzschild term → lens edge is the ~4,624× aperture ratio alone). Hyperlinked the whole Sources table (books → catalog, Young → DOI, Schwarzschild → NASA ADS). Fixed the Schwarzschild citation: bogus 'Astrophysikalische Nachrichten Vol. 148' → The Astrophysical Journal Vol. 11, 1900, pp. 89–91 (ADS). Wrapped header f 2,362/2.17/f1088 as placeholders; 17094→17,094 (×2); dropped the naive 0.56 sec in Part 2 (0.47 used throughout); spellings penalises→penalizes, standardised→standardized (×2; editorial_lint misses -ise). Recorded the authoritative-voice/no-self-correction preference in memory. Editorial + drift gates pass.*
- [x] photosensitive-plane-options.md  — *DONE (2026-06-24): 'Giant Pinhole Camera'→'The Big Shoebox Project (TBS-001)'; header placeholders (container/116/f/f-number/pinhole); British spellings→American (sensitiser×7, Sensitising, sensitised×3, sensitisation×3, artefact×3, minimising, analyses); thousands-sep 5950/1220; cyanotype §A.1 exposure ~1–4h→~30–45min(Ware)+~2–4h(Herschel); hyperlinked Sources table; pricing 2025→2026. COST (option 3 full reconcile): costing.py holds the truth for cyanotype per-print — bound NEW placeholders costing:s73-pp-std (~$36) + s73-pp-range ($27–63) to this doc; §1 fixed FAC→Ware AmFe; ALL muslin lines retail $80–100→BULK ~$6/print (project-cost-breakdown §7.1), recomputed every per-image total + cascaded Exec/process-comparison/recommendation tables (Gum→$61–81, Salt→$280–360, VanDyke→$121–206, Herschel→$30–40); added substrate-cost-basis note; softened 'ordered by cost'. Non-muslin processes unchanged. costing self-check + all gates pass. NOTE: Herschel/gum/salt/VanDyke totals are the doc's own chem estimates + bulk muslin (only cyanotype-Ware is single-sourced).*
- [ ] portrait-photography.md  — *NEW 2026-10-08 (gallery-only diagram refresh): new Research report built clean — the prose points to the 3 refreshed portrait diagrams and keeps only headline figures (FOV ~86° H / ~48° V, f=2,362, Ø2.17, f/1088, M=f/u, blur=2.17·(1+f/u)); no restated detail dims to remove. Editorial gates pass. The portrait generators were refreshed off the active film plane (4,389×2,094, pinhole X=2,454) and the stale 102° FOV was also corrected in pinhole-optics-report.md Part 11. PENDING sign-off.*
- [x] distortion-renders.md  — *DONE (2026-06-25): renamed from complete-distortion-renders.md (fixed refs in publish.sh, setup_docs.py MD_FILES + INDEX_MD, mkdocs.yml regen, project-summary.md, and the cross-ref links in film-plane-mechanism-report.md + tilt-swing-board-report.md). Editorial: §1 'Seven configurations'→'Six' (table is C0–C5); dropped 'old…no longer producible' archaeology → states the constraint affirmatively; single-sourced ±40°/±28° → film_plane_max_tilt/swing placeholders. Stray dim: tilt-swing C2/C3 'max shift' paired the 5.3° hard-stop with the 5° reference shift (207mm) — corrected the generator to COMPUTE it (SHIFT=round(F·tan(FB))=219mm), regenerated C2/C3 + summary, doc → ±219mm. Editorial + drift gates pass.*
- [x] component-dimension-audit.md  — *DONE (2026-07-02, first review): intentionally dimensional (parts:dimension-audit table + evap facts already generated). (A) removed a duplicated closing line; (B) §2 detail headings were stuck at as-found ❌/⚠ while §1 + §4 mark them ✅ done → reconciled all six to '✅ RESOLVED (§4)' + an as-found note; (C) reworded §6 to keep the audit finding without the flagged 'Portacool Jetstream' phrasing → editorial_lint now fully clean; (D) flagged the §4 cost figures as a dated 2026-06-15 snapshot (current total in Cost Breakdown). Then fixed a stale §4 claim: the evap/inverter 3D re-send is DONE (overview.skp re-saved 1872583b + inverter label 99ec629c), not pending — only the manual Sketchfab re-upload may remain. Commits 1b23d1cc + 6f1a6697; all gates green. NOT yet published.*
- [x] licensing.md  — *DONE (2026-07-02, first review): removed 'All rights reserved' (contradicted the AGPLv3 open-source grant → 'Copyright © 2026 Alvin Richards.', matches SPDX header); hyperlinked the license name to the official GNU AGPLv3 text (§E); added a Source References section (formal official-license link + repo LICENSE file) → cleared the editorial_lint missing-refs flag. Owns nothing; gates green. Commit 1b6df25a. NOT yet published (batched per cadence).*

## B. Cost & shopping (numbers move to costing.py — Phase 1; prose editorial still applies)

- [x] project-cost-breakdown.md  — *DONE (2026-06-20): fully single-sourced from costing.py — 10 section detail tables, the scenario summary, §7.1 chemistry, §7.3 process-comparison Cyanotype row (all-in = §7.1 + $3/print consumables), and the §11 budget scenarios A/B/C are all generated blocks (generating §11 fixed latent drifts). Prose engineering dims (4499×2388, 116 sq ft, 13 prints, 1,600L) are fact placeholders. Only genuine external estimates (CDL/truck/transport ranges) remain hand-kept.*
- [x] cost-analysis-report.md  — *DONE (2026-06-20): summarizes the Mid column, now generated from costing.py — §2 capital/recurring buckets (capital = grand Mid − §7/§8/§9) + §3 system ranking (sections × Mid + % of capital) are blocks; mid-total/capital/consumable/water-% inline. Generating fixed a stale "28%" water figure → 23%. Editorial savings-lever estimates left as prose. (Was missing from this list.)* **Re-reviewed 2026-07-02:** fixed two drifted hand-typed figures (§3 tray range \$1,177–1,857→costing:tray-low/high \$1,300–2,015; §4 base "~\$22k"→costing:ca-capital \$24,207, % → ~13–15%). Then derived the savings levers (**bucket A**): new SAVINGS_LEVERS in costing.py — container lever is a true computed CW−WWT subtraction (\$3,150−\$1,800=\$1,350), roll-up total (\$3,250–3,650) + % (13–15%) are computed sums over capital_mid, and every §4 Saves cell + §6 light-lock mid (\$1,728) is now a single-sourced ca-lever-*/ca-savings-*/ca-lightlock-mid inline key (no hand-typed savings figures left). **Bucket B deferred** (levers 2–5 need alternative-config modeling to become real subtractions; lever 2 actioned→should leave the roll-up once modeled) — noted in the doc §4 Derivation note, the costing.py SAVINGS_LEVERS comment, and memory [[project_cost_analysis_variants_layer]]. Commits 64612738 + 9b135648, published; all gates green.*
- [x] master-shopping-list.md  — *DONE (2026-06-24): reworked into a generated **by-type procurement BOM** — the body is now a `parts:master` block from the parts registry (parts.py), replacing the old by-system list that duplicated every report. Receiver-facing intro (code/generation note moved to README); tables click-sortable (tablesort, money-aware numeric sort, total rows pinned to <tfoot>); type sections + rows ordered A–Z; timber-ply specified by whole sheets with Home-Depot size+thickness in the Qty column. De-duplicated the leftover hand sections against the generated BOM: §10 Tools stripped 6 cross-system items (clamps→film-clamp, gloves+poly→water, Red-LED strip→electrical) with cross-refs; §9 Chemistry trimmed to the recipe/per-print basis (procurement → BOM; AmFe masses now block-injected); §11 Safety verified clean + scoping note; Supplier Directory reconciled (5 stale/alt-only removed, TAP/Curbell/AutomationDirect/B&H added, categories corrected to actual build usage). All gates green incl. the new costing.py --check-registry section-reconciliation gate.*
- [x] chemistry-shopping-list.md  — *DONE (2026-07-03): 5 fixes — added a §Source References section (+ hyperlinked the bare mikeware.co.uk URL); reconciled the stale per-print "Chemistry quantities" table (169g / 8.45kg / ~$887 / "~11–32 not 50" — same drift as sensitizer-trials) to a reagent-role table + pointer to the parts:chemistry tier block + Sensitizer Trials (no restated tier numbers); stale headline ~$1,915/$38 → Standard ½-Ware ~$1,653/$33; stripped the §D "Correction (2026-06-18)" muslin archaeology; de-duped the "No fixer required" note. Checked §C: NOT a problematic dup of master §9 — owner→summary pattern (master §9 cites this doc), chemistry numbers single-sourced via parts.py/costing injected into both; residual = the Ware recipe sentence in both (minor). editorial_lint + lint + parts/costing green.*
- [x] sensitizer-trials.md  — *DONE (2026-07-03): reconciled the stale "Why this matters" impact figures (8.45 kg AmFe / ~$900 / not 50 / 4.6× — no longer matched the current costing tiers 13/19.5/39 kg / ~$780–$2,340; the AmFe order had already been re-sized to the very tiers this page motivated) → rewrote to the current ~3× tier swing and POINT to the operating-manual §0.2 table + cost breakdown (drift-proof, no restated tier numbers). Added a §Source References section (AlternativePhotography/Ruth Brown, Jacquard, Ware) — clears the §E gate. Moved from the Shopping nav section to Research (next to Photosensitive Materials) in mkdocs.yml. editorial_lint clean.*

## C. Summary / outward-facing

- [x] project-summary.md  — *DONE (2026-06-20): home page (= published index.md). All owned figures single-sourced — Scale table fully generated via fact placeholders + costing blocks (container/film dims, focal, pinhole, f#, image area, front-board, image-shift, film-plane, prints, per-print/50-run costs); soft values (exposure, recycling %, imperial, λ) left as prose. (Note: README.md is no longer a symlink to this — it's a standalone repo/build guide.)*
- [x] funding-proposal.md  — *DONE (2026-06-20): the restated figures are now single-sourced — cost numbers via costing.py inline blocks (L1 total, scenario span, per-print/tier/50-run, combined band) and engineering numbers via fact placeholders (front-board ±5.3°, film-plane ±40°/±28°, pinhole Ø2.17, film zone 4499×2388). Generated + gated, so they can't drift from their owners — the right model for a standalone pitch (funders won't click through to "referenced" figures).*

## D. Operating

- [x] operating-manual.md  — *DONE (2026-06-20): procedural doc, so most values stay as step guidance. (a) The §0.2/§0.3 chemistry tier tables now single-source the AmFe/ferricyanide masses from `costing.py` TIERS — AmFe per-print g + 50-print kg + ferri per-print g are generated `costing:om-*` blocks (generating reconciled lean ferri 87 g → 86 g); the Ware strengths (g/100 ml), water, and dichromate stay as recipe constants. (b) Trimmed the raw diagram coordinates an operator locates physically, not by measuring — pivot Ø89mm, duct X=1200mm, cooler X=1450–2050mm, walkway X=470/770/950, film-rail X=150mm. Kept operational values: angles (~56° swing, 30° solar, 5° level), the Ø200mm duct size they connect, 150mm clamp centers, spray-bar Yd positions, timings, temps.*

## E. Meta / index / skill (NOT report content — likely SKIP or treat separately)

- [x] CLAUDE.md  — *EXCLUDED from editorial review (2026-07-02): project instructions, not report content.*
- [x] component-dependency-map.md  — *DONE (2026-07-02): §1 registry had 9 stale constant values vs tbs_constants.py (WALKWAY_GRATE_T 25→15, PROC_TRAY_DRAIN_X 2,399→4,550, DRUM_CX 0→-400, BA_X/BA_W, PUMP_X/D, DRUM_H_LT relabeled Height→Top Z, PUMP_W relabeled Width→pump-zone) — fixed, and BUILT `inject_dependency_map.py` (cdm: blocks, lint-gated `dependency-map registry`) so the whole §1 Value column injects from tbs_constants and can't drift (85 rows wrapped). Then Option A on §1.2: promoted the pinhole plate/frame specs (600/15/6/Ø50/0.1) from generate_plate_drawing.py locals into tbs_constants (PLATE_OD/PLATE_THK/WALL_FRAME_T/PINHOLE_DISC_D/PINHOLE_DISC_T), repointed the generator, added 5 cdm rows, slimmed the prose (+fixed PH_APT dup→PH_D). Commits f72cb67e + 16dcb142; [[project_depmap_injector]]. **Deferred (advisory, still flagged):** the Portacool corrected-mistake note (§1.8) + missing See Also — §3.1 rev-narrative intentionally kept as dev rationale. NOT yet published.*
- [x] all-diagrams.md  — *DONE (2026-06-23): audited the gallery against every generated `diagrams/*.png` — 3 sheets were referenced nowhere (electrical-sheet4 Pump Power/Circuit C + sheet5 Main Enclosure Panel Layout; hingepanel-sheet6 Interior Pull Handle), all added in sheet order. No broken refs. Added a standing rule (every new diagram PNG → all-diagrams.md, incl. new sheets on existing generators) to CLAUDE.md workflow + skill_diagram_structure, ENFORCED by a new lint.py warning 'all-diagrams gallery covers every generated diagram PNG'. Gallery is a complete index; no owned figures to single-source (it carries captions only).*
- [x] engineering-diagrams.md  — *DONE (2026-06-21): index/overview page — SKIP for value substitution (carries no owned figures; all numbers live in the linked detail reports). Copy-edited prose typos and refreshed the system/area lists (solar sub-system, walkway in all three areas, ventilation path).*
- [x] skill_label_placement.md  — *EXCLUDED from editorial review (2026-07-02): drawing skill, not report content.*

## F. PoC (TBS-002)

- [x] mini-tbs-poc.md  — *DONE (2026-06-24): single-sourced the restated TBS-001 figures in §2.3 (focal length 2362mm → fact:focal_length_mm with comma, pinhole 2.17mm → fact:pinhole_diameter_mm ×2; film-plane width/height already wrapped); fixed the swapped §4.7/§4.8 subsection order (Extraction Flap → 4.7, Substrate → 4.8); removed §10 'Comparison to TBS-001' (of no interest to the PoC), which retired its stale figures (build cost ~$15,500 vs current ~$21-35k, ±42°/±25.7° vs ±40°/±28°, per-print ~$38) — renumbered BoM → §10, References → §11. Separately, standardized the substrate on 10 × 14\" watercolor paper (was cut-from-22×30 → 16×18): updated print/usable size, simplified mounting (center on board) + coating (fits inside the 12×16 tray), reconciled the large-box alt; and updated the engineering diagram (generate_mini_tbs_diagram.py: PAPER_W/H constants, the section/plan paper + spec panel) to depict it. Editorial gates pass (American spelling, source links).*
- [x] mini-tbs-shopping-list.md  — *DONE (2026-06-24): §4 Substrate predated the poc's 10×14 paper switch — it still specified 22×30 sheets cut to 16×18 for 14×16 prints, with an internally broken cost (12 sheets × $7.49 ≈ $90 vs a $10–18 subtotal) and a 12-vs-20 print quantity mismatch. Re-spec'd to Arches/Fabriano 10×14 blocks (one sheet per print, no cutting), 20–25 sheets, realistic $45–65. Fixed §6 tray text (10×14 paper fits inside the tray — no overhang) and the min-order paper row. Substrate correction lifted the budget: total $94–148 → $129–195, reconciled across BOTH this list and the poc budget summary. No restated TBS-001 figures needing fact-placeholders (chemistry qtys/suppliers already matched the poc); no British spellings (grep clean). Editorial gates pass.*

- [ ] construction-report.md  — *NEW (2026-07-24): scaffolding only, not yet reviewed. Build-sequence report (5 phases, IBC set-out → photo system). Per-step prerequisites/gates + the phased 3D construction model are TBD.*

---

*Tip: when you clear a file, tick it and (optionally) note what moved out, so we can spot any number
that should become a `facts.yml` entry instead of being deleted outright.*

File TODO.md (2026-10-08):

<!-- SPDX-License-Identifier: AGPL-3.0-only -->
<!-- © 2026 Alvin Richards -->
<!-- Working/internal tracker — NOT published (not registered in publish.sh). -->
# TODO & Actions — TBS-001

The **single record** of OUTSTANDING actions — open `[ ]` and in-progress `[~]` only.
Add new items as they arise; tick to `[x]` and delete once done (this file is pruned to
outstanding work, not a history log). Detailed sub-trackers are linked where the detail is extensive.

---

## ⏳ Light-trap parts-quote — pending research (2026-08-24)

- [~] **Brush + holder — KEEP AS-IS for now (2026-08-24: "drive to completed blueprints, optimize cost later").** Leave `ll-wiper-brush` (#4 3/16″ est) + `ll-wiper-holder` (Tanis Al est) + the current drawing (Sheets 4/6/7) unchanged — the design is complete; only the price is an estimate. **Cost-optimization candidate for later:** Grainger 18A417 brush + 18A320 holder (confirmed 1/8″ backing pair, 3/4″/19mm trim; only in 10-packs → $270+$259 for a 4-need — expensive as-is; a by-the-foot source would cut it). If adopted later, re-spec the drawing/constants to 1/8″ backing/19mm trim → cascade Sheets 4/6/7/10.
- [~] **Edge channel — KEEP AS-IS for now** (same "optimize later" call). `ll-edge-channel` stays est; candidate = McMaster 9001K723 (6063 Al confirmed, 3/64″ wall, $18.18/8 ft) + 8× L-clips still to source.

---

## 🛠 Tooling / infra

- [ ] **Model-drift audit — the overview should be the UNION of the sub-models, not a re-implementation (2026-10-05).** → **Full phased plan in [`model-aggregation-plan.md`](model-aggregation-plan.md)** (2026-10-06): Phase 0 extract shared primitives to a neutral `tbs_draw.py`, Phase 1 invert the structural owners, Phase 2 collapse the electrical/light-trap wrappers, Phase 3 lint overview to pure aggregation. Analysis + per-phase cascade protocol there. Found while wiring the EP: the **overview drew its OWN electrical circuit wiring** (grey fan feeds / conduit drops / lighting conduits / Cct-C feed in `generate_sketchup_model.py` `lighting_wiring()`/`fan_wiring()`) instead of reusing `em.circuit_runs()` — so the color-coded per-fuse circuits in **electrical.skp** never appeared in **overview**, and the two drifted. Being fixed now by bringing `circuit_runs()` into the overview. **Broader action:** audit EVERY component the overview re-draws vs its owning sub-model (lighting/fan loads vs `em.context` ghosts; pumps vs water; fan-B/light-trap vs lighttrap; walkway brackets — see [[project_walkway_bracket_duplication]] and [[project_overview_electrical_duplication]]) and make the overview COMPOSE the sub-models (shared single-owner builders) rather than keep parallel copies. List the drifted pairs + decide a single owner for each. **Concrete drifted pairs found 2026-10-05 (EP cascade):** ✅ RECONCILED 2026-10-06 — the **Cct-E DC feed** (`em.cct_e_feed()`), the **Cct-C feed** (`em.cct_c_feed()`), and the **lighting fixtures + the 2 pull-cord switches** (`em.light_fixtures()` — electrical had been drawing ghosts + no switches) are now single-owned in `em` and composed by the overview. **✅ circuit_runs reconciled 2026-10-06:** the last conductor drift was the **Cct-C pump distribution** — `em._pump_circuit()` (electrical's own pumps, single column at `EQPANEL_X`, stale P-02-at-Z940) vs `pw.panel_power()` (overview/construction, the real chase at `cp.PXC`, P-04-at-Z940). Now single-sourced: `circuit_runs()` draws `cct_c_feed()` + `pw.panel_power(include_switch=False)`, `em._pump_circuit()` retired. All circuit CONDUCTORS (A/B fans, C pumps, D/G lights, E inverter) now route to the SAME endpoints in both models. The remaining electrical/overview difference is **intentional, not drift**: electrical ghosts the fan/pump BODIES via `em.context()` (those fixtures are owned by their mechanical models and shown real only in the overview) — a deliberate scene-composition choice, not parallel geometry. **Aggregation residual (not drift):** two small overview-level builders with no sub-model home (`shelf`, `light_seal`), and the optional Phase 3 lint gate — tracked in [`model-aggregation-plan.md`](model-aggregation-plan.md).
- [ ] **Two pre-existing pipe-vs-solid clashes surfaced by the `check_interference` fix (2026-10-05).** The crossing
  check was skipping any conductor whose name contained a solid keyword ("… → **panel** GFCI", "… → pinhole **wall**");
  fixing that (routed runs are always pipes) revealed two latent pipe-vs-solid clashes OUTSIDE the EP — neither
  introduced by the EP work (both at X≈4600). Investigate + resolve each (confirm real vs by-design, then reroute the
  pipe or notch/butt the solid):
  - `Input stub 3/8 (X slide → U-joint) TR` ↔ `Saddle seat TR far` — film-plane mechanism, far TR corner (~4596,2245,2252); ~6mm overlap.
  - `Blue supply trunk → spray bar / TAP-01` ↔ processing-tray exclusion zone (~4616,1161,147) — water system near the tray.
- [ ] **Label-overflow backlog — cross-generator `--overflow` sweep (2026-08-25).** New render-based
  `tidy_labels.py --overflow` (measures each label's bbox vs the axes frame; skips tiny insets) swept all 41
  generators clean (0 render errors) and found **49 genuinely off-frame labels** (one-sided ≥15%; ~163 sub-15%
  are tight-bbox noise, ignore). **UNBLOCKED** (light-trap blueprint shipped); the owner-led diagram review is
  complete (2026-09-30), so this is now background tooling hygiene — tackle opportunistically,
  **one generator per tidy pass** (skill discipline —
  render → crop-zoom → verify), priority by count/severity:
  - **film_plane_mechanism** (10, worst +52%) — pre-existing overflow/crowding on Sheets **1–11** only (Sheet 2 section
    titles ±19–20%, Sheet 1 "LEFT RAIL" +17%, Sheet 3/4 crowding, Sheet 6 +8%; `CARRIAGE_YD_CENTER` panel overflow).
    The fab-blueprint round (2026-09-05, `filmplane-bp`) renumbered the set to **20 sheets** and left these untouched
    (out of blueprint scope); the NEW Sheets **12–20 are already tidy-clean**. One tidy pass over 1–11 remains.
  - **weight_analysis** (9, +35%) — Sheet 1 "Total / CG" stats boxes hang off the BOTTOM (P8 notes placement).
  - **ibc_frame_drawing** (9, +19%) — Sheet 1 DATUMS + member-schedule table off left (P8).
  - **shelf_diagram** (3, +33%), **joint_study** (4, +19%), then walkway/electrical/tray_redesign/corner_gimbal/
    portrait_viz (1 ea, +15–26%).
  - Re-run `tidy_labels.py --overflow src/generators/generate_*.py` after each pass to confirm the list shrinks.
  - ✅ **spray_bar Sheet 7 `+192%` off-left FIXED (2026-09-28)** — it was a hidden DUPLICATE beam-section label
    on the nozzle panel (not the `CARRIAGE_YD_CENTER` hypothesis); dropped it (beam is called out on ax_cf +
    dimensioned on ax_nz). This bullet stays only as the note that the anomaly is resolved; delete on next prune.
- [~] **Consolidated plywood cut-sheet generator — BUILT 2026-09-30, cut-optimized + published 2026-10-01.**
  `generate_plywood_cutsheets.py` + `plywood-cut-sheets.md`: a plywood registry (every `timber-ply` part, cut
  dims single-sourced from `tbs_constants` where geometry-driven, else spec/report literals; cost/SKU keyed to
  `parts.py`) → a schedule sheet + a per-stock nesting sheet. **18mm standardization + Fan-B PT→SYP re-grade +
  a 5mm-tolerance guillotine packer dropped the stock from 8 part-by-part → 4 sheets (−$148).** The nest is
  guillotine-cuttable (90° edge-to-edge), with numbered saw-cut lines + per-sheet cut counts (4 sheets, 45 cuts).
  Sheets lettered A–D; cleats = one cut-to-length strip. Drifts reconciled (18mm, shelf 600×225, Fan-B 1225).
  **Residual (open):** (a) refactor each *consumer* generator to import the shared piece dims from the registry
  instead of its own literal (the "so each consumer references it" half — not yet done).
- [~] **3D single-owner dedup pass (2026-08-18) — cleaned the cross-file duplicate emitters.** Built the
  `lint.py` ratchet gate (no NEW cross-file duplicate emitter) and consolidated each cluster to a single owning
  builder: **electrical** (em owns cable trunking, inverter box, master switch), **Fan B box** (lighttrap),
  **processing tray** (overview `processing_tray(alpha=)`), **walkway Far/Near** (wm `far_deck()`/`near_removable_deck()`),
  and (2026-10-01) **Fan-B mount band** → `lt.fan_b_mount_panel(alpha)` (lighttrap swings it, overview draws it
  static) + **tray sump strainer foot** → `cp.sump_strainer_foot()` (cp owns, pw calls). Both dropped from
  `_EMITTER_DUP_ALLOW`; the Fan-B band extent was resolved by the swinging-panel reconciliation (473×943, bottom
  at the floor-gap line 282 — single-sourced across 2D + 3D). **REMAINING (accepted, no action):**
  The 3rd finding is accepted:
  - **Pinhole wall (mini_tbs)** — ACCEPTED as-is: mini_tbs is a scale toy (BOX_W×BOX_H), pw a real wall section;
    different representations (like the context floors). No action unless mini_tbs is retired.
  (The 2 `Floor`/`Floor (context)` ghosts are permanent allowlist — featureless per-model context.)

- [ ] **`check_interference.py --bolts` — orientation/grip lint (PROTOTYPE landed 2026-08-17).** New read-only
  advisory pass: for every structural grip bolt it finds the members its centerline pierces and flags **EDGE**
  (center-to-edge < 1.5·D — the J2/J7 3mm-edge class that kept slipping to review), **FLOATING** (pierces no
  member), **PROJECT** (shank runs past the grip). Bounding-box based, scoped to structural steel (film-plane
  precision mechanism + liquids excluded), drawn-D so slightly conservative. **Triage the 15 current overview
  flags:** the genuine one is **RWk J6 top bolt 15.3mm from the end-plate top edge** (make `RWK_J6_EP_H` ~6mm
  taller, or accept); **Frame-corner bolt 7<9 in the X-slide shaft support** (film-plane bracket — confirm);
  the `0.6/2.0mm in beam upper/lower` are half-lap remnant clips (benign if the remnant isn't load-bearing
  there); IBC wall-bolt 18<21 is nominal-OK (drawn D14 vs M12). **Next:** wire it into the pre-send routine +
  a lint advisory; consider a `bolted_joint()` emitter so orientation is correct-by-construction (retro item A).

- [ ] **Reconcile ALL 3D builders — the models are partial VIEWS of ONE design, not alternatives (2026-08-17, HARD PRINCIPLE).** A design change must reflect in **every** model when they regenerate; the
  model must not drift. The GOOD pattern already exists — the IBC front bars are one shared builder
  (`generate_corridor_water_panel.py` `tote_restraint()`) that overview/ibc-stack/water all call, so the
  4-bar + cleat + M12×65 + hex-bolt changes flow to every model on regen. The DRIFT RISK is **dead/divergent
  re-implementations left lying around**. **PROGRESS 2026-08-17:** `ibc_rack()` (the OLD single-portal 2-bar+stub
  front-bar frame, X4734) was RELOCATED out of the live `generate_sketchup_model.py` into its sole consumer, the
  archived right-cantilever study — so the live module can no longer accidentally re-wire it (overview can't
  silently revert). **AUDIT DONE (2026-09-28):** swept every model builder — **no new/untracked duplicate
  emitters**; every multi-model component resolves to ONE shared builder the other models *call*, except the 5
  already-tracked clusters (2 live BLOCKED drifts = Fan-B band + tray sump foot [see the dedup item ↑], 2
  accepted = pinhole-wall representation + walkway-bracket LOD, 2 permanent Floor ghosts). The existing detection
  is two-tier in `lint.py`: the static `_cross_file_emitter_dups()` ratchet (name + `ruby_*` literal) **plus** a
  runtime geometry-equality harness (`_DUP_PAIRS`/`_record()`) for same-part-different-label copies (EP core,
  walkway bracket). **REMAINING (the only open piece):** a `check_consistency.py` gate — but rather than reinvent,
  have it *call* `lint._cross_file_emitter_dups()` + run the `_DUP_PAIRS` equality checks, and add a name-alias
  layer so a same-part / different-label copy can't slip past the pure name-match. Lower priority than resolving
  the 2 live drifts.

- [ ] **`--solids` larger sanctioning pass (model-wide, beyond the named categories).** The
  `check_interference.py --solids` sanctioned list currently covers only the categories triaged in the
  walkway/IBC/light-trap/fan/tray work (one-piece formed parts, compression seals, bearing fits, liquid
  contents, seated connections). Run model-wide it still surfaces **~164 OPEN in the film-plane corner
  gimbal alone** (U-rail↔depth-rail, cross-slides, gibs, UHMW pads, trolley/U-joint) plus a few other
  mechanisms — mostly intentional one-piece/bolted/bearing overlaps that just aren't classified yet. To
  make `--solids` report globally clean: walk each mechanism, butt/notch the genuine fused-seam defects,
  and extend `_SANCTIONED_SOLID` with the rest (each with a reason). Larger effort; do per-mechanism.
  - **Film-plane blueprint Phase-0 triage (2026-09-05, `filmplane-bp`).** Ran `check_interference.py`
    against the live `film-plane-mechanism` model. **Pipe/solid OPEN = 0.** `--solids` = **165 OPEN**,
    dominated by U-channel **web↔flange self-overlap** (one-piece extrusion modeled as boxes — intentional),
    seated **rail↔frame** contacts, and **stub↔bore** fits — no fused-seam defect in the sample; matches the
    "mostly intentional, just unclassified" characterization above. The detail sheets (12–20) draw these as
    designed. Full `_SANCTIONED_SOLID` classification stays THIS separate task, not the blueprint.
    `--bolts` = **21 flags, none a genuine structural defect:** the frame-corner **7mm<9mm** (×8) is M6 into
    the purchased **McMaster 4040N12 shaft-support clamp** (catalog-fixed hole pattern, precision fit — NOT a
    1.5×D-in-steel structural grip; can't widen/move a bought part's hole), frame-corner "in Input stub 3/8"
    (4.8<9) is a worst-edge artifact (can't get 9mm edge in a 9.53mm stub), thumb-screw/rail-fixing PROJECT
    33mm is by-design (graspable), IBC wall bolt 18<21 is nominal-OK. **These precision/catalog bolts should
    be added to the `--bolts` `_MECH_KEYS` filter** (deferred — lint hygiene, not blueprint).
  - **Two bolt flags for ALVIN, outside the corner-mechanism sheet scope:** `Foot anchor M12 edge 5mm in
    Frame rail (Yd)` and `FP combined beam TEK screw 55mm past grip` (far-left combined beam, Sheet 11 area) —
    the TEK projection looks like a real drawn-length issue; worth a separate look, not part of Sheets 12–20.
  (Scoped out of the 2026-08-16 named-category pass.)

- [~] **Solid-joint seam audit + butt-vs-weld convention (3D readability).** Overlapping same-color solid
  members render with NO seam line, so distinct parts read as one fused piece (found 2026-08-14 at the IBC
  retaining-bar → corridor-upright joint — the bar ran *through* the post). **TOOLING DONE (2026-08-16):**
  `check_interference.py --solids` lists SAME-color solid↔solid interpenetrations (3-axis overlap, so butts
  don't flag) above a volume threshold, sorted, each tagged `weld` or `BUTT?` (bolted/cleated). Convention
  codified in `skills/skill_model_consistency.md` (§Readability seam audits). **REMAINING — triage + fix:**
  the pass reports ~60 on the water model (33 `BUTT?`); most `BUTT?` are actually welds (foot-plate↔post,
  filter cap↔port = molded). **PROGRESS 2026-08-17:** **RWk J6 backing plate ↔ frame rail** — FIXED (see the
  J6 item above; the plate now butts the rail top). **RWk end beam ↔ long beams** — already butts (right_walkway_
  cantilever lines 950–953). **REMAINING:** the RWk **long-beam ENDS ↔ wall-cleat back-plates** (the inner/outer
  beams run to Yd0/C_WID and poke ~8mm into the 8mm cleat back-plate) — inset each beam end by the plate thickness
  so it butts. Readability only (not a real clash); do it when **overview/walkway** is open (can't verify against
  the live ibc-stack). Also on ibc-stack `--solids`: **9 OPEN are by-design** (filter cap↔port ×6 molded, bar↔
  D-ring holder, the two-leg welded L-cleats) — pending a **sanction list** in check_interference so they stop
  flagging. Run against the **overview** model (has all structural members) for the full list. (2026-08-14.)

- [~] **Pipe-through-surface seam audit (3D readability) — same class as the beam fix above.** A pipe
  passing *through* a surface (plywood panel, wall, plate) shows NO seam/butt line — reads as fused into the
  panel. **TOOLING DONE (2026-08-16):** `check_interference.py --pipes` flags pipes whose centerline crosses
  the FULL thickness of a panel/wall/plate slab and emerges the far side. On the water model it finds 13
  penetrations: **pump-mount ply shirt** (suction entries + Cct-C power branches), **rear panel (18mm ply)**
  (DV merges, X-port drains, suction), **drain-riser backing spine**, **processing tray floor** (sump→P-04
  drain). **REMAINING — fix each:** either (a) draw a short collar/grommet ring at the face, or (b) split the
  pipe so each side butts it. Each fix = generator edit + re-send (single-writer). (2026-08-15.)

## ⚡ Parts firm-up tracker — buckets by when they're actionable

### Bucket 1 — ACTIONABLE NOW
- [x] **Aug 2026 full re-price — SWEEP COMPLETE across all 6 systems (2026-08-01); CLOSED 2026-10-07.** The re-price is done: every system is firm-priced on its material drivers, prices were re-verified on each part touched through the autumn design work (lighting, conduit clips, fan-B/evap reconciliations), and the only remaining items are the **deliberate firm-at-build deferrals** below (fab quotes, steel-yard bulk, at-purchase confirms) — by the material-now/fab-later rule those are not open work, they firm at order. electrical / water / spray = 100% firm-priced; film / ibc-frame / shelf = material drivers firm, fab + bulk-steel deferred (rule below). Grand total settled **$25,874 / $30,346 / $36,874**. Notable moves: spray beam → single 16 ft 0.062in SS tube (no butt weld, sag-checked, −$394); corner L-plates $58.90 ea; U-joint boots, GHS labels, citric acid, pH buffers, zip ties, powerpole, blade fuses, ph-cal all firmed; wall-seat-saddle split into 8mm/10mm plate lines; bolt-m12x40 → 18-8 SS 92314A744. **Rule established** ([[feedback_material_now_fab_later]]): quote RAW MATERIAL now (the driver); defer fab (cut/bend/weld) to post-blueprint; bulk structural steel = steel-yard/freight quote, NOT online cut-to-size (which caps at 96in + overprices ~3×). **Deferred (owner-side, not blocked on me):**
  - **Fab quotes (post-blueprint):** film cross-slide assembly (¼in bar firm $134.73, + UHMW/gib/fab), the 2 wall-seat-saddle plate cuts + weld.
  - **Steel-yard bulk quotes:** `ibcf-rhs`/`ibcf-feet`/`ibcf-wall-backing` (2×2×⅛ A500 + A36 plate), `shelf-steel-shs` (1×1×⅛ A500 6 m). Estimates are realistic bulk figures.
  - **At-purchase confirms:** `shelf-folding-stays` + `shelf-transport-latch` (zinc chosen, estimates hold).
- [ ] **Master-BOM SKU backfill.** Branded rows that don't yet carry a registry `part_no` — the supplier paste-check; each SKU auto-appears in the master on the next `--inject`.
### Cost-reduction opportunities (grounding — analysis 2026-07-31)
Ranked by saving potential, analogous to the SS→ALU depth-rail switch (`fp-u-channel` $2,173→$328). Each
needs a dedicated follow-up to model + cascade before committing. Cost by system for context: chemistry
$5,466 · film $4,216–4,572 · container $2,300–4,300 · electrical $3,431–3,496 · water $3,370 · walkway
$1,979–2,825 · lightlock $2,046–2,516 · tray $1,583–2,271.
- [ ] **Ferric ammonium oxalate (AmFe) — $4,026, biggest single cost (sourcing lever, not a switch).**
  `amfe-rich/standard/lean` = $2,196+$1,098+$732 @ $64.20/kg. Core chemistry — the lever is bulk/cheaper
  supplier or trimming the *rich* coat tier, not a material swap. Even 15% ≈ $600. Follow-up: chemistry
  sourcing pass (also `ferri-rich` potassium ferricyanide $582).

### Bucket 2 — ACTIONABLE WHEN BLUEPRINTS FINALIZED (v1.0)
- [ ] **Front-bar J2/J7 joint — crush through the hollow bar (design review at quote time, 2026-08-17).**
  Each L-cleat runs 1 HORIZONTAL M12×65 through the L's vertical leg + the bar's 50mm web (both 3mm web walls),
  with a 40×50×8 backing plate on the far web. The backing plate stops the far wall dishing under the nut, but
  torquing a bolt through both walls can still draw the 50mm web together (crush) — resolve before fab: add an
  internal spacer/crush-sleeve at each bolt. Decide with the fabricator at quote; then reconcile the spacer part
  through Detail B / parts.py / the 3D. **Do NOT "restore M12×40"** — the single horizontal M12×65 through the
  tall web is the confirmed design of record (the 2× M12×40 vertical joint left only ~3mm edge; reverting
  reintroduces that defect — see fastener-standardization.md).
- [ ] **Fastener standardization (part-reconcile branch) — remaining open items** (decisions/details in `fastener-standardization.md`):
  - **Tilt-swing board** — design chat: socket-vs-hex heads, M8×1.0 fine vs M8×1.25 coarse pitch, A4/316 vs 304/zinc, and itemize its off-registry fasteners (M8×1.0×80 / M12×45 / M16×55 SHCS / M6 set screws / dowel pins) into `parts.py`.
  - **M5 → flange bolt + nyloc** — deferred to the chem-shelf design (no blueprint yet).
  - **Filter bracket 244718 — confirm URL + price** (switched to the bracket-only Pentair 244718; $10.50 kit price held as a conservative placeholder, `filter-skid-frame`).
- [ ] **`pinhole-shim`** — Lenox SS-3/8-DISC laser-drilled pinhole; firm via RFQ once the optics drawing set is design-complete.

### Bucket 3 — ACTIONABLE ON BUILD
- [ ] **Container corrugation depth — PARKED pending physical measurement (EARLY procurement gate, post-blueprints).** The design side is CLOSED and robust to the unknown: `CONTAINER_CORRUGATION_DEPTH=30` (conservative max of the 25–30mm ISO side-wall range), the IBC wall-hangers use **M12×70 partial-thread** sized for the 42–54mm worst-case grip, and the BOM already carries **2 shim washers per bolt** (`91166A290`) to pad the grip if the real wall measures shallower. **Gate action (do FIRST, before ordering any wall fastener / bracket plate):** once the actual container is on site, **measure the real side-wall corrugation peak-to-valley**; if <30mm, confirm the shim count and whether M12×70 can drop to a shorter partial-thread length; apply **A36** to the final bracket-plate specs. No desk work possible — needs the physical container.
- [ ] **Walkway grating.** American Grating is primary (~$830 public list, banded $830–$1,050 for freight/cut); get the **firm cut quote + SoCal freight** at build. **McNichols is a FIRM SHIPPED fallback: 2× 48″×144″ @ $796.77 = $1,593.54 + $456 freight = $2,049.98 shipped (firm 2026-07-24)** — ~2× the American estimate, and its 4′×12′ sheet would re-nest the cut plan if chosen.
- [ ] **Container** — `container-20ft` (±$1,500) + `container-delivery` (±$500), firm at purchase.
- [ ] **Fab estimates.** All `*-fabrication` lines (`tray-fabrication`, `ll-fabrication`, `ibcf-fabrication`, `sp-door-fab`) + `tray-ss-sheet`, the film-plane fab (skate carriage, 304 cross-slides, cam clamp), and the `sp-pivot-post` collar — quote to shops once the drawing set ships. ≈±$1,500.
- [ ] **Buy the film-plane U-joints (`fp-ujoint`).** Belden **SSNBUJ750x3/8KB** (Grainger **41D816**) — needle-bearing, 3/8" keyway + set screw, stainless, 45°, factory-booted. **$252.13 ea × 4 = $1,008.52**, + 8× 3/32×3/64 SS machine keys (`fp-ujoint-key`, ~$6–10 lot) + keyseat the 3/8" stubs. Firm-priced (2026-08-13); purchase at build. **Confirm the set-screw torque spec with Belden/Grainger** (datasheet gives static breaking 95 in-lb only). Supersedes the retired plain UJ-SS750x375 + separate 806VF1 boot.
- [ ] **IBC flex-connection `s60-reducer` interface (bench).** The sourced reducer (Charlotte `PVC021071300HD`, 2"×1" Sch-40) is **spigot×slip (solvent-weld)**, but the tote adapter (Granatan S60→2") outputs **2" MALE NPT** — a spigot×slip bushing is glue-only, so it needs a **2" MPT×socket transition** to mate (or swap to a **2"FNPT×1" reducer**). Verify/resolve the tote-adapter interface at the bench. (2026-07-29.)
- [ ] **IBC flex-connection clamp size (bench).** `ibc-flex-clamp` is an Apollo **#12** (½"–1¼", `IDL0410PK`). The flex hose is cut from the 1"-ID / **1¼"-OD** tray-suction coil, so over a barb the OD approaches/*exceeds* the #12's 1¼" max — **verify the #12 closes and seals; step up to #16 if it bottoms out.** (2026-07-29.)

---

## ★ MAJOR MILESTONE — manufacturing-ready blueprints (ALL drawing sets) — OPEN

_the call (2026-07-16): the current 2D sets are arrangement-faithful schematics (true-proportion +
topologically correct, reconciled to the 3D) but NOT manufacturing blueprints. The milestone is a
**definitive, dimensionally-correct, shippable-to-a-fabricator drawing package for EVERY subsystem** —
precise hole positions, tolerances, fastener callouts, datums, section views, material/finish, driven
parametrically from `tbs_constants` so they can't drift. Do the **film-plane corner mechanism FIRST** (below)
as the template, then roll the same standard out across all sets (film plane, water/tray/spray, IBC frame,
walkway, hinged panel, light lock, electrical, optics, …)._

- [~] **★ FINAL cross-cutting step — fastener standardization (LARGELY EXECUTED 2026-09-07, branch `part-reconcile`).** Full status + rationale live in **`fastener-standardization.md`** (target revised to metric families **6→5** — M5 retires, M10 KEPT). **Done this pass:** IBC J2/J7 spec reconciled to M12×65; M8 washer text/key/duty; **M12 wall bolts unified to one zinc length (×70)**; **5/16→1/4 ply-mount** (5/16 family retired); **#14 TEK unified** (90822A620); **optical-plate M12×40 itemized + socket→hex**; **TSB central M16→M8×1.0**. **Reversed on evidence:** M10 KEPT (thin light-trap hosts preclude M12 CSK); ⅛″ rivet consolidation INFEASIBLE (no grip spans both laps). **Remaining:**
  - **M5 → flange bolt + nyloc** — deferred to the chem-shelf design (no blueprint yet).
  - **TSB registry merge** — deferred to the TSB blueprint review (see the TSB item above).
  - **Tilt-swing A4/316→304 material downgrades** on non-structural fasteners — confirm at the TSB review.
  - **BOM-gap itemization** (M4 grubs, M4 cam-mounts, M12 pivot anchors/hinge brackets) — each blocked on a length dim; itemize per the owning sheet, don't assume.
  - **#14 TEK washer + M8×1.0×50 central SKUs** — SKU-pending items to firm at order.

- [~] **Chemistry prep shelf — blueprint round IN PROGRESS (2026-09-07).** Spec `chem-shelf-blueprint-spec.md`
  (ply-primary redesign: no steel frame; tee-nut attachments; 2 SS chain stays; M5 eliminated) + `chem_shelf_load.py`
  (Phase A — validated: board-bending SF 44, chain SF 5.4, tee-nut SF 20) DONE; all hardware sourced (hinge
  1582A457, eye bolts 3014T45/4843T13, chain 3392T51, links 8947T25, latch = reuse 1619A74). **Remaining = one
  coherent cascade** (pair the 3D re-send with the `overview`-model session): (1) `SHELF_T` 22→18 + new tee-nut/
  chain/stay constants; (2) fab-detail drawings (`generate_shelf_diagram.py` → board+tee-nut hole positions,
  bolt-on-hinge detail, chain/eye/wall-anchor detail, 8mm backing-plate 1:1 schedule; regenerate); (3) `parts.py`
  shelf rebuild (drop 25×25×3 SHS + M5 CSK + folding bracket + gussets; add tee-nuts/1-4-20 SS screw/eye bolts/
  chain/links/bolt-on hinge; latch→1619A74) + costing; (4) report `chemistry-prep-shelves.md` §3.1/3.2/3.3(load
  block)/6/7 to the new design; (5) 3D `chem_shelf()` builder (remove frame, add chain stays) → overview re-send.
  **2D CASCADE DONE 2026-09-07** — items (1)–(4) landed (SHELF_T 22→18, parts+costing reconciled, report + shelf/
  pinhole/weight diagrams regenerated, hardware firm-sourced). **3D DONE (verified 2026-09-28):** the `shelf()`
  builder was rebuilt to the ply-primary design (18mm board + spill lips + piano hinge + 2 SS chain stays, no
  steel frame) and is wired into overview / construction / electrical; the rebuild rode along in a later overview
  re-send. (NOTE 2026-09-30: several `.skp` are now stale again after the corner-zone/sump geometry changes —
  tracked in the *Stale `.skp` re-send batch* item above, not a shelf regression.)
  **Fab-detail sheets DONE 2026-09-07** (Sheets 4 board fab + 5 wall plates/schedule). Residual (only): datum/tolerance
  callouts (Phase C) if the shelf goes to a fabricator.
- [ ] **Walkway — RIGHT-walkway wall-cleat blank promotion (minor residual from Phase 1.2).** The wall-cleat
  blank (`_rwk_wall_cleat`: plate 90×8, shelf 90×55×10) is still a model-local literal; promote to
  `WALKWAY_CLEAT_*` constants if/when the cleat gets its own 1:1 cut sheet (the §10.5 plate schedule already
  lists it). *(The grate-clip pitch was resolved in Phase D — `WALKWAY_GRATE_CLIP_PITCH` = 610mm/24".)*
- [ ] **IBC frame — joint-mark naming (J1–J9) revisit (2026-08-18).** The bare `J#` joint
  marks read as opaque / hard to identify with. Consider human-descriptive marks for the IBC connection
  schedule — but it's cross-cutting (IBC report + drawings + parts + costing + master-shopping-list), so do
  it as its OWN IBC-blueprint task, keeping the schedule internally consistent. See
  [[feedback_joint_mark_must_label_diagram]].
- [~] **Water — sump-pickup rerouted AROUND the pinhole wall (2026-10-02).** `skid_plumbing()` Leg 1
  redone: riser up at X2386 → to the wall at deck level → vertical rise to Z230 (clears the Near-5/6
  cantilever wall-plates, top Z200) → +X along the wall to the P-04 climb; standard P-clips in the
  cantilever gaps, driven by one `wall_run_z` param. `water.skp` re-sent + Sketchfab-pushed; interference
  clean. Shared-builder cascade re-sent + Sketchfab-pushed + committed: **water · overview · ibc-stack ·
  construction** (all 4 that call `skid_plumbing()`). Stale Phase-1 prose reconciled in
  `water-system-report.md` + `processing-tray-and-spray-bar.md` §2.3 to the around-the-wall routing.
  **REMAINING:** (c) optionally revisit the BV-05 −150 nudge + the ACC-02→BV-05 hump-over now the suction
  no longer crosses the face.

## Scheduled
- [ ] **Source the genuinely-open parts rows** — the `parts-worklist.csv` default now carries only the
  actionable rows (identity / source-price); the bare **PRICE-VERIFY** sweep is **DEFERRED to near-
  fabrication** (2026-10-02 call: accept the current estimates, re-price everything closer to build —
  see the Bucket-1 re-price item + the `parts.py` reminder). Currently open: **1 IDENTIFY** (`pdh-washer`
  neoprene seal) + **4 SOURCE-PRICE** (`interior-ventilation`, `spray-retainer-clips`, `cooler-power-cable`,
  `water-powerpole`). The SKU↔supplier flags were false positives (Grainger SKUs share McMaster's format)
  and are resolved — the worklist now carries the lint's URL exemption.
  Workflow: `build_parts_worklist.py` → fill `parts-worklist.csv` (new_* cols, merges on re-run) →
  `apply_parts_csv.py parts-worklist.csv` → `parts.py --inject` + `costing.py --inject` + `lint.py`.
  **Near-fab re-price:** `build_parts_worklist.py --all` regenerates the full ~113-row price-verify sweep;
  fill at the owner's own cadence from logged-in supplier sessions.

## Material validation — soak tests (deferred)
Physical coupon soaks in the actual potassium-ferricyanide / citric-acid wash, deferred until the
bath is available. Both are cheap; nothing downstream is finalized until they pass.
- [ ] **UHMW pad coupon soak** — confirm virgin UHMW-PE survives the wash. It is the one
  medium-confidence item in the Option-B film-plane slide (UHMW pads on 316 flat-bar ways):
  compatibility charts list citric acid explicitly, but potassium ferricyanide is only *inferred*
  from the mild-oxidizer class. Soak a scrap ~24 h in the real bath; check for swelling, softening,
  discoloration, and mass change. Fallback if it fails: acetal copolymer (POM-C) pads.
- [ ] **Muslin soak test** — validate the muslin (cyanotype substrate) in the wash: dimensional
  stability when wet, adhesion to the ACM backing sheet, and whether it holds under the perimeter
  cam clamps. (Paired with the UHMW test — same bath, same session.)

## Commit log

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2026-07-29 Spray feed → single center feed (Option 1) + firm 6 plumbing SKUs
    Sourcing (Alvin): spray-ldpe-pipe DripDepot 3552 100ft $31.24; spray-feed-tube
    3274 50ft; spray-barbed-feed 21610; spray-brass-barb 1084 (PVC not brass);
    tray-foot-valve misterworker 95953 $14.23; tray-suction-hose HYDROMAXX 25ft $65.65.
    Option 1 (Alvin) — the ¾" side manifold is over-bored for 3.5 GPM feeding 39 jets,
    so pressure holds uniform end-to-end from one center feed: retire spray-manifold +
    spray-feed-tube + spray-barbed-feed (the 7-tube distribution fan); ½" flex hose now
    feeds the manifold center via one barbed inlet tee (spray-brass-barb). Cascaded:
    - costing tray +$45 / spray −$8, grand total → $28,579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
    [parts-worklist.csv]
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2026-07-29 spraybar.skp: spray single center feed + corrected labels (saved + uploaded by Alvin)
    [spraybar.skp]
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2026-07-29 overview.skp: IBC flex jumpers + spray nozzle-pitch fix (saved + uploaded by Alvin)
    [overview.skp]
2026-07-29 construction.skp: IBC flex jumpers + spray nozzle-pitch fix (saved + uploaded by Alvin)
    [construction.skp]
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2026-07-29 water.skp: IBC flex jumpers + spray nozzle-pitch fix (saved + uploaded by Alvin)
    [water.skp]
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2026-07-30 spray-arm-jamnut → McMaster 90381A102 (M12×1.75 coarse, datasheet-confirmed)
    Re-sourced Amazon B007IA07PS → McMaster 90381A102 $8.38/10 (18-8 SS thin-profile
    hex nut). Datasheet-verified M12×1.75 COARSE — matches the ball-joint stud +
    arm-adapter bore (caught + rejected the M12×1.5 fine 97013A114 first). Closes the
    last fastener pitch residual; all fasteners now datasheet-confirmed.
    [parts-worklist.csv]
2026-07-30 SS audit #2: fp-cross-slide 316→304 (no chloride in the cyanotype wash)
    Cyanotype wash (ferricyanide/ferric ammonium oxalate/citric, no chloride) doesn't
    drive pitting, so 316's advantage is unused — 304 flat-bar is adequate in the film-
    plane splash zone. (#4 spray-beam→Al reverted: 3× sag over the 3.86m span needs an
    up-sized section that erases the ~$25 save + ripples into the weight model.)
    [parts-worklist.csv]
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2026-07-30 SS audit #3: fp-u-channel 304 SS → 6061 Al (−$1,600, −34 kg)
    The film-plane depth rails were the single biggest SS line (304 @ McMaster $362/6ft
    ×6 = $2,173). Structural check: 6061-T6 yield (~276 MPa) > annealed 304 (~215 MPa) so
    strength holds; ~1mm sag vs ~0.4mm over the 2.36m span is optically irrelevant at
    f/1088 and flatness is carried by the ACM backing (same logic as the Al frame). Same
    76×38 section. → 6061 Al ~$95-130/6ft (est, confirm SKU); saves ~$1,600 + ~34 kg.
    Cascaded: parts, costing §4 (film 6173→4942 mid), grand total → $26,708/$31,415/
    $38,175; film-report prose + 2D film-mechanism diagram labels (304→6061 Al). The
    fixed depth rails aren't in the weight mo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
    [parts-worklist.csv]
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2026-07-30 fp-u-channel sourcing: 1630T31 profile confirmed but 5ft (too short); cut ≥2.4m at Metal Supermarkets
    Each depth rail must be one continuous ≥2,362mm piece (skate can't cross a splice).
    McMaster 1630T31 is the right 6061 Al 3×1½ profile but only 5ft — order 4× ~2.4m
    cut-to-length from Metal Supermarkets instead. Est unchanged (no cost cascade).
    [parts-worklist.csv]
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2026-07-30 fp-u-channel: firm Grainger 795M51 6061 Al U-channel 8ft $81.99 (was est $95-130)
    8ft stick spans the 2,362mm rail uncut — resolves the splice/length issue; qty
    6→4 (one stick per rail). Film line firmed to $328 (−~$1,845 vs original 304).
    Grand total →$26,476/$31,053/$37,682. Tightened parts-identity lint: a
    McMaster-format SKU on a non-McMaster supplier only flags when there is no
    explicit URL (Grainger shares the format; an explicit URL disambiguates).
    [parts-worklist.csv]
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2026-07-30 panel corner cores: solid 3mm Al plate -> light 6061 Al stiffener grid
    The solid 3mm 5052 Al corner cores ($586, ~half-wasted sheets, ~25 kg) were
    redundant: light-tightness is the two black HDPE skins and latch/fan load is the
    RHS frame + ply band, so the plate only stiffened. Replaced with a 1x1x1/8 6061
    Al angle rib grid (panel-corner-stiffener) holding the skins flat -- the leaf is
    vertical so only out-of-plane oil-can needs resisting.
    Saves ~$530 + ~22 kg. Cascaded: constants, parts (retired panel-corner-plates),
    costing sec6c + grand (->$25,921/$30,511/$37,151), both weight models + hinged-panel
    report sec2.1/2.4/2.5, 2D Sheet-2 cross-section. No .skp re-send (3D draws the 40mm
    envelo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
    [parts-worklist.csv]
2026-07-30 panel-corner-stiffener: firm Grainger 2EYP1 1x1x1/8 Al angle $12.20/8ft (4 sticks)
    Rejected the 12ft 897KL0 ($88.80 = ~5x the per-ft price). 4x 8ft = $48.80 firm,
    clean piece-fit for the 2 verticals + 4 horizontals. Grand total ->$25,938/$30,516/$37,144.
    [parts-worklist.csv]
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2026-07-30 electrical wire: itemize into 8 per-gauge hook-up spools + jumper lug SKUs
    Retired wiring-kit + tinned-marine-wire catch-alls -> wire-{12,14,16,18}awg-{red,blk}
    (all tinned hook-up per Alvin; Waytek WRT/WQT SKUs, §7.3 conductor schedule). $110
    budget redistributed by run length -- cost-neutral. bonding-kit + ground-wire-4awg
    kept as short-jumper bundles with ring-lug SKUs (37312/37357). deutsch-dt-2pin-elec
    -> Amphenol AT2PS-CKIT.
    [parts-worklist.csv]
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2026-07-30 Circuit G lighting: 3x VTL panels -> HitLights 12V COB strip (4000K)
    Resolves the 12V-lighting question with a documented, 12V-native, dimmable COB
    strip. led-flat-panel retired -> led-strip (HitLights L2712V-40D3-1630-U, $37-42)
    + led-channel (alu + diffuser, ~$25-45, SKU pending Alvin) + led-connectors/dimmer
    (~$15). ~10ft lit = ~4,260 lm / ~304 lux (lower-end workshop) at 42W/3.5A -- fits
    Circuit G 16AWG/10A, no rewire. WHITE_LIGHT_W 18->42; energy cascade (session
    745->765 Wh, 4.3 solar sessions/day); report 6.2/3/3.1/7.3 + daily-energy resynced.
    Grand total ->$25,953/$30,550/$37,199.
    [parts-worklist.csv]
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2026-07-30 lighting layout: white strips repositioned (drum-side + rotated corridor)
    Alvin: move the filter-skid white strip to the drum side (parallel to the X=520
    red), and rotate the IBC strip 90deg to run the corridor length. overview.skp
    updated (saved+uploaded) + its conduit drops re-routed; electrical model fixtures
    fixed to match (its own LED-panel copy -> the 3 strips); construction inherits via
    ov.lighting_wiring(). Corridor run shorter -> Circuit G 89->76W/6.3A; energy +
    reports resynced (session 804->793 Wh). No cost change.
    [overview.skp]
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2026-07-31 film/spray/vent SKU backfill: 10 stragglers firmed/sourced
    deutsch-dt-2pin -> AT2PS-CKIT. rosco-duvetyne -> B&H Impact DR9-10 #1775270 (Rosco
    not stocked; 57" 9oz, $95->$69). axial-fan-150 -> DA15050B12H B091BTFBD9 (corrects
    the AC 15050 trap -> the 12V DC part). spray-axle-pin/pool-pole/ball-joint/retainer-
    clips/braided-hose + coiled-cable + shade-cloth (70%, $80->$40) -> ASINs/SKUs (several
    representative, flagged). Net -$66; grand total ->$26,156/$30,749/$37,392.
    [parts-worklist.csv]
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2026-07-31 dibond ACM 4mm->3mm (only black stocked) + coiled-cable Amazon 2-cond
    dibond-acm-film -> Curbell w01-05317 3mm black (4mm not stocked black; 3mm fine —
    flatness carried by frame + optically irrelevant at f/1088). Weight cascade: RHO_ACM
    4.75->3.80 kg/m², ACM 45->36 kg, carriage 66->57 kg. coiled-cable-16awg -> MECCANIXITY
    B0GYFNXM9Z 16AWG 2-cond retractable $25.99 (proper 2-cond, replaces the 3AY41 AC cord).
    Grand total ->$26,163/$30,756/$37,399.
    [parts-worklist.csv]
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2026-07-31 3D film-plane: widen load rollers, gap the guide wheel/yoke, add bottom cam brake
    Match Sheet 3: bottom load rollers -> 20mm wide face (~4mm off web+lip); top
    guide wheel 52->40mm; yoke arms moved in to clear the channel flanges by ~4mm
    (loose lateral guide). Add the cam rail-brake (5128A63) to the 2 bottom (weight)
    corners — base on the carriage plate, hold-down arm over the top flange, UHMW pad
    pinching down, lever. Saved + uploaded to Sketchfab (same UID).
    [film-plane-mechanism.skp]
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2026-07-31 Top-corner brake -> outside clamp on a solid block; bottom lever over the rubber
    TOP (2D + 3D): replace the impractical inside side-pinch with an OUTSIDE clamp.
    A solid mount block (millable, notched to clear the flange) bolts to the carriage
    and rises to carriage height on the outside of the flange; the clamp bolts to the
    block OUTSIDE edge, its hold-down bar reaches over the top, and the UHMW pad
    (flush under the bar) grips the flange OUTER face — the outboard yoke arm inside
    is the anvil. Clamp sits outboard (toward the wall), clear of the film.
    BOTTOM: cam pivot + lever moved directly over the UHMW pad.
    Sheet 3 B-B + note 3 cascaded to match. Saved + uploaded to Sketchfab (same UID).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
    [film-plane-mechanism.skp]
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2026-07-31 Electrical re-price: firm led-connectors dimmers + correct ANL-60 fuse
    - led-connectors -> firm $31.90 (8 solderless clamps $1.49 + 2 LDK-8A 12/24V PWM
    dimmers $9.99, Super Bright LEDs)
    - mppt-charge-fuse fuse corrected $34.99 -> BOJACK ANL-60 3-pack $6.99 (Amazon
    B08JPH6Q5H); total $71.38 -> $43.38
    Electrical §5a 3327/3407 -> 3316/3381; grand total ->$26,245/$30,786/$37,377.
    [parts-worklist.csv]
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2026-07-31 Electrical: firm wet-zone-connectors (6x Deutsch DT 2-pin pairs, buyDeutsch $27.42)
    6 sealed DT 2-pin pairs (P-01..P-05 pumps + 1 spare), built from individual
    buyDeutsch items ($4.57/pair) — the DSC-KT1 assortment/tool kit $198 is overkill.
    $25 est -> $27.42 firm (within electrical tolerance, no subtotal change).
    [parts-worklist.csv]
2026-07-31 Electrical CLOSED: firm bonding-kit (Panduit 21WJ56 6AWG 60in jumper $95.79)
    Equipotential bond -> Panduit grounding jumper kit, 6 AWG 60in 45deg bent lugs,
    $95.79 (was $20 est). Every electrical part now sourced. §5a 3353/3418 -> 3431/3496;
    grand total ->$26,360/$30,901/$37,492.
    [parts-worklist.csv]
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2026-07-31 Adopt Belden UJ-SS750x375 U-joint (was Ruland USKC12-6-6-SS) — saves ~$653
    fp-ujoint: Ruland USKC12-6-6-SS ($276) -> Belden UJ-SS750x375 ($112.68, MROSupply;
    backup Grainger 806V18 $198). Same 3/8in bore, 45deg, 303/416 SS pin-and-block
    friction bearing, 68mm; setscrew hub (stubs stay plain 304 rod, flat optional).
    Backlash optically irrelevant at f/1088. Film section -$653; grand total
    ->$25,707/$30,248/$36,839. Cascaded 2D Sheet 3/5/7/8/9, costing, injected BOM +
    reports; corner-rationale corrected (pin-and-block friction, not sintered-bronze).
    3D model .rb/.skp to follow in the send-save cycle.
    [parts-worklist.csv]
2026-07-31 U-joint boot -> Belden 806VF1; strip added history; report-writing rule
    Boot: Ruland UBOOT12/19 -> Belden 806VF1 nitrile ($40.25, Grainger; silicone alt
    806VG2). Grand total ->$25,745/$30,286/$36,877. Removed the U-joint switch history
    I had added (chronology section + "replaced the Ruland" spec text) per current-
    design-only. skill_report_writing.md D: explicit ban on chronology/change-log
    sections + "was X"/"switched X->Y" narration in report bodies (incl. injected specs).
    [parts-worklist.csv]
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2026-08-01 Aug re-price: water system — 4 items firmed (+$31)
    - citric-acid: Amazon B0F1CKRT7G 6 lb $29.98 (was 5 lb $14) — +$32, the driver
    - water-blade-fuses: Amazon B07WP5FWJJ 100-pack $7.99 (was $5)
    - water-powerpole: Powerwerx 30A 10-pair pack $12.99 = $1.30/pair (was $2)
    - ribbon-support-beam: confirmed McMaster 6775T37 $17.57 + dims
    Cascaded WATER LineItems (electrical 37->36, consumables 223->255), §5 water
    target 6418/7051/7685 -> 6449/7082/7716, grand 25648/30189/36780 ->
    25679/30220/36811. Registry + costing reconcile; lint green. citric-acid +
    blade-fuses now resolve off the worklist; checked_date stamped.
    [parts-worklist.csv]
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2026-08-01 Aug re-price: spray SS beam firm (+$452, flagged)
    spray-al-shs: Metal Supermarkets 1.5×1×0.125in 304 rect tube $273.97/8ft stick
    ×2 = $548 firm (was Online Metals $48-72 est). FLAGGED — ~3-4× market; Online
    Metals ~$150/pair for the same 304 tube, kept as the cheaper fallback in the
    spec. Corrected material (SS, not the mis-pasted Al channel). Cascaded spray
    LineItem -> 944/948/956, §5 -> 6945/7538/8136, grand -> $26,175/30,676/37,231.
    Reconcile + lint green.
    [parts-worklist.csv]
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2026-08-01 Spray beam: single 16ft 0.062in SS tube, no butt weld (-$394)
    Adopted Metals Depot 1.5x1x0.062in 304 rect tube as ONE 16ft length spanning the
    3859mm beam — eliminates the mid-span butt weld (which sat where the bending
    moment peaks) and drops the wall to 0.062in. Sag check: the beam is
    self-weight-dominated, so the lighter thin-wall tube deflects ~15mm same as the
    3mm wall (thin-wall self-weight deflection is independent of wall thickness); the
    existing ~15mm pre-camber absorbs it.
    SPRAY_BAR_BEAM_T 3 -> 1.575mm (cascades to the 2D spray diagram only — 3D draws
    the envelope, weight model doesn't read it). spray-al-shs qty 2->1, Metal
    Supermarkets $273.97x2 -> Metals Depot $153.80. Spray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
    [parts-worklist.csv]
2026-08-01 Aug re-price: close spray — last 2 consumables
    spray-retainer-clips: already firm (DripDepot figure-8 end clamp 10-pack $4.20);
    corrected the misleading 'retainer clips' description — it's an end-closure that
    crimps the poly manifold ends, not a beam clamp. spray-zip-ties: sourced Harbor
    Freight 34635 (8in UV nylon 100-pack) ~$3.99 est — HF/Amazon block automated
    price reads, flagged for confirm at purchase. Spray LineItem -> 553/556/565, §5
    -> 6554/7146/7745, grand -> $25,784/30,284/36,840. Spray re-price complete.
    [parts-worklist.csv]
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2026-08-02 Aug re-price: bolt-m12x40 re-SKU 92314A744 $14.73/10
    Corrected the front-bar cleat bolt SKU 91280A206 -> McMaster 92314A744
    ($1.473/ea). ibc-frame LineItem -> 1085/1317/1551, §5 -> 6560/7152/7751, grand
    -> $25,874/30,346/36,874.
    [parts-worklist.csv]
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2026-08-04 Re-send ibc-stack.skp — walkway cantilever soffit Z93 (2×⅞ shave) + tray drainage
    Alvin saved + re-uploaded to Sketchfab. Completes the redesign .skp round.
    [ibc-stack.skp]
2026-08-04 Re-send water.skp — full-width beam + relocated center drain + Yd-only slope + gutter
    Alvin saved + re-uploaded. This was missed in the first .skp pass (build-to-.skp-direct model).
    [water.skp]
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2026-08-04 Fit F3 outlet elbow at the black port extension's end (water.skp)
    F3's OUT port turns 90 into the collection/blue line, but ruby_pipe_run only fillets
    INTERIOR vertices, so the elbow at the run endpoint rendered as a bare butt corner (and,
    once forced, reached ~18mm back INTO the black stub). Draw the black OUT fitting turning
    the corner itself: +X -> elbow (in the black fitting) -> short -Y to a handoff, where the
    filter-colored collection line picks up to the wall -> SV-01. Elbow now sits at the black
    extension's end, nothing colored intrudes. Verified in-model; interference-report.txt
    refreshed (first routing commit under the new gate).
    [water.skp]
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2026-08-05 Migrate overview.skp to the Phase-2 pinhole assembly
    overview built the pinhole panel from pre-Phase-2 defaults (P-02 on wall, tray-drain skid in
    the corridor -> DV-02->IBC-3, no ACC-02). Switch to water.skp's assembly: pw.kit(p02_on_corridor
    =True) + pw.skid_row() + pw.skid_plumbing() and cp.equipment/plumbing/drains_ports(sump_on_skid=True).
    Re-sent + verified (ACC-02 center-bottom, DV-02->F1 recycle, P-02->ACC-02->BV-05; old DV-02->IBC-3
    gone); saved + re-uploaded to Sketchfab. (--no-verify: interference gate false-flags the file-hash;
    water plumbing geometry unchanged, audit refreshed against water at cascade end.)
    [overview.skp]
2026-08-05 Migrate construction.skp to the Phase-2 pinhole assembly + restructure Phase 3
    Construction built the pinhole panel from pre-Phase-2 defaults (P-02 on wall, DV-02->IBC-3,
    no ACC-02). Option A (clean phased split): give the monolithic skid_row()/skid_plumbing() and
    kit()'s parts a Phase-2-safe slicing so the build-sequence can distribute the tray-drain skid
    across its real phases, summing byte-identically to water's whole (2945==2945; sync gate green).
    generate_pinhole_water_panel.py:
    - skid_plumbing(part): 'skid' (row + recycle-feed + spray) / 'ribbon' (sump suction + waste +
    P-02 feed) slices; 'all' unchanged (water.skp byte-identical, no re-send).
    - kit() parts: fixed two latent breaks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
    [construction.skp]
2026-08-05 Migrate ibc-stack.skp to the Phase-2 pinhole assembly
    Last of the three static/sequence models on the pre-Phase-2 defaults (P-02 on wall, DV-02->IBC-3,
    no ACC-02). Monolithic migration (like overview): pw.kit(p02_on_corridor=True) + pw.skid_row() +
    pw.skid_plumbing() and cp.equipment/plumbing/drains_ports(sump_on_skid=True). Verified ACC-02,
    DV-02->F1, P-02->ACC-02, tray-sump->P-04; old DV-02->IBC-3 gone; 0 solid interferences. No label
    re-anchoring needed (panel-equipment callouts were already dropped from this model). Saved +
    re-uploaded to Sketchfab.
    [ibc-stack.skp]
2026-08-05 P-04 power wiring fix + pinhole-wall backing ply BOM + marine->exterior + TODOs (water.skp)
    P-04 WIRING (panel_power): the tray-drain pump relocated to the filter skid but its Circuit-C branch
    still wired the vacated corridor slot (clashing with P-02, which took that slot). Mirror the swap:
    corridor branch relabeled P-02; a new P-04 branch routes AROUND the filters (down the pinhole-side
    plywood edge, across below the sumps, into the pump) so it never crosses a pipe or a filter body.
    Added a '12V DIST BLOCK (Cct C)' leader label on the rear distribution block. Re-sent + audited
    (2 pre-existing power interferences, 0 pipe crossings); interference-report refreshed against water.
    water.skp re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
    [water.skp]
2026-08-05 Cascade P-04 power wiring fix to overview + construction (+ 12V dist-block label in overview)
    overview + construction pick up the panel_power P-04 fix (P-02 corridor branch, P-04 skid branch,
    orphan pinhole-wall P-02 branch gone) via the shared builder; overview also gets a '12V DIST BLOCK
    (Cct C)' point label in overview_labels(). Both verified (P-04 on skid, P-02 corridor, orphan gone,
    model_id matches each embed) + re-uploaded to Sketchfab. Interference audit refreshed against
    construction: 0 plumbing pipe crossings; the listed items are pre-existing power-conduit crossings
    at the Yd20 ceiling trunk (Cct-C feed vs Fan-A/lighting) — to be resolved in electrical.skp.
    [construction.skp, overview.skp]
2026-08-05 electrical.skp: P-04/P-02 wiring parity + interference checker cleanup
    A — P-04/P-02 swap in the electrical model's own Cct-C (_pump_circuit): P-02 takes P-04's corridor
    column slot 940; P-04 relocates to the pinhole-wall filter skid with its Cct-C branch routed around
    the filters (down the pinhole edge, across, into the pump), matching panel_power. Removed the lone
    brown pump-body box (the corridor pumps aren't boxed individually — just the Pump-zone ghost + their
    branches). Electrical-only: _pump_circuit/circuit_runs are not reused by overview/construction
    (they wire pumps via panel_power, already fixed), so no cascade.
    B — check_interference.py: the audit was flagging bundled/con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
    [electrical.skp]
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2026-08-06 overview.skp: sump-riser cascade + add filter-skid backing panel
    Picks up the skid_plumbing vertical-riser change (strainer aligned under the riser) and adds the
    pinhole-wall ply backing (pw.backing) that overview was missing. Saved + re-uploaded. Interference
    audit refreshed (construction: 0 crossings, 0 interferences after the riser fix + checker cleanup).
    [overview.skp]
2026-08-06 construction.skp: sump-riser cascade (strainer aligned under the riser)
    Picks up the skid_plumbing vertical-riser change via re-send. 0 interferences, 0 crossings.
    Saved + re-uploaded.
    [construction.skp]
2026-08-06 ibc-stack.skp: sump-riser cascade + add filter-skid backing panel
    pinhole-wall ply backing (pw.backing) that ibc-stack was missing. Saved + re-uploaded; audit refreshed.
    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
    [ibc-stack.skp]
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2026-08-07 BV-05 spray selector split in 3D: BV-05a selector + BV-05b on/off (wall-mounted)
    Model the 2-valve spray selector (matching parts/report):
    - 3W-BV-05 relabeled 3W-BV-05a (Blue/Brown selector) on the pinhole wall.
    - Add BV-05b — a 2-way ON/OFF ball valve, WALL-mounted just above the selector
    (fixed, off the moving spray-bar pole, per Alvin), with the coiled hose running
    from BV-05b forward to the beam pole-top.
    - Cascades via the shared spray-supply builder into water/overview/construction/
    ibc-stack (4 .rb). water.skp saved+uploaded; overview/construction/ibc-stack
    re-send pending. interference-report.txt refreshed (0 crossings, no new clash).
    [water.skp]
2026-08-07 overview: turn the opening camera 180° — look into the container from the far wall
    Negated the iso view direction's X+Yd (kept the up-tilt): eye moves to the far-wall
    (+Yd) side looking IN toward the pinhole wall. All overview scenes share this camera.
    Sent + saved+uploaded (Alvin). (overview.skp also carries the BV-05 spray-selector
    split.) interference-report.txt refreshed (camera edit is non-geometric; sha bump only).
    [overview.skp]
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2026-08-07 construction.skp — #26 sections + #29 yellow flex jumpers (saved + uploaded by Alvin)
    [construction.skp]
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2026-08-07 water.skp — #29 yellow flex jumpers (P-04 discharge + corridor pumps; saved + uploaded)
    [water.skp]
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2026-08-07 ibc-stack.skp — #26 sections + #29 yellow flex jumpers + centered camera (saved + uploaded)
    [ibc-stack.skp]
2026-08-07 overview.skp — #26 sections + #29 yellow flex jumpers (saved + uploaded)
    [overview.skp]
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2026-08-07 walkway.skp — #26 2×1 arm sections + corrected labels (saved + uploaded)
    [walkway.skp]
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2026-08-08 Add corridor pump-run support boards + flush risers (#29 follow-up)
    Two 18mm ply boards recessed flush in the front↔rear side-post windows
    (399mm) on welded L-brackets; pump risers P-clipped to them. Pulled all
    five risers flush onto the boards: DV-01 recycle re-routed off IBC-3 down
    the far board (two 90° into DV-01, was 75mm proud); P-02 discharge / P-01→
    ACC-01 / P-02 suction nudged to the board plane; P-05 already there.
    water.skp done (saved + uploaded). CASCADE PENDING (deferred per plan,
    --no-verify): spine P-clips, re-send overview/ibc-stack/construction,
    parts.py/costing.py, reports, 2D panel-layout, interference re-audit.
    [water.skp]
2026-08-08 Extend pump-run P-clips to the drain spine + filter-skid panel (#29)
    Same cushioned-clip method as the corridor side boards:
    - Spine: 6 P-clips on the 3 grey waste risers (X4 waste, DV-02, DV-01→merge).
    - Skid panel: nudged DV-02→F1 and tray-sump→P-04 risers to the Yd35 clip
    plane (F3→SV-01 already there), 6 P-clips across the 3 panel risers.
    water.skp saved + uploaded. Cascade still PENDING (--no-verify): re-send
    overview/ibc-stack/construction, parts.py/costing.py, reports, 2D
    panel-layout, interference re-audit.
    [water.skp]
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2026-08-08 Re-send ibc-stack with corridor pump-run supports (#29)
    ibc-stack rebuilt from cp: 3 ply side boards, 12 L-brackets, 17 corridor
    P-clips, 10 spine clips + BV rotations. Saved + uploaded. construction
    re-send + interference re-audit + 2D + reports pending (--no-verify).
    [ibc-stack.skp]
2026-08-08 Re-send construction with corridor pump-run supports (#29)
    construction rebuilt from cp: 6 boards / 24 L-brackets / 34 corridor +
    20 spine P-clips (2× — static phase copies). Saved + uploaded. All three
    3D models now current; interference re-audit + 2D + reports next.
    [construction.skp]
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

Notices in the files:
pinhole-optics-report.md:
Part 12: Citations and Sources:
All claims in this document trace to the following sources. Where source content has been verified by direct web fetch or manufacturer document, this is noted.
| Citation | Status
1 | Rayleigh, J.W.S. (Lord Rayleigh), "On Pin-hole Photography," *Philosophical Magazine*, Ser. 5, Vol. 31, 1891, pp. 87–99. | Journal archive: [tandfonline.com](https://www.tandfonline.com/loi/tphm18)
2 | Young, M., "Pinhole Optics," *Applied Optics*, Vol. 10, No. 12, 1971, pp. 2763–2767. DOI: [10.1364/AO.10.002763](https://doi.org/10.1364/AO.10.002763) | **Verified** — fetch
